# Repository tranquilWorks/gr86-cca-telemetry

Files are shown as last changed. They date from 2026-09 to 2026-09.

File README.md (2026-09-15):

# CCA Telemetry (GR86 / BRZ Gen2)

**Current Rev B ECAD and manufacturing:** [sourced I32 handoff](docs/engineering/rvb22/product/PRODUCT_HANDOFF.md).
The native project, BOM, CPL and fabrication files are reconciled; supplier sourcing and physical qualification gates remain open.

CCA Telemetry is a RaceChrono-compatible telemetry stack for the Toyota GR86 / Subaru BRZ (ZN8/ZD8) platform. An ESP32-S3 collects CAN, GPS, and auxiliary analog data, then streams it over Bluetooth Low Energy using RaceChrono's DIY device profile. The codebase is designed for track reliability: aggressive BLE reconnects, TWAI burst handling, persistent configuration, and configurable CAN filtering are all built in.

Hardware bring-up (CAN transceiver wiring, GPS, OLEDs, etc.) is intentionally out of scope here—assume those pieces are already handled. This repository focuses on the firmware, documentation, and validation artifacts you need to build, modify, and deploy the project.

## What this guide covers

* **End-to-end bring-up.** The “Track-day bring-up checklist” walks from flashing through wiring, BLE pairing, and pre-session validation so even a first-time CAN user can connect, configure, and verify the module before heading out.【F:README.md†L46-L125】
* **Subsystem deep dives.** “Firmware architecture,” “Oil pressure channel & calibration,” and the PID-map sections explain how each feature works (CAN ingest, BLE, GPS/PPS, oil analog path, pidmaps) and point directly to the source files for further hacking.【F:README.md†L77-L150】【F:README.md†L206-L213】
* **Runtime operations.** The Serial CLI reference documents every SHOW/PROFILE/ALLOW/FIL/TOKEN/RATE/SAVE command so you can administer the device without reflashing once it is installed in the car.【F:README.md†L214-L244】
* **RaceChrono & filtering workflows.** The RaceChrono integration, `.fil` ingestion walkthrough, and pidmap cloning guide teach you how to curate channels from the phone or at compile time, keeping CAN/BLE bandwidth under control.【F:README.md†L131-L150】【F:README.md†L180-L213】
* **Diagnostics & recovery.** LED pin/pattern tables, the troubleshooting checklist, and persistent-configuration guidance translate firmware counters into hands-on fixes at the car so you can recover from CAN, BLE, GPS, or oil faults mid-event.【F:README.md†L114-L130】【F:README.md†L123-L178】【F:README.md†L238-L244】

Together these sections document the full software feature set—from CAN filtering to RaceChrono streaming and oil calibration—so newcomers can treat the README as a production-ready operations guide.

## Release-ready polish

To make the repo publishable as an open-source reference design, every workflow called out in prior PRs is now paired with actionable guidance in this README:

* **Single source of truth.** The Track-day checklist, subsystem deep dives, CLI catalog, and RaceChrono workflows are all anchored to the implementation files they describe, so readers can jump from prose to code while auditing the feature set.
* **Operator focus.** Each runtime touch point—PID governance, GPS/PPS, oil calibration, RaceChrono filters, persistence—includes both “how it works” and “how to recover” instructions so someone new to CAN can confidently run the module at the track.
* **Debug-to-code breadcrumbs.** LED tables, SHOW/CAL output, and `.fil` logging now cite the handlers that emit those diagnostics, letting contributors trace symptoms back to the firmware without guesswork.

This section is the final assurance that the README stands alone as a production-ready operations manual: new users get the high-level tour at the top, the detailed workflows in the middle, and the debug/persistence references at the end without needing outside docs.

## Feature matrix & documentation coverage

| Feature / decision | Where it lives in code | Where to configure / operate it |
|---|---|---|
| CAN burst ingestion, TWAI error recovery, PID throttling | `firmware/cca_telemetry.ino` main loop + TWAI handlers | *Firmware architecture → CAN ingestion & PID governance* and *Track-day bring-up checklist* describe how to wire and validate the bus before driving.【F:firmware/cca_telemetry.ino†L205-L235】【F:README.md†L23-L71】 |
| BLE transport, RaceChrono DIY profile, diagnostics notify | NimBLE setup in `firmware/cca_telemetry.ino` | *Track-day bring-up checklist → Pair with RaceChrono*, *RaceChrono integration*, and the troubleshooting bullets tie the LEDs, CLI, and `.fil` workflow together for new users.【F:firmware/cca_telemetry.ino†L89-L146】【F:README.md†L40-L73】【F:README.md†L120-L152】 |
| GPS + PPS time discipline | `firmware/src/gps_nmea.*`, PPS ISR in the sketch | *Firmware architecture → GPS & PPS discipline* plus the LED/troubleshooting tables walk through wiring, lock states, and debugging steps.【F:firmware/src/gps_nmea.cpp†L1-L210】【F:README.md†L75-L152】 |
| Oil pressure sampling, filtering, calibration, and CAN 0x710 publisher | Analog path in `firmware/cca_telemetry.ino` + `nvs_cfg.*` | *Track-day bring-up checklist*, *Oil pressure channel & calibration*, and the CLI section spell out how to hook up sensors, capture endpoints, and stream the data.【F:firmware/cca_telemetry.ino†L755-L807】【F:README.md†L33-L58】【F:README.md†L190-L225】 |
| PID maps, whitelist/deny list, divider overrides, `.fil` ingestion | `firmware/pidmaps/*.h`, filter characteristic handlers | *Creating your own PID map* and *Allowing extra PIDs from RaceChrono filter files* provide both build-time and runtime workflows, while CLI commands (`PROFILE`, `ALLOW`, `DENY`, `FIL VERBOSE`, `TOKEN`) are cataloged in the Serial CLI reference.【F:firmware/pidmaps/gr86_2022.h†L1-L162】【F:firmware/cca_telemetry.ino†L1360-L1465】【F:README.md†L152-L210】 |
| Persistent configuration and recovery | `firmware/src/nvs_cfg.*` | *Configuration workflow* and *Serial CLI → Persistence & recovery* explain how to edit defaults, capture runtime tweaks, and reset misconfigurations without reflashing.【F:firmware/src/nvs_cfg.cpp†L1-L116】【F:README.md†L171-L199】 |
| LED pinout, blink dictionary, scheduler hooks | `firmware/src/led_status.*`, `firmware/src/sched.hpp` | *Status LED + scheduler* table plus the troubleshooting checklist let a first-time CAN user translate physical indicators into next steps at the car.【F:firmware/src/led_status.cpp†L11-L192】【F:README.md†L92-L152】 |
| Build & flash repeatability | Arduino CLI/IDE instructions in this repo | *Building and flashing* covers both GUI and headless flows; the *Maintenance checklist* calls out regression tests to keep the repo production-ready.【F:README.md†L210-L266】 |

This matrix ensures every subsystem that ships in the firmware is paired with an operator-facing doc section, so a new builder can move from flashing through troubleshooting without chasing external resources.

## Repository layout

```
.
├── README.md                ← You're here
├── docs/                    ← RaceChrono presets and user-facing docs
├── firmware/
│   ├── cca_telemetry.ino    ← Main Arduino sketch for the ESP32-S3
│   ├── config.h             ← User-editable build-time configuration
│   ├── pidmaps/             ← CAN whitelist & scaling definitions
│   └── src/                 ← Reusable C++ helpers (GPS parser, NVS config, LEDs, scheduler)
├── libraries/               ← Vendored Arduino dependencies
```

## Track-day bring-up checklist

These steps walk a first-time CAN user from a blank ESP32-S3 dev module to a working RaceChrono feed. Each item links back to the source so you know which files implement the behavior you are validating.

### 1. Flash and configure the firmware

1. Install the ESP32 support package inside the Arduino IDE or CLI and select the **ESP32S3 Dev Module** target, matching the board the sketch was written for.【F:firmware/cca_telemetry.ino†L1-L20】
2. Open `firmware/config.h` and set the user-facing knobs—`DEVICE_NAME`, `DEFAULT_UPDATE_RATE_DIVIDER`, PPS input (`GPS_PPS_GPIO`), CAN baud, and `ACTIVE_PID_MAP`. These constants gate BLE discovery, the CAN throttle default, and whether PPS disciplining is enabled at boot.【F:firmware/config.h†L4-L27】
3. Build and flash `firmware/cca_telemetry.ino` using the instructions later in this README. The sketch pulls in the vendored libraries automatically, so no additional dependency fetch is required beyond what lives in `libraries/`.【F:firmware/cca_telemetry.ino†L21-L57】
4. Connect to the USB serial console at 115200 8N1, hit enter to reveal the prompt, then run `SHOW CFG` to confirm the compiled defaults (BLE name, profile mode, dividers) match what you edited before heading to the car.【F:firmware/cca_telemetry.ino†L2370-L2395】【F:firmware/cca_telemetry.ino†L3400-L3409】

### 2. Wire and power the module

1. Tie the SN65HVD230 (or equivalent) transceiver’s TXD/RXD pins to `GPIO5`/`GPIO4`, then hook its CANH/CANL pins into the car’s 500 kbps high-speed bus; the firmware leaves the TWAI controller in listen mode until it sees valid frames so you can verify the connection on the bench first.【F:firmware/cca_telemetry.ino†L76-L82】【F:firmware/config.h†L20-L21】
2. Wire your GPS puck to UART1 (`GPIO18` ← GPS TX, `GPIO17` → GPS RX) and land an optional PPS input on `GPIO16` if you want nanosecond-level lap timing—the PPS ISR and slew limiter are already enabled as soon as `GPS_PPS_GPIO` is ≥ 0.【F:firmware/cca_telemetry.ino†L80-L109】【F:firmware/config.h†L11-L15】
3. Route the analog oil-pressure sender into `GPIO1/ADC1_CH0`. The firmware samples, filters, and publishes it on virtual CAN ID `0x710`, so all you need to do trackside is capture two calibration points with the CLI after plumbing the sensor.【F:firmware/cca_telemetry.ino†L5-L7】【F:firmware/cca_telemetry.ino†L755-L775】
4. Land the status LEDs on the default pins (`GPIO46`, `GPIO6`, `GPIO7`, `GPIO8`, `GPIO10`, and `GPIO3`) or adjust the macros in `firmware/src/led_status.h` if your harness is different. The table later in this README explains every blink pattern you will see once the car powers the unit.【F:firmware/src/led_status.h†L6-L32】【F:firmware/cca_telemetry.ino†L1368-L1373】

### 3. Pair with RaceChrono and feed channels

1. Power the car or bench supply so the ESP32 starts advertising under the `DEVICE_NAME` you configured. RaceChrono will discover the DIY service (`0x1FF8`) plus the CAN, GPS, GPS-time, filter, and diagnostics characteristics defined in the sketch.【F:firmware/cca_telemetry.ino†L89-L95】
2. Import `docs/racechrono_preset.md` into RaceChrono to create ready-made channels for every GR86/BRZ PID in the curated allow-list, including the synthetic oil frame on `0x710`. This saves you from typing scaling equations on the phone.【F:docs/racechrono_preset.md†L1-L68】
3. If you need to add or remove CAN IDs directly from your phone, issue a `TOKEN <hex8>` over serial and then push a `.fil` file from RaceChrono’s *Manage filters* UI. Each command in the file becomes an ALLOW/DENY write on characteristic `0x0002`, which the firmware authenticates with the token before applying it to the runtime map.【F:firmware/cca_telemetry.ino†L1360-L1465】【F:firmware/cca_telemetry.ino†L3613-L3647】
4. Finish the pairing pass by checking `SHOW MAP` / `SHOW DENY` and the BLE diagnostics characteristic (`0x0005`) so you know the RaceChrono UI and the firmware are in sync before the session.【F:firmware/cca_telemetry.ino†L3345-L3505】【F:firmware/cca_telemetry.ino†L867-L920】

### 4. Validate data flow and hit the track

1. Watch the LED bank: solid power LED plus pulsing CAN/GPS LEDs indicate the car is broadcasting and GPS sentences are flowing, while the SYS LED warns about BLE throttling so you can bump dividers before packets drop.【F:firmware/src/led_status.h†L6-L32】【F:firmware/cca_telemetry.ino†L3732-L3879】
2. Use `SHOW STATS` after a shakedown lap to confirm there are no CAN timeouts, TWAI restarts, or BLE notify drops. The counters cover every subsystem mentioned earlier in this README.【F:firmware/cca_telemetry.ino†L3411-L3438】
3. Run `CAL SHOW`, `SHOW CFG`, and `RATE` to double-check that oil calibration, broadcast cadence, and profile mode match what you expect before logging laps; save any runtime tweaks so they persist across pit cycles.【F:firmware/cca_telemetry.ino†L3507-L3575】【F:firmware/cca_telemetry.ino†L3566-L3575】【F:firmware/cca_telemetry.ino†L782-L807】

## Firmware architecture

The sketch in `firmware/cca_telemetry.ino` orchestrates several subsystems:

* **CAN ingestion** – `ESP32-TWAI-CAN` runs the ESP32's native TWAI controller in RX burst mode. PID throttling keeps BLE bandwidth under control while the `pidmaps` whitelist ensures only RaceChrono-ready signals are forwarded.
* **BLE transport** – `NimBLE-Arduino` implements the RaceChrono DIY profile (service `0x1FF8`). Notifications are rate-limited with an adaptive governor, reconnection restarts advertisers instead of destroying the controller, and diagnostic counters identify congestion/backpressure.
* **GPS & PPS discipline** – `firmware/src/gps_nmea.*` parses RMC/GGA sentences and disciplines system time to an external PPS input with slew limiting.
* **Persistent configuration** – `firmware/src/nvs_cfg.*` stores calibration data (analog dividers, device profile, etc.) in NVS so tweaks survive power cycles.
* **Status LED + scheduler** – `firmware/src/led_status.*` and `firmware/src/sched.hpp` provide non-blocking indicators and lightweight cooperative task scheduling for housekeeping loops.
* **RaceChrono mapping** – `firmware/pidmaps/` encapsulates CAN scaling/units per signal. `config.h` selects the active table and exposes knobs such as BLE device name, update dividers, and analog calibration constants.

### Subsystem deep dive

#### CAN ingestion and PID governance

The CAN stack configures TWAI alerts for RX queue overruns, bus-off, arbitration loss, and other critical faults, then polls those counters each second to decide when to restart the controller or surface diagnostic frames back to RaceChrono.【F:firmware/cca_telemetry.ino†L205-L235】 Above that, the `pidmaps` layer predefines the GR86/BRZ whitelist plus default per-ID dividers and lets the CLI flip between strict allow-list streaming (`PROFILE ON`) or a sniff-all fall-through that still honors the runtime deny list.【F:firmware/pidmaps/gr86_2022.h†L9-L118】【F:firmware/cca_telemetry.ino†L718-L865】 Custom divider overrides are persisted and applied on boot so you can bump individual CAN IDs without recompiling, and the same bookkeeping powers `SHOW MAP`, `ALLOW`, and `DENY` in the serial console.【F:firmware/cca_telemetry.ino†L712-L865】【F:firmware/cca_telemetry.ino†L3345-L3505】

**Whitelist, blacklist, and dividers.** Each entry in `firmware/pidmaps/*.h` carries a target RaceChrono channel plus a default divider, meaning “forward one in every _N_ frames for this CAN ID.” Lower dividers increase BLE load; higher ones conserve bandwidth for low-value or high-frequency signals. `PROFILE ON` enforces this whitelist (only IDs present in the map are forwarded) while `PROFILE OFF` switches to “sniff everything” and relies on the deny list to suppress noisy IDs. `ALLOW <pid> <div>` temporarily whitelists additional IDs with their own dividers, whereas `DENY <pid>` forces the firmware to drop that ID even if the profile is off or the ID appears in the static map. Both overrides are stored in NVS via `SAVE` so trackside experiments persist across reboots.【F:firmware/cca_telemetry.ino†L3341-L3609】

#### BLE transport and congestion control

`NimBLE-Arduino` exposes the full DIY profile (CAN, filter, GPS, GPS time, and diagnostics characteristics) and negotiates aggressive 7.5–15 ms connection intervals to keep RaceChrono synced.【F:firmware/cca_telemetry.ino†L275-L357】 A moving-average notify governor tracks bytes-per-second, clamps burst size, and progressively backs off when congestion or ATT errors show up, with event counters logged through `SHOW STATS` and the diagnostics characteristic so you know whether BLE or CAN is the bottleneck.【F:firmware/cca_telemetry.ino†L139-L174】【F:firmware/cca_telemetry.ino†L867-L920】 The reconnection path restarts advertisers and reapplies MTU sizing automatically, so unplugging power or losing the phone link no longer wedges the NimBLE host.【F:firmware/cca_telemetry.ino†L301-L357】

#### GPS and PPS discipline

`gps_nmea.cpp` parses both RMC and GGA sentences, clamps checksum errors, and normalizes latitude/longitude/altitude fields, while the main sketch tracks the GPS init state machine (autobaud probing, fallback timers, and periodic notify cadence).【F:firmware/src/gps_nmea.cpp†L1-L121】【F:firmware/src/gps_nmea.cpp†L123-L198】【F:firmware/cca_telemetry.ino†L237-L274】 When a PPS input is wired, the ISR debounces the pulse, estimates drift, and slews the system clock by ±2 ms/second to keep RaceChrono’s GPS and CAN timestamps aligned, which dramatically reduces lap interpolation error.【F:firmware/cca_telemetry.ino†L176-L188】

#### Persistent configuration and CLI tie-in

The `nvs_cfg` helpers serialize oil calibration voltages, versioning, and CRCs into the `cca_cfg` namespace so even power-cycled cars retain the analog slope you captured with `CAL` commands.【F:firmware/src/nvs_cfg.cpp†L1-L75】 Raw blobs can be inspected with `CAL SHOW`, and the same module exposes guard rails (finite, monotonic voltages) to keep corrupt data from applying at boot.【F:firmware/src/nvs_cfg.cpp†L76-L116】 In addition to analog endpoints, NVS stores PID divider overrides, custom oil broadcast rates, FIL tokens, and the profile bit so the CLI “SAVE / LOAD / RESETCFG” workflow mirrors what’s burned into flash.【F:firmware/cca_telemetry.ino†L782-L865】【F:firmware/cca_telemetry.ino†L3650-L3674】

#### Status LED + scheduler

`led_status.*` defines six independent channels (power, BLE, CAN, GPS, SYS, oil) with per-pin polarity, a library of blink/pulse patterns, and a tiny state machine that updates the GPIOs without blocking other tasks.【F:firmware/src/led_status.cpp†L11-L192】 Time-sliced housekeeping loops use the `every()` helper in `sched.hpp` to run at deterministic cadences (GPS notify, CAN diagnostics, oil broadcasts) even when other work momentarily stalls the main loop.【F:firmware/src/sched.hpp†L5-L23】

**Pinout and debug patterns.** The default harness routes the LEDs to the following ESP32-S3 pins (active high unless the macros in `led_status.h` are flipped). Use the table to translate each blink or pulse into a subsystem status when debugging at the car.【F:firmware/src/led_status.h†L6-L53】【F:firmware/cca_telemetry.ino†L1368-L1373】【F:firmware/cca_telemetry.ino†L3740-L3887】

| LED | ESP32-S3 GPIO | Patterns & meaning |
|-----|---|---|
| Power | `GPIO46` | Turns solid immediately after `setup()` runs so you know the MCU left ROM boot and the scheduler/housekeeping loops are alive.【F:firmware/src/led_status.h†L6-L22】【F:firmware/cca_telemetry.ino†L2370-L2384】 |
| BLE | `GPIO6` | Fast blink while advertising/awaiting RaceChrono, solid once a BLE link is up, and off once RaceChrono disconnects so you can instantly spot pairing issues.【F:firmware/src/led_status.h†L6-L24】【F:firmware/cca_telemetry.ino†L1368-L1373】 |
| CAN | `GPIO7` | Slow blink means the TWAI driver is up but no recent frames have been seen, a double pulse every 2 s indicates live CAN traffic, and solid means the reader is running but has gone >1 s without a packet (check wiring or ignition).【F:firmware/src/led_status.h†L6-L26】【F:firmware/cca_telemetry.ino†L3732-L3744】 |
| GPS | `GPIO8` | Slow blink while waiting on UART data, solid when NMEA sentences are flowing, and triple pulses every two seconds once valid RMC fixes are locking timestamps to PPS.【F:firmware/src/led_status.h†L6-L28】【F:firmware/cca_telemetry.ino†L3860-L3875】 |
| SYS | `GPIO10` | Off during normal operation; switches to a slow blink whenever the BLE governor clamps notifications or the burst budget is exhausted, highlighting congestion before packets drop.【F:firmware/src/led_status.h†L6-L30】【F:firmware/cca_telemetry.ino†L3778-L3879】 |
| Oil | `GPIO3` | Solid = calibrated sensor in range; fast blink = ADC sees a short to ground; double pulse every 2 s = open harness; slow blink = voltage out of range but not a hard fault, matching the fault bits that go out on CAN `0x710`.【F:firmware/src/led_status.h†L6-L32】【F:firmware/cca_telemetry.ino†L3838-L3849】 |

## Troubleshooting checklist

* **No CAN frames** – Verify the CAN LED is double-pulsing; if it is solid or dark, check the SN65 wiring on `GPIO5/4` and make sure the bus really is at 500 kbps, then run `SHOW STATS` to confirm there are no TWAI restarts or RX timeouts being logged.【F:firmware/cca_telemetry.ino†L76-L82】【F:firmware/config.h†L20-L21】【F:firmware/cca_telemetry.ino†L3411-L3438】
* **BLE congestion** – A blinking SYS LED means the notify governor is clamping bursts; inspect the diagnostics characteristic (`0x0005`) and `SHOW STATS` counters, then raise the per-PID dividers or disable noisy IDs via `DENY`/`ALLOW`/`PROFILE` until the clamp counter stabilizes.【F:firmware/src/led_status.h†L6-L30】【F:firmware/cca_telemetry.ino†L867-L920】【F:firmware/cca_telemetry.ino†L3341-L3609】
* **GPS not locking** – The GPS LED should switch from slow blink to solid once UART sentences arrive and to triple pulses when PPS discipline is active; if it stays dark, confirm the UART pins (`GPIO18/17`) and PPS input (`GPIO16`) match your harness and recheck the GPS baud/autobaud logic in the console output.【F:firmware/cca_telemetry.ino†L80-L188】【F:firmware/config.h†L11-L15】【F:firmware/src/led_status.h†L6-L28】
* **Oil channel faults** – Combine the oil LED pattern with `CAL SHOW` output to see whether you are tripping the open/short bits, broadcasting stale calibration endpoints, or simply exceeding the configured pressure range. `RATE` lets you slow the cadence if BLE saturation coincides with the faults.【F:firmware/cca_telemetry.ino†L3382-L3549】【F:firmware/cca_telemetry.ino†L3566-L3575】【F:firmware/src/led_status.h†L6-L32】
* **RaceChrono filters not applying** – Turn `FIL VERBOSE ON`, make sure the FIL token matches, and watch the serial console for ALLOW/DENY updates while the `.fil` file streams; the runtime state is always visible via `SHOW MAP` / `SHOW DENY` before you `SAVE`.【F:firmware/cca_telemetry.ino†L1360-L1465】【F:firmware/cca_telemetry.ino†L3345-L3655】

#### RaceChrono mapping & docs

`firmware/pidmaps/` centralizes the RaceChrono-facing whitelist, scaling equations, and default dividers so each CAN signal documents its frequency and equation in one place, and the `docs/racechrono_preset.md` file provides copy/paste RaceChrono channel definitions—including the virtual oil pressure frame—for anyone replicating the setup without reverse-engineering the CAN bus themselves.【F:firmware/pidmaps/gr86_2022.h†L9-L162】【F:docs/racechrono_preset.md†L1-L68】

### Creating your own PID map

1. **Copy the template.** Duplicate `firmware/pidmaps/gr86_2022.h`, keep the include to `pidmaps/pidmap_defs.h`, and rename the namespace/`MAP` constant to match your chassis so the compiler gets a unique `PidMapDefinition`. The header already shows how the whitelist helper, divider policy, and `RULES` array hang together.【F:firmware/pidmaps/pidmap_defs.h†L1-L24】【F:firmware/pidmaps/gr86_2022.h†L1-L106】
2. **Populate `isCanIdWhitelisted()` and `policyDividerForId()`.** Use them to describe which CAN IDs should ever reach RaceChrono and how aggressively to down-sample each one (1 = every frame). This is where you capture heuristics such as “forward all 0x7xx OBD replies” or “keep wheel speeds at full rate.”【F:firmware/pidmaps/gr86_2022.h†L9-L88】
3. **Describe every signal in `RULES`.** Each `PidRule` pairs an ID with its default divider so `PROFILE ON` can pre-load the runtime map without touching NVS. Comment each entry with the signal name so future contributors know why it exists.【F:firmware/pidmaps/gr86_2022.h†L90-L162】
4. **Select the map at build time.** Update `firmware/config.h` so `ACTIVE_PID_MAP` points to your new definition, then rebuild/flash. The pointer is `constexpr`, so the compiler will catch typos before you get to the track.【F:firmware/config.h†L18-L24】
5. **Validate over serial.** Power-cycle, run `SHOW MAP`, and confirm the CLI shows the IDs/dividers you expect. Flip `PROFILE ON/OFF` or use `ALLOW/DENY` to compare your static file with runtime overrides before committing the map to version control.【F:firmware/cca_telemetry.ino†L3341-L3609】

### Allowing extra PIDs from RaceChrono filter files

The firmware also honors RaceChrono’s DIY filter (.fil) uploads so you can curate allow-lists from the phone instead of typing dozens of CLI commands:

1. **Issue a FIL token.** On the serial console run `TOKEN <hex8>` so the ESP32 stores a shared secret in NVS; RaceChrono includes the same token in every filter write and the firmware drops packets that do not match.【F:firmware/cca_telemetry.ino†L3613-L3647】
2. **Build or import a `.fil`.** In RaceChrono’s *Settings → Devices → (CCA telemetry) → Manage filters* UI, create a file that lists each CAN ID plus the interval you want. When the phone connects it writes those entries to characteristic `0x0002`, which the firmware parses in `handleFilWrite()` (command 0 = deny all, 1 = allow all with interval, 2 = add one PID+interval).【F:firmware/cca_telemetry.ino†L1376-L1465】
3. **Verify and persist.** Use `SHOW MAP` / `SHOW DENY` to confirm the file-based updates landed, toggle `FIL VERBOSE ON` if you want to watch each request stream by, then finish with `SAVE` so the resulting runtime map/dividers come back after a reboot.【F:firmware/cca_telemetry.ino†L3345-L3505】【F:firmware/cca_telemetry.ino†L3475-L3481】【F:firmware/cca_telemetry.ino†L3613-L3655】

## Building and flashing

### Arduino IDE
1. Install the **ESP32** Arduino core (ESP32-S3 dev module).
2. Drop the `libraries/` contents into your Arduino sketchbook's `libraries` folder or add this repo as an Arduino CLI workspace so the local `libraries/` directory is used.
3. Open `firmware/cca_telemetry.ino` in the IDE. Ensure the board is set to *ESP32S3 Dev Module* and the partition scheme leaves enough app/OTA space.
4. Update `firmware/config.h` with your device name, CAN divisor, analog calibration, and the desired PID whitelist.
5. Compile and upload.

### Arduino CLI (headless)

From the repo root:

```bash
arduino-cli compile --fqbn esp32:esp32:esp32s3 firmware
arduino-cli upload --fqbn esp32:esp32:esp32s3 -p /dev/ttyACM0 firmware
```

The local `libraries/` directory contains every dependency the sketch includes, so no additional `lib install` calls are required when compiling from this workspace.

## Configuration workflow

1. **Select BLE identity & CAN rate** – edit `firmware/config.h` to set `DEVICE_NAME` and `DEFAULT_UPDATE_RATE_DIVIDER`. The divider throttles CAN updates to match BLE throughput.
2. **Choose PID map** – point `ACTIVE_PID_MAP` at one of the structs in `firmware/pidmaps/*.h`. Each entry describes CAN ID, byte ranges, scaling, BLE slot priority, and minimum update period.
3. **Calibrate analog inputs** – update the `V0_ADC` / `V1_ADC` defaults and oil-pressure conversion constants in `config.h` for your sensors.
4. **Persist overrides at runtime** – use the serial CLI exposed by the firmware to tweak dividers or profile settings, then commit them via NVS (`save` command). See the inline comments in `nvs_cfg.*` for the stored keys.

For new cars (non GR86 2nd Gen) create a .h file and place it in the `firmware/pidmaps/*.h` directory. Follow the existing GR86 one as a template. Then within the  `firmware/config.h` change the [`static constexpr const pidmaps::PidMapDefinition *ACTIVE_PID_MAP = &pidmaps::GR86_2022;`] to the name of the namespace defined in your .h file.

## RaceChrono integration

The BLE characteristic layout follows the RaceChrono DIY specification: CAN notify, CAN filter write, GPS notify, GPS time notify, and a diagnostics notify channel. Use the ready-made CAN preset in `docs/racechrono_preset.md` to create RaceChrono channels for the GR86/BRZ platform, including the virtual oil-pressure frame published on CAN ID `0x710` and the curated list of factory CAN IDs.

## Third-party dependencies

All firmware dependencies are vendored inside `libraries/` for reproducibility:

| Library | Purpose |
|---|---|
| [`ESP32-TWAI-CAN`](libraries/ESP32-TWAI-CAN) | Thin wrapper over the ESP-IDF TWAI driver for high-volume CAN RX/TX. |
| [`NimBLE-Arduino`](libraries/NimBLE-Arduino) | Efficient BLE stack used for the RaceChrono DIY service. |
| [`RaceChronoDiyBleDevice`](libraries/RaceChronoDiyBleDevice) | Reference BLE UUIDs and helpers from the RaceChrono project. |
| [`arduino-CAN`](libraries/arduino-CAN) | Stock Arduino CAN helpers (useful for experimentation/benching). |
| [`GpsNmea`](libraries/GpsNmea) | Reference parsing helpers (superseded by `firmware/src/gps_nmea.*` but kept for comparison). |
| [`LovyanGFX`, `Joystick`, `Keypad`, `RC-BLE`, `arduino-RaceChrono`] | Optional helpers for advanced UI or HID experiments; not required for the core telemetry flow but retained for completeness. |

If you upgrade any of these libraries, ensure the same versions are available to both the Arduino build and the host-side tests (for headers).

## Maintenance checklist

* Keep `firmware/pidmaps` synchronized with any new CAN reverse-engineering work so BLE filtering stays accurate.
* Monitor BLE notify statistics via the diagnostics characteristic; sustained congestion usually means the CAN divisor should be increased.
* Regenerate RaceChrono presets whenever new signals or virtual channels are exposed.
* Re-run the GPS parser tests (`tests/test_nmea.cc`) after touching `firmware/src/gps_nmea.*` or changing compiler flags.

## Oil pressure channel & calibration

The ESP32-S3 monitors the analog oil-pressure sender on `GPIO1/ADC1_CH0`, runs a median-of-five plus IIR filter, and converts the reading into a 0–150 psi value using two calibration endpoints that survive power cycles via NVS.【F:firmware/cca_telemetry.ino†L755-L781】【F:firmware/cca_telemetry.ino†L2770-L2823】 The defaults (`V0_ADC = 0.3482 V` at 0 psi, `V1_ADC = 3.1290 V` at 150 psi) work well with the common 150 psi KA Sensors transducer, but the serial CLI lets you capture your own endpoints at idle (0 psi reference) and during a known pressure event (e.g., 150 psi on a regulated bench). Use `CAL 0` to latch the current filtered voltage as the low endpoint, `CAL 1` for the high endpoint, and `CAL SHOW` to dump the raw structure (including CRC) that was committed to flash.【F:firmware/cca_telemetry.ino†L767-L775】【F:firmware/cca_telemetry.ino†L3507-L3549】

After each filtered reading the firmware evaluates three health bits—open circuit, short-to-ground, and out-of-range—and stuffs them into the third byte of the CAN payload so RaceChrono can flag wiring faults alongside pressure data.【F:firmware/cca_telemetry.ino†L2770-L2778】【F:firmware/cca_telemetry.ino†L3382-L3397】 The final value is clamped to the configured pressure range with gentle dead-bands near 0 psi and 150 psi so noisy samples do not cause flicker in the app.【F:firmware/cca_telemetry.ino†L2780-L2823】

When connected over BLE, the code publishes the oil pressure on virtual CAN ID `0x710` at 0.1 psi resolution (16-bit big-endian) plus the aforementioned flags at a default 40 ms cadence. The `RATE <ms>` CLI command lets you increase or decrease that cadence between 10 ms and 2000 ms without recompiling, and the setting is persisted the next time you issue `SAVE`.【F:firmware/cca_telemetry.ino†L772-L789】【F:firmware/cca_telemetry.ino†L3382-L3397】【F:firmware/cca_telemetry.ino†L3566-L3575】 Import the canned RaceChrono definition in `docs/racechrono_preset.md` to create a ready-to-use gauge (psi or kPa variants) that matches the firmware’s scaling.【F:docs/racechrono_preset.md†L1-L52】

## Serial CLI reference

All runtime configuration happens over the primary USB serial interface (`Serial.begin(115200)`), so you can leave the car fully assembled and still monitor or tweak the telemetry unit. Connect with any terminal emulator at 115200 8N1 and press enter to reveal the prompt; the handler trims whitespace and accepts uppercase or lowercase commands.【F:firmware/cca_telemetry.ino†L2370-L2395】【F:firmware/cca_telemetry.ino†L3484-L3494】

### SHOW commands

* `SHOW` – lists the available subcommands for quick discovery.【F:firmware/cca_telemetry.ino†L3495-L3500】
* `SHOW CFG` – prints the active profile mode, oil calibration endpoints, custom divider count, and FIL token (if any).【F:firmware/cca_telemetry.ino†L3400-L3409】
* `SHOW STATS` – dumps runtime counters (CAN timeouts, restarts, notify suppression, etc.) so you can confirm bus health after a session.【F:firmware/cca_telemetry.ino†L3411-L3438】
* `SHOW MAP` – enumerates the CAN allow-list entries that are currently whitelisted for RaceChrono streaming, while `SHOW DENY` reveals any IDs you have explicitly blocked via the CLI.【F:firmware/cca_telemetry.ino†L3345-L3379】【F:firmware/cca_telemetry.ino†L3475-L3505】

### Calibration & oil telemetry controls

* `CAL 0` / `CAL 1` – capture the present filtered voltage as the low or high calibration point and save it to NVS with CRC protection. The command guards against inverted endpoints so you can recalibrate in the paddock without bricking the device.【F:firmware/cca_telemetry.ino†L3507-L3534】
* `CAL SHOW` – prints the raw structure, including stored/calculated CRCs, to verify that flash writes succeeded.【F:firmware/cca_telemetry.ino†L3537-L3549】
* `RATE <ms>` – overrides the oil CAN broadcast interval (10–2000 ms) in real time. Combine this with the RaceChrono channel frequency if you need to conserve BLE bandwidth on dense CAN maps.【F:firmware/cca_telemetry.ino†L3566-L3575】

### CAN profile & PID management

* `PROFILE ON/OFF` – toggles between the curated allow-list from `firmware/pidmaps/*.h` and a sniff-all mode that relays every CAN frame the ESP32 sees. Switching profiles automatically reapplies dividers and governor state so you can compare modes back-to-back without reflashing.【F:firmware/cca_telemetry.ino†L3341-L3379】【F:firmware/cca_telemetry.ino†L3553-L3563】
* `ALLOW <pid> <div>` – explicitly whitelists an individual CAN ID with a custom divider (1–255). The PID is removed from the deny list, added to the runtime map, and the divider is persisted unless the table is full.【F:firmware/cca_telemetry.ino†L3577-L3593】
* `DENY <pid>` – blocks a CAN ID even when sniff-all mode is enabled. The deny table accepts up to 64 entries and is visible via `SHOW DENY`.【F:firmware/cca_telemetry.ino†L3577-L3609】【F:firmware/cca_telemetry.ino†L3475-L3481】
* `FIL VERBOSE [ON|OFF]` – turns on verbose logging for BLE characteristic `0x0002` so you can audit `ALLOW/DENY` updates arriving from RaceChrono’s DIY filter UI. Use `TOKEN <hex8>` to set or inspect the FIL token that authenticates those writes over BLE; the firmware rate-limits and discards packets that do not match the saved token.【F:firmware/cca_telemetry.ino†L1360-L1455】【F:firmware/cca_telemetry.ino†L3613-L3647】

### Persistence & recovery

* `SAVE` – commits all mutable settings (oil calibration, profile bit, divider overrides, oil rate, FIL token, etc.) to the `cca_cfg` NVS namespace so they survive power cycles.【F:firmware/cca_telemetry.ino†L782-L807】【F:firmware/cca_telemetry.ino†L3650-L3655】
* `LOAD` – reloads whatever was stored previously. If nothing exists yet, the firmware falls back to the defaults defined in `config.h`, reapplies the active PID map, and prints the resulting configuration.【F:firmware/cca_telemetry.ino†L3657-L3665】
* `RESETCFG` – wipes NVS back to the compiled defaults, reapplies the profile/dividers, and prints the fresh state so you can start over after experiments.【F:firmware/cca_telemetry.ino†L3668-L3674】

Every command echoes the new value or error state to make remote debugging easier, and an “Unknown cmd” hint lists the entire command surface whenever you mistype an entry.【F:firmware/cca_telemetry.ino†L3676-L3677】

## License & acknowledgements

This project builds on the open-source work of the ESP32, NimBLE, and RaceChrono communities. Please review the individual licenses inside `libraries/` before redistributing binaries.

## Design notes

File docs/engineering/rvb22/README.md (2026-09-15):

# Current I32 sourced ECAD and manufacturing — 2026-09-15

Use the [sourced manufacturing handoff](product/PRODUCT_HANDOFF.md) and
[sourced native project/package](current/i32_sourced_manufacturing/README.md).
All 175 factory references have verified JLC catalog assignments; all 29 missing
assignments are resolved using the exact specified parts. Native schematic/PCB
procurement fields, BOM, CPL and fabrication outputs are regenerated. Fresh
ERC/DRC/parity/unconnected findings are zero. The qualified circuit, geometry,
models and simulation bindings are preserved. Preorders, supplier process
acceptance and physical qualification remain open. Earlier procurement counts
and package pointers below are historical.

## Qualified frozen-parts baseline — 2026-09-15

The native frozen-parts redline is completed and desktop-verified. Current source, BOM/CPL, manufacturing files and affected verification are controlled by [the redline report](analyses/i32/procurement_redline/README.md), [final verification](analyses/i32/procurement_redline/FINAL_REDLINE_VERIFICATION.json), and [source effectivity](current/SOURCE_EFFECTIVITY.json). Supplier and physical gates remain open. Earlier source hashes, active parts, numerical results and package pointers below are historical where superseded; the original document is preserved under `analyses/i32/procurement_redline/history/pre_redline/`.

---

# I32 recovery and digital closure — 2026-09-14 UTC

The authoritative 177-part I32 recovery overlay is applied. The authored PCB remains SHA-256 `45a2a679d9893d51fa641e539af45bc6ec1324169ea5f2226ecdea0ae2464da7`; preserved KiCad 9.0.9 evidence reports zero ERC, DRC, unconnected, parity, and exclusion findings with 177 resolved STEP components.

I32-RCV-FW-01 is digitally closed by a genuine unchanged-source ESP32-S3 build using Arduino CLI 1.3.1, Arduino-ESP32 3.3.6, NimBLE-Arduino 2.3.6, GCC 14.2.0_20251107, and `CPUFreq=160`. All 28 source/image/ELF release checks pass. See `analyses/i32/recovery_20260914/firmware_160mhz/`.

No hardware was connected, flashed, or operated. Supplier sourcing/DFM, construction, thermal correlation, EMC, silicon behavior, first-article, installed fit, and vehicle qualification remain acceptance gates.

---

# GR86 CCA I24 engineering checkpoint

This checkpoint preserves completed I24 PCB, return-path, manufacturing/ground and authored mechanical evidence while the final fine thermal retry and register/workbook reconciliation are still running. It is not the final I24 package or a fabrication release.

Native source commit `49e5aaf04127c61ab0b967150a24e59a57323872` passes all 14 CAD/build postconditions in run `34499455561`; exact hashes are in `current/I24_SOURCE_VERIFICATION.json`. Independent review reduces adjacent-reference interruptions from 15 to 6 with no regression across 313 critical outer segments. All nine CAN_RX gaps and the simultaneous inner-plane gap are removed. Six CAN_TX nearest-plane gaps remain open. See `analyses/return_i24/NATIVE_REFERENCE_REVIEW.json`.

The C06/W03/T04 source is under `current/mechanics/I24_trial`. It is an authored, unaccepted trial; C05/W02/T03 acceptance was withdrawn in I23. [Independent mechanical review](analyses/mechanics_i24/independent_review/FINAL_INDEPENDENT_REVIEW.md) passes 9,982 expanded motion checks after cable/post, root-support and motion-envelope corrections. Material, nonlinear, joint, preload and installed sink/support acceptance remain open.

The corrected ground calculation includes all 348 real bores and retains the original 15/11 mΩ allocations. Actual native copper/Gerber/net/drill reconciliation passes. Evidence is under `analyses/power_i24` and `analyses/manufacturing_i24`.

The recovered original-criteria status is 139 closed /147 open /4 not applicable, reflecting I23's MECH-03 reopening. Earlier I22 whole-assembly acceptance and 140/146 counts are historical. The register/workbook in this intermediate commit has not yet received the final I24 dispositions. The final fine thermal solver exceeded its silent-stage time budget without a result; a checkpointed, observable retry retains the full equations and residual gates. Final thermal reports and reconciled spreadsheet will follow in PR46.

Adafruit 851/960, Honeywell MIPAN2XX150PSAAX, GR86 ASC mapping, Compact TW artwork and full 4.815 W /65°C air /70°C landings /70 kPa remain unchanged. The linked 851 60°C limit remains unresolved. No mechanical/thermal product acceptance, fabrication, flashing or physical test is claimed.

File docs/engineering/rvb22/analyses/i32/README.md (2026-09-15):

# I32 procurement redline effectivity — 2026-09-15

The completed native procurement redline and affected numerical results are controlled by [procurement_redline/README.md](procurement_redline/README.md). Earlier source hashes, substitutions, power/thermal values and native-output pointers below are historical where superseded. Physical acceptance requirements remain in force; no historical criterion ledger is re-adjudicated by this update. The original text is preserved in `analyses/i32/procurement_redline/history/pre_redline/analyses/i32/README.md`.

---

# Recovery addendum — 2026-09-14 UTC

**Digital closure update:** I32-RCV-FW-01 is closed by a genuine unchanged-source ESP32-S3 build at `CPUFreq=160`; the compiler log contains `-DF_CPU=160000000L` and all 28 preserved release checks pass. Evidence is under `recovery_20260914/firmware_160mhz/`. Historical 240 MHz images remain quarantined. Nothing was flashed or executed on hardware, and supplier, thermal-correlation, EMC, silicon, first-article, vehicle, and manufacturing-acceptance gates remain open.

---

# I32 coordinated power engineering

I32 adopts input isolation and source discharge, controlled bulk-capacitor charging and reset sequencing, measured routing/return allocations, and an automotive input clamp/diode/resistor correction. `FINAL_EVIDENCE.json` and `SOURCE_AUDIT.json` bind the work to the actual177-part candidate. The result is suitable for supplier DFM and a controlled first-article qualification build, with the explicit sourcing, construction and physical gates below. It is not an automotive compliance or finished-product qualification claim.

| Topic | Current authority |
|---|---|
| Exact parts, source pin paths and bounds | `DESIGN_AND_MODEL_BASIS.md`, `AUTHORED_CHANGES.json`, `SOURCE_AUDIT.json` |
| Startup, load release, shutdown and recovery | `POWER_RESULTS.json`, selected case files and `evidence/runs/` |
| Automotive envelope, SOA and component energy | `INPUT_PROTECTION.md`, `INPUT_RESULTS.json` |
| Actual coordinates, paths, returns and annotated views | `LAYOUT_ASSESSMENT.md`, `evidence/layout/`, `evidence/filled_returns/`, `evidence/ground/` |
| Native ERC/DRC/parity,177-part STEP, BOM and manufacturing outputs | `evidence/native/` |
| Populated/mated/probe and thermal checks | `evidence/mechanics/`, `evidence/thermal/`, `THERMAL_RESULTS.json` |
| Dispositions and physical gates | `FINDINGS_REGISTER.json`, `QUALIFICATION_AND_SERVICE.md` |
| Full and rejected experiment records | `FULL_RECORD_ARCHIVES.json`, `evidence/EXPERIMENT_INDEX.json`, `evidence/rejected/` |

The fitted U121 divider sets 4.908 V nominal; the final suite covers the retained 4.75–5.25 V interface envelope. Cold 750 mA startup at the low endpoint exposed excessive reservoir charging demand. C166 is now 68 nF C0G, with exact capacitor/IC timing bounds; the rejected longer PG delay and extra input capacitance trials remain recorded. The main final power suite has31 completed cases; two PG-tolerance cases and one discharge-copper case supplement it. Seventeen input-stress cases completed; one initially incomplete unloaded-start record is retained separately from its successful repeat. The final modeled normal main range is3.13255965–3.57139192 V. The lower supervisor margin is16.50965 mV; upper3.6 V margin28.60808 mV. The worst modeled reverse differential is about−0.067006 V against−0.3 V. All normal cases release READY once and have no SNS retries; supply-fault resets are classified separately. Results use full finite records; decimated traces are for plotting only.

The final native KiCad9.0.9 run has zero ERC, DRC, unconnected and schematic-parity findings, zero exclusions,13 successful output postconditions, and177 resolved fitted STEP components. The actual source has25 new references (24 fitted parts and TP154),41 added ordinary vias and four removed obsolete vias. Source audits preserve the49 special via identities, four-layer stackup/rules, CAN/GPIO/RF/GPS/oil contracts,32 unchanged firmware files and adopted mechanics. Mechanical review covers1308 populated plus529 mated checks and38 probes with no interferences; minimum allocated clearance0.120 mm includes the full1.71 mm stack.

The historical112.88298 C board-region correlation trigger is retained. The revised same-budget one-step board screen is113.220731 C; that difference requires physical model correlation, not a relaxed threshold. Worst leakage with both converters at exactly80% also exceeds the fixed heat budget; the measured-loss requirement is explicit. Immediate U201 air≤85 C, bulk cabin65 C, Adafruit851 local≤60 C and the sustained I25 workload remain mandatory.

## Replay

Use a checkout containing this I32 source. Python3 with NumPy/SciPy/Shapely/networkx/Matplotlib/pyamg and native KiCad9.0.9/pcbnew is required; mechanical replay also uses the repository's declared geometry dependencies. Run `--help` for individual paths. Do not save this board with an unreviewed newer KiCad serializer.

```sh
python docs/engineering/rvb22/candidate/run_native_candidate.py --cad-dir docs/engineering/rvb22/candidate/cad --output /path/to/native_i32 --kicad-cli /path/to/kicad-cli --pcbnew-python /path/to/python-with-pcbnew --component-step
python docs/engineering/rvb22/analyses/i32/source_audit.py --native-dir /path/to/native_i32 --out /path/to/source_audit
python docs/engineering/rvb22/analyses/i32/power_chain.py --cases docs/engineering/rvb22/analyses/i32/SELECTED_POWER_CASES.json --output /path/to/power --jobs 2
python docs/engineering/rvb22/analyses/i32/input_stress.py --cases docs/engineering/rvb22/analyses/i32/FINAL_INPUT_CASES.json --output /path/to/input --jobs 2
python docs/engineering/rvb22/analyses/i32/layout_audit.py --pcb docs/engineering/rvb22/candidate/cad/GR86_CCA_RevB.kicad_pcb --output /path/to/layout
```

Replay the PG and discharge supplementary case files similarly. `FINAL_INPUT_CASES.json` includes the originally incomplete unloaded case; replay is a new execution, not retroactive completion of that record. The current 34 cases are selected by exact parameters and `record_directory` in `POWER_RESULTS.json`; 15 use the first final execution and 19 use complete repeats after record-write interruption. Older groups, including previous narrow-voltage passes, are historical even if their directory names or old archive metadata say selected. Full native input/output inventories, exact decks, controller libraries, command logs and raw hashes remain the execution authority. `evidence/REPLAY_COMMANDS.json` records the geometry/ground/thermal commands and retained baseline dependencies. Vendor trial summaries have their own explicit abort/end-time status.

`author_candidate.py`, `controlled_reservoir.py`, `refine_candidate.py`, `refine_bulk_charge.py`, old route tasks and `history/` preserve intermediate design work. They are **not an idempotent way to reconstruct the final board** and must not be run on the delivered candidate. Reproduce the selected source by checkout and verify it with the native runner/source audit. `ADOPTED_ROUTE_INVENTORY.json` records surviving task UUIDs; rejected or partially replaced routes are not silently counted as complete.

The recovered I31 ZIP with61 cases and SHA256`92788424fa8389690963c58553d177a2e55a9ba1fec3674175d1477569b8f1ca` remains distinct from the newer132-case repository summary whose full ZIP is missing. I32 does not add those counts or invent the missing logs. The unmodified U121 vendor baseline completed; the historical170-part closed attempts on ngspice42/47 aborted near21.3 ms. They do not validate the final177-part design. Manufacturer-controller correlation, hot soak, pulse survival, installed fit and supplier process acceptance remain genuine physical gates.

The record index contains 664 experiment directories, 622 positive-size retained waveform payloads and one explicitly invalid zero-byte historical artifact in 19 original ZIP containers. These counts are preservation inventory, not passing case counts. `RAW_ARCHIVE_DISTRIBUTION.json` maps the original containers to exact byte parts where needed. Restore with `record_archive_parts.py restore --manifest RAW_ARCHIVE_DISTRIBUTION.json --parts-dir /path/to/downloaded --output-dir /path/to/restored`; each part and restored ZIP is checked. Failed or superseded executions stay separate from the accepted 34 power and 17 input cases.

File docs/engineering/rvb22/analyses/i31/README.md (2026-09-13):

# I31 — tentative normal-power sign-off, with residual risks

## Disposition

**Tentative normal-power / first-article sign-off only.** The complete derivative power-chain model predicts that 12 V can start the protected input, 5 V stage, main 3.3 V stage and delayed ESP32 EN under the adopted release profile. A limited first-article build for controlled bench qualification is reasonable. This is **not** an all-corner electrical pass, automotive-survival certification or unrestricted vehicle/product release.

Two substantive residual risks remain: uncertain-controller startup overshoot and reverse discharge through U151 on power removal. They are not waived by this tentative disposition. The original 290-row register has not been rewritten to conceal them. No production PCB/BOM/firmware changes, physical tests, supplier approvals, orders, flashing or merges occurred in I31. No CI polling was used as a substitute for engineering.

Reviewed head: `2a60b17e086ba2ddf0fc663f1889748d02ded7f7`; PCB SHA-256 `a04f42b358fa65a332128115a7b648e1a2297531ecb47466ac24697de536a936`. The I29-to-I30 comparison contains only six analysis additions, no CAD/firmware changes. Native XML SHA-256 `3cc5122bbbc2653570be75a87885d7bc0189e3a511f1c3c515fcf69feddeeedf` came from the source-matched I28 archive. Twelve explicit part/configuration checks passed; this is inspection of existing native output, not a new KiCad run.

## Executed work

**132 transient computations completed**, including calibration, sensitivity and deliberately wrong-feedback experiments. This is not a claim of 132 product passes. Five failed setup/export/timeout attempts are preserved separately. Eleven integrity/replay regression tests passed. Standalone replay reproduced the nominal full waveform SHA and correctly retained the wrong-feedback overvoltage result.

- 16 upstream calibration runs and two corrected holdout fixtures.
- 18 full input/buck/buck/reset cascade runs.
- 64 U151 passive/reference/timing combinations with the central assumed controller.
- 18 experiments across nine uncertain controller coefficient sets.
- One completed hybrid with **TI's unchanged LM5164-Q1 switching model driving the U151 derivative**.
- Four extra risk probes and nine unadopted assembly sensitivities.

`lm63615_derivative.lib` is an original current-mode architecture approximation, not decrypted TI content. It includes finite current response, uncertain Type-II control, soft-start, delayed FPWM negative-current availability, current-command saturation, external RLC dynamics and signed input-power coupling. There is no ideal regulated 3.3 V source or artificial 3.6 V output clamp. L151 uses the published 77.1 milliohm maximum DCR at25C, plus a hot-copper sensitivity. Fitted C206470uF/R15882milliohm and R15310milliohm remain in the model.

The longer-interval U121 approximation is an empirical averaged surrogate fitted to the previous completed vendor-model load-step trace. Its effective reference `5/4.09` is a calibration parameter, **not** the manufacturer's actual1.2V reference. Calibration error is about14.4mV RMS; independent startup holdouts disagree by about52–56mV RMS, and the low-input settled surrogate overpredicts by36.8mV. It is not a high-accuracy COT replacement. U151's actual internal compensation remains unknown.

## Main results

| Experiment | Computed result | Scope |
|---|---|---|
| Full derivative cascade,12V raw,450mA released load | Main settles3.3602V; startup peak3.4990V;5V peak5.0759V | Nominal predicted functional pass |
| Sequencing | Main95% near41.38ms; EN release near61.33ms | Includes modeled32ms input reconnect and20ms supervisor delay |
| 9/14.4/18V raw | Central-model startup/regulation complete | Not all-temperature line regulation |
| Settled main load20→450→750→20→450mA | Main3.3101–3.4495V after63ms | Brief750mA stress, not sustained thermal release |
| 450mA throughout startup | Starts; peak3.4605V | Does not depend exclusively on20mA pre-reset load |
|6V crank, reverse-input recovery,24V OV/recovery | Disconnect/reset/restart computations complete | Not automotive pulse/SOA qualification |
|2us→1us maximum timestep | Nominal main peak changes about1.4uV | Numerical agreement, not physical accuracy |

The real-U121 hybrid completed5.8ms and2,489,236 samples without abort. Main peak3.4990V;5V peak5.0599V; final0.5ms5V average4.9774V. U121 switching-current peak1.2254A; U151's1.4491A is an **averaged**, not switching, current. Main is still relaxing at the endpoint (final0.5ms average3.4726V). The20ms reset delay cannot complete within5.8ms: **hybrid evidence corroborates early startup only**, while later settling/EN/workload use the longer derivative. TI library SHA `e11ddf6995163f98eda6205de6a7cb74c8a3982b7328467de8d806286e894b5d`; it is not redistributed.

## Findings retained, not passed

**I31-PWR-01 — unknown-control startup margin.** A slow assumed controller reaches3.7353V (about3.50ms above3.6V). A low-ESR/high-reference case reaches3.6069V (about81us above3.6V). These are not proven silicon failures, but they are not passes. The64 central-controller corners peak at3.5945V; the remaining5.5mV before ripple/model/measurement allowances is insufficient for a robust all-corner claim. A separate DC source ceiling calculation is3.4183V including reference/divider and FB-leakage allowances, not a transient bound. Reducing C206 improved some startup cases while worsening load-release excursions; no unvalidated value change was adopted merely to improve a plot.

**I31-PWR-02 — reverse discharge.** The power-off model allows U151 VIN to fall0.584V below output. Generic body-diode current peaks31.1mA, with0.599mC charge and0.335mJ energy over the recorded interval. Small modeled energy does not waive TI's recommendation to prevent VIN falling more than0.3V below output. An unadopted output-to-input bypass (anode3V3 source,cathodeU151VIN) with assumed0.25V drop plus0.2ohm reduces the differential to0.2574V; a0.35V version does not meet the screen. A real diode's part/temperature/leakage/routing qualification is still required. No diode was added to production CAD.

**I31-PWR-03 — startup loading scope.** A constant750mA from power-on cycles and never releases EN in the approximate cascade.450mA startup and brief750mA steps after regulation succeed centrally. The450mA release allocation must not be reinterpreted as750mA guaranteed startup or hot continuous capacity.

## Gates before unrestricted use

Apply the retained input/harness contract and I26 qualification plan. Capture rails/current/EN during startup, allowed load transitions, crank and power removal. Main must never exceed3.6V including measurement uncertainty; a3.55V engineering headroom target is desirable. Retain3.443V steady-profile bound, active minimum3.0V and5V range4.75–5.25V. Require correct reset hold/release and no unintended resets. Resolve the reverse-discharge recommendation with verified behavior or an approved external bypass before unrestricted release. Same-footprint passive tuning or a diode assembly addition may suffice if needed; absence of a future PCB respin is not guaranteed.

Preserve160MHz,BLE+3dBm,noWiFi,<=120notifications/s,<=0.45A sustained,>=80% efficiency or established loss alternatives. I25/I26 thermal correlation remains mandatory:65C bulk air,U201 immediate air<=85C,stability<0.1C/min for30minutes,zero unintended resets.851 accessory local environment<=60C. This SPICE work does not explain or exclude RevA's five-minute failure.

Unmodeled or approximate: exact proprietary compensation, bootstrap/VCC dynamics, switching-edge parasitics, semiconductor thermal behavior, actual fault/hiccup states, saturation curves, MOSFET/TVS pulse SOA, quiescent current and exact discharge state machine. Capacitor retention, DCR/ESR, reference/timing and controller-family sweeps are explicit selections, not an exhaustive statistical manufacturer-corner campaign. The auxiliary44.1uF aggregate includes a reflected GPS-LDO approximation, not44.1uF literally connected to5V. Efficiency is an assumption, not an achieved result.

## Reproduction and full evidence

The two checked-in source files provide the exact nominal full derivative replay:

```sh
ngspice -b nominal_cascade.cir
```

Run from this directory. The recorded engine is ngspice39/Debian39.3+ds-1. Confirm the final saved time is0.12s, all values finite and no abort diagnostics; exit status alone is insufficient. Nominal deck SHA `21b780b0de48c5f5179759924514af041bea33b979d77cfed38fbc895828ff29`; model SHA `4f6a4e03df1ed2ffde2e171591b34728107e5ac444baba3c9c5afe4732a6ef90`; replay waveform SHA `4869168e6d7bf9f719eda9a3237988e096002080e98735ccaf75fcd7a7d9e8ad`.

The accompanying conversation artifact **GR86_RevB_I31_Tentative_Power_Signoff.zip** contains the complete report,132 case decks/results, failed attempts, source audit, waveform hashes, compact plots/traces, generic generators, validated replay/integrity scripts and871-member integrity manifest. Archive SHA-256 `740fe6b6ba41065643569e2d20c0a6af0fe544fb3a8e421d8490c89d245df21e`. Full-resolution traces are regenerated by replay; extrema came from the original full traces, not the compact plots. Neither vendor libraries nor engine binaries are redistributed. This repository entry is the compact core, not a claim that every archived log is committed here.

Primary sources:
- https://www.ti.com/lit/ds/symlink/lm63615-q1.pdf
- https://www.ti.com/product/TPS3808-Q1/part-details/TPS3808G33QDBVRQ1
- https://www.coilcraft.com/en-us/products/power/high-voltage-inductors/xgl/xgl5030/xgl5030-153/
- https://www.espressif.com/sites/default/files/documentation/esp32-s3-wroom-1_wroom-1u_datasheet_en.pdf
- https://www.ti.com/lit/zip/snvmbp2

Online TI parsed text identifiedRevJ while page screenshots identifiedRevI; the cited control/startup and reverse-discharge recommendations were consistent. No unobserved proprietary behavior is asserted.

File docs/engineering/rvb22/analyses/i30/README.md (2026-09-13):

# I30 — executed derivative SPICE, U121 scope

## Outcome

**A derivative SPICE route is working. Thirteen independently derived U121 switching-model experiments completed locally. Whole-board power startup and automotive survival are NOT signed off by this work.** There were no production ECAD changes, physical tests, fabrication orders or merges. No CI completion was required for this publication.

The reviewed source is `ccbf75e8da97895afa900d5a4ae53cc0641fc97c`, PR #46, branch `codex/rvb24-coordinated-closure`. Authored PCB SHA-256 is `a04f42b358fa65a332128115a7b648e1a2297531ecb47466ac24697de536a936`. `SOURCE_COMPONENTS.json` freezes the U121 external network extracted from the matched native schematic netlist, including exact MPNs and pins. It does not automatically validate a later CAD change.

## What was simulated

Engine: ngspice 39 / Debian 39.3+ds-1, with the matching XSPICE analog code-model library loaded. `cot_derived.lib` is independently derived from the published constant-on-time architecture; it is neither a TI-validated macromodel nor a decrypted library. Inductor/capacitor dynamics, switched power delivery, finite switch resistance, feedback/ripple injection, external EN divider, soft-start ramp and simplified peak/valley limits are simulated. There is no ideal regulated 5 V output source.

The fitted network includes L121 47 uH, R121 31.6 kohm timing parameter, R122/R123 309/100 kohm, R124/C125/C126 43.2 kohm/3.3 nF/100 pF ripple injection, C127/C128 22 uF each, input capacitors, and the 100/26.1 kohm EN divider. The bootstrap, internal bias and PGOOD circuits are outside this model.

## Actual results — derivative-model predictions

Thirteen completed runs comprise twelve source-configuration/sensitivity cases (including an expected EN-off case) and one wrong-feedback negative control. Each reached its requested end time with finite waveforms. `RESULTS_SUMMARY.json` records the numbers and explicit nonclaims.

| Experiment | Result |
|---|---|
| Nominal release-equivalent resistive load | 4.99742 V settled; 0.599 A startup peak inductor current |
| First crossing of 4.75 V during nominal startup | 2.904 ms from simulation start |
| 8 / 13 / 17 V converter-input fixtures | 4.96764 / 5.01314 / 5.03028 V settled |
| 0.10 to approximately 0.75 A load transition, 10 us rise, on the 5 V output | 4.85633–5.01754 V after the step; 0.964 A peak inductor current |
| Selected 50% large-capacitance, 80% inductance, 150% resistance sensitivity | 4.99475 V settled |
| -2% / +2% reference sensitivity | 4.90099 / 5.09384 V settled |
| Maximum timestep 20 ns to 10 ns | Mean output changed by approximately 9.50 uV |
| 7 V converter input | Off, consistent with the external EN-divider model |
| Deliberately wrong R122 618 kohm, simulation only | 8.65357 V: overvoltage detected, not accepted as the product configuration |

The default 10.6877 V fixture is at the CONVERTER INPUT, representing the earlier conservative operating-point calculation for a 12 V battery input. This is not a new completed end-to-end automotive input simulation. The nominal resistive load is approximately 0.467 A at 5 V. The load step is on the 5 V stage, not the downstream 3.3 V rail.

The scoped voltage screen is 4.75–5.25 V after regulation, with peak inductor current below the selected 1.25 A peak-limit reference. Timestep agreement supports numerical consistency, NOT physical accuracy. The nominal modeled output ripple is about 0.96 mV peak-to-peak, excluding real switching-edge ringing and layout parasitics. Do not replace the established 80% thermal-design efficiency assumption with the apparent efficiency of this simplified loss model.

## Limits and uncompleted attempts

The model uses nominal typical 0.725/0.34 ohm switch resistances, 0.134 ohm nominal-reference-temperature inductor DCR, assumed capacitor ESR, 100 pF switch-node capacitance, and smoothed comparator/one-shot transitions. Detailed bootstrap starvation, gate charge/deadtime, inductor saturation, capacitor DC-bias/temperature guarantees, exact foldback/sleep behavior, operating quiescent current, thermal shutdown, semiconductor safe operating area and extracted PCB parasitics are not represented. Selected sensitivity cases are not an exhaustive tolerance or Monte Carlo campaign. The simplified valley-limit gating is exposed rather than claimed to be the exact internal device state machine.

The larger hybrid model (protector, switching U121, averaged U151 and reset supervisor) aborted numerically before its requested endpoint. Later functional protection models also failed to complete undervoltage, overvoltage, reverse-input and illustrative surge sequences. These are unaccepted simulation attempts, not observed hardware failures and not passes. Their logs/decks and rejected early prototypes are retained in the accompanying I30 evidence archive.

Therefore the complete **12 V -> 5 V -> 3.3 V -> ESP32 EN sequence remains unverified by SPICE**. U151's internal compensation remains uncorrelated and its acquired vendor library encrypted. Automotive surge survival and the historical five-minute Rev A failure are not ruled out by these millisecond U121 experiments. This work does not grant fabrication clearance or change physical qualification requirements.

The I29 finding also remains: loading the correct XSPICE libraries allowed the unmodified LM5164-Q1 vendor model to load, but those vendor-model experiments were numerically unusable/incomplete. An original model-loading error was not evidence that all SPICE approaches were impossible.

## Replay without CI

Install Python 3.10+, NumPy 2.x and ngspice with matching XSPICE libraries. From this directory:

```sh
python -m pip install 'numpy>=2,<3'
python replay_converter.py --ngspice /path/to/ngspice --output /new/output/directory
```

Add `--code-model-dir /directory/containing/analog.cm` for a relocated ngspice installation without its default code-model paths. The code-model path must contain no spaces for this ngspice command. `--case cot_nominal_v2` selects one case. Existing output directories are rejected. Aborted/partial waveforms are never accepted just because ngspice emitted measurements or returned normally. Wrong-feedback and EN-off cases have explicit expected behavior rather than being counted as nominal 5 V passes.

The standalone portable entry point was rerun for the nominal case: 8 ms completed, 1,249,195 samples, 4.997420669412825 V mean output. The accompanying `GR86_RevB_I30_SPICE.zip` contains the detailed report, engine logs, input decks, full result JSON, decimated representative waveforms, plot, replay verification and rejected attempts. Full-resolution waveforms are regenerated by the replay; the archive does not pretend decimated data are full resolution.

## Primary model references

- TI LM5164-Q1 datasheet: https://www.ti.com/lit/ds/symlink/lm5164-q1.pdf
- TI LM63615-Q1 model/product page: https://www.ti.com/product/LM63615-Q1
- ngspice behavioral/XSPICE support: https://ngspice.sourceforge.io/xspice.html
- ngspice compatibility and encrypted-model limitations: https://ngspice.sourceforge.io/modelparams.html
- Coilcraft MSS1246T series: https://www.coilcraft.com/en-us/products/power/shielded-inductors/molded-inductor/mss/mss1246t/

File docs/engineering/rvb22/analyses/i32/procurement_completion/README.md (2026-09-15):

# I32 sourced ECAD and manufacturing package

**All 175 factory references have verified JLC catalog assignments.** All 29
previously missing assignments are resolved with the exact specified MPNs. Both
native schematics and PCB carry the assignments, source URLs and supplier MPNs.
KiCad 9.0.9 regenerates the BOM, CPL, schematic PDF/XML, Gerbers and drills.
Supplier acceptance and physical qualification remain open; no order is placed.

## Files to use

- `editable_source/cad/GR86_CCA_RevB.kicad_pro`: current sourced native project.
- `assembly/COMPLETE_FITTED_BOM.csv`: all 177 fitted references exported from the schematic.
- `assembly/PROCUREMENT_BOM.csv`: all 177 references with source and acceptance status.
- `assembly/PROCUREMENT_REDLINE.csv`: every new assignment and documented identity alias.
- `assembly/JLCPCB_BOM.csv` and `assembly/JLCPCB_CPL.csv`: the same 175 factory references, with no blank JLC codes.
- `assembly/PREORDER_REQUIREMENTS.csv`: factory parts with zero stock in the captured JLC snapshot.
- `assembly/LOCAL_ASSEMBLY_BOM.csv`: F101 and U401 only.
- `assembly/DO_NOT_POPULATE.json`: C203, R301 and R306 remain DNP.
- `fabrication/JLCPCB_GERBERS.zip`: regenerated fabrication outputs.
- `COHERENCE.json` and `SOURCE_MANIFEST.json`: scope and hashes for every package member.

In the repository these files live in `docs/engineering/rvb22/current/i32_sourced_manufacturing/`.
The archive is `docs/engineering/rvb22/product/GR86_I32_SOURCED_MANUFACTURING.zip`.

## Exact parts and documented aliases

Every factory part has a JLC catalog purchase/preorder path at the retained
snapshot. No factory part uses Global Sourcing or consignment. The public catalog
search, rather than general web-search coverage, resolved the final exact MPNs.
The generated redline lists all 29 new assignments. No component value, MPN,
footprint, package model, placement or route was substituted in this continuation.

Five part-specific spelling mappings cover twelve references: three TDK catalog
numbers versus packaging-label item descriptions, F1's leading zero and R104's
separator. `SupplierMPN` records the catalog spelling while `MPN` retains the
qualified design identity. The JLC import uses the verified supplier spelling.
`IDENTITY_ALIASES.md` records the evidence; arbitrary suffix/punctuation stripping
is rejected. All 13 frozen substitution references retain their exact MPN/C-number
bindings.

## Engineering binding

The maintained inputs are the qualified `candidate/cad/` circuit/geometry and
`analyses/i32/procurement_completion/SOURCES.json` procurement decisions.
`build.py prepare` generates the sourced native project. Edit those maintained
inputs and regenerate; do not hand-edit generated copies.

Only `LCSC`, `ProcurementRoute`, `ProcurementURL` and `SupplierMPN` may differ.
Complete parsed-tree comparisons protect all values, MPNs, connections, pad and
route geometry, models, stackup, rules and the 49 special vias. Fresh native ERC,
DRC, unconnected and schematic/PCB parity checks are zero. The filled PCB is
identical after removing procurement fields and regenerated property IDs. All
14 fabrication files match the qualified outputs apart from generation headers;
the complete native placement table and schematic nets also match.

The existing populated STEP, 32/32 electrical cases, 17/17 normal sequences,
thermal results and 160 MHz firmware build are carried forward through this
exact physics comparison. **No new SPICE, thermal solver, component STEP export
or firmware build is claimed.** Historical executed evidence remains in
`analyses/i32/procurement_redline/` with its original source binding.

## Reproduction in the repository

```sh
python docs/engineering/rvb22/analyses/i32/procurement_completion/build.py prepare
# Use KiCad 9.0.9 and its matching Python pcbnew bindings; choose a new output directory.
python docs/engineering/rvb22/candidate/run_native_candidate.py \
  --cad-dir docs/engineering/rvb22/current/i32_sourced_manufacturing/editable_source/cad \
  --output /tmp/gr86-sourced-native --pcbnew-python /usr/bin/python3
python docs/engineering/rvb22/analyses/i32/procurement_completion/build.py package \
  --native-dir /tmp/gr86-sourced-native
python docs/engineering/rvb22/analyses/i32/procurement_completion/build.py verify \
  --native-dir /tmp/gr86-sourced-native
```

The committed native run is in `analyses/i32/procurement_completion/native/`.
Omit `--native-dir` to verify it. Package ZIPs use deterministic member timestamps.
JLC responses and extracts are retained in `catalog/` beside the script and in
`sourcing_evidence/catalog/` inside the package. Verification makes no network
calls. The pinned Docker image and native execution scope are in
`NATIVE_TOOLCHAIN.json`; CI repeats the sourced native run.

## Remaining ordering gates

Catalog assignment is complete. Purchase the required preorders and obtain
supplier confirmation of build quantities/attrition, inventory allocation,
handling, orientation, stackup, via fill/cap/planarization, minimum plating and
stencil before ordering assembly. Stock snapshots do not reserve inventory.
See `ASSEMBLY_AND_ACCEPTANCE.md` for the retained construction requirements.
F101 and U401 remain local installs; exact PA1616D supply/receiving acceptance is
still required. Physical fit, thermal/loss correlation, bench electrical/EMC and
vehicle testing remain open. Nothing has been purchased, submitted to a supplier
or merged.

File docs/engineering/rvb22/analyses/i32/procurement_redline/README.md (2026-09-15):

# I32 procurement redline — completed desktop verification

The frozen procurement set is applied to the actual native candidate, with regenerated assembly/fabrication outputs. All 14 requested desktop gate categories pass within the declared model and supplier-catalogue scope. This is not an order authorization, supplier acceptance, hardware validation or full-product qualification.

The starting remote revision was `1c934f9ddd7a1b823e5136484f525485472528f6` on `codex/rvb24-coordinated-closure`, PR #46. The immutable pre-redline CAD commit is `e5ef8425dbe59c99e99eabb75c04342a47b27561`. Its four subsequent evidence/handoff commits remain ancestors. The final publication commit is the commit containing this report; the PR publication record identifies the remote SHA without a self-referential file hash.

Current authority is [FINAL_REDLINE_VERIFICATION.json](FINAL_REDLINE_VERIFICATION.json), [SOURCE_BINDING.json](SOURCE_BINDING.json), and [the manufacturing manifest](../../../current/i32_manufacturing/SOURCE_MANIFEST.json). [CHANGED_PATHS.md](CHANGED_PATHS.md) enumerates every changed CAD, model, manufacturing and evidence path. Original current records are preserved under `history/pre_redline/`; existing experiment history and the controlling readiness/handoff documents remain intact.

| Native artifact | SHA256 |
|---|---|
| Authored PCB | `52ca35cf8cb4e2b4a27d053686ee3a85564f1e94dfdb7dcb4bca4083dd527312` |
| KiCad filled PCB | `896ca56bf4ad836d63b84537cfd20bfcbf1783c60ac5d92ab7c7783d54f57e92` |
| Native schematic XML | `3a3ac0ad2e7acc75bd5690a128a7d47e28859e017c66fe01276025dfa7dda93d` |

## Exact substitutions

| References | Frozen MPN | JLC/LCSC | Package |
|---|---|---|---|
| C152,C154,C165 | CGA3E3X7R1H224KT0Y0N | C342967 | 0603 |
| L121 | BPCI00121280470M00 | C6471075 | 12 × 12 mm SMD |
| R155 | PTFR0603B11K8N9 | C19679768 | 0603 |
| R156 | PLT1206Z5051LBTS | C4074185 | **1206** |
| R160 | RT0805BRB076K34L | C864499 | **0805** |
| R161,R163,R170 | PTFR0603Q1K00N9 | C23067434 | 0603 |
| R162 | PTFR0603Q4K70N9 | C23067437 | 0603 |
| R169 | PTFR0603B3K01N9 | C2692830 | 0603 |
| U101 | LTC4367HMS8#PBF | C688370 | MSOP-8 |

U101 remains the H-grade electrical device. The owner accepts losing the **#W controlled-manufacturing ordering pedigree**. The #PBF pedigree is not equivalent. This acceptance is recorded in the native schematic and PCB properties. F101 and U401 remain unchanged local/manual installations. No unrelated MPN was substituted. R151's previously missing PCB LCSC field was reconciled to the already-existing schematic/BOM value C190124; all its electrical and physical properties are unchanged.

## Physical and model changes

All 13 frozen references use checked `RevB:I32_PROCUREMENT_<ref>` footprints. Manufacturer documents, exact file hashes, pad/net checks, body dimensions, mask/paste membership and model distinctions are in [PACKAGE_QUALIFICATION.json](PACKAGE_QUALIFICATION.json). Nine new STEP files are dimensionally correct generic maximum-body envelopes, explicitly not vendor CAD. Existing capacitor and MSOP generic models remain, with maximum body/tolerance covered in the mechanical check. All 177 fitted models resolve in the populated STEP export.

| Ref | Native placement (mm, degrees) | Physical change |
|---|---|---|
| R156 | B.Cu, (41.25, 10.101), −90° | 0603 → 1206. Vishay 60119 lands: 0.9144 × 1.7018 mm at ±1.524 mm. Maximum body 3.4032 × 1.7272 × 0.8382 mm; courtyard 4.5 × 2.25 mm. Ground-pad centre retained at (41.25, 11.625). Added 0.25 mm feedback copper to the moved pad. |
| R160 | F.Cu, (27.0, −7.5), 0° | 0603 → 0805. Lands 1.0 × 1.45 mm at ±1.025 mm; maximum body 2.1 × 1.35 × 0.6 mm. Courtyard 3.55 × 1.95 mm. Centre/orientation unchanged. |
| L121 | F.Cu, (59.8, 29.05), 90° | Replaced Coilcraft-specific pattern with the BPCI manufacturer pattern: 5.4 × 2.8 mm pads, 7 mm inner gap, 9.8 mm centre spacing, 12.6 mm outer span. Maximum body 12.5 × 12.5 × 8 mm; 13.1 mm courtyard. Moved −0.2/+0.05 mm to preserve nearby protected clearances. |
| R155 | B.Cu, (44.0, 10.8), 90° | Qualified PTFR lands; shifted −0.55 mm in X for package spacing. |
| R169 | B.Cu, (79.8, 1.7), 0° | Qualified PTFR lands; shifted −0.2/−0.3 mm. |
| R170 | B.Cu, (83.2, 1.7), 0° | Qualified PTFR lands; shifted −0.1/−0.3 mm. |

R161/R162/R163 also receive the actual PTFR pattern: 0.9 × 1.2 mm pads at ±0.95 mm, within the manufacturer's dimensional land-pattern range. The same-package capacitor and U101 substitutions preserve pad sizes and pin/net identity. Pads, paste, mask, courtyards, copper/via clearances and native orientation are checked for all changed references.

Routing moves the 3V3_ENABLE left leg to X25.1 and crossbar to Y−8.6; the 3V3_VIN sense crossbar to Y−5.0; and the 5V_RIPPLE leg to X53.1375. The LED_OIL ordinary 0.6/0.3 mm via moves from (41.1, 8.3) to (38.3, 8.9), with its B.Cu and In2.Cu connections rerouted. These changes clear enlarged pads while preserving all pad nets. The source audit records one added segment, 18 modified copper objects, no removed copper objects and no added or removed vias. All 49 special vias, stackup, custom clearances and rules remain unchanged. The complete UUID-level delta is in [SOURCE_AUDIT.json](SOURCE_AUDIT.json); annotated route views are in `layout/`.

## Verification and manufacturing

| Gate | Result and retained evidence |
|---|---|
| Native KiCad 9.0.9 | ERC 0, DRC 0, unconnected 0, schematic/PCB parity 0, exclusions 0; 13/13 output postconditions. `native_final/` |
| Exact source | 157 CAD files bound; 32 firmware files unchanged. Original GPIO, receive-only CAN, RF, GPS and oil signal contracts retained. `SOURCE_AUDIT.json` |
| Independent copper/export reconstruction | PASS across 145 nets and 571 net-bearing pads, with no disconnected pad nets or pad/net mismatches; Gerber flashes/traces/fills and drill exports matched. `manufacturing_audit_final/` |
| Explicit source copper | Zero new/worsened foreign-net gaps below 0.15 mm, zero prior pad-connectivity regressions and no unsupported primitives. `EXPLICIT_COPPER_FINAL.json` plus exact metadata rebind |
| Power returns | 23/23 actual-filled ground pairs connected. Source return 11.282 mΩ against 15 mΩ; C206 allocation 10.919 mΩ against 11 mΩ. `filled_returns_final/`, `ground_final/` |
| Packages/models | 13/13 exact identities, pad nets, lands, models and mask/paste memberships checked. `PACKAGE_QUALIFICATION.json` |
| BOM/CPL | 177 fitted; 175 factory CPL rows; F101/U401 local; C203/R301/R306 DNP. Every frozen ref has its exact MPN/C-number; zero old frozen MPNs in active BOM. `MANUFACTURING_RECONCILIATION.json` |
| Manufacturing | 11 Gerber layers, 2 drill files, 1 job file; IPC-D-356, schematic PDF/XML, populated STEP, 49-via list and editable CAD copy regenerated. `current/i32_manufacturing/` |
| Mechanical | 1,308 populated checks, 529 mated checks, 38 probe approaches; no modeled interference. Full 1.71 mm height stack; minimum allocated clearance 0.120 mm. `mechanics_final/` |
| Analysis binding | 16 existing native-binding unit tests passed. Full filled-tree comparison preserves every physical/model token and native filled polygon across the final descriptive cleanup. `NATIVE_BINDING_TESTS.log`, `METADATA_ONLY_REBIND.json` |

Native CPL coordinates use the retained auxiliary origin (0, 41.288863) mm. R156: Bottom, X41.25/Y31.187863, −90°; R160: Top, X27/Y48.788863, 0°; L121: Top, X59.8/Y12.238863, 90°. All 175 rows reconcile against native reference, side, X/Y and rotation. Supplier feeder/pin-one and bottom-side interpretation remain assembly setup acceptance items.

The factory list contains **29 unchanged references without assigned LCSC codes**, enumerated in `assembly/SOURCING_REQUIRED.csv`. This redline resolves the frozen set; it does not authorize opportunistic substitutions or claim that the entire BOM is turnkey-order-ready.

## Fresh electrical replay

The recovered final-procurement ngspice 42/KLU runner completed 32/32 swap/stress cases and 6/6 controls; all 17 normal cases sequenced correctly. All 38 full waveform records are retained losslessly as gzip, with compressed and decompressed hashes in `spice/RAW_RECORD_MANIFEST.json`. 38 large gzip files are stored as exact byte parts of at most 8 MiB; `python restore_waveforms.py --restore` reconstructs them after checking each part, the complete compressed stream and the decompressed waveform hashes. No waveform samples or precision are discarded. Executed scripts, decks, solver logs and results are retained; the prior hosted qualification run remains 34899316734. No acceptance threshold was relaxed.

| Metric | Final result |
|---|---|
| Worst normal 3.3 V minimum | 3.12786634 V |
| Reset limit / margin | 3.116050 V / **+11.81634 mV** |
| Maximum rail / margin below 3.600 V | 3.57660977 V / **+23.39023 mV** |
| 1 µs-resolution high-side confirmation | 3.5766084 V |
| Worst reverse allocation | −0.06700731 V against −0.3 V |
| L121 peak / conservative saturation allocation | 0.942206123 A / 2.5 A |
| 30.08 µH superstress | PASS |

This uses the recovered transparent current-mode derivative model, not a final vendor-macromodel or hardware-validation claim. U101's electrical model is unchanged; unchanged input protection and signal-domain results remain applicable through the audited source contracts. The −55/155 °C inductor DCR corners are deliberate superstress, not an extension of its −40…125 °C operating rating.

SPICE and thermal runs bind to authored PCB `177454910e8699749c42599a13c613f3155a52760af65763f2c7982ffec90e66`, after the physical redline. Subsequent changes only corrected footprint descriptions/tags, R151's existing catalogue code and a README rail label. The full native tree, including every filled polygon and model, is identical after excluding precisely those fields and native-generated property UUIDs. Their original hashes/results are preserved; `METADATA_ONLY_REBIND.json` explicitly binds them to the final descriptive source. Native CAD, mechanical, ground and manufacturing checks ran again on the final source.

## Thermal and physical boundaries

The 0.5/0.25 mm actual-copper runs use the adopted C05/W02/T03 cooling and unchanged 2.940859375 W release budget. Fine result plus one positive coarse-to-fine difference gives 113.271698 °C for the same-budget allocation and 113.763359 °C for the stacked 80%-efficiency sensitivity. This is a mesh allowance, not demonstrated convergence. The historical **112.8829809018675 °C correlation trigger is unchanged**; exceeding it requires physical correlation. At U151 exactly 80%, the worst leakage allocation requires U121 efficiency at least 83.4631% or an approved measured-loss alternative within the same budget. No losses were silently scaled away.

Conditional U152/U153 junction screens are 105.7765/105.6562 °C against 130 °C using the retained 51 K/W allocation and fresh peak dissipation. The R156/R169 global board screen is 11.2366 °C below 125 °C. L121's conservative peak-as-RMS screen, using the manufacturer's typical rated-current temperature-rise definition and copper temperature feedback, is 121.6020 °C, 3.3980 °C below its 125 °C limit including self-rise. These conditional allocations require measured package-temperature and loss correlation. They are not guaranteed vendor thermal models, package measurements or evidence of immediate-air temperature.

Remaining physical gates include first-article assembly and populated/mated fit, C166 edge tolerance, probe access, material/contact/retention/fatigue acceptance, package and cooling-temperature correlation, bench electrical/transient/EMC tests, installed vehicle validation and unit acceptance. Retain the I25 workload, 65 °C cabin, U201 immediate air ≤85 °C and Adafruit 851 local environment ≤60 °C. No board was ordered, flashed, assembled or tested during this redline.

## Live frozen-source snapshot

The public exact JLC catalogue records were retrieved on 2026-09-14 at approximately 23:01–23:04 UTC and are retained in [LIVE_JLC_SOURCEABILITY.json](LIVE_JLC_SOURCEABILITY.json). All nine exact MPN/C-number pairs expose stock purchase or preorder paths. No stock or assembly capacity is reserved.

| C-number | Stock snapshot | Preorder minimum | Catalogue process |
|---|---:|---:|---|
| C342967 | 3,670 | 390 | SMT |
| C6471075 | 0 | 35 | Manual/wave |
| C19679768 | 3,984 | 85 | SMT |
| C4074185 | 0 | 2 | SMT |
| C864499 | 0 | 72 | SMT |
| C23067434 | 12,948 | 19 | SMT |
| C23067437 | 6,817 | 20 | SMT |
| C2692830 | 317 | 66 | SMT |
| C688370 | 2 | 2 | SMT |

[JLC's L121 listing](https://jlcpcb.com/partdetail/C6471075) identifies manual/wave handling. L121 remains factory-supplied in the 175-row CPL; this is not proof that all 175 rows are machine SMT placements, nor a third local-install exception. Supplier process/orientation approval, the 29 unchanged sourcing assignments, exact stackup/plating/special-via/stencil DFM and physical qualification remain before ordering.

## Reproduction

Use native KiCad 9.0.9 and the dependencies pinned in `requirements.txt`. The native workflow binds the current authored source explicitly and retains its existing CAD and 160 MHz firmware gates. Run `candidate/run_native_candidate.py` against `candidate/cad` with `--component-step`; the native runner refuses incomplete outputs. Run `analyses/i32/source_audit.py --help` and use `--procurement-redline` with the explicit source and filled hashes. Run the existing native export, layout, filled-ground, ground-return, mechanical and thermal checkers against those same native outputs. The authored candidate is authoritative; one-shot historical authoring recipes must not be reapplied over it.

`final_procurement_spice_qual.py` reruns the frozen suite into a new `I32_PROCUREMENT_SPICE_OUT` directory; it refuses an existing output directory. `spice/replay_source/` preserves the scripts actually executed for this result. The common runner's later default-bound cleanup matches the already-executed final wrapper and does not change those executed decks. `finalize_redline.py` validates evidence and the exact metadata rebind before writing the aggregate. `generate_manufacturing.py` regenerates the package from the verified `native_final/` source/export inventory.

Historical failed intermediate native checks are retained in `history/` and are not accepted results. The current native, manufacturing and source records are named `native_final/`, `manufacturing_audit_final/`, `SOURCE_AUDIT.json` and `FINAL_REDLINE_VERIFICATION.json`.

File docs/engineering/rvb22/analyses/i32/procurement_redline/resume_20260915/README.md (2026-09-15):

# I32 redline resumption verification — 2026-09-15

The frozen procurement redline was already complete and published when this session began. Its actual source, preserved execution evidence and release package have now been reverified. The exact nine-part JLC catalogue check was refreshed. This follow-up adds verification records only; the CAD, models, BOM/CPL and manufacturing outputs are unchanged.

- Repository / branch: `tranquilWorks/gr86-cca-telemetry` / `codex/rvb24-coordinated-closure`; PR #46 remains open and unmerged.
- Starting remote revision for this resumption: `0b4e3f8ef5d1535733990305315445d19c4ac5c2`.
- Original redline starting remote: `1c934f9ddd7a1b823e5136484f525485472528f6`.
- Engineering publication: `1ce3f9f9b8bdb68dc275334d22b63dd21d40e058`.
- Immutable CAD baseline: `e5ef8425dbe59c99e99eabb75c04342a47b27561`; it and all four handoff commits are preserved.
- Final publication revision: the commit containing this record, reported after remote readback.

## What was verified in this resumption

`ci_verify.py` passed with 2,006 indexed paths, 157 CAD inputs, 32 unchanged firmware files, 38 preserved waveform records, all 14 aggregate desktop gate categories and byte-identical aggregate reproduction. The release ZIP contains 188 verified members; its SHA256 remains `9a8fc224474f7744d2c8c46fdd7c82f6f1d414a18e7612d65a40dc281d79f0c5`.

`source_audit.py --procurement-redline` passed. SOURCE_AUDIT.json and SOURCE_BINDING.json reproduce byte-for-byte. The checkout remained clean after both checks. All eight hosted workflows passed on the exact starting revision; the two native workflows and evidence/package workflow job steps were checked, and native/source and package log identities were read back. See [verification record](VERIFICATION.json), [local reproduction](LOCAL_EVIDENCE_REPRODUCTION.json) and [hosted results](HOSTED_WORKFLOW_READBACK.json).

Native KiCad and ngspice were not rerun in this resumption. The existing post-redline executions remain applicable because no active circuit, model or physical source changed. The local recheck verifies that binding and retained results; it does not relabel an earlier execution as a new test.

## Final substitutions and refreshed JLC snapshot

All nine exact MPN/C-number records expose public purchase or preorder paths. The snapshot is dated by each response in [LIVE_JLC_SOURCEABILITY.json](LIVE_JLC_SOURCEABILITY.json). Six have stock; L121, R156 and R160 require preorder. Quantities are per-part catalogue snapshots.

| References | Exact MPN | JLC/LCSC | Package | Stock | Preorder minimum |
|---|---|---|---|---:|---:|
| C152,C154,C165 | `CGA3E3X7R1H224KT0Y0N` | [C342967](https://jlcpcb.com/partdetail/C342967) | 0603 | 3670 | 390 |
| L121 | `BPCI00121280470M00` | [C6471075](https://jlcpcb.com/partdetail/C6471075) | SMD,12x12mm | 0 | 35 |
| R155 | `PTFR0603B11K8N9` | [C19679768](https://jlcpcb.com/partdetail/C19679768) | 0603 | 3964 | 85 |
| R156 | `PLT1206Z5051LBTS` | [C4074185](https://jlcpcb.com/partdetail/C4074185) | 1206 | 0 | 2 |
| R160 | `RT0805BRB076K34L` | [C864499](https://jlcpcb.com/partdetail/C864499) | 0805 | 0 | 72 |
| R161,R163,R170 | `PTFR0603Q1K00N9` | [C23067434](https://jlcpcb.com/partdetail/C23067434) | 0603 | 12905 | 19 |
| R162 | `PTFR0603Q4K70N9` | [C23067437](https://jlcpcb.com/partdetail/C23067437) | 0603 | 6642 | 20 |
| R169 | `PTFR0603B3K01N9` | [C2692830](https://jlcpcb.com/partdetail/C2692830) | 0603 | 317 | 66 |
| U101 | `LTC4367HMS8#PBF` | [C688370](https://jlcpcb.com/partdetail/C688370) | MSOP-8 | 2 | 2 |

JLC labels L121 as manual/wave handling. It remains a factory-supplied CPL placement, subject to supplier process and orientation acceptance; it is not a third local-install exception. The CPL count is 175 factory placements, not a claim of 175 automatic SMT placements. F101 and U401 remain the two local installations. U101 retains the owner-accepted loss of #W controlled-manufacturing pedigree; pedigree equivalence is not claimed.

The first parser pass encountered four missing optional `noBuyReason` fields. Those failures are preserved in [LIVE_JLC_FIRST_ATTEMPT.json](LIVE_JLC_FIRST_ATTEMPT.json). The corrected extraction uses explicit purchase/preorder flags and separately records whether the optional field exists. All four retries passed exact-identity and availability checks. No component was changed.

## Physical redline and output reconciliation

- R156 uses the qualified 1206 footprint on B.Cu at (41.25, 10.101) mm, -90 degrees; its ground-pad centre is retained and feedback copper reaches the relocated pad.
- R160 uses the qualified 0805 footprint on F.Cu at (27, -7.5) mm, 0 degrees.
- L121 uses the manufacturer BPCI lands (5.4 x 2.8 mm pads, 7 mm inner gap) on F.Cu at (59.8, 29.05) mm, 90 degrees, with the 12.5 x 12.5 x 8 mm maximum body envelope.
- R155, R169 and R170 were shifted for clearance. The other PTFR lands, 13 changed reference identities and nine new generic STEP envelopes are qualified in the existing package record.
- One copper segment was added and 18 copper objects modified; no copper objects were removed. One ordinary LED_OIL via was moved with its connections. The 49 special vias, stackup and native rules remain unchanged.
- ERC 0; DRC 0; unconnected 0; schematic/PCB parity mismatches 0; exclusions 0. Independent export reconstruction covers 145 nets and 571 net-bearing pads.
- 177 fitted placements; 175 factory BOM/CPL rows; 2 local installations; C203/R301/R306 remain DNP. All 13 changed references bind to the frozen MPN/C-number; no old frozen MPN remains in the active BOM.
- CPL side, X/Y and rotation reconcile against native source. R156: Bottom, 41.25/31.187863 mm, -90 degrees. R160: Top, 27/48.788863 mm, 0 degrees. L121: Top, 59.8/12.238863 mm, 90 degrees.

## Retained post-redline electrical and thermal results

32/32 swap/stress cases and 6/6 controls completed under ngspice 42/KLU; all 17 normal cases sequenced correctly. Minimum 3.3 V: 3.12786634 V against a 3.116050 V reset limit, giving +11.81634 mV. Maximum: 3.57660977 V, giving +23.39023 mV below 3.600 V. The 1 us high-side confirmation is 3.5766084 V. Worst reverse allocation: -0.06700731 V. L121 peak: 0.942206123 A against 2.5 A; 30.08 uH superstress passes. These are model results, not hardware measurements.

The fixed release heat budget remains 2.940859375 W. The stacked board screening result is 113.763359283458 C; the historical 112.8829809018675 C physical-correlation trigger is unchanged. L121 conditional winding screening is 121.60197565712534 C against 125 C, a 3.3980243428746633 C margin. Physical temperature and loss correlation remain required; mesh convergence and measured junction/immediate-air temperatures are not claimed.

## Changed CAD/model/manufacturing paths

The complete original engineering/evidence inventory is [CHANGED_PATHS.md](../CHANGED_PATHS.md), with hashes and sizes in [CHANGED_PATHS.json](../CHANGED_PATHS.json). This includes every regenerated manufacturing, model, BOM/CPL and analysis path. The 29 native CAD/model paths changed by the redline are:

- `docs/engineering/rvb22/candidate/cad/CANDIDATE_README.md`
- `docs/engineering/rvb22/candidate/cad/GR86_CCA_RevB.kicad_pcb`
- `docs/engineering/rvb22/candidate/cad/Input_Protection.kicad_sch`
- `docs/engineering/rvb22/candidate/cad/Power_3V3.kicad_sch`
- `docs/engineering/rvb22/candidate/cad/Power_5V.kicad_sch`
- `docs/engineering/rvb22/candidate/cad/libraries/RevB.kicad_sym`
- `docs/engineering/rvb22/candidate/cad/libraries/RevB.pretty/I32_FINISHED_R151.kicad_mod`
- `docs/engineering/rvb22/candidate/cad/libraries/RevB.pretty/I32_PROCUREMENT_C152.kicad_mod`
- `docs/engineering/rvb22/candidate/cad/libraries/RevB.pretty/I32_PROCUREMENT_C154.kicad_mod`
- `docs/engineering/rvb22/candidate/cad/libraries/RevB.pretty/I32_PROCUREMENT_C165.kicad_mod`
- `docs/engineering/rvb22/candidate/cad/libraries/RevB.pretty/I32_PROCUREMENT_L121.kicad_mod`
- `docs/engineering/rvb22/candidate/cad/libraries/RevB.pretty/I32_PROCUREMENT_R155.kicad_mod`
- `docs/engineering/rvb22/candidate/cad/libraries/RevB.pretty/I32_PROCUREMENT_R156.kicad_mod`
- `docs/engineering/rvb22/candidate/cad/libraries/RevB.pretty/I32_PROCUREMENT_R160.kicad_mod`
- `docs/engineering/rvb22/candidate/cad/libraries/RevB.pretty/I32_PROCUREMENT_R161.kicad_mod`
- `docs/engineering/rvb22/candidate/cad/libraries/RevB.pretty/I32_PROCUREMENT_R162.kicad_mod`
- `docs/engineering/rvb22/candidate/cad/libraries/RevB.pretty/I32_PROCUREMENT_R163.kicad_mod`
- `docs/engineering/rvb22/candidate/cad/libraries/RevB.pretty/I32_PROCUREMENT_R169.kicad_mod`
- `docs/engineering/rvb22/candidate/cad/libraries/RevB.pretty/I32_PROCUREMENT_R170.kicad_mod`
- `docs/engineering/rvb22/candidate/cad/libraries/RevB.pretty/I32_PROCUREMENT_U101.kicad_mod`
- `docs/engineering/rvb22/candidate/cad/models/ENVELOPE_I32_PROCUREMENT_L121.step`
- `docs/engineering/rvb22/candidate/cad/models/ENVELOPE_I32_PROCUREMENT_R155.step`
- `docs/engineering/rvb22/candidate/cad/models/ENVELOPE_I32_PROCUREMENT_R156.step`
- `docs/engineering/rvb22/candidate/cad/models/ENVELOPE_I32_PROCUREMENT_R160.step`
- `docs/engineering/rvb22/candidate/cad/models/ENVELOPE_I32_PROCUREMENT_R161.step`
- `docs/engineering/rvb22/candidate/cad/models/ENVELOPE_I32_PROCUREMENT_R162.step`
- `docs/engineering/rvb22/candidate/cad/models/ENVELOPE_I32_PROCUREMENT_R163.step`
- `docs/engineering/rvb22/candidate/cad/models/ENVELOPE_I32_PROCUREMENT_R169.step`
- `docs/engineering/rvb22/candidate/cad/models/ENVELOPE_I32_PROCUREMENT_R170.step`

The [manufacturing source manifest](../../../../current/i32_manufacturing/SOURCE_MANIFEST.json) binds the generated outputs. The [release ZIP](../../../../product/GR86_I32_PROCUREMENT_REDLINE.zip) is unchanged and verified. This resumption adds only the files in its own directory.

## Remaining supplier and physical gates

29 unchanged factory references still lack LCSC assignments in the release BOM and remain listed in SOURCING_REQUIRED.csv. The frozen substitutions are resolved; the whole board is not turnkey-order-ready. JLC must accept L121 handling/orientation and the specified stackup, finished plating, filled/capped/planarized vias and stencil/assembly process.

First-article fit and assembly, C166 edge tolerance, probe access, cooling materials/contacts, converter losses and thermal correlation remain open. Retain the I25 workload, 65 C cabin, U201 immediate air <=85 C and Adafruit 851 local environment <=60 C limits. Bench startup/brownout/reset/reverse-protection and EMC/transient tests, vehicle validation and unit acceptance remain physical gates. No order, hardware flash, physical measurement or PR merge occurred.

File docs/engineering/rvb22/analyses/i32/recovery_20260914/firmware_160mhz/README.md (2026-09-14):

# I32 160 MHz firmware closure evidence

This directory preserves a genuine ESP32-S3 target compilation of the unchanged adopted firmware at `CPUFreq=160`. `RESULT.json`, the source/tool inventories, verbose compiler log, split images, 8 MiB merged image, ELF/map, and preserved 28-check release result define the evidence.

The shell allowlist blocked Arduino's package indexes, so the same official Arduino CLI 1.3.1, Arduino-ESP32 3.3.6, ESP32-S3 libraries, GCC 14.2.0_20251107, esptool 5.1.0 and NimBLE-Arduino 2.3.6 were installed directly from their official GitHub release archives and verified by published SHA-256. Arduino's small `ctags` helper was built from the exact `arduino/ctags` 5.8-arduino11 tag with a macro-name compatibility edit for current glibc; this affects prototype discovery only and is disclosed in `TOOLCHAIN_INVENTORY.json`.

The ELF and linker map are stored losslessly as gzip files because the authenticated publication connector limits request bodies to 16 MiB; `IMAGE_MANIFEST.json` records both compressed containers and the original artifact identities, and `run_release_check.py` expands the ELF only in a temporary directory. The build was not flashed or executed on target hardware. It does not close supplier, assembly, vehicle, EMC, thermal-correlation, or first-article gates.

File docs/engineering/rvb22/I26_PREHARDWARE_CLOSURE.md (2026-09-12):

# I27 pre-hardware engineering closure — fabrication request clear

As of 2026-09-12, the controlled 290-row register contains **0 actionable pre-hardware engineering items**. Literal original criteria that require fabricated, supplier, installation, vehicle, environmental or visibility evidence remain open as qualification gates; no such physical evidence is claimed.

Aggregate pre-hardware classification: **141 desktop/source/documentary, 31 bounded-model/inference, 114 hardware/supplier/installation qualification-only, 4 N/A, 0 desktop work remaining**. GND-02 is closed for desktop design by `analyses/i26/GND02_DESKTOP_CLOSURE.json`; no PCB/BOM/firmware change was required.

This is authorization to proceed to fabrication/supplier review, not a claim that the finished assembly has passed qualification.

---

# I26 pre-hardware closure contract

Date: 2026-09-11

## Objective

Drive Rev B to zero unresolved **pre-hardware actionable engineering work** without converting supplier, as-built, installed-vehicle or environmental observations into fictional desktop evidence. A physical-only acceptance criterion may remain formally unverified, but it is not an open design task once (1) its design antecedents are complete, (2) a quantitative predicted outcome exists where modeling is meaningful, (3) a numerical acceptance/reopen threshold is fixed, and (4) no source change is recommended absent a failed physical gate.

This milestone supersedes the stale I22 thermal/mechanical execution ordering. I25 is the controlling thermal design disposition.

## Disposition classes

- **DESKTOP_CLOSED** — source, CAD, firmware, analytic/simulation or document evidence is sufficient for the design requirement. No further pre-fabrication work is required unless an invalidator changes.
- **BOUNDED_INFERENCE_CLOSED** — inaccessible internal or installed behavior is conservatively bounded well enough that no design change is justified. Hardware correlation remains mandatory but is verification, not engineering debt.
- **QUALIFICATION_ONLY** — the criterion fundamentally concerns a fabricated unit, supplier lot, installed harness/vehicle, phone/OS, RF chamber or environmental observation. Desktop work is exhausted. A predicted outcome and explicit reopen trigger are recorded where useful.
- **CONTINGENCY_ONLY** — analysis belongs to a configuration that is not adopted. It cannot block the release design.

## Current design closure

### CAD and firmware — DESKTOP_CLOSED

The exact candidate has already passed the pinned KiCad 9.0.9 native refill/ERC/DRC/export flow with zero findings and the target Arduino/core/NimBLE build. Any source mutation invalidates this closure and requires the affected native gates again. No additional pre-hardware CAD or firmware correction is indicated by the current evidence.

### Thermal — DESKTOP_CLOSED by I25

The release thermal source is the coupled 2.940859375 W profile, not the historical residual-filled ~4.8 W stress vector. The selected existing-cooling model gives 101.6503 C at 0.50 mm and 107.2667 C at 0.25 mm. Mesh convergence is not claimed; the I25 screening bound is 112.8830 C after carrying the observed 5.6163 C refinement increase once.

Release invariants: ESP32-S3 160 MHz, BLE <=+3 dBm, no Wi-Fi, <=120 notifications/s, sustained main-profile current <=0.45 A, conversion efficiency >=80% or measured losses no worse than the release model, intended bulk dashboard air <=65 C, and immediate air outside U201 <=85 C. Violation of any invariant reopens thermal.

C02 contact/leaf/bridge cooling is **not adopted**. All C110 leaf yield, joint moment, preload and bridge mechanics specific to that cooler are therefore CONTINGENCY_ONLY and are not release blockers. C02 is retained only as a fallback if I25 physical qualification fails.

### Mechanical/package geometry — DESKTOP_CLOSED for the adopted release configuration

The current release design does not include the C02 cooler. Existing declared package/cable geometry has already passed 1,154 populated stack checks, 776 revised Adafruit-851 mated checks and 37 probe approaches. The retained minimum modeled R408/T03 clearance is 0.120 mm. These establish nominal/tolerance-envelope design fit, not as-built workmanship.

Physical checks remain for actual component/cable dimensional conformance, enclosure fit, connector retention and strain relief. A mismatch is a supplier/as-built/install failure unless it exceeds the controlled receiving envelope, in which case mechanical design reopens.

### Adafruit 851/960 accessory path — BOUNDED_INFERENCE_CLOSED electrically; QUALIFICATION_ONLY thermally/mechanically

Exact products are bound: Adafruit 851 U.FL-to-SMA adapter and Adafruit 960 GPS antenna. The routed/mated geometry passes all 776 checks and keeps RF cable/plug metal at least 16.421 mm from the ESP32 antenna region under the model. At the 3.0 V GPS supply boundary, the 2.3 V antenna minimum leaves 0.7 V for the complete internal bias/cable/contact path; at 25 mA this is a 28 ohm total series-resistance acceptance budget.

The 851 published +60 C limit conflicts with the board-level <=65 C bulk design envelope. This cannot be solved by PCB analysis. The installation contract therefore places the 851 cable/adapter in a **<=60 C local harness zone**. If measured local adapter environment exceeds 60 C, relocate/protect the harness or qualify a different accessory; do not respin the PCB unless the replacement changes the board interface.

Receiving/bring-up checks: verify standard-SMA center contact before mating because the linked drawing carries contradictory RP-SMA labeling; verify supplied miniature plug envelope/retention; verify GPS bias remains >=2.3 V at the antenna under representative load and <=28 mA at 3.3 V module limit.

### CAN receive branch — BOUNDED_INFERENCE_CLOSED; vehicle correlation QUALIFICATION_ONLY

The complete branch model executes 14,400 finite cases with separate ASC free exit, twisted AVSS pair, Molex relaxed exit, PCB line, protection load and TCAN receiver. Every case settles to within 1% of the ideal final level by 137.600 ns versus the representative 1.600 us sample; minimum receiver voltage at that sample is 1.495510 V for a 1.5 V source and the worst DC ratio is 0.997006499.

There are 196 repeated 0.9 V crossings, all in the deliberately harsh 2 ns source-edge cases. Their lowest post-crossing valley is 0.736652 V and time below 0.9 V is <=5.2625 ns. There are zero repeated 0.5 V crossings. These are not modeled RXD errors because the receiver nonlinear threshold/hysteresis/propagation path is not represented. The result does not justify a PCB change before hardware evidence.

Predicted physical outcome: no receive errors attributable to this stub under the controlled <=0.30 m harness allocation and normal 500 kbit/s operation. Reopen CAN design only if an actual installation produces repeatable error-count/frame corruption correlated with this branch, violates the controlled exit/length geometry, or a future release enables transmission. R301 remains DNP and firmware transmit-disabled for the present release.

### Power/reset/analog models — BOUNDED_INFERENCE_CLOSED pending correlation

Finite regulator, rail, startup, transient and oil-signal models remain source-bound engineering estimates. Unpublished regulator internals, exact installed source impedance/reference behavior and private die protection are not inferable exactly. Desktop closure therefore rests on retaining conservative modeled envelopes rather than asserting those internals.

Hardware correlation shall measure input/current/rails during startup and representative worst workload, verify no reset or rail collapse outside the accepted crank-gap behavior, and compare oil transfer endpoints against the known 0.5-4.5 V/5 V ratiometric sensor model. A measured result outside the existing model envelope reopens only the affected power/analog design lane.

### RF/EMC/ESD — BOUNDED_INFERENCE_CLOSED for geometry; chamber/install QUALIFICATION_ONLY

Current antenna/launch/return/keepout geometry and bounded coupling analyses are sufficient for pre-hardware release. They do not establish radiated performance, nonlinear ESD clamp behavior or installed coexistence. Predicted outcome is functional GPS/BLE with no material ADC/CAN interference when the controlled cable routes and antenna clearances are honored.

Reopen RF design for repeatable installed C/N0 loss, BLE link failure, ADC/CAN coupling, or ESD upset that exceeds the controlled acceptance plan. Do not create a PCB rework solely because chamber evidence does not yet exist.

### Supplier fabrication/process — QUALIFICATION_ONLY

The controlled JLC construction, filled/capped via set, stackup and local F101 process are source-defined. Supplier acceptance of the exact lot/process cannot be simulated into existence. The fabrication package must preserve the current manufacturing notes and receive supplier confirmation; any proposed fab deviation that changes copper, dielectric, via fill/cap, mask or assembly process reopens the affected native/thermal/SI evidence before approval.

### As-built and installed integration — QUALIFICATION_ONLY

Continuity/isolation, population identity, solder/crimp/contact quality, enclosure fit, actual ASC switched power/return topology, actual vehicle traffic, GPS sky performance, phone/OS behavior, sustained operation and environmental exposure are physical observations. Desktop evidence predicts behavior but cannot replace them.

These checks are acceptance gates, not unresolved product design tasks. A failed gate reopens the narrow affected lane; a pass completes the corresponding original criterion without a respin.

## Pre-hardware stop condition

The board is pre-hardware-closed when all remaining register rows map to one of the four classes above and **no row contains a recommended source/CAD/firmware/mechanical change before fabrication**. The formal 290-row review register may still show OPEN for rows whose wording explicitly requires supplier, as-built, installed, chamber, vehicle or environmental evidence; those must be labeled QUALIFICATION_ONLY rather than misreported as desktop-closed.

The next register reconciliation shall therefore report two counts independently:

1. original criterion status (Closed / Open / N/A), preserving the wording of the original acceptance criterion; and
2. pre-hardware engineering status (Actionable / Qualification-only / Closed / Contingency-only).

The engineering target is **0 actionable pre-hardware rows**, not a dishonest 290/290 desktop pass.

## Global invalidators

Any CAD/firmware/BOM change, release power-profile violation, fabrication stack/process deviation, CAN transmit enablement, different pressure sensor, different GPS board interface/accessory family, enclosure/airflow change, installation ambient beyond controlled bounds, or failed physical gate requires impact review and reopens only the affected evidence lanes.

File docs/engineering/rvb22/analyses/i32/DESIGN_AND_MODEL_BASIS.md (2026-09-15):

# I32 procurement redline effectivity — 2026-09-15

The completed native procurement redline and affected numerical results are controlled by [procurement_redline/README.md](procurement_redline/README.md). Earlier source hashes, substitutions, power/thermal values and native-output pointers below are historical where superseded. Physical acceptance requirements remain in force; no historical criterion ledger is re-adjudicated by this update. The original text is preserved in `analyses/i32/procurement_redline/history/pre_redline/analyses/i32/DESIGN_AND_MODEL_BASIS.md`.

---

# I32 design decisions and evidence limits

This supplement controls the I32 power changes. Current numerical results and source identity are in `FINAL_EVIDENCE.json`; a historical run is not promoted to the selected source by sharing a filename. The complete older I31 archive has SHA256 `92788424fa8389690963c58553d177a2e55a9ba1fec3674175d1477569b8f1ca` and 61 cases. The newer repository core reports 132 cases, but its named full archive (`740fe6b6ba41065643569e2d20c0a6af0fe544fb3a8e421d8490c89d245df21e`) remains unavailable. These are separate datasets.

## Adopted circuit

U152, **TPS22953QDQCRQ1**, isolates U151's input reservoir. It has reverse blocking when disabled, including loss of bias power, and **no quick output discharge**. One C162, **T598X477M010ATE025**, supplies 470 uF nominal at the isolated input. C159, **CGA4J1C0G2A333J125AE**, is a 33 nF, 100 V, 5% C0G timing capacitor. R160/R161 are 6.34 kohm/1 kohm and sense **3V3_VIN, the isolated U151 input**; R162/R163 are 4.7 kohm/1 kohm and sense the upstream 5 V rail for U152 enable. These four resistors use TNPU0603 0.02%, 2 ppm/K parts.

U152 PG, R159 47 kohm and C165 220 nF control the existing enable sequence and Q153. R166/R167, each 330 kohm, divide that PG signal for the actual U151 EN pin. The PG signal and U151 EN are distinct nets. Q153 pulls Q152's gate low while powered. When it releases, R164 pulls Q152's gate toward the isolated input; Q152 discharges the U151 **source node**, through R165, before the input can fall far below it. Q152/Q153 are **DMG2302UKQ-7**. R165 is specifically **CRCW25124R70FKEGHP**, 4.7 ohm/1.5 W, not the standard 1 W resistor. R154's 1 kohm bleed remains. An ordinary output-to-input Schottky was rejected because a typical forward drop does not bound the cold/high-current drop below 0.3 V.

U153, another **TPS22953QDQCRQ1**, charges only the C206 reservoir. The main 3.3 V rail remains directly supplied through R153. C206 is **T598X687M006ATE025**, 680 uF/6.3 V, with **WSL2512R3000FEA**, 0.30 ohm, R158 in its branch. C166 is **CGA5L1C0G2A683J160AE**,68 nF/100 V/5% C0G with soft termination. Its slower charge rate resolves the4.75 V/cold750 mA upstream current-limit collapse found in final source review. C167, **GCM188R71C105KA64D**, provides 1 uF/16 V input decoupling. R169/R170, **TNPU06033K01HWEA00 / TNPU06031K00HWEA00**, enable U153 only after its input/bias is valid. SNS senses its undivided input; PG is explicitly unconnected. R168, 1 kohm, drains the isolated reservoir after shutdown. Enabled switches conduct in both directions; the model does not turn them into ideal diodes.

U202 remains **TPS3808G33QDBVRQ1**. New R204, **CRCW0603100KFKEA**, ties CT to VDD through 100 kohm, within TI's 40-200 kohm requirement. The published 180-420 ms reset delay prevents boot from starting while C206 is still charging. C203 remains DNP. U151 feedback becomes **TNPU060311K8HWEA00 / TNPU06035K05HWEA00**, 11.8 kohm/5.05 kohm: nominal source target 3.336633663 V. Feedback remains at the regulator source node, before R153; no remote-sense claim is made. The 400 kHz FPWM selection and derivative controller coefficients are unchanged.

Input protection changes are coordinated: D101 is **S5JHE3_A/H**, 600 V; R101 is **CRCW251212K1FKEG**, 12.1 kohm/1 W; D105 is **SMCJ110AHE3_A/H**, directly across REV_BLOCKED_12V and GND. Q101 STD25NF20 and the existing controller/gate/clamp/filter topology remain. The raw clamp arrests the harness-inductance excursion before it reaches Q101's 200 V limit. The 110 V standoff keeps the defined 100 V load-dump fixture below its cold breakdown envelope.

## Requirements and component bounds

| Item | Bound used and its evidence class |
|---|---|
| Main rail | 3.0-3.6 V device operating range; no normal load-event crossing of U202 maximum falling threshold 3.116050 V. Source and main are separate nodes. |
| Supervisor | Full-temperature falling threshold 3.023950-3.116050 V; maximum hysteresis conservatively 2.5% of the maximum threshold, giving 3.19395125 V release threshold. CT-to-VDD delay 180/300/420 ms is published. |
| Pre-reset | 20 mA aggregate load allocation, **in addition to explicitly modeled reservoir leakage, bleeds and sequencing loads**. TCAN3403 recessive VCC current is 8.2 mA maximum, VIO 48 uA maximum. ESP32 EN-low current is a typical value, not a guaranteed hot maximum. |
| Boot/run | 0.45 A main allocation; actual firmware remains 160 MHz, BLE +3 dBm, Wi-Fi off, at most 120 notifications/s. Published ESP32 25 C typical radio/CPU figures motivate this allowance but do not certify it at temperature. |
| Electrical capacity | 0.75 A cold-start stress is retained from power-on, independently of reset; 0.45-to-0.75 A applications and releases are tested. It is brief capacity, not the sustained heat profile. ESP32's published supply design minimum is 500 mA capacity, not typical consumption. |
| T598 capacitance | Minimum 0.448 times nominal = 0.8 initial tolerance x 0.8 negative qualification envelope x 0.7 temperature. Maximum 2.106 = 1.2 initial x 1.35 humidity envelope x 1.3 temperature. Separate qualification drifts are treated as an envelope, not all multiplied together. C206 spans 304.64-1432.08 uF. |
| T598 ESR/leakage | 1 milliohm minimum sensitivity, 100 milliohm maximum guard (25 milliohm x2 life x2 temperature allowance). C162 leakage 9.4 mA; C206 leakage 8.568 mA, from 0.01CV x10 hot x2 life. T598 125 C steady recommendation is 60% rated voltage: 6.0 V input, 3.78 V output. |
| MLCC | 0.5 minimum effective capacitance allocation; maximum 1.265 = 1.1 tolerance x1.15 temperature. These are declared guards, not a retrieved bias curve for every part. |
| Precision resistors | +/-0.14% each: 0.02% initial +0.02% for 100 K at 2 ppm/K +0.1% 8000 h endurance envelope. This is not an unlimited-life guarantee. All selected TNPU0603 2 ppm values are within the published 500 ohm-20 kohm range. The earlier 30.1 kohm/10 kohm hypothesis was replaced with 3.01 kohm/1 kohm. |
| Ordinary resistors | Relevant 1% dividers/discharge/damping use +/-6% combined sensitivities. Exact published pulse curves are applied separately. |
| Load-switch timing | C15933 nF gives0.00876628–0.01461858 s/V; C16668 nF gives0.01804688–0.03009768 s/V. Both include0.947–1.053 capacitance factors (5% initial plus0.3% temperature) and +/-20% IC timing allocation. TI's approximate formula is extended beyond its tabulated 10 nF example; this is **not a guaranteed silicon min/max**. 250 us input-fault response allowance is conservative relative to the published typical blanking/deglitch/off times and remains a physical correlation gate. |
| Inductors | L151 XGL5030-153MEC: 15 uH +/-20%, 77.1 milliohm maximum DCR. L121 MSS1246T-473MLC: 47 uH +/-20%, 134 milliohm published maximum DCR; model retains the more conservative 187 milliohm baseline. DCR x1.49125 for 150 C copper. Additional L=0.64 nominal sensitivity includes a further 20% saturation guard. |
| Current limiting | U151 lower average-limit sensitivity 1.5 A; upper 2.4 A, bounding 2.12 A published low-side limit plus half-ripple. At 5.118 V, 9.6 uH and 360 kHz, the maximum half-ripple is below 0.186 A. U121 loaded-start minimum uses its 0.95 A valley minimum as an intentionally conservative **average** limit. Upper switching current/rating checks retain the separate 1.75 A high-side maximum. |
| Parasitics | Main loop 0.075 ohm/300 nH; isolated-input reservoir feed 0.06 ohm/300 nH; final C206 branch 0.11 ohm/200 nH excluding R158 and switch Ron; actual EN node 20 pF. Measured path construction and margins are recorded in `LAYOUT_ASSESSMENT.md`. No 3-D field extraction is claimed. |

Coilcraft's 25 C XGL5030-153 data give 10/20/30% inductance-drop currents 1.7/2.7/3.6 A and 3.4/4.5 A for 20/40 C rise. MSS1246T-473 gives 2.70/3.08/3.34 A and 1.50/2.10 A. These are characterization points, not guaranteed hot saturation or board-specific temperature rise. Actual observed startup currents and the 0.64-L sensitivity are retained with the winding temperature/inductance correlation gate.

## Alternatives and model provenance

The original 470 uF/82 milliohm network's flags motivated this work. A 330 uF/0.47 ohm intermediate improved startup but still produced an extra reset at a combined low-reference/aged-cap/slow-loop load corner. CFF 470 pF/1 nF/1.5 nF and extra main ceramics were tested; they did not supply adequate reset margin. Higher damping alone worsened the dip. A six-input-cap, 680 uF output alternative passed central cases but failed the complete positive storage stack. It is rejected, not fitted. Controlled C206 charging separates upstream startup energy from load-release storage. The 180-420 ms reset delay removes the observed boot-before-reservoir-charge mechanism. Failed runs remain in the rejected evidence index.

The downstream model is the disclosed I31 current-mode derivative (KP14.4, FZ1000 Hz, FP80000 Hz, TI3 us); the slow sensitivity halves gains/frequencies and doubles current-response time. No gains were tuned to obtain passes, no 3.6 V artificial clamp was added, and all extrema use full finite records. READY-masked minima are **not** sufficient: unmasked post-READY and explicitly timed load-window minima are retained. Intentional source-off/UV/OV resets are distinguished from normal load resets.

The unmodified TI LM5164-Q1 library SHA256 is `e11ddf6995163f98eda6205de6a7cb74c8a3982b7328467de8d806286e894b5d`. The isolated 5.5 ms baseline completed. The historical 170-part closed cascade aborted on ngspice42 at 21.3077395343 ms (14,521,189 finite samples) and ngspice47 at 21.2545563362 ms (14,463,289 finite samples), before the requested 24 ms. Alternative solver conditioning failed earlier. The records, exact decks and logs are retained; neither is a selected177-part vendor startup pass. The LM63615 encrypted model was not decoded. Agreement between timesteps only checks numerical resolution of the derivative, not its unknown controller equations.

## Manufacturer sources

- [TI LM63615-Q1](https://www.ti.com/lit/ds/symlink/lm63615-q1.pdf), electrical characteristics, sections7.3/8.2/10: reference/current limits, 400 kHz selection, soft-start, feedback and layout/reverse-discharge guidance.
- [TI LM5164-Q1](https://www.ti.com/lit/ds/symlink/lm5164-q1.pdf), electrical characteristics and applications: independent peak/valley limits and reference layout.
- [TI TPS22953-Q1](https://www.ti.com/lit/ds/symlink/tps22953-q1.pdf), SLVSGK4A, June2022, sections7.3-7.10/9.3: bias, timing, reverse blocking including power loss, temperature and package metrics. The PDF text extraction mislabels reverse-leakage units; consult the rendered table.
- [TI TPS3808-Q1](https://www.ti.com/lit/ds/symlink/tps3808-q1.pdf), RevJ, June2017: threshold/hysteresis and CT-to-VDD timing.
- [TDK CGA4J1C0G2A333J125AE](https://product.tdk.com/en/search/capacitor/ceramic/mlcc/info?part_no=CGA4J1C0G2A333J125AE): AEC-Q200 soft termination, maximum2.45 x1.50 x1.50 mm and recommended reflow pads. Custom land uses PA1.10, PB0.90, PC1.20 mm.
- [Vishay TNPU](https://www.vishay.com/docs/28779/tnpu-e3.pdf), March4,2025: range/order codes, temperature and 8000 h drift.
- [KEMET T598](https://content.kemet.com/datasheets/KEM_T2073_T59X.pdf): rated-temperature voltage, capacitance, leakage, ESR and qualification envelopes.
- [Coilcraft XGL5030](https://www.coilcraft.com/getmedia/e64ac115-95f2-45c7-b798-1b3769b91583/xgl5030.pdf), February19,2026, pp1-2; [MSS1246T](https://www.coilcraft.com/getmedia/dec41de3-f4b7-4c07-b144-cc21921ccfd5/mss1246t.pdf), January28,2022, p2.
- [Espressif ESP32-S3-WROOM-1/1U](https://www.espressif.com/sites/default/files/documentation/esp32-s3-wroom-1_wroom-1u_datasheet_en.pdf), v1.8: N8R2 immediate-ambient limit85 C, supply design and typical consumption.
- [TI TCAN3403-Q1](https://www.ti.com/lit/gpn/TCAN3403-Q1), SLLSFQ6A, June2024, pp5-6: recessive supply currents. Receive-only source configuration is independently preserved.

## Final upstream-voltage correction and energy balance

U121's fitted R122309 kohm/R123100 kohm and nominal1.2 V reference give **4.908 V**. The LM5164-Q1 reference is1.181–1.218 V; the fitted0.1%/25ppm divider and ripple also contribute. Retain the existing **4.75–5.25 V interface envelope**. Earlier model5.0 V nominal/4.91–5.09 V corners were insufficient and are superseded. Neither the0.45 A sustained profile nor the0.75 A electrical/startup stress is reduced.

At4.75 V, the old C16633 nF minimum timing corner charged maximum1.43208 mF C206 at about163.36 mA before leakage/bleed. With750 mA main load, the5 V converter stayed in current limit and its rail fell; isolated VIN crossed the worst SNS falling threshold around3.675 V. Increasing input precharge delay alone merely moved the same failure later. Two input capacitors plus doubled input CT did not remove the sustained charge demand. Their failed and retrying records are retained.

The selected68 nF fastest allocated ramp limits the capacitive term to **79.35 mA**. Add8.568 mA maximum polymer leakage and about3.7 mA bleed; the extra branch demand is about91.6 mA. Using roughly0.845 A total U151 output current,3.395 V source,0.115 ohm hot winding resistance,80% conversion efficiency,4.707 V isolated input and0.396 W other5 V demand gives approximately0.88 A upstream including isolated-capacitor leakage and small control allocations. The old faster case gives roughly0.96 A by the same screen. Compare these with the declared0.95 A upstream average-current guard; the full derivative includes its finite response and actual passive network. These calculations explain the mitigation, without replacing the transient result.

Maximum C206 stores about8.25 mJ at3.395 V. The minimum210.56 uF input capacitor releases only about0.91 mJ between4.707 V and3.675 V, so extra storage alone cannot sustain the old charging-current deficit. Slower charging preserves bulk energy and spreads its demand over approximately61–104 ms. The180 ms minimum reset delay permits charging before normal boot; the slowest-charge/earliest-boot case checks the full sequence.

C166's selected body maximum is3.60 x1.90 x1.90 mm; its custom native footprint uses manufacturer-recommended reflow dimensions PA2.20/PB1.10/PC1.50 mm and a matching maximum-envelope STEP. Its final back-side center is85.85,-3.00 mm at90 degrees. Native copper-to-edge clearance is0.30 mm. The maximum body reaches0.10 mm from the nominal flange edge; supplier placement/board-edge tolerances and first-article fit must be checked together. The inherited mechanical envelope includes0.30 mm XY placement allowance and the complete1.71 mm vertical stack. [TDK exact selected part](https://product.tdk.com/en/search/capacitor/ceramic/mlcc/info?part_no=CGA5L1C0G2A683J160AE).

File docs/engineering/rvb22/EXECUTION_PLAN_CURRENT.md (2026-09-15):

# Current I32 procurement redline — 2026-09-15

The native frozen-parts redline is completed and desktop-verified. Current source, BOM/CPL, manufacturing files and affected verification are controlled by [the redline report](analyses/i32/procurement_redline/README.md), [final verification](analyses/i32/procurement_redline/FINAL_REDLINE_VERIFICATION.json), and [source effectivity](current/SOURCE_EFFECTIVITY.json). Supplier and physical gates remain open. Earlier source hashes, active parts, numerical results and package pointers below are historical where superseded; the original document is preserved under `analyses/i32/procurement_redline/history/pre_redline/`.

---

# I26 current execution plan — pre-hardware closure

Date: 2026-09-11

This plan supersedes the stale I22 current plan. The controlling objective is **zero unresolved actionable engineering work before real hardware/supplier/installed validation**, while retaining explicit physical-only acceptance gates instead of fabricating evidence.

## Controlling state

- Branch: `codex/rvb24-coordinated-closure`.
- I25 thermal milestone is controlling for release thermal design.
- I26 closure contract: `I26_PREHARDWARE_CLOSURE.md` and `.json`.
- Exact native CAD/firmware evidence remains source-bound; any source mutation reruns affected gates.
- C02 cooling hardware is not adopted. C02-specific leaf/joint/preload engineering is contingency-only and cannot block release.

## Closure order

1. **Reconcile the 290 original rows into a parallel pre-hardware status.** Preserve original Closed/Open/N/A semantics. Add/derive `Closed`, `Bounded inference`, `Qualification-only`, `Contingency-only`, or `Actionable` for engineering disposition. Target: `Actionable = 0`.
2. **Return path / SI.** Use existing native copper plus the completed CAN branch family and alternate-reference evidence. Do not reroute solely to remove abstract flags when both ground planes provide continuous reference and the release TX stub is isolated by R301 DNP. A real source change is justified only by a demonstrated unresolved fitted-path violation.
3. **Release mechanics.** Evaluate only adopted hardware. Retire C02 cooler structural questions to contingency status. Preserve enclosure, connector, cable, probe and receiving envelopes as qualification gates.
4. **Accessory path.** Exact Adafruit 851/960 identity is bound. Keep the electrical/RF route desktop-closed. Treat the 851 +60 C rating as a local harness-zone acceptance requirement (`<=60 C`); it does not justify a PCB respin.
5. **Power/reset/analog.** Exhaust source-bound interval/ODE/MNA evidence. Where private regulator/die or vehicle-reference behavior is unknowable, freeze a conservative model envelope and a measured reopen threshold rather than leaving an unbounded TODO.
6. **RF/EMC/ESD.** Close geometry/coupling/keepout work on desktop. Chamber, radiated, nonlinear clamp and installed coexistence become qualification-only with explicit failure/reopen criteria.
7. **Supplier/as-built/integration.** Supplier process confirmation, physical continuity/population/crimp, installed ASC topology/traffic, GPS sky performance, phone/OS behavior and environment are qualification-only. No desktop simulation is represented as physical evidence.
8. **Final artifact reconciliation.** Ensure register, gate summary, PR text, CAD, firmware, manufacturing package and acceptance plan all refer to the same release configuration and invalidate together on source changes.

## Current bounded predictions

### Thermal
Selected existing-cooling release profile: 2.940859375 W. Board-region maximum is 101.6503 C at 0.50 mm and 107.2667 C at 0.25 mm; I25 screening bound 112.8830 C. Release invariants are 160 MHz, BLE <=+3 dBm, no Wi-Fi, <=120 notifications/s, sustained main-profile <=0.45 A, converter efficiency >=80%, bulk dashboard air <=65 C and immediate U201 air <=85 C.

### CAN receive branch
14,400 cases. All reach within 1% by 137.600 ns versus representative 1.600 us sampling. Minimum receiver voltage at that sample is 1.495510 V for a 1.5 V source; DC ratio >=0.997006499. The 196 0.9 V recrossings all occur in 2 ns edge cases, with <=5.2625 ns below 0.9 V; zero repeated 0.5 V crossings. Predicted release outcome is no branch-attributable receive error under controlled harness geometry. Vehicle correlation remains mandatory.

### GPS accessory path
Adafruit 851/960 pairing and route are controlled. Mated route passes 776 modeled checks and retains >=16.421 mm metal-to-ESP32 antenna-region spacing. GPS bias has a 28 ohm complete-path series-resistance budget at 25 mA from the 3.0 V / 2.3 V endpoints. The 851 local environment must remain <=60 C.

## Stop condition

Stop pre-hardware engineering only when every original criterion maps to a non-actionable I26 class and **no remaining row recommends a CAD, schematic, PCB, firmware, mechanical or release-profile change before fabrication**. Physical/supplier/installed rows may remain formally Open if their wording requires observation, but they must have a fixed acceptance test, predicted outcome where meaningful, and a narrow reopen rule.

A future hardware failure reopens the affected lane; it does not retroactively turn every qualification-only row into unfinished design work.

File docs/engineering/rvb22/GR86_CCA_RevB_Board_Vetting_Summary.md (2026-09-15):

# Current I32 procurement redline — 2026-09-15

The native frozen-parts redline is completed and desktop-verified. Current source, BOM/CPL, manufacturing files and affected verification are controlled by [the redline report](analyses/i32/procurement_redline/README.md), [final verification](analyses/i32/procurement_redline/FINAL_REDLINE_VERIFICATION.json), and [source effectivity](current/SOURCE_EFFECTIVITY.json). Supplier and physical gates remain open. Earlier source hashes, active parts, numerical results and package pointers below are historical where superseded; the original document is preserved under `analyses/i32/procurement_redline/history/pre_redline/`.

---

# Current checkpoint: convergence 01

See `analyses/convergence_01/README.md` relative to the rvb22 root and `current/CONVERGENCE_01_EFFECTIVITY.json`. The former 6.5/7 mm exposed-shoe whole-path selection is withdrawn. New native-copper trial refinement gives 111.533 C board maximum at 0.25 mm; no thermal/mechanical acceptance or new PCB fabrication release is claimed. Earlier numerical statements below retain their historical configuration and scope.

## Historical review

# I22 engineering review

Open original criteria decrease from **152 to 146**. The register now has **140 closed / 146 open / 4 not applicable**, preserving all 290 original questions, required-evidence cells and user inputs. The original user baseline remains 73/213/4. All 351 prior redlines plus six I22 findings are retained.

| Criterion closed | Evidence completing its original scope |
|---|---|
| LIB-02 | Exact manufacturer drawing-to-footprint overlays for all 12 IC/module references, independently transformed from native placement. All 151 signal lands and 12 negative controls pass. |
| LIB-08 | Exact exposed-pad net, copper, thermal-return and mask/paste review for U121/U151/U201/U301/U501, including the isolated TPS2660 RTN connection. |
| VIA-06 | Fabrication-tolerance via-current budget covers all 322 vias: 2 A per individual via, 15 µm minimum wall, 1.76 mm thickness and −0.08 mm finished-hole allowance; maximum 5.103 K self-rise against 10 K. |
| SI-12 | The original criterion permits justified analysis-only acceptance. Native RF ground-reference continuity and the retained 3,981,312-case board network support that limited disposition; external-system and supplier conditions remain separate. |
| GPS-01 | PA1616D top-view numbering, all 20 pad functions/nets and manual placement/pin-1 coordinates independently reconciled. |
| MECH-03 | Complete declared height/XY/fastener/foil tolerance stack: 1,154 populated and 776 mated checks, no intersections, 0.120 mm minimum modeled clearance. |

The exact Adafruit 851 adapter and 960 puck are now controlled inputs. The mated model no longer names the unadopted Amphenol candidate. Cable length is 150 ±3 mm to the SMA shoulder; maximum allocated OD is 2.0 mm, with separate 0.5 mm route uncertainty. The cable and plug metal remain 16.421 mm from the ESP32 antenna region. The height model now includes the previously omitted 0.51 mm capture freedom, bringing the added height stack to 1.71 mm. These are model and assembly-instruction corrections; no CAD or firmware revision is claimed.

The I20 CAD/target source remains exact: zero ERC, DRC, warnings, unconnected or parity findings in native run 34420381540; 153 fitted models; 151 automatic placements and F101/U401 manual exceptions. The 8 mm Compact TW logo from the supplied brand pack remains on F.SilkS. Existing power and RF finite bounds remain applicable. I21's 1,042 digest checks and full independent copper/export reconstruction are retained, with fresh I22 source/evidence identity checks recorded separately.

Remaining engineering work is material. The 0.125 mm thermal estimate is still 143.800°C maximum board region, with an 8.376 K last-refinement change. Adafruit 851's published 60°C ceiling does not cover the declared 65°C air case; passive cooling cannot remove that boundary conflict. Its J401 board region is estimated at 92.438–94.443°C, without asserting cable/connector temperature. All 54 digital adjacent-plane gaps remain explicit under GND-02. DFM-02 still requires exact hole/pin/hardware fit and drawing/DFM agreement; GPS-09/14 retain bias, plug and retention conditions; WCA-07 retains guaranteed optical performance; DRW-03 retains independent human review. Supplier and actual-unit/installation qualification are not replaced by calculation.

Primary package PDFs, source hashes, all twelve SVG/PNG overlays, revised mated STEP/route output, calculations, failure history and the current register are included in the recovery archive. The mated STEP contains connector/service envelope solids; the complete coax path and its tolerance envelope are documented in the route PNG/JSON. The plan and selected evidence are forwarded through PR #45. This remains a draft engineering candidate with thermal work and qualification open.

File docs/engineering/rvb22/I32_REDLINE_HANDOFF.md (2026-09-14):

# GR86 / BRZ Telemetry CCA Rev B — I32 Procurement Redline Execution Handoff

## Mission

Resume `tranquilWorks/gr86-cca-telemetry` on existing PR **#46**, branch:

`codex/rvb24-coordinated-closure`

Apply the **already frozen and electrically qualified procurement substitutions** to the real I32 schematic/PCB source, component metadata/models, footprints, placement/routing as required, BOM, PnP/CPL and manufacturing outputs. Then rerun the complete applicable native/source/manufacturing/electrical verification stack.

Do **not** restart component selection. Do **not** reopen the already-qualified substitutions unless an exact frozen MPN becomes genuinely unavailable or a physical CAD/package conflict proves it unusable.

Do not stop at a plan. Carry the redline through source update, regenerated outputs and verification.

## Mandatory start procedure

1. Fetch the **latest remote tip** of `codex/rvb24-coordinated-closure` and inspect current status before editing.
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

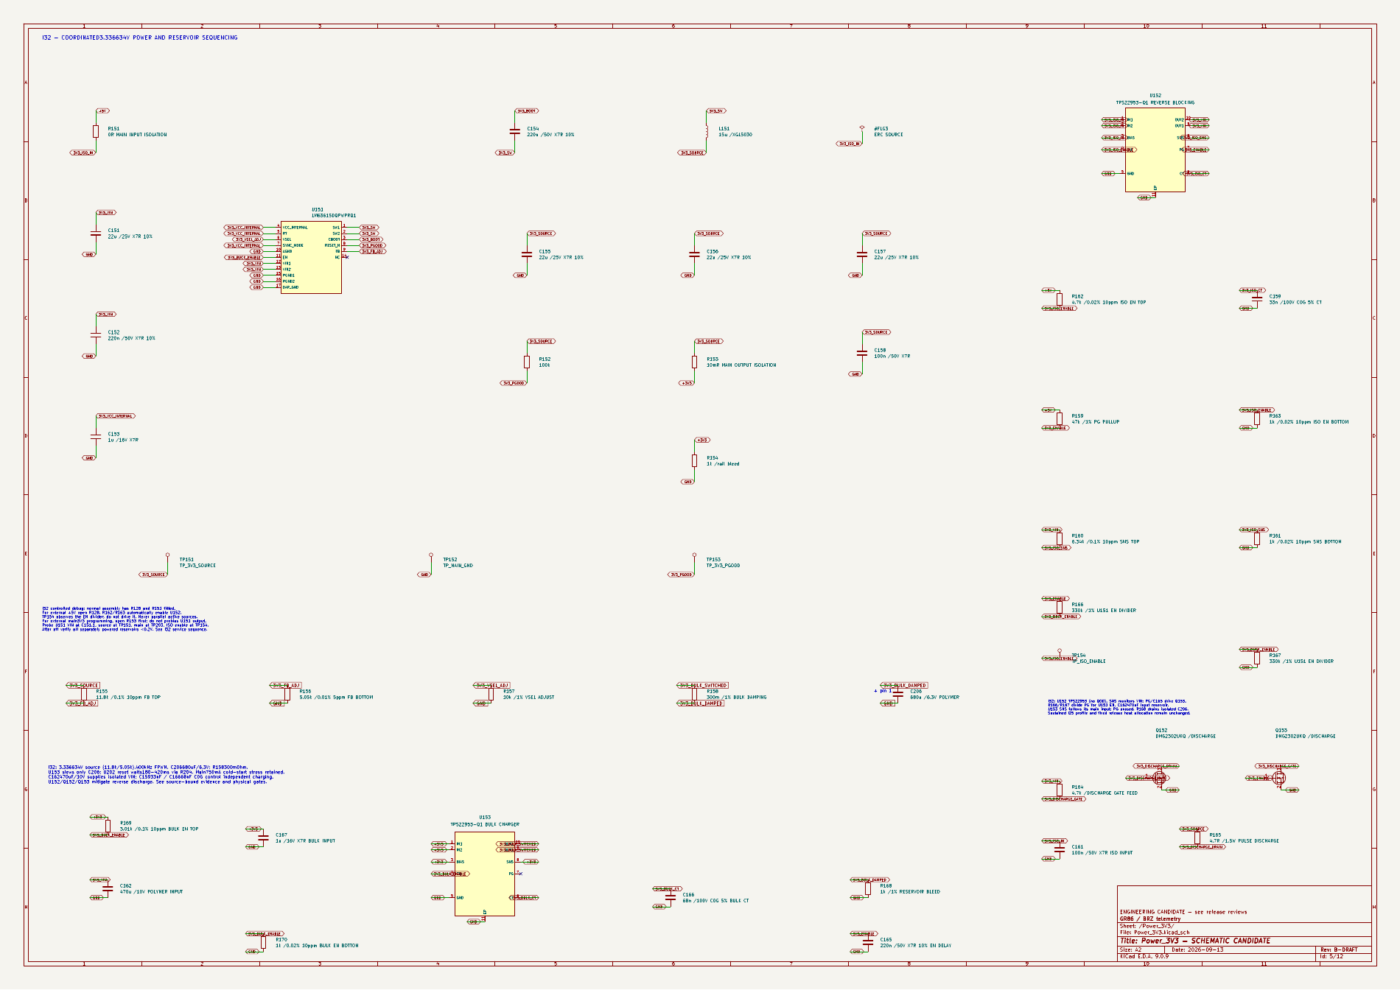
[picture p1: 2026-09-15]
docs/engineering/rvb22/analyses/i32/procurement_redline/review_register/Power_3V3_native.png

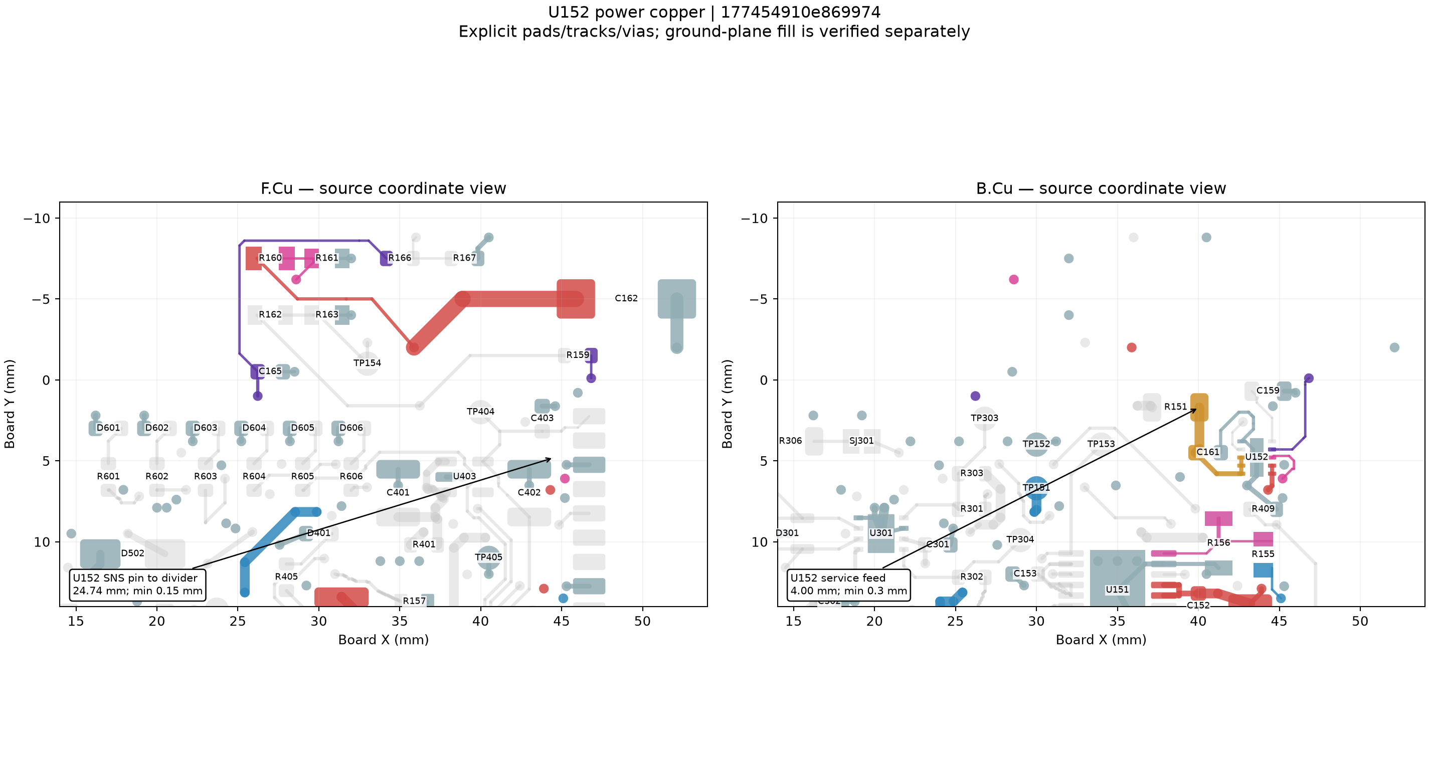
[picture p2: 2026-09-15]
docs/engineering/rvb22/analyses/i32/procurement_redline/layout/U152_power_routes.png

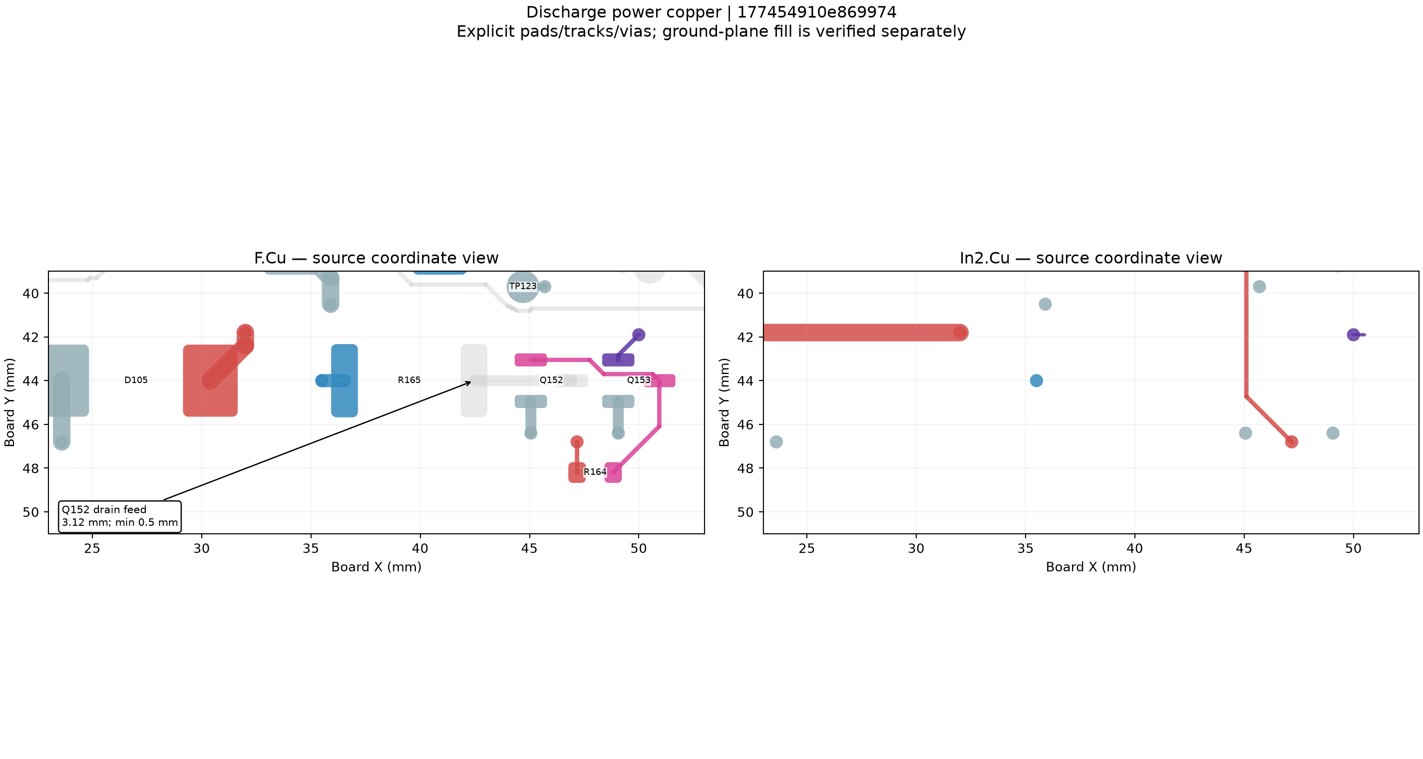
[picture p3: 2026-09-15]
docs/engineering/rvb22/analyses/i32/procurement_redline/layout/Discharge_power_routes.png

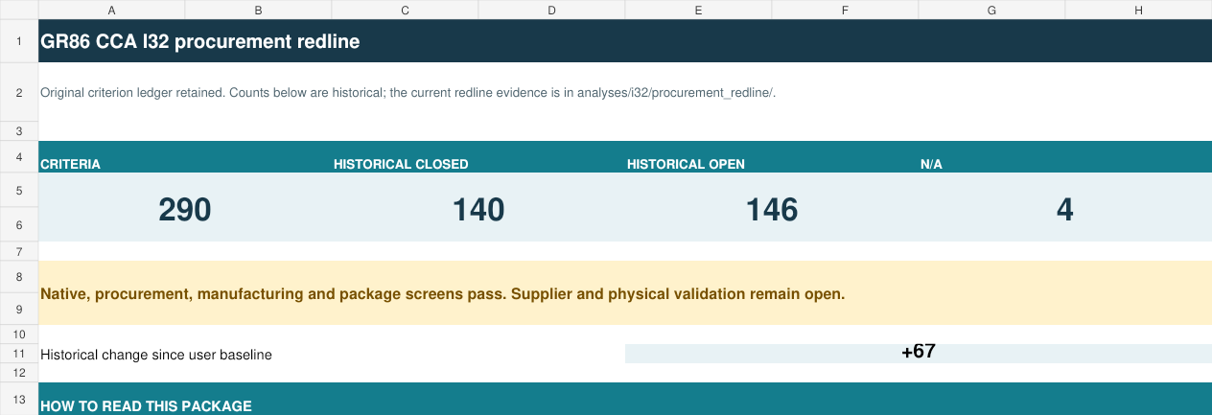
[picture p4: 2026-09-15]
docs/engineering/rvb22/analyses/i32/procurement_redline/review_register/after.png

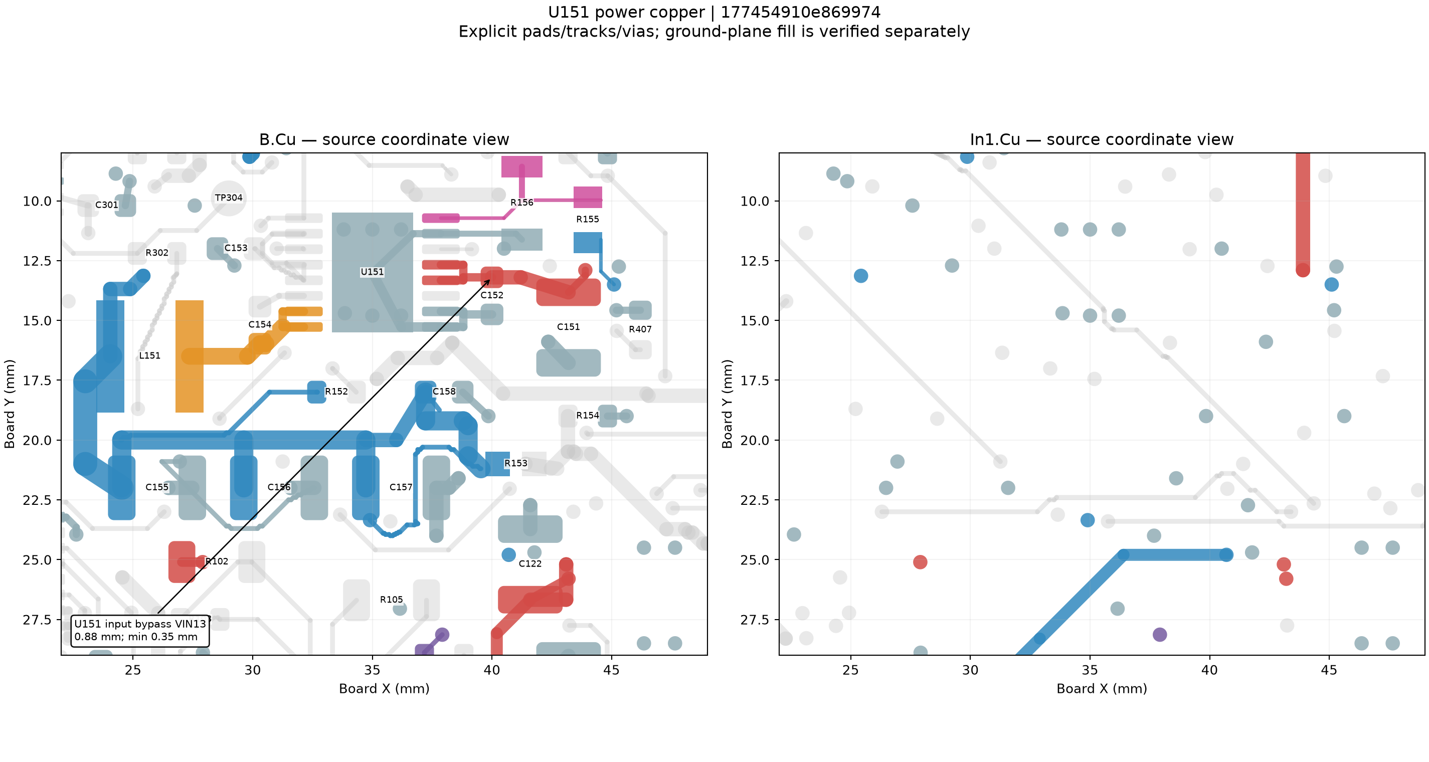
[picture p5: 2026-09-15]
docs/engineering/rvb22/analyses/i32/procurement_redline/layout/U151_power_routes.png

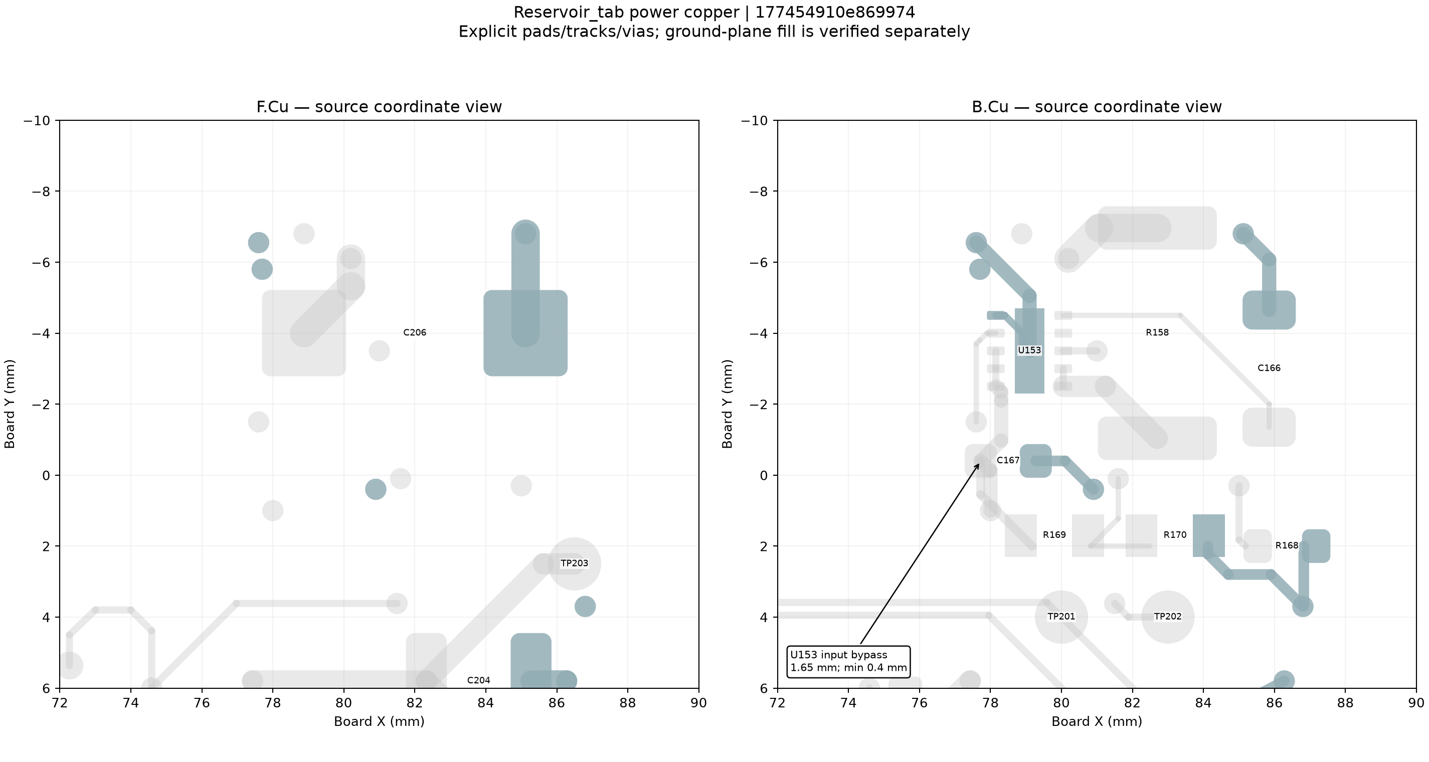
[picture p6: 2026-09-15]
docs/engineering/rvb22/analyses/i32/procurement_redline/layout/Reservoir_tab_power_routes.png

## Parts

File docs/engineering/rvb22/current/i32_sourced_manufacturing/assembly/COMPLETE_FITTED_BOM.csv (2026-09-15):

Reference | Value | Footprint | Manufacturer | MPN | LCSC | Quantity
C101 | 100n /100V X7R | RevB:C_0805_2012Metric | TDK | CGA4J2X7R2A104K125AA | C342919 | 1
C102 | 10n /100V X7R | RevB:C_0603_1608Metric | TDK | CGA3E2X7R2A103K080AE | C3858696 | 1
C103 | 2.2u /100V X7R | RevB:C_1210_3225Metric | TDK | CGA6N3X7R2A225K230AB | C342652 | 1
C121 | 2.2u /100V X7R | RevB:C_1210_3225Metric | TDK | CGA6N3X7R2A225K230AB | C342652 | 1
C122 | 2.2u /100V X7R | RevB:C_1210_3225Metric | TDK | CGA6N3X7R2A225K230AB | C342652 | 1
C123 | 100n /100V X7R | RevB:C_0805_2012Metric | TDK | CGA4J2X7R2A104K125AA | C342919 | 1
C124 | 2.2n /50V C0G 5% | RevB:C_0603_1608Metric | TDK | CGA3E2C0G1H222J080AA | C2169200 | 1
C125 | 3.3n /100V C0G 5% | RevB:C_0603_1608Metric | TDK | CGA3E2C0G2A332J080AA | C2171993 | 1
C126 | 100p /50V C0G | RevB:C_0603_1608Metric | TDK | CGA3E2C0G1H101J080AA | C76709 | 1
C127 | 22u /25V X7R 10% | RevB:C_1210_3225Metric | Taiyo Yuden | MCAST32MSB7226KPNA01 | C5372271 | 1
C128 | 22u /25V X7R 10% | RevB:C_1210_3225Metric | Taiyo Yuden | MCAST32MSB7226KPNA01 | C5372271 | 1
C129 | 2.2u /100V X7R | RevB:C_1210_3225Metric | TDK | CGA6N3X7R2A225K230AB | C342652 | 1
C151 | 22u /25V X7R 10% | RevB:C_1210_3225Metric | Taiyo Yuden | MCAST32MSB7226KPNA01 | C5372271 | 1
C152 | 220n /50V X7R 10% | RevB:I32_PROCUREMENT_C152 | TDK | CGA3E3X7R1H224KT0Y0N | C342967 | 1
C153 | 1u /16V X7R | RevB:C_0603_1608Metric | Murata | GCM188R71C105KA64D | C161212 | 1
C154 | 220n /50V X7R 10% | RevB:I32_PROCUREMENT_C154 | TDK | CGA3E3X7R1H224KT0Y0N | C342967 | 1
C155 | 22u /25V X7R 10% | RevB:C_1210_3225Metric | Taiyo Yuden | MCAST32MSB7226KPNA01 | C5372271 | 1
C156 | 22u /25V X7R 10% | RevB:C_1210_3225Metric | Taiyo Yuden | MCAST32MSB7226KPNA01 | C5372271 | 1
C157 | 22u /25V X7R 10% | RevB:C_1210_3225Metric | Taiyo Yuden | MCAST32MSB7226KPNA01 | C5372271 | 1
C158 | 100n /50V X7R | RevB:C_0603_1608Metric | Murata | GCM188R71H104KA57D | C85864 | 1
C159 | 33n /100V C0G 5% CT | RevB:I32_FINISHED_C159 | TDK | CGA4J1C0G2A333J125AE | C2181132 | 1
C161 | 100n /50V X7R ISO INPUT | RevB:I32_FINISHED_C161 | Murata | GCM188R71H104KA57D | C85864 | 1
C162 | 470u /10V POLYMER INPUT | RevB:I32_FINISHED_C162 | KEMET | T598X477M010ATE025 | C19941093 | 1
C165 | 220n /50V X7R 10% EN DELAY | RevB:I32_PROCUREMENT_C165 | TDK | CGA3E3X7R1H224KT0Y0N | C342967 | 1
C166 | 68n /100V C0G 5% BULK CT | RevB:I32_FINISHED_C166 | TDK | CGA5L1C0G2A683J160AE | C3869625 | 1
C167 | 1u /16V X7R BULK INPUT | RevB:I32_FINISHED_C167 | Murata | GCM188R71C105KA64D | C161212 | 1
C201 | 22u /25V X7R 10% | RevB:C_1210_3225Metric | Taiyo Yuden | MCAST32MSB7226KPNA01 | C5372271 | 1
C202 | 100n /50V X7R | RevB:C_0603_1608Metric | Murata | GCM188R71H104KA57D | C85864 | 1
C204 | 22u /25V X7R 10% | RevB:C_1210_3225Metric | Taiyo Yuden | MCAST32MSB7226KPNA01 | C5372271 | 1
C205 | 100n /50V X7R | RevB:C_0603_1608Metric_RVB22_C205 | Murata | GCM188R71H104KA57D | C85864 | 1
C206 | 680u /6.3V POLYMER | RevB:KEMET_T598_X_7343_Median_RVB22_C206 | KEMET | T598X687M006ATE025 | C4951511 | 1
C301 | 100n /50V X7R | RevB:C_0603_1608Metric | Murata | GCM188R71H104KA57D | C85864 | 1
C302 | 1u /16V X7R | RevB:C_0603_1608Metric | Murata | GCM188R71C105KA64D | C161212 | 1
C401 | 22u /25V X7R 10% | RevB:C_1210_3225Metric | Taiyo Yuden | MCAST32MSB7226KPNA01 | C5372271 | 1
C402 | 22u /25V X7R 10% | RevB:C_1210_3225Metric | Taiyo Yuden | MCAST32MSB7226KPNA01 | C5372271 | 1
C403 | 100n /50V X7R | RevB:C_0603_1608Metric | Murata | GCM188R71H104KA57D | C85864 | 1
C404 | 100n /50V X7R | RevB:C_0603_1608Metric | Murata | GCM188R71H104KA57D | C85864 | 1
C405 | 100n /50V X7R | RevB:C_0603_1608Metric | Murata | GCM188R71H104KA57D | C85864 | 1
C501 | 22n /50V X7R | RevB:C_0603_1608Metric | TDK | CGA3E2X7R1H223K080AE | C2176922 | 1
C502 | 100n /50V X7R | RevB:C_0603_1608Metric | Murata | GCM188R71H104KA57D | C85864 | 1
C503 | 100n /100V X7R | RevB:C_0805_2012Metric | TDK | CGA4J2X7R2A104K125AA | C342919 | 1
C504 | 10u /50V X7R | RevB:KEMET_C1210_10u50V | KEMET | C1210C106K5RACTU | C2167688 | 1
C505 | 10u /50V X7R | RevB:KEMET_C1210_10u50V | KEMET | C1210C106K5RACTU | C2167688 | 1
C506 | 10u /50V X7R | RevB:KEMET_C1210_10u50V | KEMET | C1210C106K5RACTU | C2167688 | 1
C511 | 1u /16V X7R | RevB:C_0603_1608Metric | Murata | GCM188R71C105KA64D | C161212 | 1
C512 | 1u /16V X7R | RevB:C_0603_1608Metric | Murata | GCM188R71C105KA64D | C161212 | 1
C513 | 22n /50V X7R | RevB:C_0603_1608Metric | TDK | CGA3E2X7R1H223K080AE | C2176922 | 1
C514 | 100p /50V C0G5% | RevB:C_0603_1608Metric | TDK | CGA3E2C0G1H101J080AA | C76709 | 1
C521 | 1u /16V X7R | RevB:C_0603_1608Metric | Murata | GCM188R71C105KA64D | C161212 | 1
C522 | 1u /16V X7R | RevB:C_0603_1608Metric | Murata | GCM188R71C105KA64D | C161212 | 1
C523 | 22n /50V X7R | RevB:C_0603_1608Metric | TDK | CGA3E2X7R1H223K080AE | C2176922 | 1
C524 | 100p /50V C0G5% | RevB:C_0603_1608Metric | TDK | CGA3E2C0G1H101J080AA | C76709 | 1
C531 | 100n /50V X7R | RevB:C_0603_1608Metric | Murata | GCM188R71H104KA57D | C85864 | 1
C532 | 10n /50V C0G 5% OUT HF | RevB:C_0603_1608Metric | Murata | GRM1885C1H103JA01D | C85973 | 1
D101 | S5J /600V REVERSE BLOCK | RevB:D_SMC | Vishay | S5JHE3_A/H | C511410 | 1
D102 | SMAJ30A /TVS | RevB:D_SMA | Vishay | SMAJ30AHE3_A/H | C1978408 | 1
D103 | SMCJ24A /TVS | RevB:D_SMC_RVB22_D103 | Vishay | SMCJ24AHE3_A/H | C1981952 | 1
D104 | 15V GATE CLAMP | RevB:D_SOD-123F | Nexperia | BZT52H-B15-QX | C7507926 | 1
D105 | SMCJ110A /RAW OV CLAMP | RevB:D_SMC | Vishay | SMCJ110AHE3_A/H | C1982070 | 1
D301 | ESD2CAN24DBZRQ1 | RevB:SOT-23 | Texas Instruments | ESD2CAN24DBZRQ1 | C5736151 | 1
D401 | SEARCH (blink / no fix) | RevB:LED_0603_1608Metric | Kingbright | APT1608SGC | C5875754 | 1
D402 | TPD1E05U06DPYR | RevB:TI_DPY0002A_TPD1E05U06_SMDMask | Texas Instruments | TPD1E05U06DPYR | C436349 | 1
D501 | ESD2CAN24DBZRQ1 | RevB:SOT-23 | Texas Instruments | ESD2CAN24DBZRQ1 | C5736151 | 1
D502 | SS16 /60V Schottky | RevB:D_SMA | Vishay | SS16HE3_B/H | C266798 | 1
D511 | PMEG2010BEA,115 | RevB:Nexperia_SOD323_PMEG2010BEA | Nexperia | PMEG2010BEA,115 | C455041 | 1
D512 | PMEG2010BEA,115 | RevB:Nexperia_SOD323_PMEG2010BEA | Nexperia | PMEG2010BEA,115 | C455041 | 1
D521 | PMEG2010BEA,115 | RevB:Nexperia_SOD323_PMEG2010BEA | Nexperia | PMEG2010BEA,115 | C455041 | 1
D522 | PMEG2010BEA,115 | RevB:Nexperia_SOD323_PMEG2010BEA | Nexperia | PMEG2010BEA,115 | C455041 | 1
D601 | PWR | RevB:LED_0603_1608Metric | Kingbright | APT1608SGC | C5875754 | 1
D602 | BLE | RevB:LED_0603_1608Metric | Kingbright | APT1608SGC | C5875754 | 1
D603 | CAN | RevB:LED_0603_1608Metric | Kingbright | APT1608SGC | C5875754 | 1
D604 | GPS | RevB:LED_0603_1608Metric | Kingbright | APT1608SGC | C5875754 | 1
D605 | SYS | RevB:LED_0603_1608Metric | Kingbright | APT1608SGC | C5875754 | 1
D606 | OIL | RevB:LED_0603_1608Metric | Kingbright | APT1608SGC | C5875754 | 1
F1 | 0430451200 / TIN NEW HARNESS | RevB:Molex_Micro-Fit_3.0_43045-1200_2x06_P3.00mm_Horizontal_RVB22_F1 | Molex | 0430451200 | C277636 | 1
F101 | 1A /500VDC | RevB:Fuse_Littelfuse-NANO2-885 | Littelfuse | 0885001.DR | C2879865 | 1
J202 | RESET — short to reset | RevB:Wurth_61300211121_1x02 | Wurth Elektronik | 61300211121 | C2915055 | 1
J203 | BOOT — hold low on reset | RevB:Wurth_61300211121_1x02 | Wurth Elektronik | 61300211121 | C2915055 | 1
J401 | U.FL-R-SMT-1(80) | RevB:Hirose_UFL_R_SMT_1_80_RevB | Hirose | U.FL-R-SMT-1(80) | C88374 | 1
L121 | 47u /100mOhm 2.5A BPCI | RevB:I32_PROCUREMENT_L121 | Chilisin / Pulse | BPCI00121280470M00 | C6471075 | 1
L151 | 15u /XGL5030 | RevB:L_Coilcraft_XAL5030-XXX | Coilcraft | XGL5030-153MEC | C3911485 | 1
L406 | 1.6nH 5% RF MATCH | RevB:Murata_LQW18AS_1608 | Murata | LQW18AS1N6J0ZD | C7295894 | 1
Q101 | STD25NF20 /200V | RevB:TO-252-2 | STMicroelectronics | STD25NF20 | C388326 | 1
Q152 | DMG2302UKQ /DISCHARGE | RevB:I32_FINISHED_Q152 | Diodes Incorporated | DMG2302UKQ-7 | C5224573 | 1
Q153 | DMG2302UKQ /DISCHARGE | RevB:I32_FINISHED_Q153 | Diodes Incorporated | DMG2302UKQ-7 | C5224573 | 1
R101 | 12.1k /1W CTRL SURGE FEED | RevB:R_2512_6332Metric | Vishay | CRCW251212K1FKEG | C4263918 | 1
R102 | 549k /0.1% OV COORD | RevB:R_1206_3216Metric | Vishay | TNPW1206549KBEEA | C4328168 | 1
R103 | 24.3k /0.1% UV OV COORD | RevB:R_0603_1608Metric | Vishay | TNPW060324K3BEEA | C4269123 | 1
R104 | 14.7k /0.1% | RevB:R_0603_1608Metric | Panasonic | ERA3AEB1472V | C2074591 | 1
R105 | 510k | RevB:R_1206_3216Metric | Vishay | CRCW1206510KFKEA | C843859 | 1
R106 | 10R /gate | RevB:R_0603_1608Metric | Vishay | CRCW060310R0FKEA | C844919 | 1
R107 | 5.1k /slew branch | RevB:R_0603_1608Metric | Vishay | CRCW06035K10FKEA | C844933 | 1
R108 | 100k | RevB:R_0603_1608Metric | Vishay | CRCW0603100KFKEA | C844916 | 1
R109 | 0R INPUT ISOLATION | RevB:R_1206_3216Metric | Vishay | CRCW12060000Z0EA | C190124 | 1
R110 | 0.47R /0.815W filter | RevB:R_2512_6332Metric | Vishay | WSL2512R4700FEA | C4273015 | 1
R111 | 100k /bleed | RevB:R_1206_3216Metric | Vishay | CRCW1206100KFKEA | C844863 | 1
R121 | 31.6k /RON | RevB:R_0603_1608Metric | Vishay | TNPW060331K6BEEA | C843870 | 1
R122 | 309k /0.1% | RevB:R_0805_2012Metric | Vishay | TNPW0805309KBEEA | C1710754 | 1
R123 | 100k /0.1% | RevB:R_0603_1608Metric | Vishay | TNPW0603100KBEEA | C844888 | 1
R124 | 43.2k /RA | RevB:R_0603_1608Metric | Vishay | TNPW060343K2BEEA | C2089718 | 1
R125 | 100k | RevB:R_1206_3216Metric | Vishay | CRCW1206100KFKEA | C844863 | 1
R126 | 26.1k | RevB:R_0603_1608Metric | Panasonic | ERA3AEB2612V | C491123 | 1
R127 | 100k | RevB:R_0603_1608Metric | Vishay | CRCW0603100KFKEA | C844916 | 1
R128 | 0R 5V ISOLATION | RevB:R_1206_3216Metric | Vishay | CRCW12060000Z0EA | C190124 | 1
R151 | 0R MAIN INPUT ISOLATION | RevB:I32_FINISHED_R151 | Vishay | CRCW12060000Z0EA | C190124 | 1
R152 | 100k | RevB:R_0603_1608Metric | Vishay | CRCW0603100KFKEA | C844916 | 1
R153 | 10mR MAIN OUTPUT ISOLATION | RevB:WSLP0603_MANUFACTURER_R153 | Vishay | WSLP0603R0100FEA | C5334451 | 1
R154 | 1k /rail bleed | RevB:R_0603_1608Metric | Vishay | CRCW06031K00FKEA | C844920 | 1
R155 | 11.8k /0.1% 10ppm FB TOP | RevB:I32_PROCUREMENT_R155 | Resistor.Today | PTFR0603B11K8N9 | C19679768 | 1
R156 | 5.05k /0.01% 5ppm FB BOTTOM | RevB:I32_PROCUREMENT_R156 | Vishay | PLT1206Z5051LBTS | C4074185 | 1
R157 | 10k /1% VSEL ADJUST | RevB:R_0603_1608Metric_RVB22_R157 | Vishay | CRCW060310K0FKEA | C844918 | 1
R158 | 300m /1% BULK DAMPING | RevB:I32_FINISHED_R158 | Vishay | WSL2512R3000FEA | C2076134 | 1
R159 | 47k /1% PG PULLUP | RevB:I32_FINISHED_R159 | Vishay | CRCW060347K0FKEA | C844929 | 1
R160 | 6.34k /0.1% 10ppm SNS TOP | RevB:I32_PROCUREMENT_R160 | YAGEO | RT0805BRB076K34L | C864499 | 1
R161 | 1k /0.02% 10ppm SNS BOTTOM | RevB:I32_PROCUREMENT_R161 | Resistor.Today | PTFR0603Q1K00N9 | C23067434 | 1
R162 | 4.7k /0.02% 10ppm ISO EN TOP | RevB:I32_PROCUREMENT_R162 | Resistor.Today | PTFR0603Q4K70N9 | C23067437 | 1
R163 | 1k /0.02% 10ppm ISO EN BOTTOM | RevB:I32_PROCUREMENT_R163 | Resistor.Today | PTFR0603Q1K00N9 | C23067434 | 1
R164 | 4.7k /DISCHARGE GATE FEED | RevB:I32_FINISHED_R164 | Vishay | CRCW06034K70FKEA | C844931 | 1
R165 | 4.7R /1.5W PULSE DISCHARGE | RevB:I32_FINISHED_R165 | Vishay | CRCW25124R70FKEGHP | C2075852 | 1
R166 | 330k /1% U151 EN DIVIDER | RevB:I32_FINISHED_R166 | Vishay | CRCW0603330KFKEA | C844776 | 1
R167 | 330k /1% U151 EN DIVIDER | RevB:I32_FINISHED_R167 | Vishay | CRCW0603330KFKEA | C844776 | 1
R168 | 1k /1% RESERVOIR BLEED | RevB:I32_FINISHED_R168 | Vishay | CRCW06031K00FKEA | C844920 | 1
R169 | 3.01k /0.1% 10ppm BULK EN TOP | RevB:I32_PROCUREMENT_R169 | Resistor.Today | PTFR0603B3K01N9 | C2692830 | 1
R170 | 1k /0.02% 10ppm BULK EN BOTTOM | RevB:I32_PROCUREMENT_R170 | Resistor.Today | PTFR0603Q1K00N9 | C23067434 | 1
R201 | 10k 1% | RevB:R_0603_1608Metric | Vishay | CRCW060310K0FKEA | C844918 | 1
R202 | 10k 1% | RevB:R_0603_1608Metric | Vishay | CRCW060310K0FKEA | C844918 | 1
R203 | 1k 1% RESET LIMIT | RevB:R_0603_1608Metric_RVB22_R203 | Vishay | CRCW06031K00FKEA | C844920 | 1
R204 | 100k /1% RESET DELAY | RevB:I32_FINISHED_R204 | Vishay | CRCW0603100KFKEA | C844916 | 1
R302 | 1k | RevB:R_0603_1608Metric | Vishay | CRCW06031K00FKEA | C844920 | 1
R303 | 10k 1% | RevB:R_0603_1608Metric | Vishay | CRCW060310K0FKEA | C844918 | 1
R401 | 0R GPS ISOLATION | RevB:R_0603_1608Metric | Vishay | CRCW06030000Z0EA | C844915 | 1
R402 | 220R | RevB:R_0603_1608Metric | Yageo | AA0603FR-07220RL | C2100485 | 1
R403 | 220R | RevB:R_0603_1608Metric | Yageo | AA0603FR-07220RL | C2100485 | 1
R404 | 220R | RevB:R_0603_1608Metric | Yageo | AA0603FR-07220RL | C2100485 | 1
R405 | 1k | RevB:R_0603_1608Metric | Vishay | CRCW06031K00FKEA | C844920 | 1
R407 | 100k | RevB:R_0603_1608Metric | Vishay | CRCW0603100KFKEA | C844916 | 1
R408 | 100k | RevB:R_0603_1608Metric | Vishay | CRCW0603100KFKEA | C844916 | 1
R409 | 100k | RevB:R_0603_1608Metric | Vishay | CRCW0603100KFKEA | C844916 | 1
R410 | 10k /UART idle | RevB:R_0603_1608Metric | Vishay | CRCW060310K0FKEA | C844918 | 1
R411 | 100k /off-state | RevB:R_0603_1608Metric | Vishay | CRCW0603100KFKEA | C844916 | 1
R501 | 27.4k /0.1% | RevB:R_0603_1608Metric | Vishay | TNPW060327K4BEEA | C2079063 | 1
R502 | 10k /0.1% | RevB:R_0603_1608Metric | Vishay | TNPW060310K0BEEA | C844890 | 1
R503 | 36.5k /0.1% | RevB:R_0603_1608Metric | Vishay | TNPW060336K5BEEA | C2089518 | 1
R504 | 10k /0.1% | RevB:R_0603_1608Metric | Vishay | TNPW060310K0BEEA | C844890 | 1
R505 | 118k /0.1% | RevB:R_0805_2012Metric | Vishay | TNPW0805118KBEEA | C1709453 | 1
R506 | 100k | RevB:R_0603_1608Metric | Vishay | CRCW0603100KFKEA | C844916 | 1
R507 | 4.7R /1% pulse HP | RevB:R_2512_6332Metric | Vishay | CRCW25124R70FKEGHP | C2075852 | 1
R511 | 1M /0.1% | RevB:R_0805_2012Metric | Vishay | TNPW08051M00BEEA | C844679 | 1
R512 | 4.02k /0.1% | RevB:R_0603_1608Metric | Vishay | TNPW06034K02BEEA | C844459 | 1
R513 | 124k /0.1% | RevB:R_0805_2012Metric | Vishay | TNPW0805124KBEEA | C1709494 | 1
R514 | 1k /0.1% | RevB:R_0603_1608Metric | Vishay | TNPW06031K00BEEA | C844891 | 1
R515 | 220R /1%150ppm | RevB:R_0603_1608Metric | Yageo | AA0603FR-07220RL | C2100485 | 1
R521 | 1M /0.1% | RevB:R_0805_2012Metric | Vishay | TNPW08051M00BEEA | C844679 | 1
R522 | 4.02k /0.1% | RevB:R_0603_1608Metric | Vishay | TNPW06034K02BEEA | C844459 | 1
R523 | 124k /0.1% | RevB:R_0805_2012Metric | Vishay | TNPW0805124KBEEA | C1709494 | 1
R524 | 1k /0.1% | RevB:R_0603_1608Metric | Vishay | TNPW06031K00BEEA | C844891 | 1
R525 | 220R /1%150ppm | RevB:R_0603_1608Metric | Yageo | AA0603FR-07220RL | C2100485 | 1
R601 | 1k / GPIO15 | RevB:R_0603_1608Metric | Vishay | CRCW06031K00FKEA | C844920 | 1
R602 | 1k / GPIO6 | RevB:R_0603_1608Metric | Vishay | CRCW06031K00FKEA | C844920 | 1
R603 | 1k / GPIO7 | RevB:R_0603_1608Metric | Vishay | CRCW06031K00FKEA | C844920 | 1
R604 | 1k / GPIO8 | RevB:R_0603_1608Metric | Vishay | CRCW06031K00FKEA | C844920 | 1
R605 | 1k / GPIO10 | RevB:R_0603_1608Metric | Vishay | CRCW06031K00FKEA | C844920 | 1
R606 | 1k / GPIO9 | RevB:R_0603_1608Metric | Vishay | CRCW06031K00FKEA | C844920 | 1
U101 | LTC4367HMS8#PBF | RevB:I32_PROCUREMENT_U101 | Analog Devices | LTC4367HMS8#PBF | C688370 | 1
U121 | LM5164QDDARQ1 | RevB:TI_DDA0008B_4214849B | Texas Instruments | LM5164QDDARQ1 | C2072225 | 1
U151 | LM63615DQPWPRQ1 | RevB:HTSSOP-16-1EP_4.4x5mm_P0.65mm_EP3.4x5mm_Mask2.46x2.31mm_RVB22_U151 | Texas Instruments | LM63615DQPWPRQ1 | C2867799 | 1
U152 | TPS22953-Q1 REVERSE BLOCKING | RevB:I32_FINISHED_U152 | Texas Instruments | TPS22953QDQCRQ1 | C5219894 | 1
U153 | TPS22953-Q1 BULK CHARGER | RevB:I32_FINISHED_U153 | Texas Instruments | TPS22953QDQCRQ1 | C5219894 | 1
U201 | ESP32-S3-WROOM-1-N8R2 | RevB:ESP32-S3-WROOM-1_RVB22_U201_TH48 | Espressif | ESP32-S3-WROOM-1-N8R2 | C2913204 | 1
U202 | TPS3808G33-Q1 3.07V RESET | RevB:TPS3808_DBV0006A | Texas Instruments | TPS3808G33QDBVRQ1 | C414616 | 1
U301 | TCAN3403DRBRQ1 | RevB:TI_DRB0008J_TCAN3403 | Texas Instruments | TCAN3403DRBRQ1 | C32921356 | 1
U401 | PA1616D | RevB:CDTop_PA1616D_20Pad_v06 | CDTop Technology | PA1616D |  | 1
U402 | SN74LVC2G125DCUR | RevB:VSSOP-8_2.3x2mm_P0.5mm | Texas Instruments | SN74LVC2G125DCUR | C21404 | 1
U403 | MIC5504-3.3YM5-TR | RevB:SOT-23-5 | Microchip | MIC5504-3.3YM5-TR | C88419 | 1
U404 | SN74LVC2G125DCUR | RevB:VSSOP-8_2.3x2mm_P0.5mm | Texas Instruments | SN74LVC2G125DCUR | C21404 | 1
U501 | TPS26600PWPR | RevB:TI_PWP0016A_TPS2660 | Texas Instruments | TPS26600PWPR | C544399 | 1
U502 | OPA2333AIDR | RevB:SOIC-8_3.9x4.9mm_P1.27mm | Texas Instruments | OPA2333AIDR | C38732 | 1

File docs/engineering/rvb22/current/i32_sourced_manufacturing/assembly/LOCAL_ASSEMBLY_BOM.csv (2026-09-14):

Reference | Value | Footprint | Manufacturer | MPN | LCSC | Quantity
F101 | 1A /500VDC | RevB:Fuse_Littelfuse-NANO2-885 | Littelfuse | 0885001.DR | C2879865 | 1
U401 | PA1616D | RevB:CDTop_PA1616D_20Pad_v06 | CDTop Technology | PA1616D |  | 1

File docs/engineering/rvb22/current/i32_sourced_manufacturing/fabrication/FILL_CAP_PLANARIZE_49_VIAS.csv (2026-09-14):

Reference | UUID | PCB X mm | PCB Y mm | Drill mm | Land mm
U201.41 | bfd86e59-5ad7-5341-82c0-a7a9fda47620 | 77.469766 | 20.375 | 0.2 | 0.6
U201.41 | eb93c0d7-3450-5704-8eca-1f9154b4f56c | 77.919766 | 20.375 | 0.2 | 0.6
U201.41 | d72b7fda-9a42-544b-8389-2a21a70fede0 | 78.369766 | 20.375 | 0.2 | 0.6
U201.41 | a27c8483-d7d2-5af4-840b-783456b2104a | 78.819766 | 20.375 | 0.2 | 0.6
U201.41 | 7ee3916a-276a-58b0-8ffa-547df9d26231 | 79.269766 | 20.375 | 0.2 | 0.6
U201.41 | 99d78d50-eb70-5980-8bc6-96748fa20b85 | 79.719766 | 20.375 | 0.2 | 0.6
U201.41 | ef24142a-c94a-59f2-8a5c-205671624e14 | 80.169766 | 20.375 | 0.2 | 0.6
U201.41 | 84fbb7f2-7bee-5553-89b1-b75e49bdef76 | 77.469766 | 20.825 | 0.2 | 0.6
U201.41 | 4c45f2fc-05e3-5793-8ebe-25ed8a659ba7 | 77.919766 | 20.825 | 0.2 | 0.6
U201.41 | f589eeeb-e381-5f48-8d3a-0c21b3919866 | 78.369766 | 20.825 | 0.2 | 0.6
U201.41 | 347575c4-650f-5f7a-8a86-4845297e1b3a | 78.819766 | 20.825 | 0.2 | 0.6
U201.41 | b1d5274d-96c5-57c6-867f-1221c18c24d2 | 79.269766 | 20.825 | 0.2 | 0.6
U201.41 | bfeaef42-e32e-5acf-8fc0-f329b55f8391 | 79.719766 | 20.825 | 0.2 | 0.6
U201.41 | bb615e3c-0a78-551e-8654-915b467d0378 | 80.169766 | 20.825 | 0.2 | 0.6
U201.41 | ef78647c-eca7-5292-83f4-b25b6f8270ce | 77.469766 | 21.275 | 0.2 | 0.6
U201.41 | 18e08ea4-2dad-56f0-8f50-bf1f335ed795 | 77.919766 | 21.275 | 0.2 | 0.6
U201.41 | 6c5a68b8-1b52-5e12-8412-10d2cd189d1d | 78.369766 | 21.275 | 0.2 | 0.6
U201.41 | 7cc6e6ef-a4b6-5ff2-87b2-4824f184d87d | 78.819766 | 21.275 | 0.2 | 0.6
U201.41 | 6b996bb8-9e90-52bc-8c18-5c8cbd8765cd | 79.269766 | 21.275 | 0.2 | 0.6
U201.41 | 14164b14-4235-54f1-8db8-d45c2850566b | 79.719766 | 21.275 | 0.2 | 0.6
U201.41 | fe750b02-70d0-5481-88cb-1fa418ceab42 | 80.169766 | 21.275 | 0.2 | 0.6
U201.41 | 9c434a9b-dd07-54f3-8786-f42c34b7c0b4 | 77.469766 | 21.725 | 0.2 | 0.6
U201.41 | 8cb29710-771b-5273-89a4-5dbcb9a6258f | 77.919766 | 21.725 | 0.2 | 0.6
U201.41 | b443c3fa-8779-599f-8a9f-f1285307357d | 78.369766 | 21.725 | 0.2 | 0.6
U201.41 | 2144b62f-fe15-5ce5-888c-b7cf6de5cd34 | 78.819766 | 21.725 | 0.2 | 0.6
U201.41 | bda0c4bc-81b2-52be-83e1-883a89cc7b84 | 79.269766 | 21.725 | 0.2 | 0.6
U201.41 | 4924afd5-07da-54da-878a-4d6d352f60dd | 79.719766 | 21.725 | 0.2 | 0.6
U201.41 | 22883634-ebbd-5b92-8bdf-2711079423b1 | 80.169766 | 21.725 | 0.2 | 0.6
U201.41 | 9840c434-1445-5f6d-824a-61dd19494463 | 77.469766 | 22.175 | 0.2 | 0.6
U201.41 | b752b41e-fafa-5a1b-842f-89f1ac40ef28 | 77.919766 | 22.175 | 0.2 | 0.6
U201.41 | b73b45d0-ebee-5829-8bb2-a065bb10d88e | 78.369766 | 22.175 | 0.2 | 0.6
U201.41 | 59ac719f-ece3-574f-8dce-92e5152a7857 | 78.819766 | 22.175 | 0.2 | 0.6
U201.41 | 7fe1fc58-4404-5dc0-8a32-d32b13a215f6 | 79.269766 | 22.175 | 0.2 | 0.6
U201.41 | ba8f99d2-fe4a-5bc0-8a6e-60cb433d11b7 | 79.719766 | 22.175 | 0.2 | 0.6
U201.41 | eaabd8e5-f6cf-5d66-8e42-697f5a4de0cf | 80.169766 | 22.175 | 0.2 | 0.6
U201.41 | a2b09f65-d9de-563e-8383-6cc0a2f082cc | 77.469766 | 22.625 | 0.2 | 0.6
U201.41 | c47721ea-32dd-56ce-8f35-3787d41f6334 | 77.919766 | 22.625 | 0.2 | 0.6
U201.41 | a39abf8d-62e7-5dd5-8ee4-303136cf05ed | 78.369766 | 22.625 | 0.2 | 0.6
U201.41 | ba67ae4e-5efd-57f4-8b90-1048aad54d22 | 78.819766 | 22.625 | 0.2 | 0.6
U201.41 | 3ef280a0-7d97-5854-8778-15e311975df9 | 79.269766 | 22.625 | 0.2 | 0.6
U201.41 | a09e8c2b-e543-5524-86a2-5e9ef15d68c1 | 79.719766 | 22.625 | 0.2 | 0.6
U201.41 | 84007739-5138-50e7-875f-6861225ff66c | 80.169766 | 22.625 | 0.2 | 0.6
U201.41 | 51941c55-fcd9-56e9-8a85-28371980e442 | 77.469766 | 23.075 | 0.2 | 0.6
U201.41 | cbc101e4-3c1e-59f4-874d-8a0386458c2c | 77.919766 | 23.075 | 0.2 | 0.6
U201.41 | 589eab7f-dfc5-5ccb-8970-bbbcf94be2c0 | 78.369766 | 23.075 | 0.2 | 0.6
U201.41 | 1fe4e66b-a2c7-583f-8229-3123e94a1ca1 | 78.819766 | 23.075 | 0.2 | 0.6
U201.41 | dbed8ccc-fd30-5858-89e6-91ed111f8886 | 79.269766 | 23.075 | 0.2 | 0.6
U201.41 | bb0630d0-93c1-5889-8e34-4a5bd5182b44 | 79.719766 | 23.075 | 0.2 | 0.6
R153.2 | 744040f0-f2a8-5899-a69c-202637932746 | 41.4 | 21 | 0.3 | 0.6

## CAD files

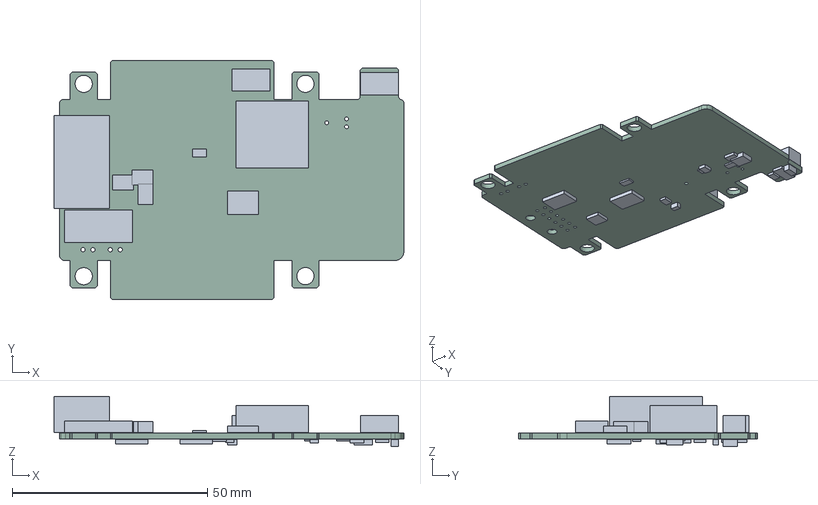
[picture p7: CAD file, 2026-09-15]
docs/engineering/rvb22/analyses/i32/procurement_redline/history/native_03/REVIEW_COMPONENTS.step
89.7 x 61.3 x 12.9 mm
ENVELOPE_I32_PROCUREMENT_R162
ENVELOPE_KEMET_C1210_10u50V x 3
ENVELOPE_I32_PROCUREMENT_R163
ENVELOPE_Fuse_Littelfuse-NANO2-885
ENVELOPE_KEMET_T598_X_7343_Median_RVB22_C206 x 2
ENVELOPE_I32_PROCUREMENT_R160
ENVELOPE_TI_DDA0008B_4214849B
ENVELOPE_CDTop_PA1616D_20Pad_v06
ENVELOPE_I32_PROCUREMENT_L121
ENVELOPE_R_0603_1608Metric_RVB22_R157
ENVELOPE_Molex_Micro-Fit_3.0_43045-1200_2x06_P3.00mm_Horizontal_RVB22_ F1
ENVELOPE_I32_PROCUREMENT_R161
ENVELOPE_TDK_CGA4J1_33N_I32
ENVELOPE_I32_PROCUREMENT_R169
ENVELOPE_TI_DPY0002A_TPD1E05U06_SMDMask
ENVELOPE_WSL2512_I32_R158
ENVELOPE_WSLP0603_MANUFACTURER_R153
ENVELOPE_I32_PROCUREMENT_R155
ENVELOPE_TDK_CGA5L1_68N_I32
ENVELOPE_I32_PROCUREMENT_R156
ENVELOPE_I32_PROCUREMENT_R170
ENVELOPE_TI_DRB0008J_TCAN3403
ENVELOPE_C_0603_1608Metric_RVB22_C205
ENVELOPE_Murata_LQW18AS_1608
ENVELOPE_TI_PWP0016A_TPS2660
ENVELOPE_TPS3808_DBV0006A
ENVELOPE_TI_DQC0010A_I32 x 2
ENVELOPE_R_0603_1608Metric_RVB22_R203
ENVELOPE_HTSSOP-16-1EP_4.4x5mm_P0.65mm_EP3.4x5mm_Mask2.46x2.31mm_RVB22_ U151
GR86_CCA_RevB_PCB

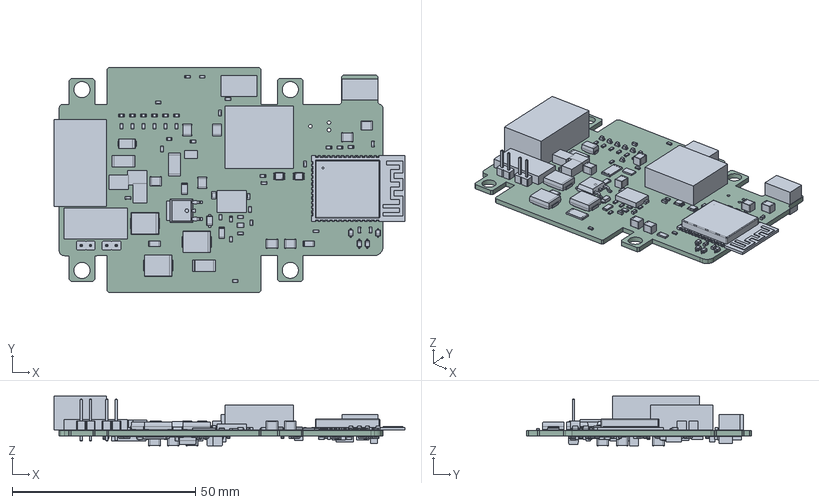
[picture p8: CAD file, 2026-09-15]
docs/engineering/rvb22/analyses/i32/procurement_redline/history/native_05/REVIEW_COMPONENTS.step
95.7 x 61.3 x 13.5 mm
ENVELOPE_I32_PROCUREMENT_R162
R_0603_1608Metric x 49
C_1210_3225Metric x 14
LED_0603_1608Metric x 7
R_2512_6332Metric x 4
C_0603_1608Metric x 29
D_SOD-323 x 4
ESP32-S3-WROOM-1
ENVELOPE_KEMET_C1210_10u50V x 3
R_1206_3216Metric x 7
D_SMA x 2
D_SOD-123F
ENVELOPE_I32_PROCUREMENT_R163
PinHeader_1x02_P2.54mm_Vertical x 2
ENVELOPE_Fuse_Littelfuse-NANO2-885
ENVELOPE_KEMET_T598_X_7343_Median_RVB22_C206 x 2
VSSOP-8_2.3x2mm_P0.5mm x 2
D_SMC x 3
ENVELOPE_I32_PROCUREMENT_R160
C_0805_2012Metric x 3
ENVELOPE_TI_DDA0008B_4214849B
ENVELOPE_CDTop_PA1616D_20Pad_v06
ENVELOPE_I32_PROCUREMENT_L121
ENVELOPE_R_0603_1608Metric_RVB22_R157
REVIEW_COMPONENTS 1.80.1
R_0805_2012Metric x 6
ENVELOPE_Molex_Micro-Fit_3.0_43045-1200_2x06_P3.00mm_Horizontal_RVB22_ F1
ENVELOPE_I32_PROCUREMENT_R161
ENVELOPE_TDK_CGA4J1_33N_I32
ENVELOPE_I32_PROCUREMENT_R169
ENVELOPE_TI_DPY0002A_TPD1E05U06_SMDMask
ENVELOPE_WSL2512_I32_R158
ENVELOPE_WSLP0603_MANUFACTURER_R153
ENVELOPE_I32_PROCUREMENT_R155
ENVELOPE_TDK_CGA5L1_68N_I32
ENVELOPE_I32_PROCUREMENT_R156
ENVELOPE_I32_PROCUREMENT_R170
ENVELOPE_TI_DRB0008J_TCAN3403
ENVELOPE_C_0603_1608Metric_RVB22_C205
ENVELOPE_Murata_LQW18AS_1608
ENVELOPE_TI_PWP0016A_TPS2660
ENVELOPE_TPS3808_DBV0006A
ENVELOPE_TI_DQC0010A_I32 x 2
ENVELOPE_R_0603_1608Metric_RVB22_R203
ENVELOPE_HTSSOP-16-1EP_4.4x5mm_P0.65mm_EP3.4x5mm_Mask2.46x2.31mm_RVB22_ U151
GR86_CCA_RevB_PCB

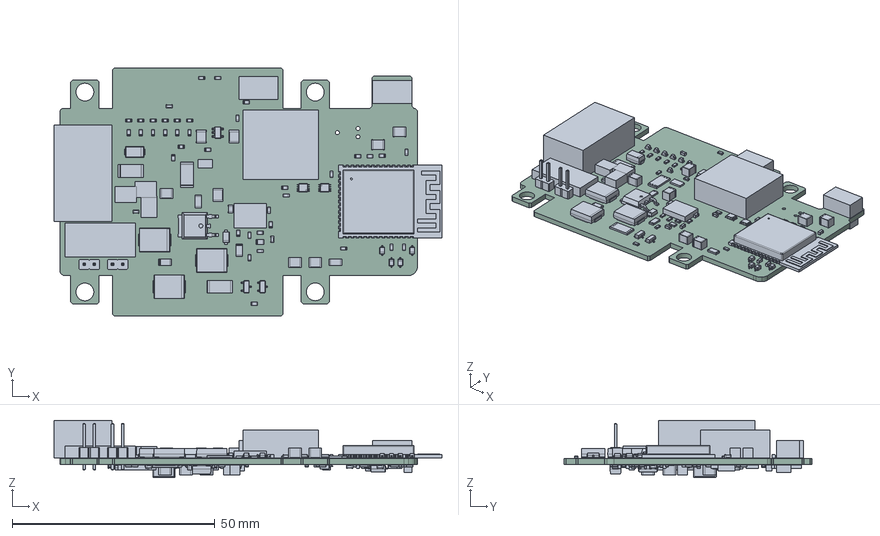
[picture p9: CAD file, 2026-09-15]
docs/engineering/rvb22/analyses/i32/procurement_redline/native/REVIEW_COMPONENTS.step
95.7 x 61.3 x 14.1 mm
ENVELOPE_I32_PROCUREMENT_R162
R_0603_1608Metric x 49
C_1210_3225Metric x 14
LED_0603_1608Metric x 7
R_2512_6332Metric x 4
C_0603_1608Metric x 29
D_SOD-323 x 4
ESP32-S3-WROOM-1
ENVELOPE_KEMET_C1210_10u50V x 3
R_1206_3216Metric x 7
D_SMA x 2
SOT-23-5
D_SOD-123F
ENVELOPE_I32_PROCUREMENT_R163
PinHeader_1x02_P2.54mm_Vertical x 2
SOT-23 x 4
ENVELOPE_Fuse_Littelfuse-NANO2-885
ENVELOPE_KEMET_T598_X_7343_Median_RVB22_C206 x 2
VSSOP-8_2.3x2mm_P0.5mm x 2
D_SMC x 3
ENVELOPE_I32_PROCUREMENT_R160
C_0805_2012Metric x 3
ENVELOPE_TI_DDA0008B_4214849B
ENVELOPE_CDTop_PA1616D_20Pad_v06
ENVELOPE_I32_PROCUREMENT_L121
ENVELOPE_R_0603_1608Metric_RVB22_R157
REVIEW_COMPONENTS 1.82.1
R_0805_2012Metric x 6
ENVELOPE_Molex_Micro-Fit_3.0_43045-1200_2x06_P3.00mm_Horizontal_RVB22_ F1
ENVELOPE_I32_PROCUREMENT_R161
L_Coilcraft_XAL5030-XXX
ENVELOPE_TDK_CGA4J1_33N_I32
ENVELOPE_I32_PROCUREMENT_R169
ENVELOPE_TI_DPY0002A_TPD1E05U06_SMDMask
ENVELOPE_WSL2512_I32_R158
ENVELOPE_WSLP0603_MANUFACTURER_R153
ENVELOPE_I32_PROCUREMENT_R155
ENVELOPE_TDK_CGA5L1_68N_I32
ENVELOPE_I32_PROCUREMENT_R156
ENVELOPE_I32_PROCUREMENT_R170
ENVELOPE_TI_DRB0008J_TCAN3403
ENVELOPE_C_0603_1608Metric_RVB22_C205
ENVELOPE_Murata_LQW18AS_1608
SOIC-8_3.9x4.9mm_P1.27mm
ENVELOPE_TI_PWP0016A_TPS2660
ENVELOPE_TPS3808_DBV0006A
ENVELOPE_TI_DQC0010A_I32 x 2
U.FL_Hirose_U.FL-R-SMT-1_Vertical
ENVELOPE_R_0603_1608Metric_RVB22_R203
MSOP-8_3x3mm_P0.65mm
ENVELOPE_HTSSOP-16-1EP_4.4x5mm_P0.65mm_EP3.4x5mm_Mask2.46x2.31mm_RVB22_ U151
GR86_CCA_RevB_PCB

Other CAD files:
docs/engineering/rvb22/analyses/i32/procurement_completion/native/candidate_kicad/models/ENVELOPE_I32_PROCUREMENT_R163.step
docs/engineering/rvb22/analyses/i32/procurement_redline/history/native_04/REVIEW_COMPONENTS.step
docs/engineering/rvb22/current/i32_sourced_manufacturing/documentation/POPULATED_COMPONENTS.step
docs/engineering/rvb22/current/i32_sourced_manufacturing/editable_source/cad/models/ENVELOPE_I32_PROCUREMENT_R160.step
docs/engineering/rvb22/analyses/i32/procurement_completion/native/candidate_kicad/models/ENVELOPE_I32_PROCUREMENT_R169.step
docs/engineering/rvb22/current/i32_sourced_manufacturing/editable_source/cad/models/ENVELOPE_I32_PROCUREMENT_R155.step
docs/engineering/rvb22/analyses/i32/procurement_completion/native/candidate_kicad/models/ENVELOPE_I32_PROCUREMENT_R161.step
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

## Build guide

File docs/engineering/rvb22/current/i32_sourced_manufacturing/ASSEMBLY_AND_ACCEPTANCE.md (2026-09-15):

# Sourced I32 assembly and acceptance

Use this package's native project, BOM, CPL, Gerbers and manifest together.
The assembly population is 177 fitted / 175 factory / 2 local (F101, U401).
C203, R301 and R306 are DNP. Every factory reference stays in the full CPL even
when its sourcing or handling requires supplier review.

## Supplier sourcing review

`assembly/PROCUREMENT_BOM.csv` lists exact MPNs, documented supplier spellings,
catalog handling, stock snapshots and preorder minima. All 175 factory references
have JLC catalog assignments; Global Sourcing and consignment are not permitted
factory sourcing routes for this package. No substitutions are authorized by a
blank field or by a supplier's similar-part recommendation.

The purchasing quantity must cover the build quantity and the supplier's assembly
attrition allowance. Complete the parts listed in `PREORDER_REQUIREMENTS.csv`
and confirm receipt into the parts library before scheduling assembly. Snapshot
stock and a public preorder button do not reserve inventory or guarantee lead time.

JLC marks several entries `manualWeld` (wave/manual handling), including L121,
C162, F1, D104, J202 and J203 as identified by the generated procurement BOM. Confirm
each actual part's process, orientation and fixture requirements with the
manufacturer; catalog handling is not a board-level solder-process approval.
In particular, C162's catalog package description is inconsistent with its
manufacturer dimensions. The supplied KEMET maximum-body footprint and model
remain controlling. No footprint is resized to match that catalog label.

## Placement and fabrication

CPL coordinates retain KiCad's auxiliary origin (0, 41.288863) mm:
X = board X, Y = 41.288863 − board Y. Layer and angles are the native exports;
obtain the supplier's feeder/bottom-side orientation acceptance. Do not add
blanket 90°/180° corrections. F101 and U401 are excluded from factory CPL.

R156 remains 1206, R160 remains 0805 and L121 keeps its qualified BPCI land
pattern. All 13 frozen MPN/C-number bindings are unchanged. Preserve C166's
edge/placement allocation and maximum-body model. U101 retains the accepted
LTC4367HMS8#PBF ordering pedigree; #W equivalence is not claimed.

Retain four layers, 70/30/30/70 µm copper, 203/1030/203 µm dielectric, ENIG,
1.44–1.76 mm accepted finished thickness and at least 15 µm minimum finished
hole-wall plating. Exactly 49 enumerated vias require fill, cap and planarize:
48 at U201 and one at R153. Use the supplied process JSON and location CSV.
Preserve all exposed-pad net isolation and stencil windows, including U501's
separate OIL_EFUSE_RTN. Ordinary tented vias are not an approved replacement.

F101 requires its qualified local solder process after global reflow. U401
PA1616D remains local installation at PCB (54.5, 9.0) mm, F.Cu, 0°; pin 1 is
(46.7, 2.25) mm in top view. Exact module supply and receiving inspection remain
required. Preserve all antenna and connector keepouts.

## Retained qualification

The controlling C05/W02/T03 mechanics, harness and receiving/installation
requirements remain those in `documentation/QUALIFIED_ASSEMBLY_REQUIREMENTS.md`;
its earlier procurement counts are superseded by this package. Retain all
material, fit, clamping, thermal-contact and cable-restraint acceptance gates.

The I25 release profile and 2.940859375 W heat budget remain fixed. Retain the
112.8829809018675 °C board-region correlation trigger and U201 immediate-air
limit of 85 °C. At U151 efficiency of 80%, the retained loss allocation requires
U121 efficiency about 83.4631% or an accepted measured-loss alternative within
the same budget. Neither board temperature nor simulated power proves physical
junction temperature or efficiency. Adafruit 851's retained local 60 °C limit
also remains a qualification condition.

Use only the source-bound 160 MHz firmware identified in FIRMWARE_EFFECTIVITY.json.
Fit/assembly, thermal and electrical correlation, transient/reset/EMC tests,
vehicle validation and unit acceptance remain open. This package records no
supplier acceptance, manufacturing order, flashing or physical test.

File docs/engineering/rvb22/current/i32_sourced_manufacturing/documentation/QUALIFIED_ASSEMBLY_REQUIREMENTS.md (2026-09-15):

> Retained physical/process requirements. This package's README and procurement BOM supersede the sourcing counts and source paths in this baseline document.

# Current I32 procurement-redline manufacturing and assembly effectivity

The controlling source is the 177-part I32 candidate, authored PCB SHA256 `52ca35cf8cb4e2b4a27d053686ee3a85564f1e94dfdb7dcb4bca4083dd527312`, native filled PCB SHA256 `896ca56bf4ad836d63b84537cfd20bfcbf1783c60ac5d92ab7c7783d54f57e92`. `SOURCE_EFFECTIVITY.json` and `../product/PRODUCT_HANDOFF.md` identify the current exports and acceptance. Earlier I20/I22/I29 source counts, hashes and electrical values are superseded; their records remain in history.

| Item | Current instruction |
|---|---|
| Assembly | 177 fitted references, 175 factory-supplied CPL rows; L121 needs supplier-approved manual/wave handling. F101 and U401 remain local/manual exceptions. Use the generated complete BOM and CPL; confirm supplier bottom-side rotation conventions. |
| Sourcing | 29 unchanged factory references have no assigned LCSC code. Confirm exact MPNs; a blank code is not approval for substitution. C203, R301 and R306 remain DNP. |
| Switches and capacitors | U152/U153 TPS22953QDQCRQ1, without QOD. C159 33 nF CGA4J1C0G2A333J125AE; C166 68 nF CGA5L1C0G2A683J160AE. C162 T598X477M010ATE025 470 uF/10 V; C206 T598X687M006ATE025 680 uF/6.3 V. Use the supplied maximum-body footprints/models. |
| C166 tab fit | B.Cu (85.85, −3.0) mm, 90°; maximum body 3.60 ×1.90 ×1.90 mm. Copper-edge clearance 0.30 mm; nominal maximum-body-to-tab-edge clearance 0.10 mm. Confirm edge/placement tolerance, solder fillets and installed fit with the supplier and first article. |
| Feedback and damping | R155 PTFR0603B11K8N9/C19679768, 11.8 k, 0.1%, 10 ppm/K; R156 PLT1206Z5051LBTS/C4074185, 5.05 k, 0.01%, 5 ppm/K, **1206**. R160 RT0805BRB076K34L/C864499 is **0805**. L121 BPCI00121280470M00/C6471075 uses the BPCI land pattern and 8 mm maximum height. R158 WSL2512R3000FEA 0.30 ohm. R165 **CRCW25124R70FKEGHP**, 4.7 ohm HP 1.5 W; the standard 1 W variant is not equivalent. R204 100 k selects the reset delay. |
| Input protection | D101 S5J 600 V; R101 CRCW251212K1FKEG 12.1 k/1 W; D105 SMCJ110A. Preserve clamp polarity and source-bound routes. |
| Layers and finish | Four layers, 70/30/30/70 um copper, 203/1030/203 um dielectric and ENIG. Retain all authored clearances and rules. Board nominal 1.6 mm, accepted thickness interval 1.44–1.76 mm. |
| Filled/capped vias | Exactly 49 enumerated locations: 48 at U201 exposed pad 41 and one at R153. Fill, cap and planarize for soldering. Ordinary tented vias do not substitute for these locations. |
| Plating and drill | At least 15 um **minimum finished wall**, not merely an average specification. New ordinary vias are at least 0.6 mm land/0.3 mm drill. Supplier drill/preplate process and connector/hardware fit require exact DFM acceptance. |
| Fuse process | F101 Littelfuse 0885001.DR is excluded from global paste/PnP. Its recommended 255–260 C process conflicts with the ESP32 module's 235–250 C range; use a qualified local solder process after global reflow. |
| Manual GPS | U401 PA1616D, PCB centre (54.5, 9.0) mm, F.Cu, 0°. Pin 1 is at PCB (46.7, 2.25) mm in top view. Preserve the verified land numbering and antenna keepout. |
| Probe access | 38 approaches checked with a 0.30 mm needle, 0.10 mm position allowance and at least 5 mm slender exposed shaft. Remove carrier for bottom access; retain latch and programming volumes. Use short-return or differential probing for fast signals. R153 remote test points share power copper; they are not four-terminal Kelvin sensing. |

The controlling mechanics remain C05/W02/T03 in `mechanics/`. Each flex member uses 200 annealed, unbonded C110 laminae, 0.010–0.011 mm each, with bonded terminals only, total 2.0–2.2 mm. Preserve cold-terminal support, material/hot-strength/contact requirements and maximum 220 g carrier mass. C05 support relief and cable restraint remain mandatory. Material, friction, clamp retention, creep/fatigue and installed construction remain acceptance gates.

The populated clearance model adds the full 1.71 mm: 0.25 mm solder, 0.51 mm capture freedom, 0.75 mm warp and 0.20 mm deflection. Component XY adds 0.30 mm; flex geometry includes the full 2.2 mm packet, 0.50 mm bow and 0.30 mm position allocation; carrier/support XY adds 0.15 mm. Current evidence covers 1,308 populated and 529 mated checks plus 38 probes, with no interference. Minimum allocated separation is 0.120 mm at R408/T03 and 0.200 mm at C159/W02. This does not establish installed fit.

Retain Adafruit 851 with Adafruit 960, 150 ±3 mm to the SMA shoulder, nominal cable OD 1.8 mm, receiving maximum OD 2.0 mm, 0.5 mm lateral uncertainty and 15 mm bend radius. The miniature mated-plug allocation is 3.4 ×5.3 ×3.25 mm. Preserve the negative-Y exit and independent carrier restraint. **851 local environment must remain at or below 60 C**, including during the 65 C cabin test; relocation or an approved rated alternative is required if exceeded.

Keep source-defined exposed-pad nets and stencil windows: U121/U151/U201/U301 ground topology, U201's nine 0.9 mm mask/paste windows and 48 filled/capped pad vias, and U501's separate OIL_EFUSE_RTN. Do not short the oil eFuse return to ground. Current native Gerbers and the authored PCB govern exact geometry; earlier package overlays and thermal/via screens apply only to unchanged geometry and retain their original scope. Independent stencil/reflow and human assembly review remain open.

Harness effectivity is the GR86 ASC mapping in the retained interface contract, with the single full-current F1.1 return and F1.2 unpopulated. Use switched fused accessory power, controlled terminations and strain relief. Preserve receive-only CAN, TCAN3403DRBRQ1, the GPIO contract, PA1616D 115200/10 Hz/PPS and the Honeywell MIP 150 psi 5 V ratiometric sensor.

The I25 profile and fixed 2.940859375 W heat budget remain. Both converters at exactly 80% with worst modeled leakage exceed it; at U151 80%, U121 requires about 83.4631% or an approved measured-loss alternative within the same budget. Retain the 112.8829809018675 C board-region correlation trigger, U201 immediate air at most 85 C and all I32/retained I26 qualification gates. No supplier approval, order or physical qualification is implied.

For historical detail, see `../analyses/i32/history/I22_MANUFACTURING_AND_ASSEMBLY.md`. Its old electrical values, source effectivity and numerical counts are not current instructions. Any part, geometry, material, process or firmware change requires impact review and regeneration of affected evidence.

All 13 frozen references have exact MPN/C-number and native package bindings in `../analyses/i32/procurement_redline/FINAL_REDLINE_VERIFICATION.json`. U101 is LTC4367HMS8#PBF/C688370: the owner accepts losing the #W controlled-manufacturing pedigree; functional equivalence does not mean pedigree equivalence. See the exact live-source snapshot and supplier conditions in that report. Use `i32_manufacturing/SOURCE_MANIFEST.json` and `../product/GR86_I32_PROCUREMENT_REDLINE.zip`; earlier product ZIPs are historical.

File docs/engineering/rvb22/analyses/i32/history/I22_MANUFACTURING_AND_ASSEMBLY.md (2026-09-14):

# I22 manufacturing and assembly effectivity

The controlling electrical source is I20, PCB SHA256 `b6c704c0c97685a68ba708d320347148e5136c182c221d86627ff5b319954b3c`. The filled PCB is `62c08e7050fe95df0a576ece85a051b4049e9684bf8ea5f73e8949657363276b`. The current source is in `iterations/I20_controlled_handoff/candidate_kicad`; matching native exports are in `runtime/hosted/run22/extracted/native_I06_hosted`. The legacy folder name in the native artifact does not change its I20 hash identity.

Native run 34420381540 has zero ERC, DRC, warning, unconnected or parity findings. I21 verified all 774 archived outputs and all 101 CAD/32 firmware inputs. I22 separately verifies unchanged source identities and its new engineering evidence; it does not claim a new native build. Independent copper reconstruction agrees with all four copper Gerbers, 338 plated and ten NPTH drills, and the expanded schematic netlist. This is a review candidate. Thermal engineering and supplier/first-article acceptance remain open.

| Item | Current instruction |
|---|---|
| Assembly | 153 fitted references. The 151 automated placement rows match the native board; F101 and U401 are manual exceptions. Keep both in the fitted BOM. |
| Placement datum | X equals PCB X. Placement Y equals 41.288863 mm minus PCB Y. Side and rotation are checked explicitly. |
| Filled/capped vias | 49 total: 48 at U201 exposed pad 41, plus one at R153. Use the I20 source coordinates and the current via-in-pad list. Do not use the historical 13-via list. Fill, cap and planarize for soldering. |
| Plated wall | 15 µm minimum finished wall is a model/construction requirement. An average plating specification does not establish the minimum. No resin conductivity credit is used. |
| PCB outline | 88.254766 × 61.275846 mm overall board bounds, including the C206 tab. ESP32 module overhang and mated harness/service envelopes are additional. |
| C206 | T598X477M006ATE025, F.Cu at (82, −4) mm on the grounded FR4 tab. Preserve clearance, polarity and the new long branch. The tab's 30 g static case passes its declared hot-FR4 bound; this is not a fatigue result. |
| Precision feedback | R155 TNPU060311K8HWEA00, 11.8 kΩ; R156 TNPU06034K99HWEA00, 4.99 kΩ. The current analysis includes 0.02% tolerance, 2 ppm/K and independent 0.1% drift. |
| Bulk damping | R158 WSLP0603R0820FEA, 82 mΩ. Historical 47 mΩ instructions are superseded. |
| F101 process | Littelfuse 0885001.DR. Exclude from the global paste/PnP process. Its recommended 255–260°C process conflicts with the ESP32 module's 235–250°C range; use a qualified local solder process after global reflow. |
| Models | Every fitted reference has a resolved model. Many are conservative manufacturer-height/allocated-XY envelopes; they are not asserted to be detailed supplier solids. |
| Branding | Approved Compact TW artwork, one-color F.SilkS, 8 mm. Current native polygon comparison agrees with the original SVG within the recorded geometric tolerance. |

The controlling carrier is C05 with W02 wing flexures and T03 central flexure, in `iterations/I15_service_mechanics/candidate_mechanics`. Each flex member uses 200 annealed, unbonded C110 laminae, 0.010–0.011 mm each, with bonded terminals only. Total thickness is 2.0–2.2 mm. Do not substitute a solid bonded stack or the older 40-foil construction: their reaction forces differ. Support the cold terminals as specified. Material conductivity, hot strength, friction, retained clamp tension, creep/fatigue and the maximum 220 g carrier mass remain explicit construction conditions.

The C05 support relief and 150 mm coax S-route are required. The selected assembly is now explicitly Adafruit 851 with the Adafruit 960 puck. Use 150 ±3 mm to the SMA shoulder, nominal cable OD 1.8 mm, receiving-envelope maximum OD 2.0 mm, 0.5 mm lateral route uncertainty and 15 mm bend radius. The miniature mated plug allocation is 3.4 ×5.3 ×3.25 mm. Preserve its negative-Y exit and independent carrier restraint. The supplied plug dimensions and retention remain acceptance conditions. The published 851 operating ceiling is 60°C, below the 65°C modeled air case; see `ACCESSORY_REVIEW.md`.

The populated clearance model adds the complete 1.71 mm stack to each maximum component height: 0.25 mm solder, 0.51 mm capture freedom, 0.75 mm warp and 0.20 mm local deflection. This corrects the previous 1.20 mm code allowance. Component XY envelopes include 0.30 mm; flexure geometry includes the full 2.2 mm packet, 0.50 mm lateral bow and 0.30 mm position allowance. Carrier base/support XY adds 0.15 mm. Fastener/landing boxes are included. All 1,154 populated-board and 776 mated checks pass; the smallest modeled separation is 0.120 mm from R408 to the T03 flexure, followed by 0.230 mm at L406. These bounds are construction requirements. Exceeding any of them requires a new clearance check before assembly.

All 12 IC/module top/bottom orientations and 151 numbered signal lands now have independently transcribed manufacturer drawing overlays against native placement output. U401 is a manual placement: PCB centre (54.5, 9.0) mm, F.Cu, rotation 0°; its corresponding placement Y is 32.288863 mm. Pin 1 is at PCB (46.7, 2.25) mm in the top view. The legacy PA1616D footprint suffix `v06` does not identify the revision of the current Adafruit-linked V.05 PDF; I22 verifies geometry and pin numbering directly. Do not infer a manufacturer revision from that library filename.

| Exposed pad | Required net | Current mask/paste interpretation |
|---|---|---|
| U121 pad 9 | GND | Manufacturer mask window; paste is 58.85% of exposed mask area. Four nearby pad vias lie outside the paste apertures. |
| U151 pad 17 | GND | Manufacturer mask window; paste is 63.17% of exposed mask area. Six pad vias lie outside the paste apertures. |
| U201 pad 41 | GND | Nine 0.9 mm mask/paste windows within 3.9 mm buried copper. The 48 affected vias require fill, cap and planarization. |
| U301 pad 9 | GND | Multiple same-net returns, including two vias 0.4 mm outside the pad edge. The drawing does not mandate via-in-pad. |
| U501 pad 17 | OIL_EFUSE_RTN | Preserve the TPS2660 RTN topology. Paste is 61.54% of exposed mask area; it is not an instruction to short RTN to system ground. |

The package audit records compatible alternative lead-land dimensions where KiCad IPC lands differ from the manufacturer's example. These orientation and copper/mask checks do not substitute for stencil/reflow or independent human assembly review. Keep DRW-03 and the process gates open.

The current drill reconciliation contains 338 plated holes and ten NPTH holes: 63 ×0.2 mm and 259 ×0.3 mm vias, 12 ×1.02 mm connector holes, and four ×1.1 mm header holes. Nominal via annular ring is at least 0.15 mm. The 1.6 mm board acceptance interval is 1.44–1.76 mm. JLCPCB's published through-hole tolerance is +0.13/−0.08 mm; a public capability is not acceptance of this exact order, and no unsupported NPTH tolerance is assigned. The maximum nominal finished-hole aspect ratio is 8.8; allowing the full negative diameter tolerance raises that geometric ratio to 14.67. Supplier drill-tool/preplate construction and exact connector/hardware fit remain DFM-02 work. The published average wall does not satisfy a 15 µm minimum-wall requirement.

All 322 vias pass the declared normal-load self-heating screen at 2 A in each individual via, with no sharing credit, 1.76 mm board thickness, 15 µm minimum wall and −0.08 mm finished-hole allowance. Maximum calculated via self-rise is 5.103 K against a 10 K budget. Absolute board/package temperature, fault survival and supplier plating acceptance remain separate requirements.

All 776 declared mated-body checks and 37 probe approaches pass. The probe contract is a 0.30 mm needle, 0.10 mm position allowance and at least 5 mm slender exposed shaft. Remove the carrier for bottom access. The listed nearest ground contacts are suitable for DC access; use differential or short-return probes for fast signals. Keep the connector's latch and programming-tool service volumes clear.

Harness effectivity remains the GR86 ASC mapping per Timurrr and the single full-current F1.1 return. Leave F1.2 unpopulated in the harness. Use switched, fused accessory power and retain the relaxed free exit, strain relief and controlled termination/profile conditions. The named Honeywell sensor is a 150 psi sealed-gauge, 5 V ratiometric device.

Historical fabrication, mechanical and assembly records remain evidence of earlier iterations. This document and the exact I20 manifests govern the current candidate. Any geometry, material, stackup, part, cable, solder process or firmware change requires impact review and regenerated affected evidence.

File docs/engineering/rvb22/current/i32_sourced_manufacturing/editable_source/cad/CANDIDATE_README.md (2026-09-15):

# GR86 CCA Rev B — I32 procurement redline

This is the native design for the frozen I32 procurement substitution set. The controlling handoff and pre-redline source remain preserved in git. Current verification, sourcing, package evidence and release bindings are under `../../analyses/i32/procurement_redline/`.

The source contains 177 fitted placements: 175 factory placements plus F101 and U401 local/manual installation. C203, R301 and R306 remain DNP. The 3.3 V feedback divider is 11.8 kΩ / 5.05 kΩ (PTFR0603B11K8N9 / PLT1206Z5051LBTS). R156 uses 1206 lands, R160 uses 0805 lands, and L121 uses the BPCI00121280 manufacturer land pattern.

U101 is LTC4367HMS8#PBF. The owner accepts removal of the #W controlled-manufacturing ordering option; electrical equivalence does not confer equivalent pedigree.

Project-specific footprints are in `libraries/RevB.pretty`. New STEP bodies prefixed `ENVELOPE_I32_PROCUREMENT_` are dimensionally bounded generic maximum-body envelopes, not manufacturer CAD. Standard KiCad models require KICAD6/7/9_3DMODEL_DIR to point to an installed KiCad 3D library. No physical assembly, thermal, vehicle or hardware validation is claimed by these files.

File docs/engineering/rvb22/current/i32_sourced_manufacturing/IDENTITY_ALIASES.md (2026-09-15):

# Explicit procurement identity mappings

The qualified design MPN remains unchanged. `SupplierMPN` and the JLC import use
the catalog spelling. These are five individually evidenced identity mappings,
not a general rule permitting similar part numbers or interchangeable suffixes.

| Design MPN | Supplier/catalog spelling | References | Evidence |
|---|---|---|---|
| CGA4J2X7R2A104K125AA | CGA4J2X7R2A104KT0Y0U | C101, C123, C503 | [Newark exact part and “Also Known As” field](https://www.newark.com/tdk/cga4j2x7r2a104k125aa/cap-0-1uf-100v-mlcc-0805/dp/40Y2282) |
| CGA6N3X7R2A225K230AB | CGA6N3X7R2A225KT0Y0U | C103, C121, C122, C129 | [DigiKey exact part and alias field](https://www.digikey.com/en/products/detail/tdk-corporation/CGA6N3X7R2A225K230AB/2443344) |
| CGA3E2C0G1H101J080AA | CGA3E2C0G1H101JT0Y0N | C126, C514, C524 | [DigiKey exact part and alias field](https://www.digikey.com/en/products/detail/tdk/CGA3E2C0G1H101J080AA/2443118) |
| 0430451200 | 430451200 | F1 | [Molex product 43045-1200, including leading-zero keyword](https://www.molex.com/en-us/products/part-detail/43045-1200) |
| ERA3AEB1472V | ERA-3AEB1472V | R104 | [Panasonic manufacturer identity and specifications](https://industrial.panasonic.com/ww/products/pt/high-precision-chip-resistors/models/ERA3AEB1472V), paired with captured JLC C2074591 |

TDK's [manufacturer naming notification](https://www.farnell.com/datasheets/1683658.pdf)
explains why a catalog number's suffix differs from the item description printed
on its packaging. The three exact pairings above are separately listed by the
suppliers; the naming notification alone is not used to infer any other pairing.
Sources were checked on September 15, 2026. Supplier labels and received lots
still require normal receiving inspection.

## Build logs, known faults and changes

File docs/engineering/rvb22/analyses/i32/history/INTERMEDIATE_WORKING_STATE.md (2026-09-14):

# I32 execution checkpoint — C166 repair adopted

Current HEAD4c3e54395e84483298e453468a65ff2646e9de4e, existingPR46 branchcodex/rvb24-coordinated-closure. No newcommit/push. Authorizationfinish scopedengineering+nonforcepush; no merge/order/hardware. Noagents.

U121source/modelmismatch repaired inmodel: fitted4.908V nominal,retained4.75..5.25.33n bulkCT failed750mAstartup at4.75(min/maxU151limitaborts,allstorageSNS2). C1651u delayalone and2inputcaps+doubleinputCT rejected; noCADadoption. Waveformproved prolongedU121currentlimiting frombulkcharge under.75A.

ADOPTED C16668n C0G100V5%softTDK CGA5L1C0G2A683J160AE,1206max3.6x1.9x1.9mm. ReflowPA2.2/PB1.1/PC1.5 pads±1.65. Back85.85,-3,90deg. Originalattempt86.05failededge.1mm;recenter gives.30mmcopperedge. Updatedschematic,nativeI32_FINISHED_C166foot/model,CTtail/GNDlead. Noother177partchange. C15933nC162470uC206680uR158.3 retained. All7targeted68nratiooptionspassed,normalSNS0READY1;19remainingexactformula casesnowrunning. ExactCTs/V min.01804688/nom.02382/max.03009768. SourcePCB45a2a679d9893d51fa641e539af45bc6ec1324169ea5f2226ecdea0ae2464da7;filled249d7b584af71605ee160c1ff425fda16a11b3ba93458bb243a722214c66ab30.

FINALnative_c166_68n_release:0ERC/DRC/unconnected/parity/exclusions,177STEP,135CADinputs,13postconditions. Restoredoriginal.pro/.prl afterproclassorder-only serialization verifiedsemanticallyidentical;thislastnativeiscomplete. SOURCE_AUDIT/PARTchangesregeneratedPASS135/32firmware/49VIP/unchangedCANetc. mechanical_c166_68n_finalPASS177,full1.71,1837checks38probes0hits;layout_c166_68n_final80paths7views;filled_c166_68n_finalrunning/completecheck. thermal_c166_68n_final_.5/.25running/completecheck;ground_c166_68n_finalrunning/completecheck. Groundbaseline engineering_runs/TERMINAL_BASELINE.kicad_pcb371518b5... extractedfromevidencegzip.

POWER: power_final_c166_68n15completedgood;resource exhaustion damagedremainingattempts.16rawarchivepreservesallattempts. Exact19remainingcasesrun power_final_c166_68n_recovery session91599,jobs1. power_chain.run nowusesunsynchronized /tmp staging, publishesonlyverifiedgzip+smallfiles afterfullcompletion; samedecks/models, preventsrawsyncduplication. Mergepercase in SOURCE_BOUND_POWER_CASES order into engineering_runs/POWER_C166_68N_COMPLETED.json withrecord_directory andassertsameparams. finalize_evidence.py updatedallfinalgeometrydirectorynames and135CADcount,expectsmergedpowerfile. Itmustnotacceptfailedcases.

Heavyfiles:16FullRecordsZIPsdeliverables~10.4GB,storedindexFULL_RECORD_ARCHIVESbothplaces. Noongoingarchiver. Archive04(17.8MB)successfullysavedLibrary libfile_de532715cfe88191b0118524df1f136e (file_00000000eba0822f922fd6b6da72376e).15batch/01alone(830MB)preparefailed LibraryDependencyError;small04passed,suggestsfilesizelimit. Mustsplitthelargerarchives into<=450MB byteparts,verifyconcatenatedSHA,saveorderedhelperbatchesandreassemblyindex;originalcanonlyberemovedafterverifiedreplacement. NootherfileLibrarysaveyet. FinalmanufacturingZIPnotbuilt.

FSsync repeatedlyrestoresdeletedraws/partialfilescausing32GBdiskfull. preserve_runs.remove_verified_duplicate nowtruncatesemptythenunlinks ONLYaftermatchingverifiedgz/archive;skipzero-sizewaveforms. Neverdeleteasolerecord. Currentpowerstaged/tmpavoidsproblem. 16archivesverifiedexactCRC/hash. Partial/diskresourcefailuresremainclearlyfailed. CurrentLibrarysmallworks;needfinishlargefilesdelivery.

TODO: finish19powerreplays andaffectedgeometrythermalground; exactsourceinputR122309kR123100k ref1.181..1.218→4.908 nominal;explicitenergybudgetwith68n. RegenerateFINAL_EVIDENCE;fixallpremature/narrowrangeREADME,DESIGN,QUALIFICATION,registers,effectivity,MANUFACTURING,PRODUCT_HANDOFFstillI29,REPLAY_COMMANDSmissing. Keep112.8829809Cphysicaltrigger/fixed2.940859375W/I25/65Cabin85U201air60accessory. Completebuilderguards135/currenthash alreadychanged;runbuildandvalidate/sourcevisualfinalPDF. Fullrecordarchives+newoutputs saveLibrary inpartsifnecessary,indexallidentities; finalartifactsize~50MBlikelysaveworks. RecheckremoteHEAD;commitreviewedscopedchanges+evidence andnonforcepushPR46. DoNOTstopatcheckpoint.

Earlierexecutiondetailsbelow(usecurrentstatesabove):

# I32 current execution state — 2026-09-14

Authorized: finish targeted I32 product engineering and nonforce push existing PR46 branch; no merge/order/hardware/deployment/credentials. HEAD4c3e54395e84483298e453468a65ff2646e9de4e, branch codex/rvb24-coordinated-closure. No commit/push yet.

CRITICAL OPEN: U121 fitted309k/100k divider and1.2V reference gives4.908V nominal, not old model5.0. Corrected retained4.75..5.25V interface exposes real cold750mA startup SNS cycling. Native177 CAD remains56aa12528c6ee873235d2a1cabd6f6c738800f3424a57ef5b87702b930f36ab7, fill eba2d2ca0c585c4de1cd06638ccf0247740c3a43fcc8c4fe94ae2e1cb6d4e641. native_i32_final zero ERC/DRC/unconnected/parity,177STEP/134inputs; all31+2+1 older narrow-voltage power results are superseded for acceptance. New power_voltage_bound_final34completed attempts: cold750min/max abort, allstorage has2SNS retries; rest complete. Ngspice47 same2aborts, not numerical-validation closure. Longer C1651u PG delay alone also fails same cold cases;2inputcaps+doubleCT alone fails. No proposed repair adopted to CAD yet. Findings registers reopened; README/final evidence/effectivity/handoff drafts still need correction after repair.

Current selected177 design: U152TPS22953 isolated input,1xC162470u10V,C15933nC0G; SNS6.34k/1k,EN4.7k/1k; C165220n,47kPGpullup,330k/330kactualU151EN divider. Q152/Q153/R1654.7ohmHP1.5W active source discharge; R1644.7k. U153TPS22953 switches C206680u6.3V viaR158.30ohm;C16633n,C1671u,bulkEN3.01k/1k,R1681k. U151FB11.8k/5.05k precision. R204100kCT-toVDD gives180..420ms reset. InputR10112.1k1W,D101S5J600V,D105SMCJ110A. All exactparts/CAD inSOURCE_AUDIT andsource. R168finalB86.35,2.

Completed geometry same177 PCB: layout_i32 80paths7views,filled_i3223groundconnections; ground_i32 main11.2818mohm<15,bulk10.9190mohm<11 (tight.081mohm); mechanical_controlled_final3PASS1308populated+529mated/38probes/full1.71mm/nearestR408.120mm. Latestnative schematic note moved awayfromQ152; noPCBchange. Thermal new5.25 inputheat thermal_voltage_bound_final_0.5/.25 complete, mustinspectaggregate. Retain fixed2.940859375W and physical112.8829809C correlationtrigger even ifnewmodelhigher.65Cbulk/85CU201air/60C851restriction unchanged.49VIP/70-30umstackup/.6-.3ordinaryviasunchanged.

Input stress17complete+1incomplete valid:input_selected_final11+input_controlled_final5+input_unloaded_repeat1. Q101VDS130.493V,SOAutility.52235;D101277.609V,10.353A vs600V/100A8.3ms. 0.75A in last6 isatU121INPUTVIN5, not5Vout. Definedharness pulsesnoOEM/ISOclaim. Ratings andlayoutdocs exist.

13Full_Records ZIPs deliverables~8.8GB,530rawrecords572experimentdirs; verifiedgzip/archives before rawdeletion. Newvoltage/alternativesNOTarchivedyet. preserve_runs.py --move-raw-after-verify AFTERallrunscomplete; preserveaborts/rejectedvariants. Libraryhelperbatch NOT RUN,manufacturingZIP NOTBUILT. build_i32_package.py strictguards177/134sourceand34+17 cases needupdateifrepair changesCAD. PRODUCT_HANDOFFstillI29 needsfinalI32. FINAL_EVIDENCE/POWER_RESULTS/THERMAL_RESULTS latestsuccessful versionsoldvoltage; history/PRE_U121_VOLTAGE_BOUND_*preserved.

Next: analyze firstSNSfall/currentenergy, choose causal boundedrepair, simulate affectedcold/off/load cases, adopt exactCAD/BOM/route ifjustified, regenerate native/affectedlayoutgroundthermalmechanicshashes andfullfinalpower. Correct allprematurepassdocs/registers,build/verifyhand-off,archiveallraw,saveartifacts,checkremote,pushnonforcebranch. Mustcontinue to noactionabledigitalwork.

Runtime: KiCad9.0.9 from /workspace/scratch/a2f5ff859ded/kicad9-runtime (PYTHONPATH usr/lib/python3/dist-packages, LD_LIBRARY_PATH usr/lib/x86_64-linux-gnu);never system10. Thermal PYTHONPATH thermal_runtime+OPENBLAS_NUM_THREADS1. Mechanicalengineering_runtime. PYTHONDONTWRITEBYTECODE1 forrepoimports. Freshwritefiles notcopy2 duefilesystemsync. Restoredduplicateraw/partialZIPs onlydeleteifverifiedagainstcompletearchive;disklimited. Noagentsauthorized.

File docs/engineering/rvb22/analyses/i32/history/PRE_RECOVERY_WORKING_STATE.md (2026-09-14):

# I32 delivery state

All four requested engineering areas have final source-bound digital dispositions. The 68 nF C166 repair resolves the real 4.75 V/cold 750 mA startup collapse under the declared bounded model, without changing controller gains, load limits or SNS thresholds. Final authored PCB45a2a679d9893d51fa641e539af45bc6ec1324169ea5f2226ecdea0ae2464da7; filled249d7b584af71605ee160c1ff425fda16a11b3ba93458bb243a722214c66ab30.

Completed: native KiCad9.0.9 zero ERC/DRC/unconnected/parity/exclusions,177STEP,135CADinputs,13postconditions; source audit preserves32firmwareinputs and49specialvias. Final34powercases and17inputcases are linked to exact full records in evidence/ACCEPTED_RECORDS.json. Power main3.13255965..3.57139192V; reverse−0.06700589V. Layout80paths/7views,23filled-groundpairs; ground11.28179/10.91904mohm within15/11mohm allocations. Mechanics1837checks/38probes,full1.71mm,nohits. Thermal finaltwo meshes/three vectors: same-budget board screen113.220731C; original112.8829809018675C physical trigger unchanged. Fixed2.940859375W; U12183.3396% required atU15180%/maxleakage. Physical/supplier gates are unperformed.

The 19 full-record ZIP containers retain622positive-size waveforms and one invalid zero-byte historical artifact from664experiment directories. All split parts and their original combined hashes were verified; the restore entry point reconstructed container16 and passed exact SHA/ZIP CRC. All42distribution files plus the distribution JSON have been saved. Exact compact records and source evidence are in Git. Older61-case I31 fullZIP and newer132-case summary-only remain distinct. Historical/narrow-voltage selected labels do not override current ACCEPTED_RECORDS.

Current product/manufacturing handoffs, findings, effectivity, replay commands and C166 bibliography are complete. The strict I32 package builder validates native_c166_68n_release and exact reuse of the prior firmware inputs/images. Its separate build report records the final package hash without self-reference. PR46 remains the existing draft branch; the Git commit containing this delivery and the final completion record identify the revision. No merge, order, hardware, firmware operation or messages are authorized. Intermediate execution details and rejected decisions are preserved in history/INTERMEDIATE_WORKING_STATE.md. Do not restart the completed analysis or promote historical selected labels to current evidence.

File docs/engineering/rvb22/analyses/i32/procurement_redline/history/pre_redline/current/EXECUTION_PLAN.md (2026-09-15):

# I22 closure plan and current source

This iteration starts at I21 commit `550d87fea69147e131fd71603d02204a44c903f1` on PR #45. The user confirmed Adafruit 851 and 960 and requested another iteration. The complete I21 redline/criterion state was frozen before the checks. I22 corrects the accessory model, adds the omitted mechanical height allowance, completes independent package overlays and bounded via/RF reviews, and reevaluates all 290 original criteria. It closes six: LIB-02, LIB-08, VIA-06, SI-12, GPS-01 and MECH-03. Counts become 140 closed, 146 open and four not applicable. All 357 recorded redline identities remain visible; that history count is not the count of open criteria.

Confirmed inputs are Honeywell MIPAN2XX150PSAAX, the GR86 ASC harness per Timurrr, Adafruit 851/960, JLCPCB fabrication and dashboard use. Equivalent numerical power/RF/thermal models and circuit, firmware, mechanical and assembly corrections are authorized. The unchanged design case is 4.815 W, 65°C bulk air, 70°C landings and 70 kPa. No engine-bay environment or reduced dashboard requirement is introduced.

| Workstream | I22 result | Next closure action |
|---|---|---|
| Native CAD and target build | Verified I20 source remains current, with zero native findings and 153 resolved models. I22 does not change CAD or firmware. | Rerun the pinned native workflow after any CAD/firmware change and bind the resulting exports. |
| Package orientation and exposed pads | 12 manufacturer top/bottom overlays, 151 signal lands, all 20 GPS pad functions and 12 wrong-orientation negative controls pass. Exact exposed-pad net/mask/thermal construction reviewed. | Retain alternative-land and stencil conditions; obtain the original independent human drawing review under DRW-03. |
| Mechanical model and assembly | Full 1.71 mm height stack replaces 1.20 mm; 1,154 populated and 776 mated checks pass. Smallest separation is 0.120 mm at R408/T03. Cable uses 150 ±3 mm and a 2.0 mm OD receiving envelope. | Verify exact supplied plug dimensions, carrier/foil materials, retention and installed construction. Recheck every cooling revision against these bounds. |
| Via current and drilling | All 322 vias pass the conditional 2 A self-heating screen, maximum 5.103 K against 10 K. Nominal drills agree with native exports. | Resolve exact finished-hole/pin/hardware fit, drawing/DFM agreement and supplier minimum wall/fill/cap conditions. |
| Board RF and digital returns | Analysis-only SI-12 scope is justified by the existing 3,981,312-case board network, minimum 10.219 dB return loss and maximum 0.867 dB insertion loss. All 12 RF segments retain adjacent ground. | Keep actual stack/device allocations, antenna/bias and installed GPS criteria separate. Bound or reroute the 54 digital adjacent-plane interruptions; alternate ground presence alone is insufficient. |
| Accessory interface | User-confirmed 851/960 pair; typical 3.3 V current is 9.8 mA. Exact module detection and current-limit applicability reviewed. | Verify delivered bias voltage, hot/cold current, faults, miniature-plug dimensions and standard-SMA center contacts. |
| Thermal | Fine model remains 143.800°C maximum board region and mesh-sensitive. A 60°C-rated 851 cannot meet 65°C passive boundaries. | Resolve package/local-air data, mesh/topology bounds and a realizable cooling path. Settle accessory rating or verified installation environment; passive contact improvements cannot close that 5 K rating conflict. |
| Remaining original review | All criteria retain their original questions and evidence requirements. WCA-07 still lacks a guaranteed hot/low-current optical bound. | Advance the remaining design calculations, then supplier, independent-review and physical acceptance items according to their actual scope. |

For every subsequent iteration, freeze all open criteria and every newly observed redline. Record a disposition for each finding, including the correction, evidence or exact unmet condition. Select one coordinated revision only after reviewing its power, RF, thermal, populated clearance, materials and service effects together. Regenerate all affected native/model outputs, compare every original criterion with the exact candidate, preserve failed trials and repeat. A combined finding remains open when one of its constituent requirements remains unresolved.

The next board-changing iteration should address thermal paths and digital returns together. Preserve full load/environment bounds until an enforceable alternative is designed and verified. Evaluate candidate heat paths against the ESP32 antenna region, J401 cable, C206 tab, insulation and full 1.71 mm height stack before promoting the geometry. Reconcile current package boundaries before presenting board-region temperatures as device margins.

Physical unit, supplier-process, installed harness/ground, phone/vehicle, material lifetime and environmental requirements remain explicit in the register. PR #45 is the authorized forwarding destination. Fabrication, merge, flashing and live vehicle actions are outside this iteration.

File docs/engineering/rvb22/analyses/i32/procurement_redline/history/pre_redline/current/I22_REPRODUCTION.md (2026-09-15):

# Reproduce the I22 review

Run model scripts from the complete recovery root. They use the archived native
I20 filled PCB, placement CSV, mechanical source and `runtime/local` /
`runtime/vendor` dependencies. The repository contains selected inputs/results;
it is not a substitute for the complete numerical recovery archive.

```sh
python3 analyses/review_i22/package_audit.py
python3 analyses/mated_i22/check_mated.py
python3 analyses/review_i22/mechanical_audit.py
python3 analyses/review_i22/electrical_audit.py
python3 control/build_i22_documents.py
python3 control/verify_i22_iteration.py . --repository /path/to/gr86-cca-telemetry/docs/engineering/rvb22
python3 control/build_i22_review.py .
```

The package audit compares independently transcribed manufacturer drawings with
native placement and actual pads. The mated check must run before the populated
mechanical audit, which uses its 153 height rows. The electrical audit reads the
retained finite RF and thermal outputs; it does not rerun those large sweeps or
claim a new thermal mesh solution. Keep all source PDF hashes and model
allocations with any rerun.

The workbook builder `control/build_i22_workbook.mjs` uses Artifact Tool. Set
`RVB22_RECOVERY`, `RVB22_WORKBOOK_INPUT` and `RVB22_OUTPUT_DIR` explicitly.
The input is the preserved I21 workbook version 6, not the earlier user baseline.
It updates the original register's G–J and N columns and the current RVB22 views,
preserving A–F and K–M. It recalculates counts, checks a temporary status change,
restores it, checks formula errors and exports the workbook. Run
`control/verify_i21_workbook.py` with the input workbook, exported workbook,
current JSON register and output audit path to compare the saved XLSX contents.

Regenerating a drawing can change SVG metadata. After any affected evidence is
regenerated, rerun source verification and register/workbook consolidation so
that their hashes describe the delivered bytes. The register builder hashes
dependent current gate/action files after writing them.

I22 leaves CAD, firmware, C05/W02/T03 solids and the TranquilWorks logo unchanged.
An actual CAD/firmware revision requires the pinned native workflow and new
source/output binding before its evidence supersedes I20. Current electrical
source has zero native findings; thermal, supplier, physical and independent
human acceptance remain as recorded in the register.

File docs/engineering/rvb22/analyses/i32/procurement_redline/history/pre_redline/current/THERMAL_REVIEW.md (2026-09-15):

# Current checkpoint: convergence 01

See `analyses/convergence_01/README.md` relative to the rvb22 root and `current/CONVERGENCE_01_EFFECTIVITY.json`. The former 6.5/7 mm exposed-shoe whole-path selection is withdrawn. New native-copper trial refinement gives 111.533 C board maximum at 0.25 mm; no thermal/mechanical acceptance or new PCB fabrication release is claimed. Earlier numerical statements below retain their historical configuration and scope.

## Historical review

# I22 thermal applicability and retained I21 refinement

The 0.125 mm four-layer finite-volume solve was completed in I21. I22 retains that result.  It uses actual I18 native copper, with geometric equivalence to I20 established in `SOURCE_EFFECTIVITY.json`. No power, environment, conductivity, contact area or plating assumption was relaxed. Total dissipated power is 4.815 W; bulk air is 65°C at 70 kPa; cold landings are 70°C; minimum plated wall is 15 µm. Copper conductivity is 300 W/m·K and FR4 is 0.25 W/m·K. The declared carrier shadow, contact and natural convection/radiation terms remain active.

| Mesh (mm) | Maximum board region (°C) | C206 region maximum (°C) | U201 source-region mean (°C) | U121 source-region mean (°C) |
|---:|---:|---:|---:|---:|
| 0.500 | 125.820 | 99.190 | 123.659 | 107.360 |
| 0.250 | 135.424 | 102.642 | 132.913 | 113.485 |
| 0.125 | 143.800 | 105.171 | 141.354 | 124.463 |

The last solve has 1,199,572 thermal nodes. It converged in four nonlinear iterations, with all linear solver status codes zero, maximum nodal residual 4.23×10⁻¹⁵ W and whole-board energy residual below 8.0×10⁻¹¹ W. Heat flows are 3.459691 W to the landings and 1.355309 W to air. The via-barrel area capture is 99.98995%. These checks establish numerical solution of the discrete network, not convergence to the physical continuum.

Mesh dependence remains material: refining from 0.25 to 0.125 mm raises the maximum by 8.376°C, U121 mean by 10.977°C and C206 maximum by 2.529°C. The previous C206 relocation improves its region temperature, but its remaining 19.829°C distance to 125°C is not a guaranteed package/self-heating margin. No Richardson extrapolation is credited because asymptotic order is not established and topology changes as narrow copper features resolve. The model still has 3,016 cells containing more than one copper polygon. A near-zero algebraic residual cannot erase that approximation.

The source allocations put all 2.58225 W of the MCU allowance into its board exposed-pad region and scale all heat terms from 4.79 to 4.815 W. This is not a validated internal ESP32 module network. Its board result cannot be called a die, shield or local-air temperature. The exact N8R2 module's 85°C ambient rating refers to air immediately outside the module, not a universal 85°C board or case limit. Conversely, setting bulk air to 65°C does not establish that local ambient stays below 85°C in the installed dashboard.

The [Espressif module datasheet](https://www.espressif.com/sites/default/files/documentation/esp32-s3-wroom-1_wroom-1u_datasheet_en.pdf) provides the operating ambient range but no application-specific module-to-shield/board network. Typical BLE current measured at 25°C cannot replace the full sustained heat allocation with a guaranteed hot-current bound. The [LM5164 datasheet](https://www.ti.com/lit/ds/symlink/lm5164.pdf) supplies package thermal metrics for the exact non-Q1 U121; those metrics require the appropriate package boundary and are not universal board-level thermal resistances. The original thermal criterion REG-02 remains open after its I21 reopening.

An additional optimistic boundary comparison is complete in `analyses/thermal_i21/EXISTING_CONTACT_FEASIBILITY.json`. It uses 0.01 K/W at each existing contact while preserving copper, load, air and landing temperature. On the same 0.25 mm mesh, maximum board temperature falls from 135.424°C to 118.656°C, a 16.768°C reduction. This shows that the interfaces matter, but there is still substantial temperature rise through the board even with nearly ideal contacts. The 0.01 K/W values are not an achievable material specification or a manufacturing change. This comparison has the same mesh/package limits as the main model and is not adopted as cooling credit.

Full thermal closure needs a reliable mesh/topology bound, exact package and local-air applicability, and a realizable cooling path whose material/contact/landing assumptions are met. The current candidate is not represented as thermally qualified or ready for unrestricted manufacture.

I22 confirms the selected adapter as Adafruit 851. Its linked specification limits operation to 60°C. For the declared passive steady-state system, all thermal boundaries are at least 65°C and heat generation is nonnegative. A global temperature below every boundary would require outward heat flow of the wrong sign. Therefore passive contact/spreader improvements alone cannot produce a ≤60°C adapter at this design case, even with zero board power. The minimum boundary conflict is 5 K. This does not establish actual installed air temperature and does not authorize reducing the environment requirement.

The exact J401 footprint region was sampled from the preserved 0.125 mm map: 92.438–94.443°C on the bottom board layer. Those values are not cable, plug or socket temperatures. `analyses/review_i22/THERMAL_ACCESSORY_BOUND.json` binds the extraction to the map hash and records its scope. A verified compatible accessory rating or installation temperature is needed in addition to board/package cooling work. No new thermal mesh or physical cooling revision is claimed in I22.

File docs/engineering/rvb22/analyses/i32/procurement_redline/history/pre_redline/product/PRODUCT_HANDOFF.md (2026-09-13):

# GR86 / BRZ telemetry Rev B — product handoff

## What this package is

A source-bound **PCBA quotation, assembly-planning and first-article package**, not an assertion that an installed product has been physically qualified. It collects the actual board, firmware, manufacturing outputs and construction conditions in one place. Waiting for another CI run is not a prerequisite for using this handoff.

The controlling product source is PR #46, branch `codex/rvb24-coordinated-closure`. The reviewed handoff parent is `296a86495ae665c8a377be777a413a2c1d4baa73`. Authored PCB SHA-256 is `a04f42b358fa65a332128115a7b648e1a2297531ecb47466ac24697de536a936`.

The matched native export was generated from commit `1aa1b2e880d94e36a8017087241ed954d2aa4f3f`. Its 101 CAD inputs and 32 firmware inputs match the current product files byte-for-byte. This is reuse of an already executed native build, not a claim that KiCad or the target compiler ran again during packaging. Every retained native output is checked against its archived byte count and SHA-256. The native result records zero ERC/DRC findings, 153 fitted component models, and actual target firmware images.

## Start with the right files

`fabrication/JLCPCB_GERBERS.zip` contains the copper, mask, paste, silkscreen, board outline and separate plated/nonplated drill files. `assembly/JLCPCB_BOM.csv` and `assembly/JLCPCB_CPL.csv` are the 151-part automatic-placement set; the CPL preserves native side, datum and rotation rather than applying guessed vendor rotation offsets.

`assembly/COMPLETE_FITTED_BOM.csv` is the full 153-part inventory. `assembly/LOCAL_ASSEMBLY_BOM.csv` explicitly retains F101 and U401; they are not DNP components. `assembly/DO_NOT_POPULATE.json` freezes C203, R301 and R306 as DNP. The native schematic, populated STEP, IPC-D-356 netlist, editable KiCad files and firmware source/images are included separately.

**This is not yet a one-click, fully sourced PCBA order.** Fourteen automatic-placement references have exact manufacturer part numbers but no assigned LCSC code in the controlled source. They are listed in `assembly/SOURCING_REQUIRED.csv`, not silently substituted or omitted. Arrange exact-part sourcing/consignment with the assembler before order approval. The separate manual GPS module also has no LCSC allocation. Existing LCSC codes are identifiers, not a claim of live stock or supplier acceptance.

## Product variant and operating intent

The board is the receive-only 500 kbit/s CAN variant, with R301 open, R303 fitted as the recessive TXD pull-up, no transmit API/queue, and R306 unpopulated on the vehicle bus. Do not convert it into an active CAN transmitter or add termination without a separate review.

The firmware selects the PA1616D GPS-only configuration, 115200 baud, 10 Hz, and the selected external GPS L1 antenna. Acknowledgment/readback and actual solution cadence are checked; a sent configuration command is not treated as proof of acceptance. The oil path supports the named Honeywell MIPAN2XX150PSAAX 150 psi sealed-gauge, 5 V ratiometric sensor. Calibration is against known pressure and measured excitation, not an assumed key-on zero. The source programming/calibration guide controls the procedure.

The adopted thermal operating profile remains 160 MHz, BLE +3 dBm, no Wi-Fi, at most 120 notifications/s, a 0.45 A sustained main-profile allocation and at least 80% converter efficiency or the recorded loss alternative. The adopted heat allocation is 2.940859375 W. Earlier approximately 4.8 W cases remain stress sensitivities, not the release steady-state source. The current main-rail parts are R155 11.8 kohm / R156 4.99 kohm TNPU, R153 10 milliohm, R158 82 milliohm and C206 T598X477M006ATE025. U121 is **LM5164QDDARQ1 / C2072225**, not LM5164DDAR.

Deep 6 V crank is intentionally an undervoltage shutdown/restart case, not guaranteed uninterrupted telemetry. The input protector and Q101 provide isolation; the downstream buck is not credited with absorbing unsuppressed load dump directly.

## Manufacturing and assembly conditions

Use the authored four-layer stackup in `fabrication/AUTHORED_STACKUP.json`: 70 micrometre outer copper, 30 micrometre inner copper, specified FR4 dielectric layers and ENIG. Have the supplier confirm the actual stackup rather than choosing an unreviewed standard substitution.

There are **49 required filled, capped and planarized via locations**: 48 under U201 pad 41 and one at R153 pad 2. Their current PCB coordinates, UUIDs, drill and land sizes are in `fabrication/FILL_CAP_PLANARIZE_49_VIAS.csv`. Tenting is not equivalent. The 15 micrometre minimum finished plated wall is a construction condition; an average-wall specification does not prove it.

F101 is the Littelfuse 0885001.DR fuse. It must receive the separately qualified **local, post-reflow solder process**, not global paste/PnP. U401 is the manual GPS assembly. Preserve the native pin-one and polarity orientation, local soldering access, exposed-pad stencil treatment and source-defined isolated returns. Use the supplier's final placement preview to reconcile its zero-degree conventions; do not rotate parts by guessing.

The current mechanical source is C05/W02/T03 in `mechanics/current_C05_W02_T03/`. C02 additional cooling and the I24 trial geometry are not adopted. The existing flexure construction is 200 unbonded C110 laminae per flex member, 0.010–0.011 mm each, bonded at terminals only. Do not replace this with a solid bonded packet. The historical I22 manufacturing document is provided for detailed retained construction instructions; its old PCB hashes, old source locations and superseded thermal-state paragraphs are not the current electrical or thermal authority. I25 governs the adopted thermal profile.

## What remains outside desktop completion

The 290-row I27 register distinguishes 141 source/documentary dispositions, 31 conditional-model dispositions, 114 hardware/supplier/installation acceptances and four not-applicable rows. Its zero actionable desktop count **does not mean 290 physically passed requirements**.

Before approving fabrication, resolve exact-part sourcing, the supplier's actual stackup/plating/via-fill process, and its final assembly preview. No order, supplier approval, programming, bench energization or vehicle test was performed by this handoff.

Before use, execute the retained input protection, rail transient/reset, current/efficiency, GPS/antenna, oil calibration/fault, BLE/RaceChrono, CAN non-interference and mechanical/thermal checks. I26 qualification gates provide numerical limits and uncertainty rules. The 112.883 C thermal screening value is a board-region model allowance, not semiconductor junction temperature; immediate air at U201 must remain within its 85 C limit.

**The Adafruit 851 adapter is rated for a 60 C local environment, below the 65 C bulk-air design case.** Its installed thermal environment must be kept within 60 C, or a correctly rated equivalent must be approved. A chamber measurement cannot waive the manufacturer's rating. Do not treat this as an unrestricted 65 C-rated finished assembly.

I28's power arithmetic and acquired TI model files are not full-board vendor-macromodel SPICE validation. The model execution findings in `SPICE_EXECUTION.md` state exactly what ran and what did not. The encrypted LM63615-Q1 model and full coupled-power transient/corner correlation remain unverified; no idealized substitute is silently promoted to a vendor-model pass.

## Reproduce this package

From the repository checkout matching the controlled source:

```sh
python docs/engineering/rvb22/product/build_package.py \
  --native-zip /path/to/native-sync-i28.zip \
  --output /path/to/GR86_RevB_I29_Quote_And_Build_Package.zip
```

The builder performs local integrity/population checks, rejects a mismatched native archive or changed source, and refuses to overwrite an existing output. It does not poll CI, push branches, place orders or operate hardware. `PACKAGE_VERIFICATION.json` records the actual result, and `SHA256SUMS.json` covers every other package member. The PR remains unmerged; this publication does not alter `main`.

Supplier file-format references: JLCPCB's official *Pick & Place File for PCB Assembly* and *How To Export BOM and Pick & Place Files From KiCad* articles, reviewed September 12, 2026. Model references: TI's LM5164-Q1 and LM63615-Q1 official product/model pages. Their URLs are retained in `SOURCES.json`.

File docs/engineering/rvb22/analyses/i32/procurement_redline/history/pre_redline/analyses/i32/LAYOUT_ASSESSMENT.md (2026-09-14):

# I32 power placement and copper assessment

The source PCB is `45a2a679d9893d51fa641e539af45bc6ec1324169ea5f2226ecdea0ae2464da7`; native filled PCB is `249d7b584af71605ee160c1ff425fda16a11b3ba93458bb243a722214c66ab30`. `evidence/layout/LAYOUT_MEASUREMENTS.json` records 80 pad pairs with actual coordinates, layer sets, track/via UUIDs, neck widths and routed distances. Seven annotated views accompany it. Twenty-three ground pairs are separately connected through actual native fill in `evidence/filled_returns/`. An explicit-route graph reporting “zone return required” is not an open circuit when that filled-ground check passes.

Distances below are centerline lengths **outside pad/via regions**, not center-to-center placement distances. Calculated resistance uses 150 C copper, 50 um outer /24 um inner thickness and 0.06 mm total width loss. Pad spreading and barrels are added separately where they affect the power model. These are engineering bounds and geometric measurements, not field extraction.

| Path | Routed length mm | Minimum width mm | Vias | Assessment |
|---|---:|---:|---:|---|
| U121 C123 to VIN | 0.051 | 0.40 | 1 land encountered; no layer transition | Retain local input bypass. Pad-edge gap0.650 mm. |
| U121 C123 to PGND / EP | 1.306 /1.756 | 0.60 | 0 | Direct front copper plus confirmed filled return. |
| U121 bootstrap BST /SW | 0.650 /0.655 | 0.30 /0.70 | 0 | Local loop retained. |
| U121 SW to L121 | 4.625 | 0.70 | 0 | Front only. |
| L121 to C127 | 13.875 | 1.20 | 0 | Wide output path; filled return confirmed. |
| U121 FB upper /lower | 3.058 /1.932 | 0.20 | 0 | Divider beside FB, away from inductor switching land. |
| U151 C152 to VIN13 /PGND15 | 0.876 /0.876 | 0.35 | 0 | Both pad-edge gaps0.875 mm; nearest adjacent power pins meet the published1 mm placement recommendation. |
| U151 C152 to VIN12 /PGND16 | 1.300 /1.300 | 0.35 | 0 | Additional package power pins share the adjacent local connection; no claim that all pad centers lie within1 mm. |
| U151 VCC /BOOT /SW bootstrap | 1.203 /0.627 /0.772 | 0.20 /0.25 /0.35 | 0 | Local back copper retained; VCC ground verified through fill. |
| U151 SW to L151 /L151 to C155 | 2.784 /3.741 | 0.35 /1.00 | 0 | Compact switching connection, wider output copper. |
| U151 FB upper /lower /quiet return | 4.695 /2.345 /2.125 | 0.15 /0.15 /0.25 | 0 | Lower divider returns to AGND; output sense remains before R153. |
| C157 to R155 source sense | 20.180 | 0.15 | 3 | High impedance source-sense route, not a remote main-rail sense. |
| R153 output to U201 | 58.949 | 0.60 | 3 | 41.537 milliohm track contribution; main-loop allocation75 milliohm includes return. |
| U201 to U153 input | 62.089 | 0.20 | 5 | 65.278 milliohm track contribution; final branch model includes this route. |
| U153 output to R158 /R158 to C206 | 2.140 /1.615 | 0.60 /0.80 | 0 /1 | 3.012 milliohm combined tracks; controlled bulk charging, not the converter's high-frequency input loop. |
| C162 to C151 | 27.193 | 0.30 | 3 | 34.114 milliohm tracks; local C151/C152 supply the switching loop. |
| U152 CT /U153 CT | 2.781 /6.686 | 0.15 | 0 | C0G capacitors on their controller side; actual ground fill verified. |
| U152 PG to R166 /R166 to actual EN | 50.418 /36.627 | 0.15 | 2 /2 | Slow, filtered signals; PG and actual EN are separate nets. |
| U152 PG to Q153 | 102.973 | 0.15 | 2 | 1.200 ohm track estimate versus47 kohm pull-up; length is explicitly modeled as a slow control connection. |
| U202 CT to R204 | 11.579 | 0.15 | 2 | 100 kohm timing selection; two ordinary0.6/0.3 mm vias. |
| C157 source to R165 | 35.203 | 0.20 | 3 | 117.514 milliohm tracks; supplementary shutdown case includes150 milliohm total lead/return allowance. |
| D101 to added D105 clamp | 25.756 | 0.60 | 2 | 36.494 milliohm tracks;60 milliohm lead allocation and30/100/300 nH sensitivities retained. |
| U101 gate output to R106 /R106 to Q101 | 3.030 /2.948 | 0.20 | 0 /1 | Gate stopper and source-referenced clamp retained. |
| D104 to Q101 gate /source | 1.532 /3.383 | 0.30 /0.80 | 0 | Gate/source clamp loop remains local. |

The U151 external bypass loop's four pad-center vertices are VIN13(37.8625,13.325), C152+(40,13.2), C152−(40,14.75), PGND15(37.8625,14.625) mm. Its projected quadrilateral is3.046 mm². U121's corresponding VIN(44.3,25.865), C123+(42.15,25.75), C123−(42.15,23.85), PGND(44.3,24.595) gives3.408 mm². These quantify the external geometry; neither includes the unknown die/bond-wire path or claims an inductance extraction.

U151 switch copper is9.836 mm² on B.Cu only; the nearest same-layer sensitive copper is its FB pin,5.511 mm away. U121 switch copper is28.784 mm² on F.Cu only; its nearest sensitive item is the package's FB pin,1.055 mm away. The practical larger U121 land accommodates the selected12 mm inductor and bootstrap. No SW copper is routed through the GPS keepout or inner layers. The quiet feedback networks are on the opposite side of their power packages from SW. Compare the supplied views with TI's **correct HTSSOP16 LM63615** and **DDA LM5164** examples; the different WSON pin layout is not substituted. These dimensions do not certify EMI or switch-node ringing.

The R153 source/main test-point routes share power copper and are31.670 /55.736 mm respectively. They are **not a four-terminal Kelvin measurement**. Measure across R153's actual pads for small-current inference and measure main voltage differentially at the load's own ground. Remote test-point differences include power-route voltage drop. The added ground via at(38.6,21.6), with1.091 mm of0.6 mm back copper from C157's return, improves the source ground connection while retaining the original via(37.675,24).

The restricted In1 ground calculation uses complete copper cells, all via/PTH/NPTH bores, two meshes0.100/0.075 mm,15 um minimum barrel plating,150 C resistivity and10% numerical/spreading inflation. It obtains11.282 milliohm source-to-load against15 milliohm allocated; C206-to-load is10.919 milliohm against11 milliohm allocated. The latter has only0.081 milliohm residual allocation margin; it already includes the stated inflation and is a conditional numerical screen, not an exact continuum bound. Other parallel ground layers receive no resistance credit.

The final bulk-branch110 milliohm allocation includes65.278 milliohm positive routing,3.012 milliohm local output tracks, six full-length0.3 mm barrels at15 um plating (about16.84 milliohm),11 milliohm ground spreading and3 milliohm pad spreading: about99.1 milliohm total. R158 and U153 on-resistance are additional model elements. The200 nH branch and300 nH main/input-feed inductances are explicit engineering allocations. The previously used65 milliohm/100 nH branch model is superseded. The final power suite uses110 milliohm/200 nH and20 pF on actual EN.

I32 adds41 ordinary vias and removes four obsolete vias; all new ordinary vias are at least0.6 mm land/0.3 mm drill. The49 required filled/capped/planarized via identities remain unchanged. Source rules and stackup are unchanged. Rule areas retain their layer/permission sets; native nanometre coordinate quantization and removal of redundant polygon vertices are measured in `SOURCE_AUDIT.json`. They are not treated as a new keepout shape. Fitted CAN/GPS/oil/RF signal copper and firmware contracts remain preserved.

Disposition: retain the U121/U151 high-frequency placements, local bootstrap/VCC and feedback topology; adopt the input isolation, discharge, reservoir and reset routes, the improved C157 ground access, and corrected silk/probe legends. Native ERC/DRC/parity/connectivity are all zero. CT/supervisor noise, switch-node overshoot and conducted/radiated behavior remain measured acceptance gates after these digital inspections.

Primary layout sources: [TI LM63615-Q1](https://www.ti.com/lit/ds/symlink/lm63615-q1.pdf), June2026, pin table and§8.5; [TI LM5164-Q1](https://www.ti.com/lit/ds/symlink/lm5164-q1.pdf), layout guidance and DDA example; [TI TPS22953-Q1](https://www.ti.com/lit/ds/symlink/tps22953-q1.pdf), DQC package/layout and CT guidance.

C166 is the final 68 nF TDK CGA5L1C0G2A683J160AE at B.Cu (85.85, −3.0) mm, 90°. The 3.60 ×1.90 ×1.90 mm maximum body, supplied land pattern and STEP replace the earlier 33 nF envelope. The CT tail reaches pad1 at (85.85, −1.35); the ground trace starts at pad2 (85.85, −4.65). Copper-to-edge clearance is 0.30 mm; maximum-body clearance to the nominal tab edge is 0.10 mm. Confirm placement/edge tolerance and installed fit with the supplier and first article. The initial (86.05, −3.0) trial failed native edge clearance and was corrected before the final run.

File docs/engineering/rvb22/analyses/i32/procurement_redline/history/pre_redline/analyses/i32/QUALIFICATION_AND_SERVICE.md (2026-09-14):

# I32 qualification and service conditions

No hardware, vehicle connection, programming, supplier approval or physical test was performed. These are deterministic first-article acceptance instructions. Retained I26 oil, GPS, RF, CAN, installation and mechanical criteria continue to apply. The uncertainty rule is unchanged: a measured value plus its relevant uncertainty must stay inside an upper limit; subtract uncertainty for a lower limit. Model assumptions are not measurement tolerances.

| Gate | Setup and acceptance |
|---|---|
| Cold start and boot | At the defined normal input corners, including the retained4.75–5.25 V upstream interface, and component/temperature samples, record upstream5 V, isolated VIN, source3.3 V, main3.3 V at U201 ground, U152 PG, actual U151 EN, U153 CT/output, reset and both converter currents. Test no load,20 mA pre-reset,0.45 A boot/run and0.75 A from power-on. Exactly one reset release; no SNS retry or missing boot during normal startup. Confirm the pre-reset allocation independently; typical ESP32 EN-low current is not a hot maximum. |
| Load steps and release | Exercise0.45↔0.75 A and representative MCU/BLE loads with fast edges. After READY, main including ripple/uncertainty must remain above3.116050 V and at or below3.6 V, without unintended resets. Also record the source node separately. The derivative's16.51 mV lower and28.61 mV upper margins do not absorb unknown silicon dynamics automatically. |
| U151 reverse discharge | Test normal unplug, upstream UV/OV disconnect,10/100 ms reapplication, unequal auxiliary loads, and no externally imposed off-load. While source>0.3 V, isolated VIN minus source must remain≥−0.3 V, including differential-probe error. Correlate enabled bidirectional switch behavior, disabled reverse blocking, hot leakage and discharge transistor transfer behavior. Reset during an imposed supply fault is intentional; successful single recovery after a stable return is required. |
| Timing and startup dissipation | Verify C15933 nF at0.00876628–0.01461858 s/V and C16668 nF at0.01804688–0.03009768 s/V, the250 us allocated worst fault response, actual EN sequencing and reset delay180–420 ms. CT values extend TI's approximate formula beyond the10 nF table example; they are not guaranteed model constants. Confirm no U152/U153 thermal shutdown during worst storage charging or repeated recovery. |
| Input transient survival | Apply the exact source waveforms/R/L/repetition in `INPUT_PROTECTION.md`, including hot/cold clamp envelopes, on an isolated current-limited fixture. Simultaneously measure Q101 VDS/VGS/ID, controller VIN/UV/OV/SHDN/gate, D101 voltage/current, D102/D103/D105 clamp trajectories and downstream VIN5. Require Q101≤200 V and±20 V gate, D101≤600 V reverse, U101 per-pin limits, and the temperature-adjusted SOA/pulse bounds. No avalanche, latch-up, unintended fuse opening or permanent parameter drift is accepted. Functional UV/OV shutdown is expected; output-only measurements cannot prove component stress acceptance. |
| Short/fuse coordination | The LTC4367 voltage disconnect is not a current limiter. Confirm source fuse/wire protection, prospective fault current, ground-loss handling and clearing under the retained harness contract. Fuse nominal0.80 A²s is not a guaranteed clearing or pulse-survival limit. F101 local ambient≤105 C; apply its current-temperature/continuous derating. |
| Sustained power | Preserve160 MHz, BLE+3 dBm, Wi-Fi off,≤120 notifications/s, and sliding1 s/60 s main current≤0.45 A. Each converter must meet the retained≥80% condition or an approved partitioned measured-loss alternative. Additionally, actual total heat must remain within2.940859375 W. The worst leakage stack at exactly80% for both gives3.062582 W and is **not an accepted release state**. At U151 exactly80%, the same-budget calculation requires U121≥83.3396%; other efficiencies may be accepted only by a complete power-flow/heat calculation. Use simultaneous instantaneous V×I and avoid double-counting magnetic loss. |
| Hot soak and Rev A correlation | Use adopted C05/W02/T03, final enclosure/harness/orientation at65 C bulk cabin air. Immediate U201 air≤85 C; monitor shield, board hot region, U121/U151/U152/U153, both polymer capacitors, fuse, LED and cooling landings. Stabilize every monitored temperature at<0.1 C/min for30 consecutive minutes with zero unexpected resets/latch-ups. Continue the representative run long enough to cover the historical five-minute failure and final stabilization. A millisecond startup simulation does not prove that failure mechanism eliminated. |
| Thermal model correlation | The new actual-loss vector gives107.36427 C on0.25 mm mesh plus5.85646 C one-step allowance =113.22073 C board-region screen. The retained I25 heat vector on new copper gives113.39905 C similarly. Neither is mesh convergence, junction or immediate-air temperature. **The older112.88298 C physical correlation trigger remains in force**: exceeding it reopens correlation; I32 does not raise that acceptance trigger merely to pass. Actual loss/contact/air data must resolve the difference. C02 is not adopted. |
| Local component temperatures | TPS22953 conditional package calculations use51 K/W junction-to-board allocation (twice the typical metric), not a guaranteed maximum; confirm it or measure an adequate case/junction correlation. Both switches must remain below the130 C minimum thermal-shutdown onset during startup with margin. D102's allocated60 K/W junction-to-lead condition must be confirmed for the long dump. Keep polymer voltage≤60% rating at125 C, winding/package limits, the retained LED≤85 C local air /110 C junction limits, and all other source ratings. |
| Accessory and mechanics | Adafruit851 local environment≤60 C even during the65 C cabin test; relocation or an approved rated alternative is required if exceeded. Retain851+960 and PA1616D115200/10 Hz/PPS. Confirm C05/W02/T03 installed clearances,49 filled/capped vias and1.71 mm complete height stack. Native envelope minimum0.120 mm is not an installed fit measurement. |

The selected derivative can reasonably screen energy, tolerance and sequencing while its LM63615 equations remain approximate. The unmodified LM5164 isolated model ran; the older170-part closed vendor attempts aborted on both ngspice42 and47 before the requested end. They are retained failures, not177-part validation. The final first article must correlate these equations with silicon. Reopen component/copper/control choices on a failed gate; neither simulator convergence nor nominal parts justify waiving it.

## Power domains and safe service configuration

Normal source flow is R128→+5V→R151→U152→isolated3V3_VIN/C162→U151→3V3_SOURCE→R153→main+3V3. U153 connects the main to R158/C206 only when enabled. Q152/R165 drain the source on disable; R168 drains the isolated bulk capacitor. Selected TPS22953 has no QOD, so these discharge paths are intentional source components.

GPS has its own5 V-fed MIC5504 regulator. U402 is powered from main3V3 and buffers GPS TX/PPS toward the MCU; U404 is powered from GPS3V3 and buffers MCU TX/FIX toward GPS. Their SN74LVC2G125 Ioff behavior protects the opposite unpowered domain;220 ohm series parts and100 kohm pulls remain. The oil/excitation dividers use1 Mohm/4.02 kohm ahead of the main-powered OPA2333: ordinary5 V becomes about20 mV at the unpowered input, with limited current. Do not generalize this to arbitrary externally driven programmer or sensor fault voltages. [TI buffer power-off behavior](https://www.ti.com/lit/ds/symlink/sn74lvc2g125.pdf) supports the buffer-domain argument.

| Service configuration | Required isolation and verification |
|---|---|
| Normal12 V input | R128, R151 and R153 in the controlled fitted state. External programming voltage reference is sense-only; no second supply. |
| External5 V | Disconnect12 V and open R128 before applying the service5 V to the load side. R151 remains fitted and U152 sequences U151. Do not backfeed U121. |
| External3.3 V | Disconnect12 V/5 V and open R153 before applying service3.3 V to the main side. Do not power the U151 source from a programmer. U153/C206 may charge from this service supply. |
| UART/debug | Preserve EN, GPIO0, UART0 and all probe/Tag-Connect access. Do not drive UART pins into an unpowered module. Use an isolated, voltage-compatible adapter and source-defined references. No chassis-bonded programmer during vehicle operation. |

Never change isolation links while energized. Remove all sources, wait at least10 s, and measure upstream5 V, isolated VIN, source3V3, main3V3 and bulk capacitor below0.2 V before touching links. The delay covers more than five time constants of the maximum1.43208 mF reservoir with a1.06 kohm bleed; measurement remains controlling for faults or backpower. Probe ground clips must not short isolated sensor returns. Bottom probe access requires carrier removal as listed in the mechanical record.

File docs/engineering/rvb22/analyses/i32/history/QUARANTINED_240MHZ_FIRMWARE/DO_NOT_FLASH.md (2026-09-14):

# Historical 240 MHz build — not a release image

These bytes are preserved only as prior evidence. The recorded compile used CPUFreq=240, but the I25 release thermal profile requires 160 MHz. Matching source hashes alone did not establish build-profile compatibility. Rebuild with the repaired runner/build.sh, keep the new compiler record, and pass target binary release checks. No flashing is authorized by this recovery.

The historical ELF is stored losslessly as `cca_telemetry.ino.elf.gz` to remain within the authenticated publication connector's 16 MiB request ceiling. This transport compression does not make the quarantined 240 MHz image releasable.

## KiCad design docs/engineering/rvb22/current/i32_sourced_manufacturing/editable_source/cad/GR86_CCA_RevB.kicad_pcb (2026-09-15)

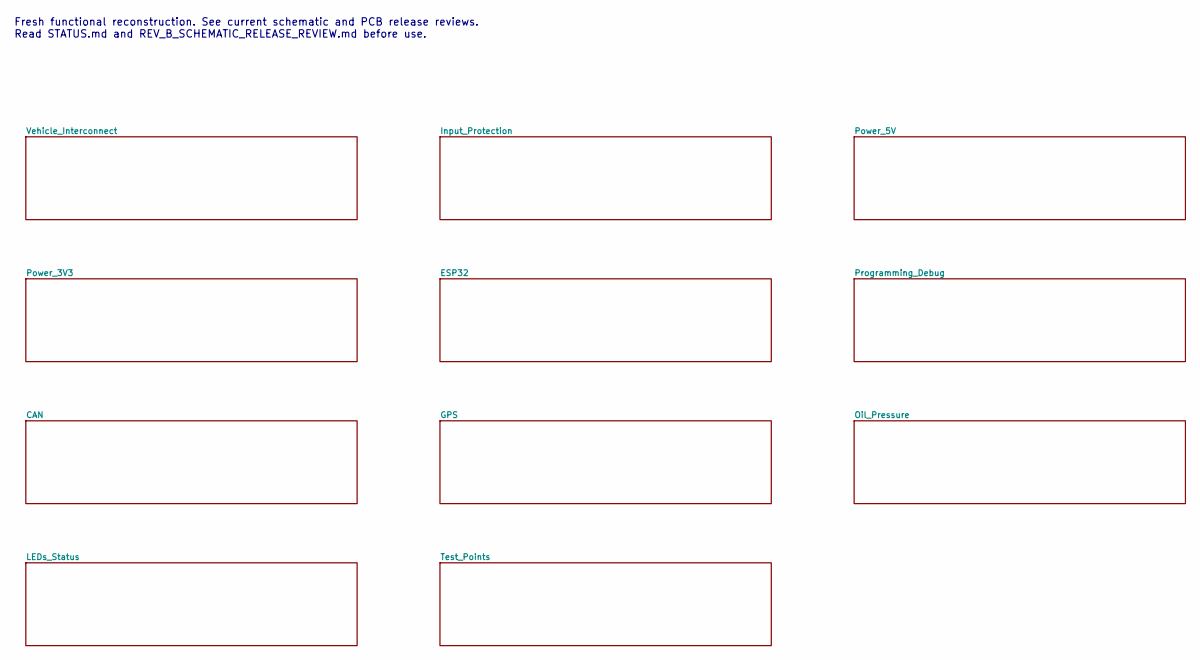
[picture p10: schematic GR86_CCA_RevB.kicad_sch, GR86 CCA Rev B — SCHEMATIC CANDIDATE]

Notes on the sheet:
Fresh functional reconstruction. See current schematic and PCB release reviews. Read STATUS.md and REV_B_SCHEMATIC_RELEASE_REVIEW.md before use.

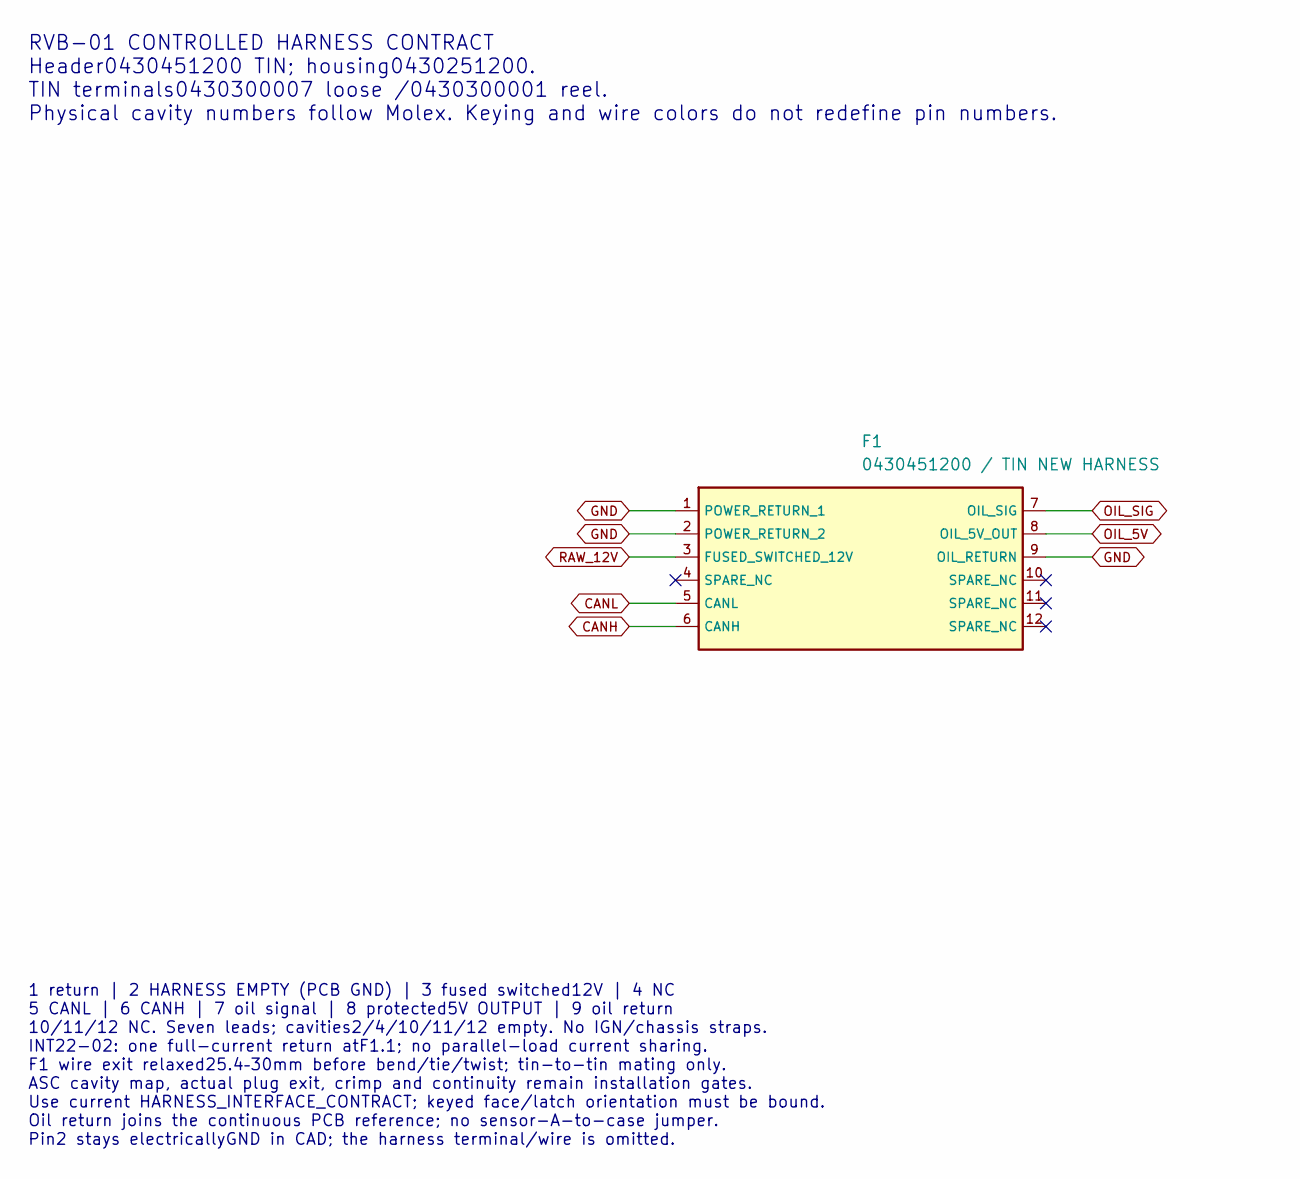
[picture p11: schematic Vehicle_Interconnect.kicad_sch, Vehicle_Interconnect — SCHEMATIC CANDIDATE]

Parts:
F1: 0430451200 / TIN NEW HARNESS; Molex_Micro-Fit_3.0_43045-1200_2x06_P3.00mm_Horizontal_RVB2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; MPN 0430451200; LCSC C277636

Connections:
CANH: F1.6 (CANH); also elsewhere on the board
CANL: F1.5 (CANL); also elsewhere on the board
GND: F1.1 (POWER_RETURN_1), F1.2 (POWER_RETURN_2), F1.9 (OIL_RETURN); also elsewhere on the board
OIL_5V: F1.8 (OIL_5V_OUT); also elsewhere on the board
OIL_SIG: F1.7 (OIL_SIG); also elsewhere on the board
RAW_12V: F1.3 (FUSED_SWITCHED_12V); also elsewhere on the board

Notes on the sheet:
RVB-01 CONTROLLED HARNESS CONTRACT Header0430451200 TIN; housing0430251200. TIN terminals0430300007 loose /0430300001 reel. Physical cavity numbers follow Molex. Keying and wire colors do not redefine pin numbers.
1 return | 2 HARNESS EMPTY (PCB GND) | 3 fused switched12V | 4 NC 5 CANL | 6 CANH | 7 oil signal | 8 protected5V OUTPUT | 9 oil return 10/11/12 NC. Seven leads; cavities2/4/10/11/12 empty. No IGN/chassis straps. INT22-02: one full-current return atF1.1; no parallel-load current sharing. F1 wire exi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

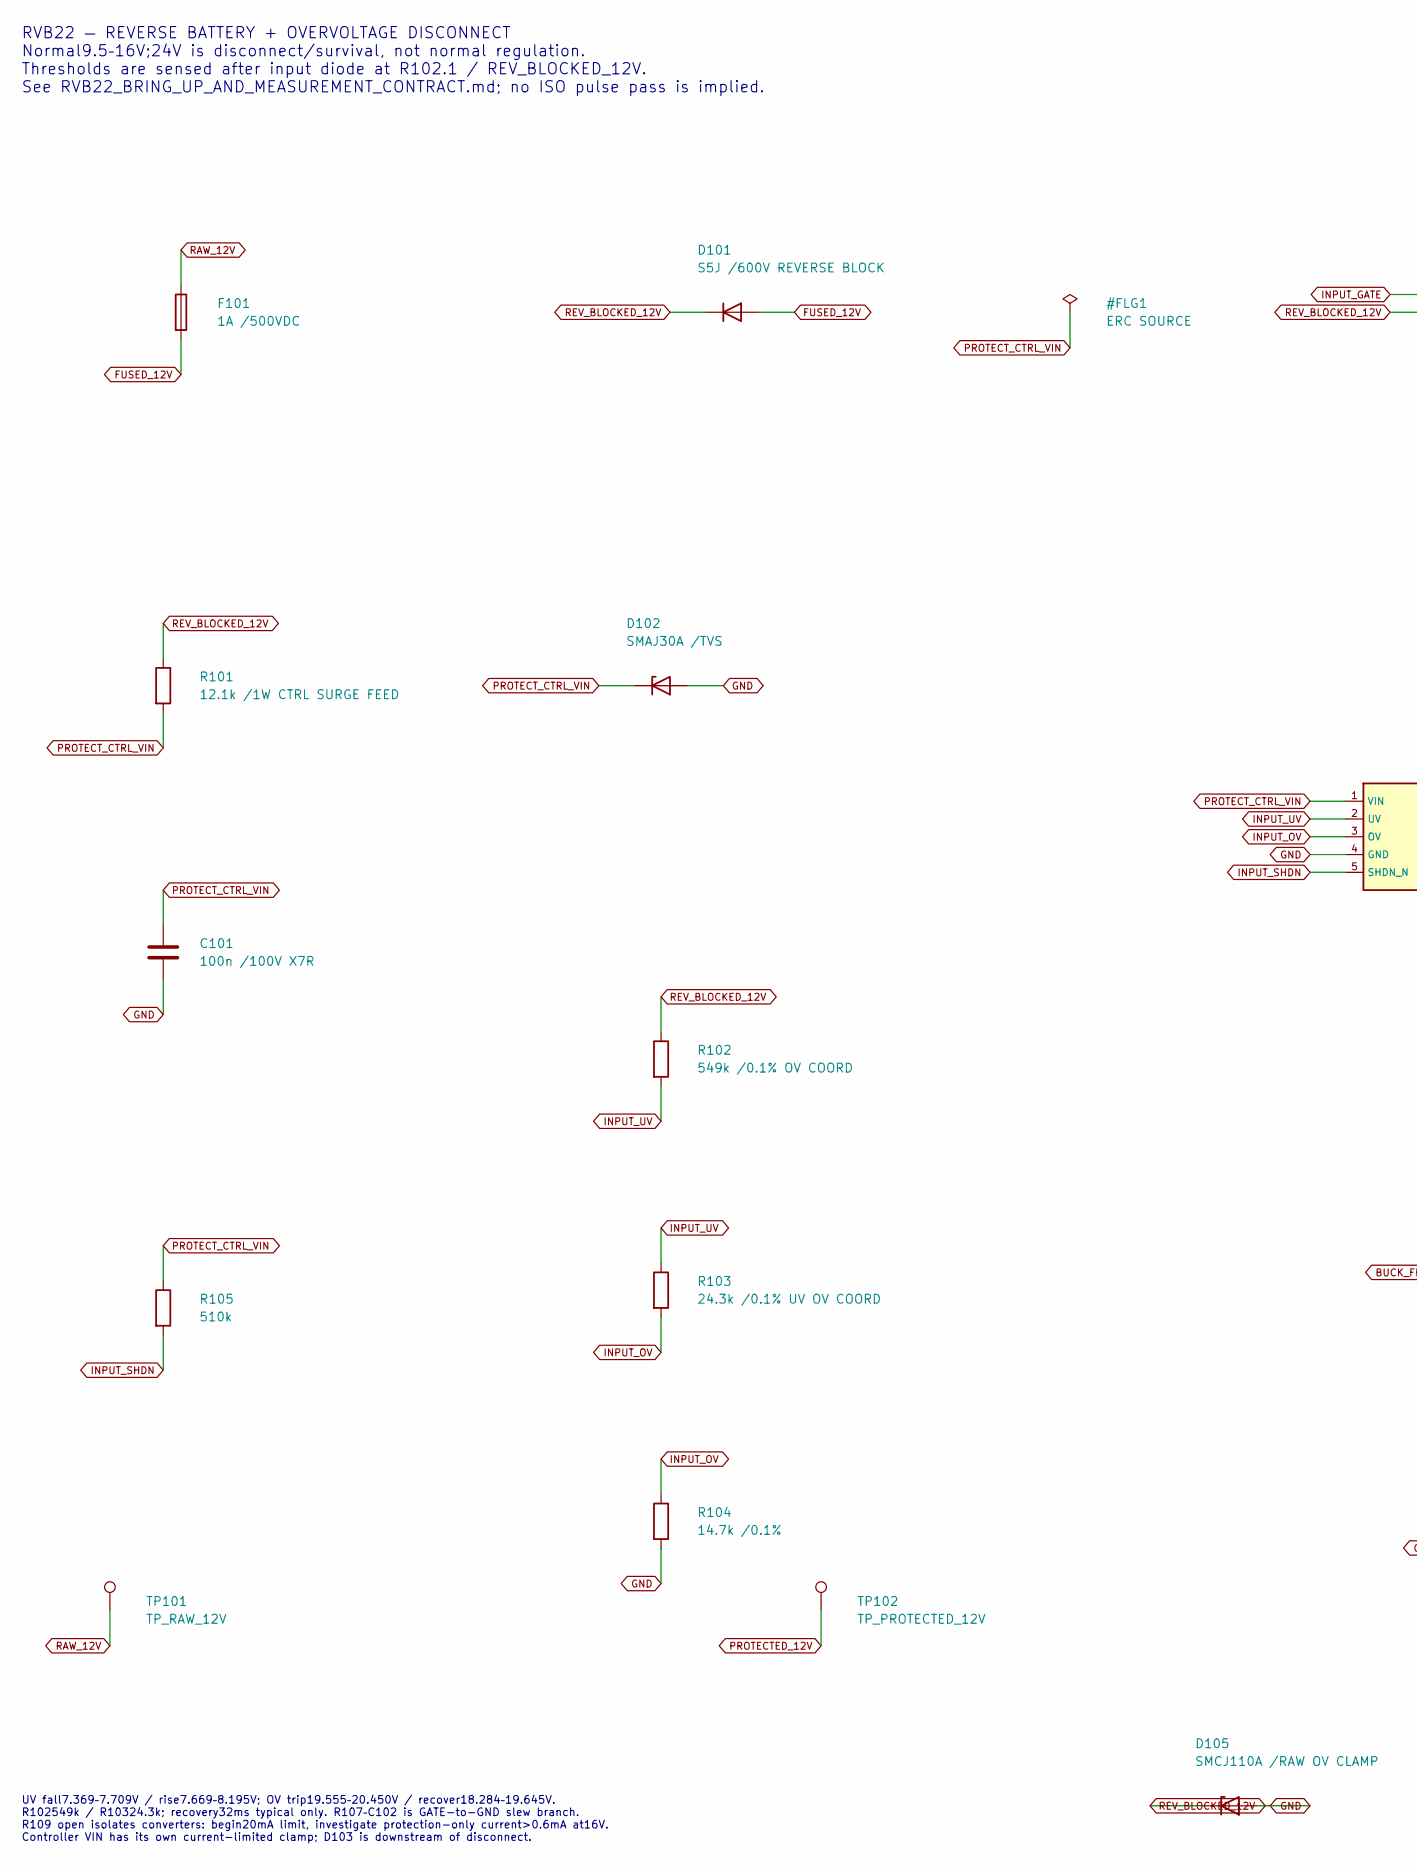
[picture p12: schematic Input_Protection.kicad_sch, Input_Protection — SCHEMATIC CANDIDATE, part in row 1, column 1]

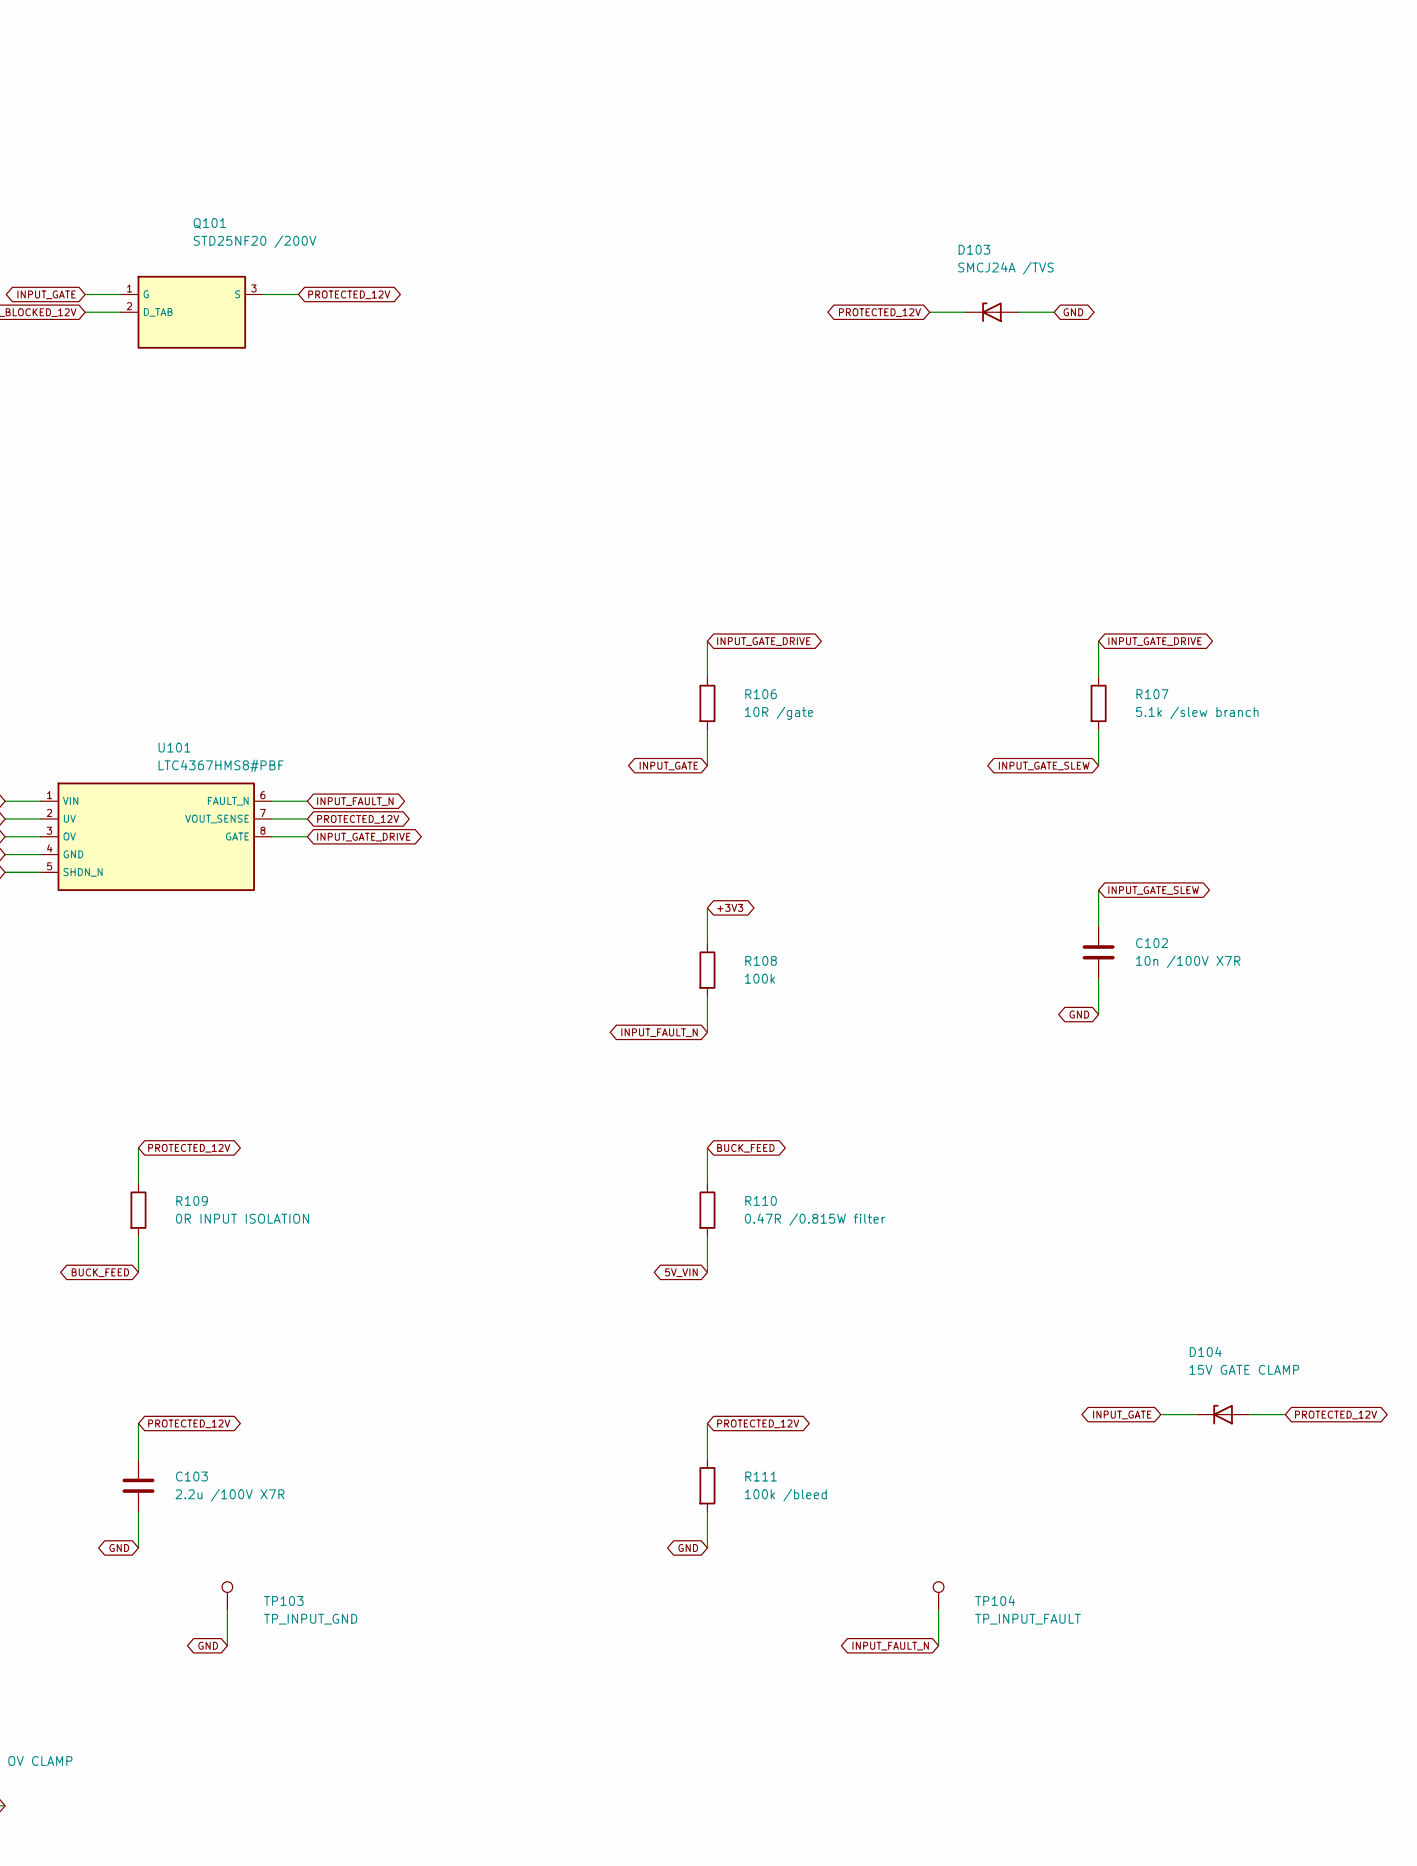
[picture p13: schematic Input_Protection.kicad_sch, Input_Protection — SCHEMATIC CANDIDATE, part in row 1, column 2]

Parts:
C101: 100n /100V X7R; C_0805_2012Metric; MPN CGA4J2X7R2A104K125AA; LCSC C342919
C102: 10n /100V X7R; C_0603_1608Metric; MPN CGA3E2X7R2A103K080AE; LCSC C3858696
C103: 2.2u /100V X7R; C_1210_3225Metric; MPN CGA6N3X7R2A225K230AB; LCSC C342652
D101: S5J /600V REVERSE BLOCK; D_SMC; MPN S5JHE3_A/H; LCSC C511410
D102: SMAJ30A /TVS; D_SMA; MPN SMAJ30AHE3_A/H; LCSC C1978408
D103: SMCJ24A /TVS; D_SMC_RVB22_D103; MPN SMCJ24AHE3_A/H; LCSC C1981952
D104: 15V GATE CLAMP; D_SOD-123F; MPN BZT52H-B15-QX; LCSC C7507926
D105: SMCJ110A /RAW OV CLAMP; D_SMC; MPN SMCJ110AHE3_A/H; LCSC C1982070
F101: 1A /500VDC; Fuse_Littelfuse-NANO2-885; MPN 0885001.DR; LCSC C2879865
Q101: STD25NF20 /200V; TO-252-2; MPN STD25NF20; LCSC C388326
R101: 12.1k /1W CTRL SURGE FEED; R_2512_6332Metric; MPN CRCW251212K1FKEG; LCSC C4263918
R102: 549k /0.1% OV COORD; R_1206_3216Metric; MPN TNPW1206549KBEEA; LCSC C4328168
R103: 24.3k /0.1% UV OV COORD; R_0603_1608Metric; MPN TNPW060324K3BEEA; LCSC C4269123
R104: 14.7k /0.1%; R_0603_1608Metric; MPN ERA3AEB1472V; LCSC C2074591
R105: 510k; R_1206_3216Metric; MPN CRCW1206510KFKEA; LCSC C843859
R106: 10R /gate; R_0603_1608Metric; MPN CRCW060310R0FKEA; LCSC C844919
R107: 5.1k /slew branch; R_0603_1608Metric; MPN CRCW06035K10FKEA; LCSC C844933
R108: 100k; R_0603_1608Metric; MPN CRCW0603100KFKEA; LCSC C844916
R109: 0R INPUT ISOLATION; R_1206_3216Metric; MPN CRCW12060000Z0EA; LCSC C190124
R110: 0.47R /0.815W filter; R_2512_6332Metric; MPN WSL2512R4700FEA; LCSC C4273015
R111: 100k /bleed; R_1206_3216Metric; MPN CRCW1206100KFKEA; LCSC C844863
TP101: TP_RAW_12V; TestPoint_Pad_D1.5mm; MPN BARE PCB PAD
TP102: TP_PROTECTED_12V; TestPoint_Pad_D1.5mm; MPN BARE PCB PAD
TP103: TP_INPUT_GND; TestPoint_Pad_D1.5mm; MPN BARE PCB PAD
TP104: TP_INPUT_FAULT; TestPoint_Pad_D1.5mm; MPN BARE PCB PAD
U101: LTC4367HMS8#PBF; I32_PROCUREMENT_U101; MPN LTC4367HMS8#PBF; LCSC C688370

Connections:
5V_VIN: R110.2; also elsewhere on the board
+3V3: R108.1; also elsewhere on the board
BUCK_FEED: R109.2, R110.1
FUSED_12V: D101.2 (A), F101.2
GND: C101.2, C102.2, C103.2, D102.2 (A), D103.2 (A), D105.2 (A), R104.2, R111.2, TP103.1, U101.4 (GND); also elsewhere on the board
INPUT_FAULT_N: R108.2, TP104.1, U101.6 (FAULT_N)
INPUT_GATE: D104.1 (K), Q101.1 (G), R106.2
INPUT_GATE_DRIVE: R106.1, R107.1, U101.8 (GATE)
INPUT_GATE_SLEW: C102.1, R107.2
INPUT_OV: R103.2, R104.1, U101.3 (OV)
INPUT_SHDN: R105.2, U101.5 (SHDN_N)
INPUT_UV: R102.2, R103.1, U101.2 (UV)
PROTECTED_12V: C103.1, D103.1 (K), D104.2 (A), Q101.3 (S), R109.1, R111.1, TP102.1, U101.7 (VOUT_SENSE)
PROTECT_CTRL_VIN: C101.1, D102.1 (K), R101.2, R105.1, U101.1 (VIN)
RAW_12V: F101.1, TP101.1; also elsewhere on the board
REV_BLOCKED_12V: D101.1 (K), D105.1 (K), Q101.2 (D_TAB), R101.1, R102.1

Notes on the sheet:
RVB22 — REVERSE BATTERY + OVERVOLTAGE DISCONNECT Normal9.5–16V;24V is disconnect/survival, not normal regulation. Thresholds are sensed after input diode at R102.1 / REV_BLOCKED_12V. See RVB22_BRING_UP_AND_MEASUREMENT_CONTRACT.md; no ISO pulse pass is implied.
UV fall7.369–7.709V / rise7.669–8.195V; OV trip19.555–20.450V / recover18.284–19.645V. R102549k / R10324.3k; recovery32ms typical only. R107–C102 is GATE-to-GND slew branch. R109 open isolates converters: begin20mA limit, investigate protection-only current>0.6mA at16V. Controller VIN has its own c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

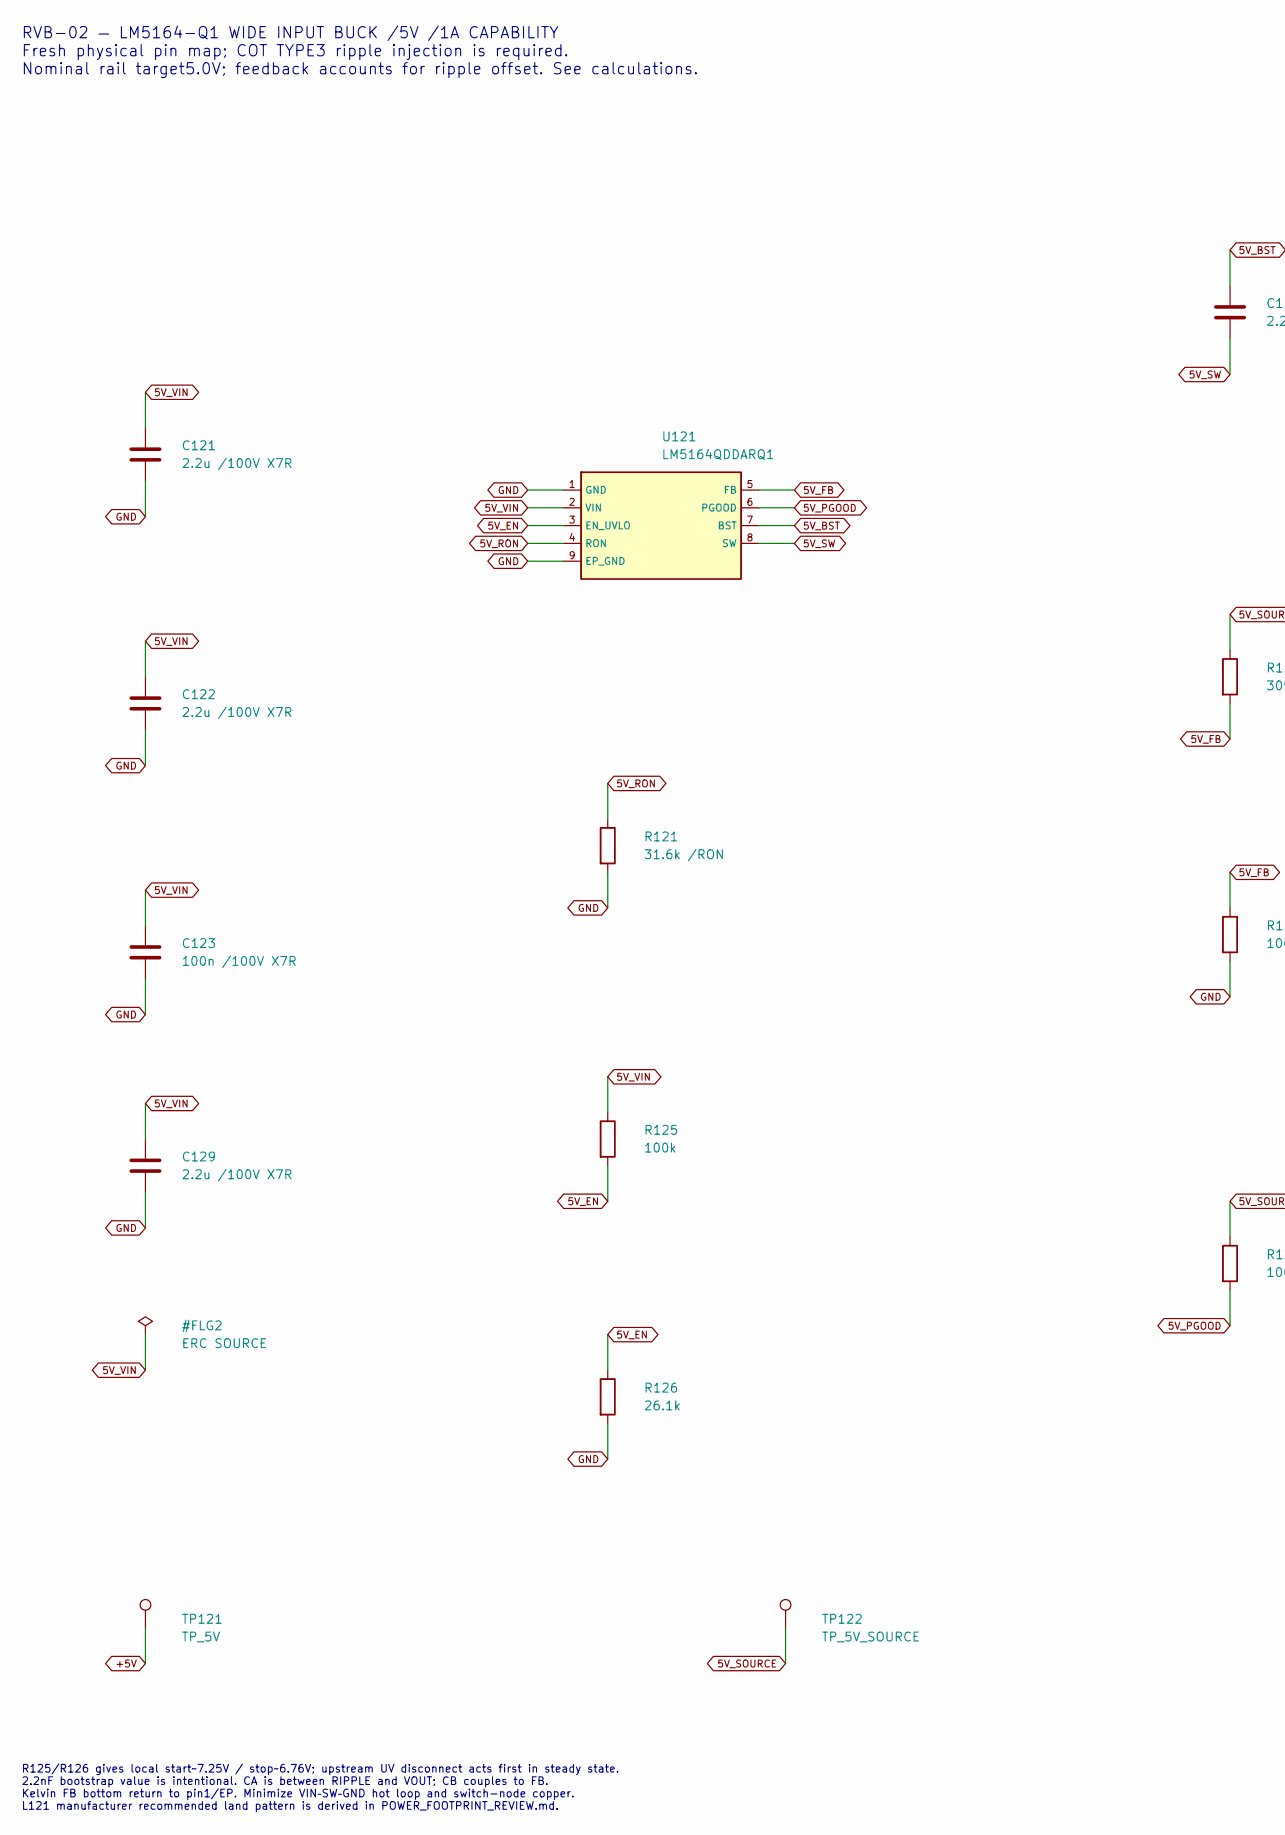
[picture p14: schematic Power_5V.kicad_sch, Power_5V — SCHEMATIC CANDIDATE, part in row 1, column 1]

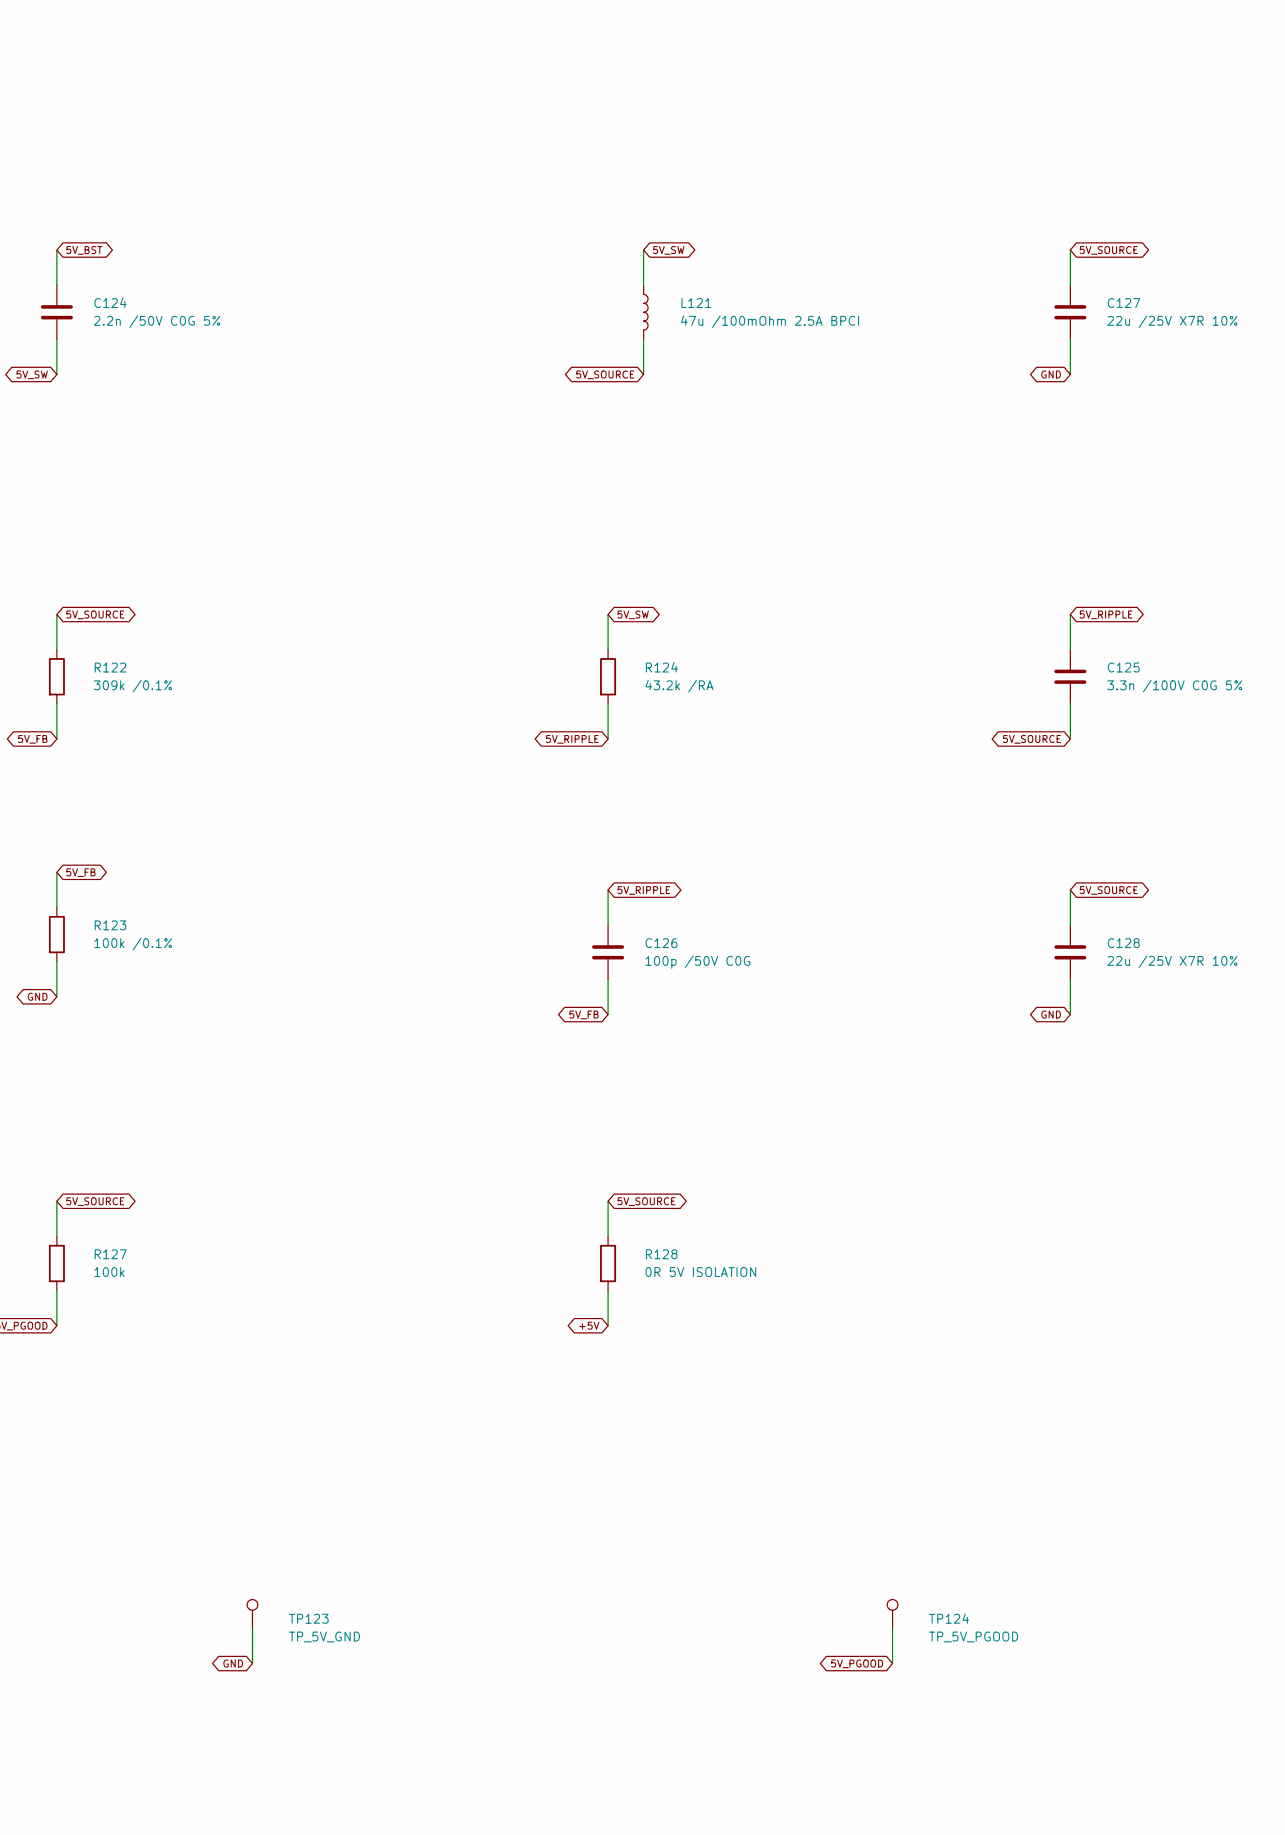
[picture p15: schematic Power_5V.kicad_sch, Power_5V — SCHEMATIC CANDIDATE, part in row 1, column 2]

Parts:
C121, C122, C129: 2.2u /100V X7R; C_1210_3225Metric; MPN CGA6N3X7R2A225K230AB; LCSC C342652
C123: 100n /100V X7R; C_0805_2012Metric; MPN CGA4J2X7R2A104K125AA; LCSC C342919
C124: 2.2n /50V C0G 5%; C_0603_1608Metric; MPN CGA3E2C0G1H222J080AA; LCSC C2169200
C125: 3.3n /100V C0G 5%; C_0603_1608Metric; MPN CGA3E2C0G2A332J080AA; LCSC C2171993
C126: 100p /50V C0G; C_0603_1608Metric; MPN CGA3E2C0G1H101J080AA; LCSC C76709
C127, C128: 22u /25V X7R 10%; C_1210_3225Metric; MPN MCAST32MSB7226KPNA01; LCSC C5372271
L121: 47u /100mOhm 2.5A BPCI; I32_PROCUREMENT_L121; MPN BPCI00121280470M00; LCSC C6471075
R121: 31.6k /RON; R_0603_1608Metric; MPN TNPW060331K6BEEA; LCSC C843870
R122: 309k /0.1%; R_0805_2012Metric; MPN TNPW0805309KBEEA; LCSC C1710754
R123: 100k /0.1%; R_0603_1608Metric; MPN TNPW0603100KBEEA; LCSC C844888
R124: 43.2k /RA; R_0603_1608Metric; MPN TNPW060343K2BEEA; LCSC C2089718
R125: 100k; R_1206_3216Metric; MPN CRCW1206100KFKEA; LCSC C844863
R126: 26.1k; R_0603_1608Metric; MPN ERA3AEB2612V; LCSC C491123
R127: 100k; R_0603_1608Metric; MPN CRCW0603100KFKEA; LCSC C844916
R128: 0R 5V ISOLATION; R_1206_3216Metric; MPN CRCW12060000Z0EA; LCSC C190124
TP121: TP_5V; TestPoint_Pad_D1.5mm; MPN BARE PCB PAD
TP122: TP_5V_SOURCE; TestPoint_Pad_D1.5mm; MPN BARE PCB PAD
TP123: TP_5V_GND; TestPoint_Pad_D1.5mm; MPN BARE PCB PAD
TP124: TP_5V_PGOOD; TestPoint_Pad_D1.5mm; MPN BARE PCB PAD
U121: LM5164QDDARQ1; TI_DDA0008B_4214849B; MPN LM5164QDDARQ1; LCSC C2072225

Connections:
5V_BST: C124.1, U121.7 (BST)
5V_EN: R125.2, R126.1, U121.3 (EN_UVLO)
5V_FB: C126.2, R122.2, R123.1, U121.5 (FB)
5V_PGOOD: R127.2, TP124.1, U121.6 (PGOOD)
5V_RIPPLE: C125.1, C126.1, R124.2
5V_RON: R121.1, U121.4 (RON)
5V_SOURCE: C125.2, C127.1, C128.1, L121.2, R122.1, R127.1, R128.1, TP122.1
5V_SW: C124.2, L121.1, R124.1, U121.8 (SW)
5V_VIN: C121.1, C122.1, C123.1, C129.1, R125.1, U121.2 (VIN); also elsewhere on the board
+5V: R128.2, TP121.1; also elsewhere on the board
GND: C121.2, C122.2, C123.2, C127.2, C128.2, C129.2, R121.2, R123.2, R126.2, TP123.1, U121.1 (GND), U121.9 (EP_GND); also elsewhere on the board

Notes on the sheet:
RVB-02 — LM5164-Q1 WIDE INPUT BUCK /5V /1A CAPABILITY Fresh physical pin map; COT TYPE3 ripple injection is required. Nominal rail target5.0V; feedback accounts for ripple offset. See calculations.
R125/R126 gives local start~7.25V / stop~6.76V; upstream UV disconnect acts first in steady state. 2.2nF bootstrap value is intentional. CA is between RIPPLE and VOUT; CB couples to FB. Kelvin FB bottom return to pin1/EP. Minimize VIN–SW–GND hot loop and switch-node copper. L121 manufacturer recomm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

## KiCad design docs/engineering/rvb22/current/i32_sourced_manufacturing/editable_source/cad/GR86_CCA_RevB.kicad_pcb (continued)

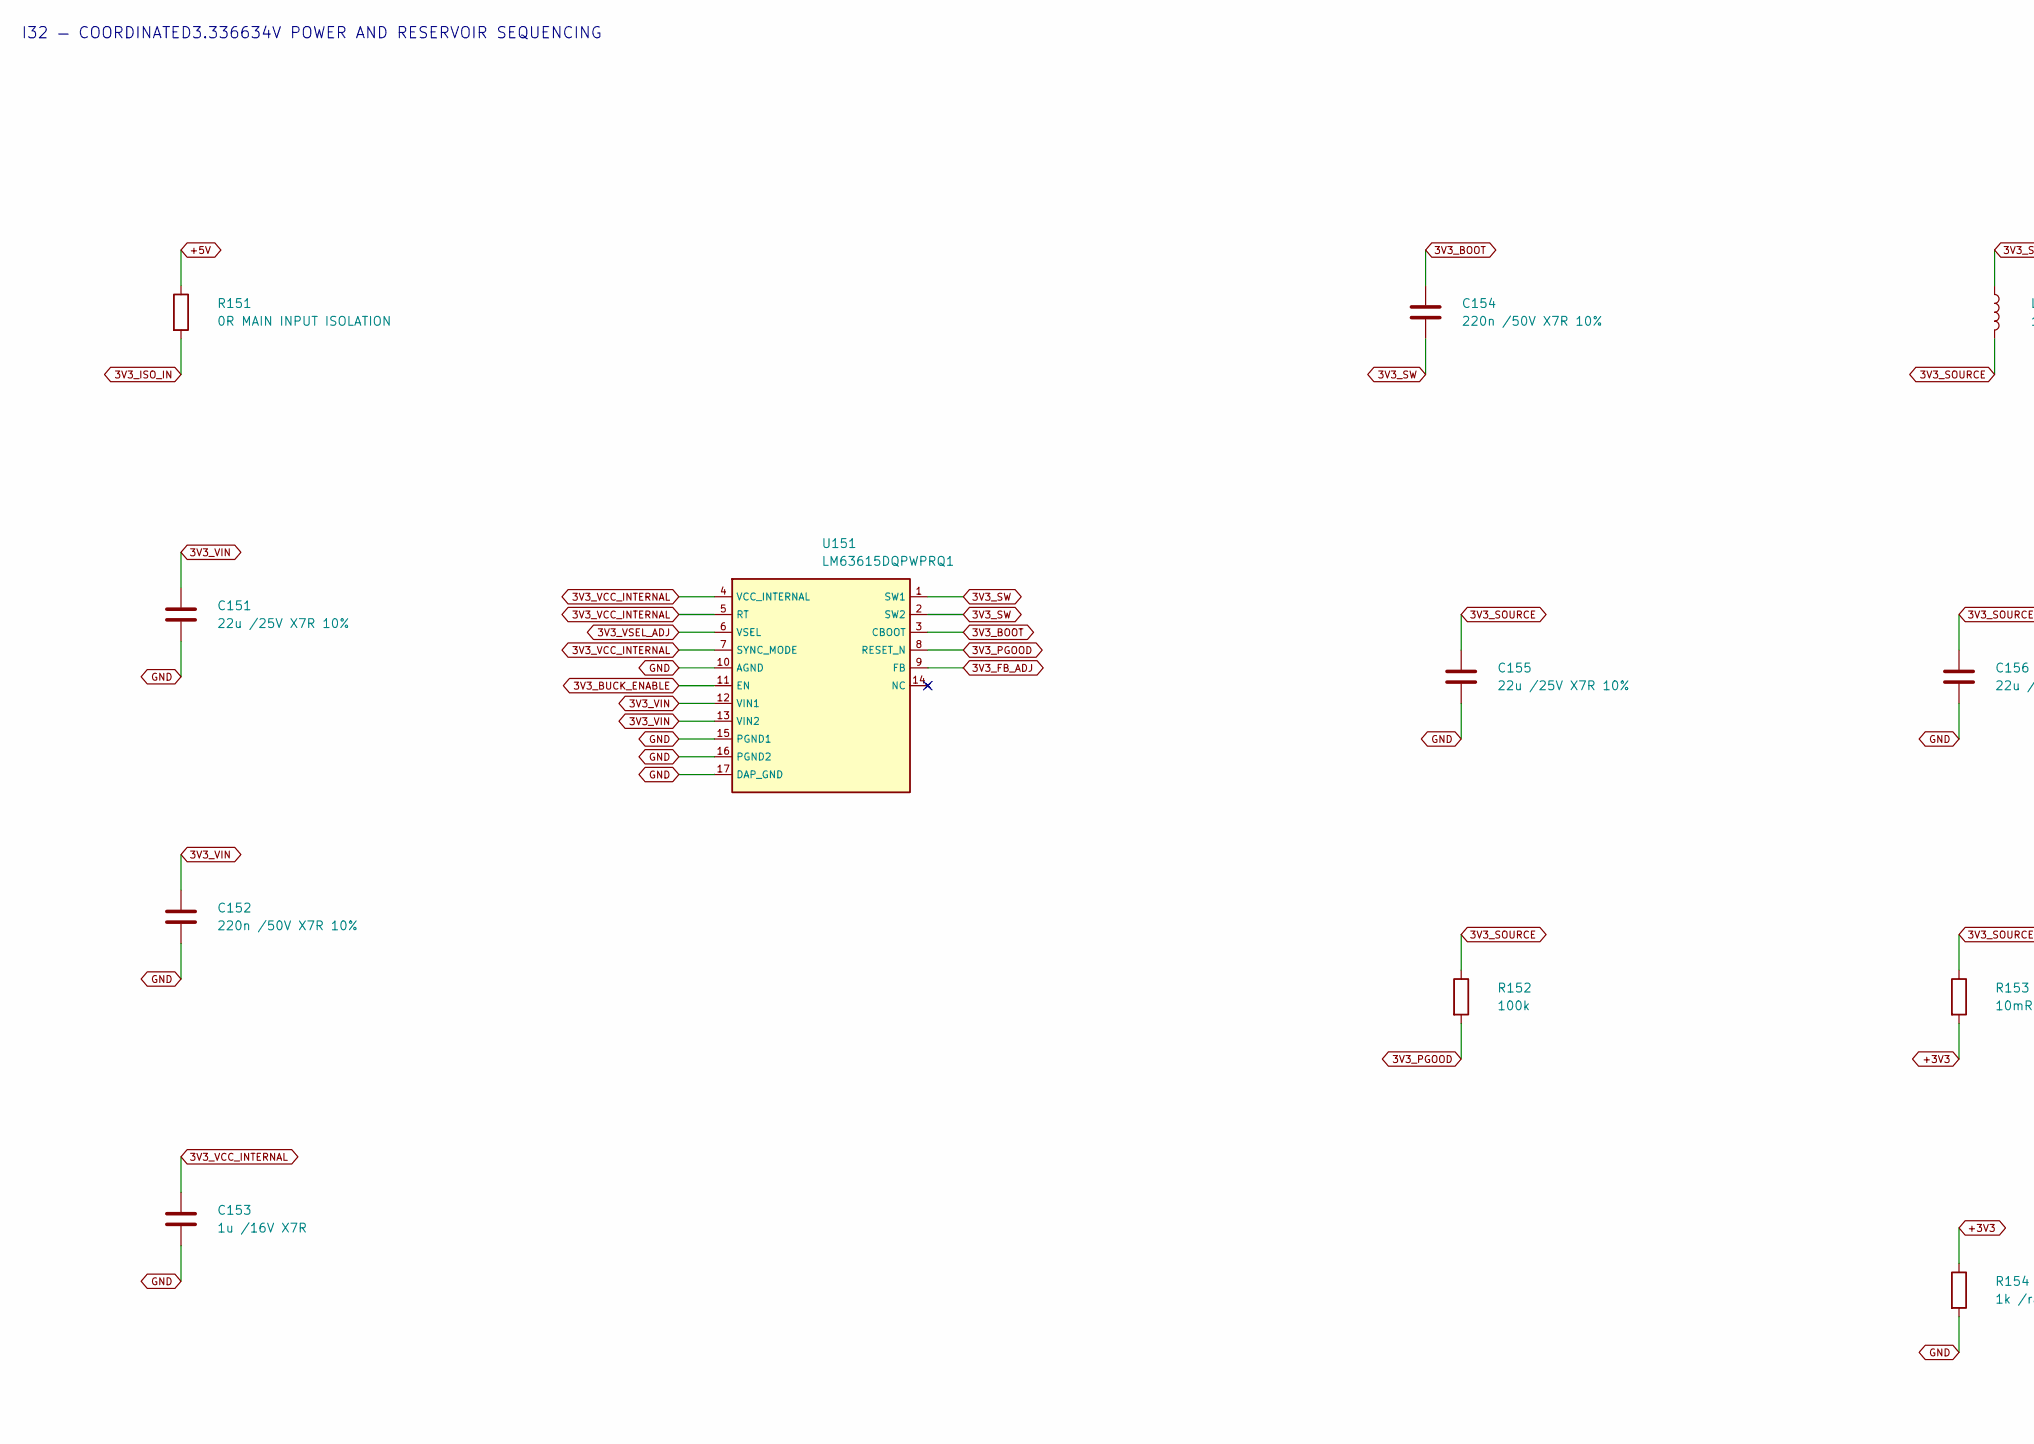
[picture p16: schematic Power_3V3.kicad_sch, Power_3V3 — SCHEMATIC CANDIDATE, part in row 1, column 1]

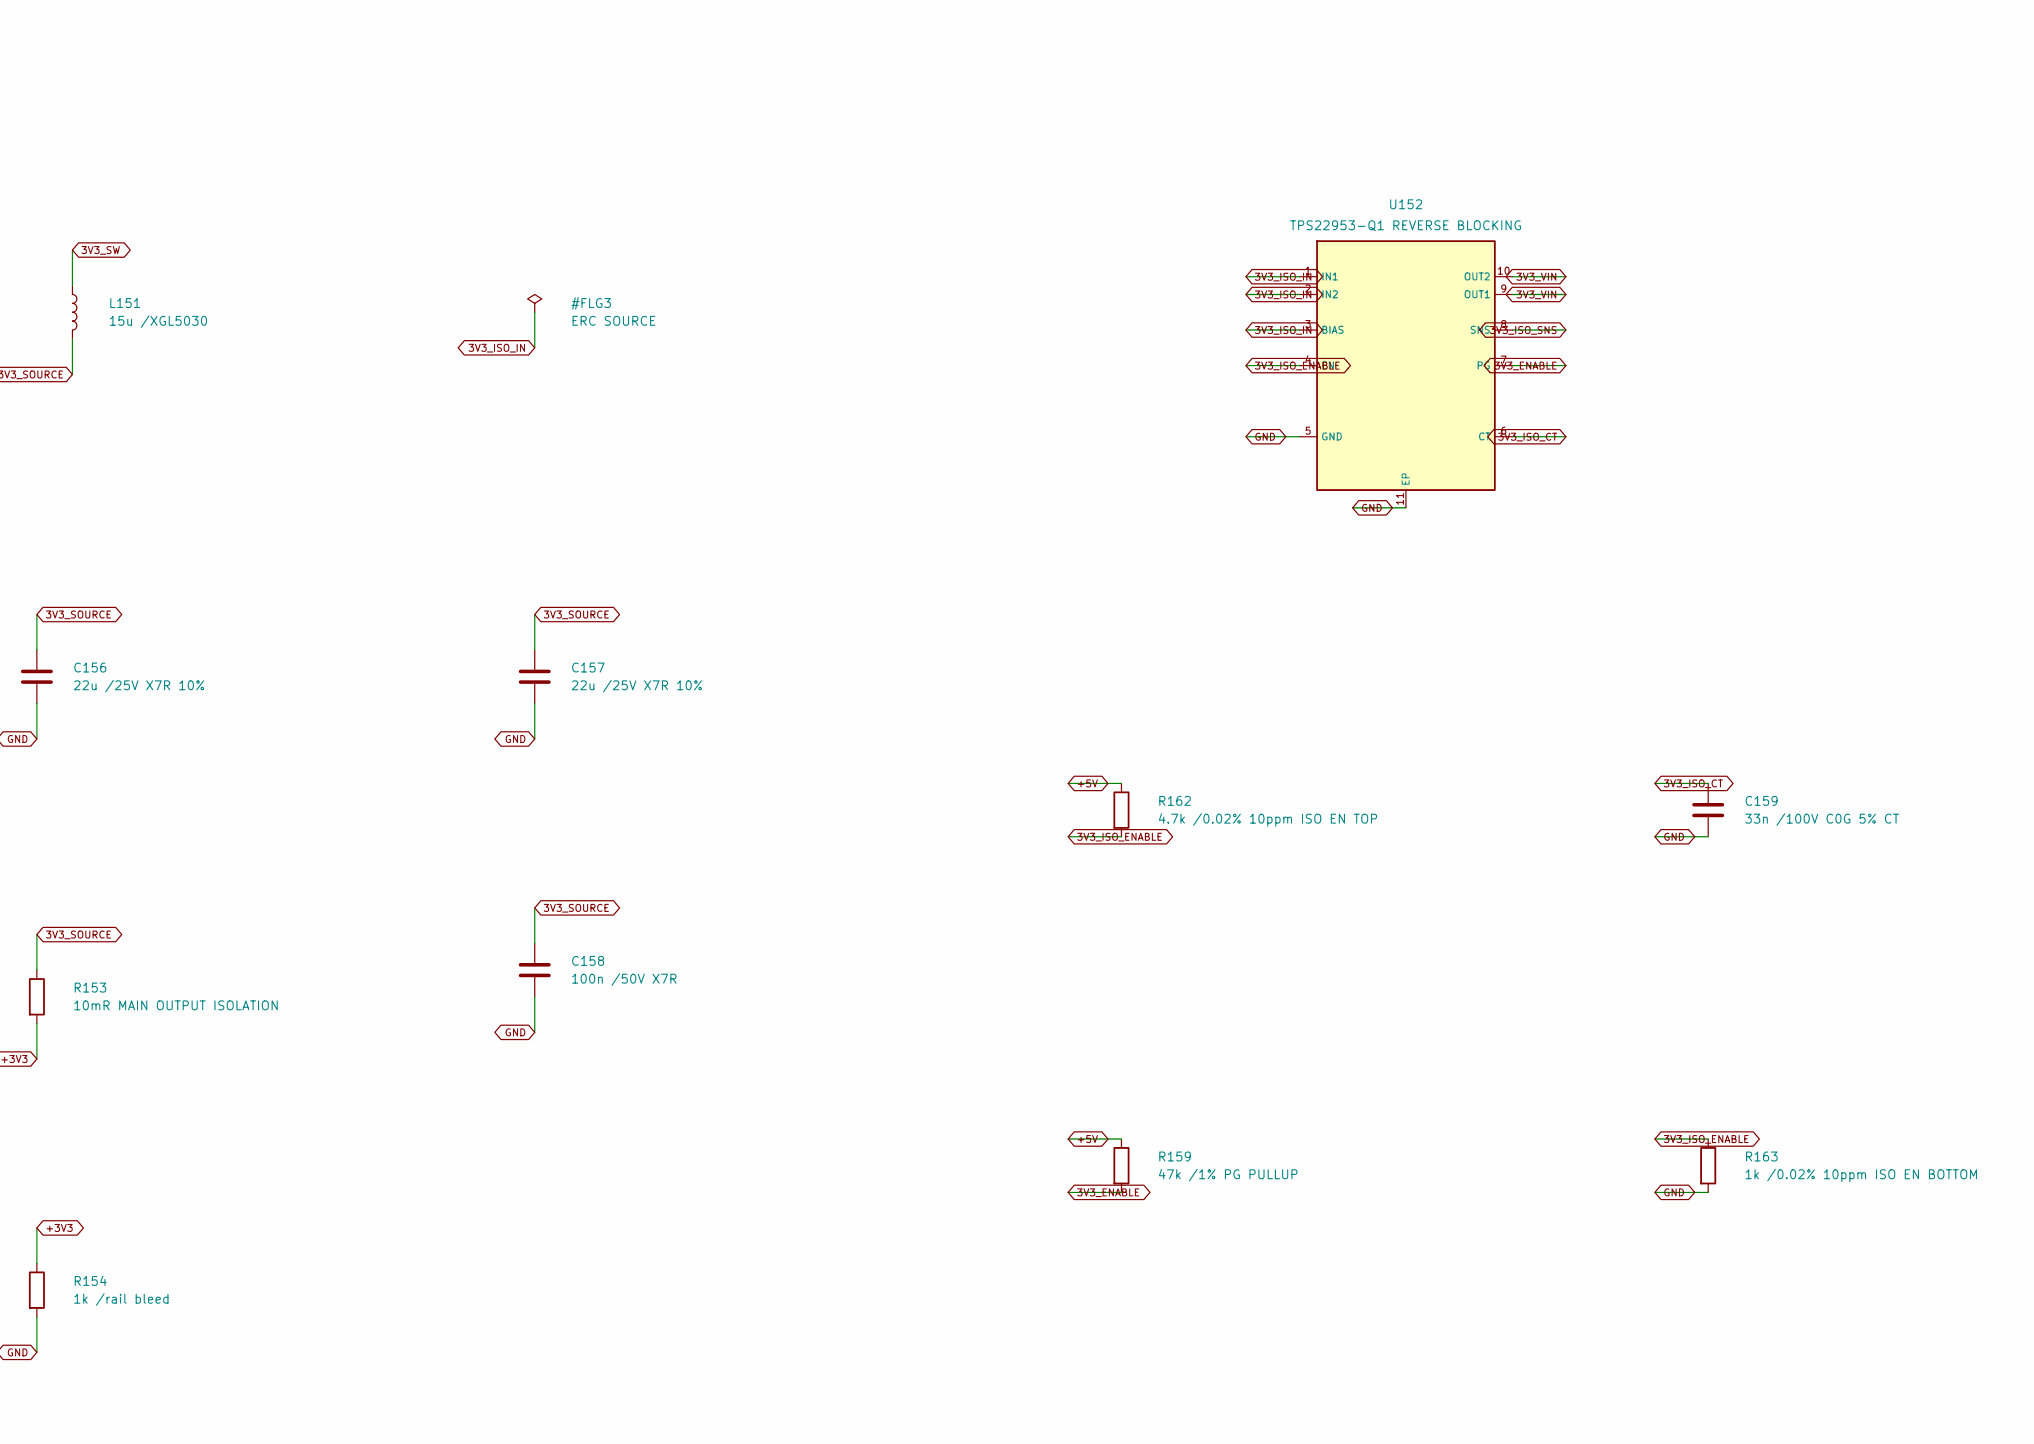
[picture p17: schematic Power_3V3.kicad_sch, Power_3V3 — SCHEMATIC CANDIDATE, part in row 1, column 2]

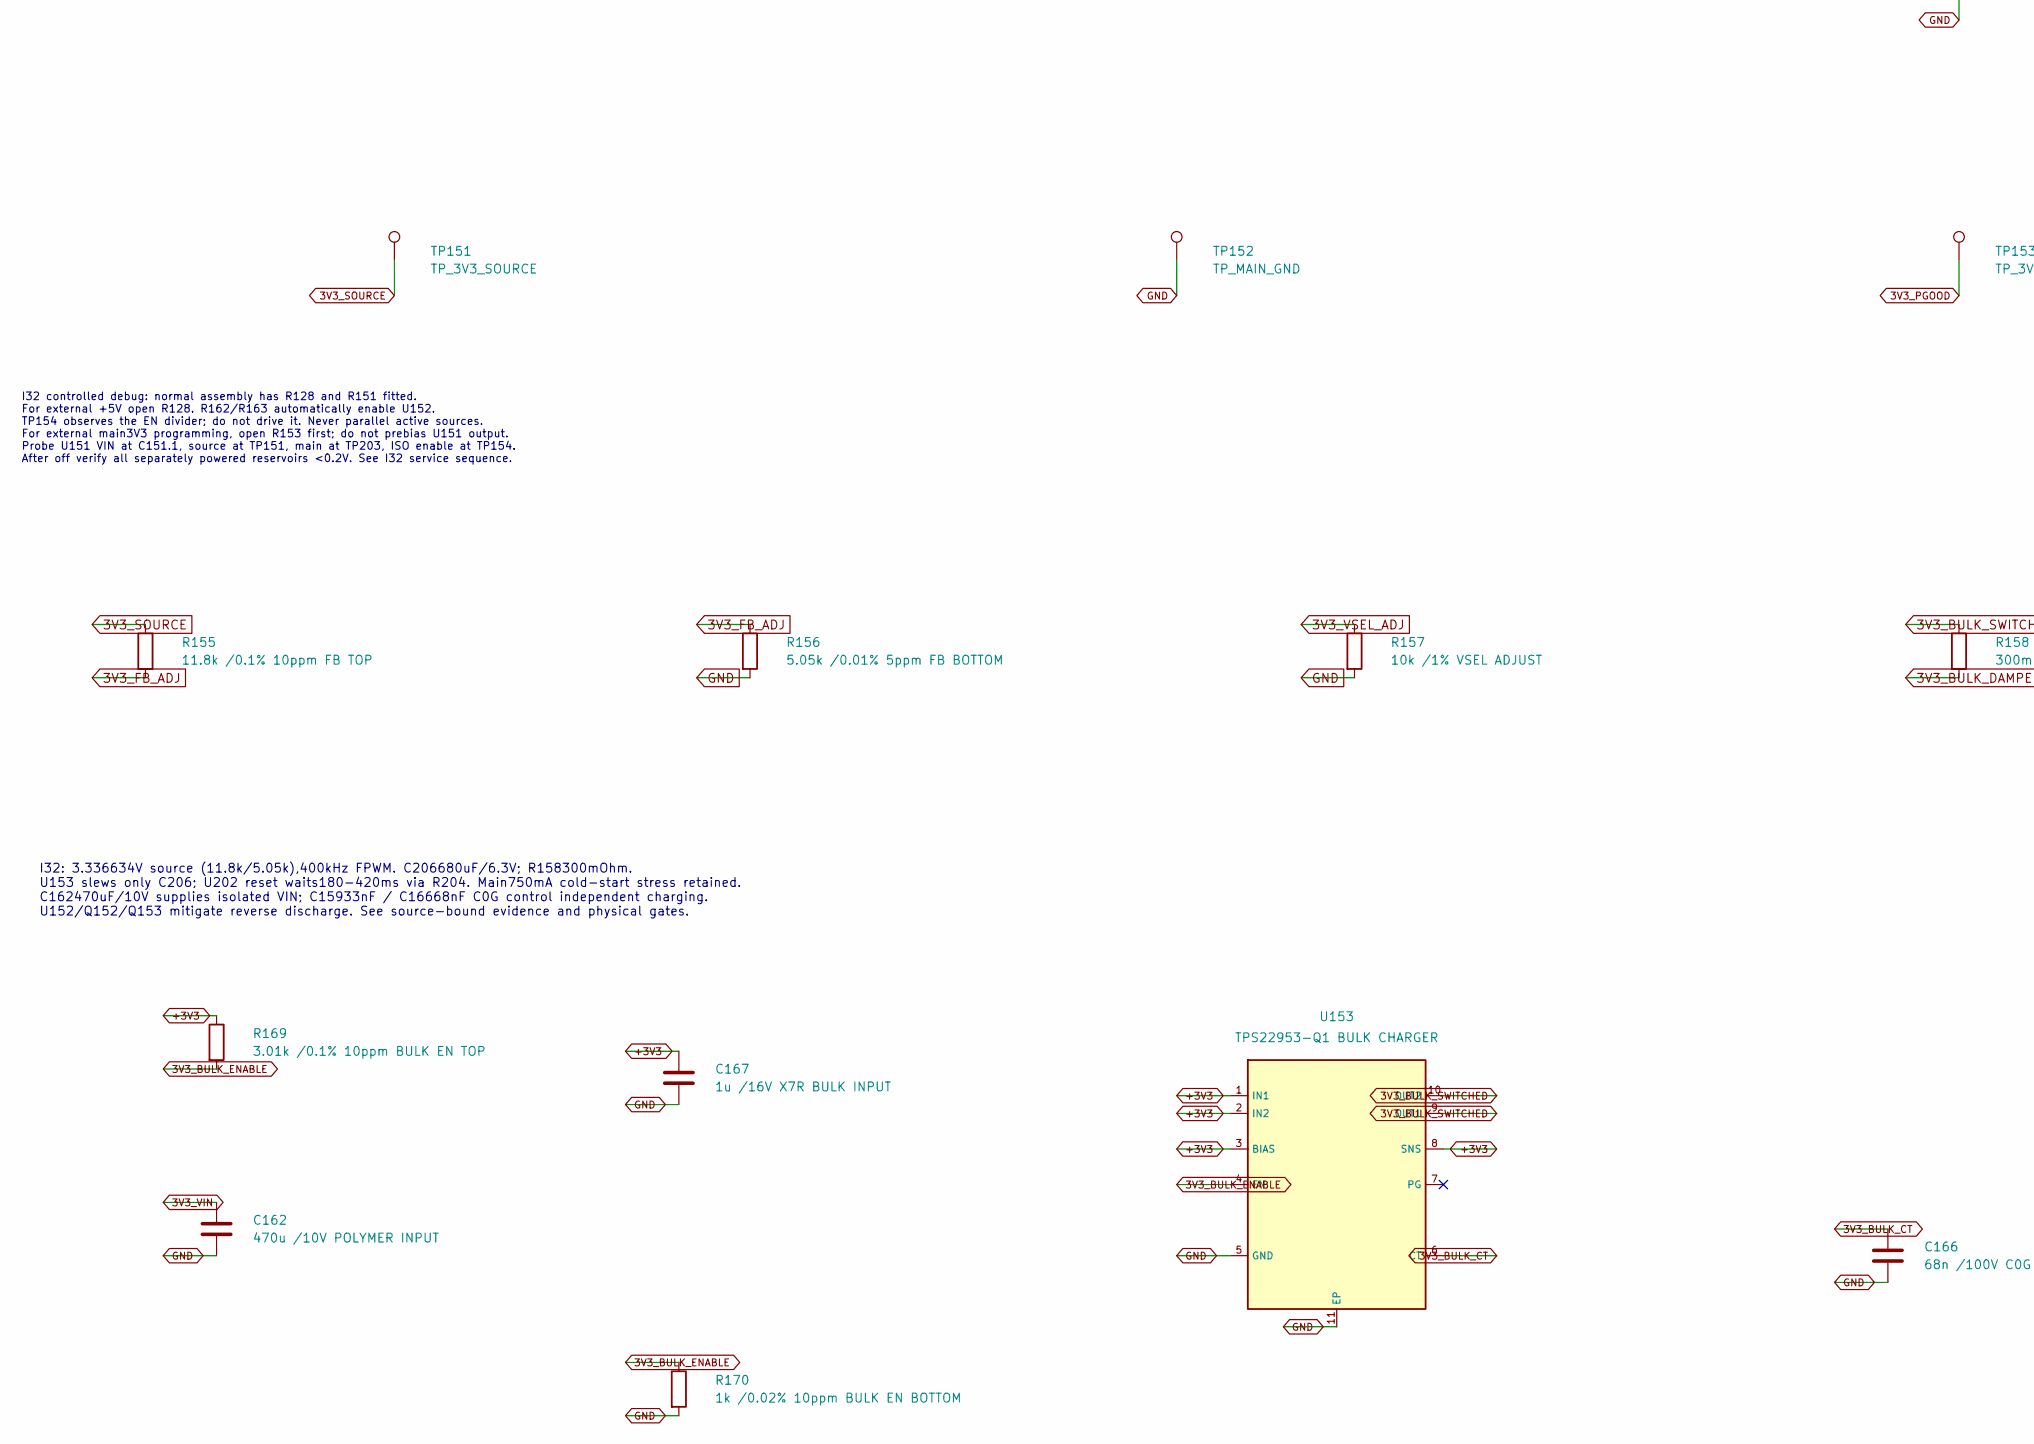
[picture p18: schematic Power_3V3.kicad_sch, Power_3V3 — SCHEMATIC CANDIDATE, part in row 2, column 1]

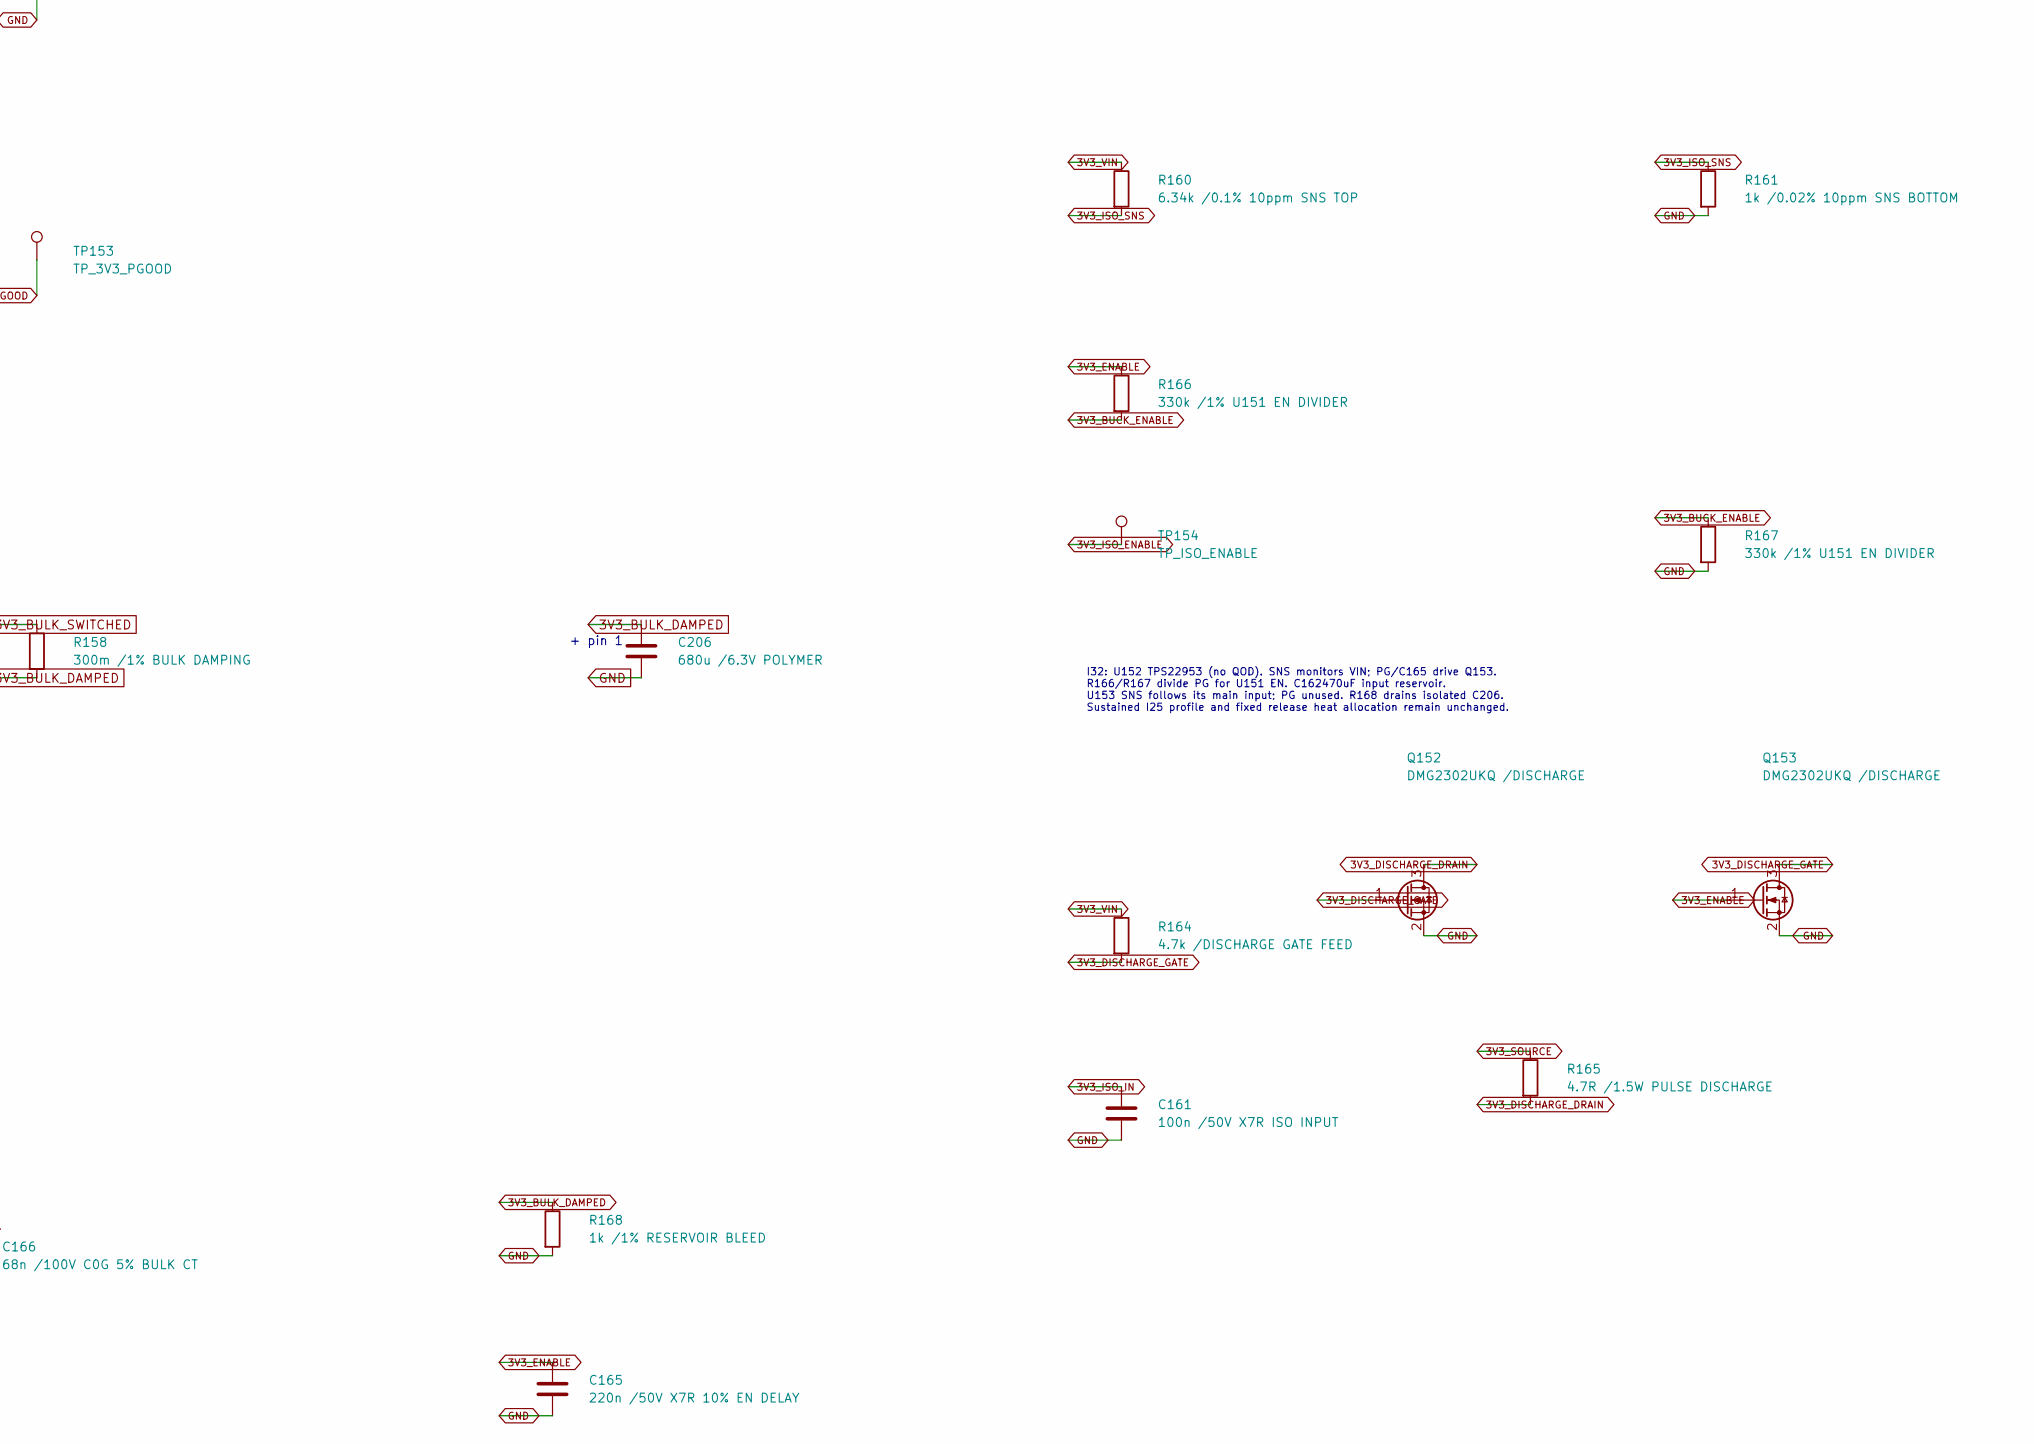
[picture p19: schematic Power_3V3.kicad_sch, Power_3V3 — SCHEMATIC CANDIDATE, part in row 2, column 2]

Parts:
C151, C155, C156, C157: 22u /25V X7R 10%; C_1210_3225Metric; MPN MCAST32MSB7226KPNA01; LCSC C5372271
C152: 220n /50V X7R 10%; I32_PROCUREMENT_C152; MPN CGA3E3X7R1H224KT0Y0N; LCSC C342967
C153: 1u /16V X7R; C_0603_1608Metric; MPN GCM188R71C105KA64D; LCSC C161212
C154: 220n /50V X7R 10%; I32_PROCUREMENT_C154; MPN CGA3E3X7R1H224KT0Y0N; LCSC C342967
C158: 100n /50V X7R; C_0603_1608Metric; MPN GCM188R71H104KA57D; LCSC C85864
C159: 33n /100V C0G 5% CT; I32_FINISHED_C159; MPN CGA4J1C0G2A333J125AE; LCSC C2181132
C161: 100n /50V X7R ISO INPUT; I32_FINISHED_C161; MPN GCM188R71H104KA57D; LCSC C85864
C162: 470u /10V POLYMER INPUT; I32_FINISHED_C162; MPN T598X477M010ATE025; LCSC C19941093
C165: 220n /50V X7R 10% EN DELAY; I32_PROCUREMENT_C165; MPN CGA3E3X7R1H224KT0Y0N; LCSC C342967
C166: 68n /100V C0G 5% BULK CT; I32_FINISHED_C166; MPN CGA5L1C0G2A683J160AE; LCSC C3869625
C167: 1u /16V X7R BULK INPUT; I32_FINISHED_C167; MPN GCM188R71C105KA64D; LCSC C161212
C206: 680u /6.3V POLYMER; KEMET_T598_X_7343_Median_RVB22_C206; MPN T598X687M006ATE025; LCSC C4951511
L151: 15u /XGL5030; L_Coilcraft_XAL5030-XXX; MPN XGL5030-153MEC; LCSC C3911485
Q152: DMG2302UKQ /DISCHARGE; I32_FINISHED_Q152; MPN DMG2302UKQ-7; LCSC C5224573
Q153: DMG2302UKQ /DISCHARGE; I32_FINISHED_Q153; MPN DMG2302UKQ-7; LCSC C5224573
R151: 0R MAIN INPUT ISOLATION; I32_FINISHED_R151; MPN CRCW12060000Z0EA; LCSC C190124
R152: 100k; R_0603_1608Metric; MPN CRCW0603100KFKEA; LCSC C844916
R153: 10mR MAIN OUTPUT ISOLATION; WSLP0603_MANUFACTURER_R153; MPN WSLP0603R0100FEA; LCSC C5334451
R154: 1k /rail bleed; R_0603_1608Metric; MPN CRCW06031K00FKEA; LCSC C844920
R155: 11.8k /0.1% 10ppm FB TOP; I32_PROCUREMENT_R155; MPN PTFR0603B11K8N9; LCSC C19679768
R156: 5.05k /0.01% 5ppm FB BOTTOM; I32_PROCUREMENT_R156; MPN PLT1206Z5051LBTS; LCSC C4074185
R157: 10k /1% VSEL ADJUST; R_0603_1608Metric_RVB22_R157; MPN CRCW060310K0FKEA; LCSC C844918
R158: 300m /1% BULK DAMPING; I32_FINISHED_R158; MPN WSL2512R3000FEA; LCSC C2076134
R159: 47k /1% PG PULLUP; I32_FINISHED_R159; MPN CRCW060347K0FKEA; LCSC C844929
R160: 6.34k /0.1% 10ppm SNS TOP; I32_PROCUREMENT_R160; MPN RT0805BRB076K34L; LCSC C864499
R161: 1k /0.02% 10ppm SNS BOTTOM; I32_PROCUREMENT_R161; MPN PTFR0603Q1K00N9; LCSC C23067434
R162: 4.7k /0.02% 10ppm ISO EN TOP; I32_PROCUREMENT_R162; MPN PTFR0603Q4K70N9; LCSC C23067437
R163: 1k /0.02% 10ppm ISO EN BOTTOM; I32_PROCUREMENT_R163; MPN PTFR0603Q1K00N9; LCSC C23067434
R164: 4.7k /DISCHARGE GATE FEED; I32_FINISHED_R164; MPN CRCW06034K70FKEA; LCSC C844931
R165: 4.7R /1.5W PULSE DISCHARGE; I32_FINISHED_R165; MPN CRCW25124R70FKEGHP; LCSC C2075852
R166: 330k /1% U151 EN DIVIDER; I32_FINISHED_R166; MPN CRCW0603330KFKEA; LCSC C844776
R167: 330k /1% U151 EN DIVIDER; I32_FINISHED_R167; MPN CRCW0603330KFKEA; LCSC C844776
R168: 1k /1% RESERVOIR BLEED; I32_FINISHED_R168; MPN CRCW06031K00FKEA; LCSC C844920
R169: 3.01k /0.1% 10ppm BULK EN TOP; I32_PROCUREMENT_R169; MPN PTFR0603B3K01N9; LCSC C2692830
R170: 1k /0.02% 10ppm BULK EN BOTTOM; I32_PROCUREMENT_R170; MPN PTFR0603Q1K00N9; LCSC C23067434
TP151: TP_3V3_SOURCE; TestPoint_Pad_D1.5mm; MPN BARE PCB PAD
TP152: TP_MAIN_GND; TestPoint_Pad_D1.5mm; MPN BARE PCB PAD
TP153: TP_3V3_PGOOD; TestPoint_Pad_D1.5mm; MPN BARE PCB PAD
TP154: TP_ISO_ENABLE; I32_FINISHED_TP154; MPN BARE PCB PAD
U151: LM63615DQPWPRQ1; HTSSOP-16-1EP_4.4x5mm_P0.65mm_EP3.4x5mm_Mask2.46x2.31mm_RVB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; MPN LM63615DQPWPRQ1; LCSC C2867799
U152: TPS22953-Q1 REVERSE BLOCKING; I32_FINISHED_U152; MPN TPS22953QDQCRQ1; LCSC C5219894
U153: TPS22953-Q1 BULK CHARGER; I32_FINISHED_U153; MPN TPS22953QDQCRQ1; LCSC C5219894

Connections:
3V3_BOOT: C154.1, U151.3 (CBOOT)
3V3_BUCK_ENABLE: R166.2, R167.1, U151.11 (EN)
3V3_BULK_CT: C166.1, U153.6 (CT)
3V3_BULK_DAMPED: C206.1, R158.2, R168.1
3V3_BULK_ENABLE: R169.2, R170.1, U153.4 (EN)
3V3_BULK_SWITCHED: R158.1, U153.9 (OUT1), U153.10 (OUT2)
3V3_DISCHARGE_DRAIN: Q152.3 (D), R165.2
3V3_DISCHARGE_GATE: Q152.1 (G), Q153.3 (D), R164.2
3V3_ENABLE: C165.1, Q153.1 (G), R159.2, R166.1, U152.7 (PG)
3V3_FB_ADJ: R155.2, R156.1, U151.9 (FB)
3V3_ISO_CT: C159.1, U152.6 (CT)
3V3_ISO_ENABLE: R162.2, R163.1, TP154.1, U152.4 (EN)
3V3_ISO_IN: C161.1, R151.2, U152.1 (IN1), U152.2 (IN2), U152.3 (BIAS)
3V3_ISO_SNS: R160.2, R161.1, U152.8 (SNS)
3V3_PGOOD: R152.2, TP153.1, U151.8 (RESET_N)
3V3_SOURCE: C155.1, C156.1, C157.1, C158.1, L151.2, R152.1, R153.1, R155.1, R165.1, TP151.1
3V3_SW: C154.2, L151.1, U151.1 (SW1), U151.2 (SW2)
3V3_VCC_INTERNAL: C153.1, U151.4 (VCC_INTERNAL), U151.5 (RT), U151.7 (SYNC_MODE)
3V3_VIN: C151.1, C152.1, C162.1, R160.1, R164.1, U151.12 (VIN1), U151.13 (VIN2), U152.9 (OUT1), U152.10 (OUT2)
3V3_VSEL_ADJ: R157.1, U151.6 (VSEL)
+3V3: C167.1, R153.2, R154.1, R169.1, U153.1 (IN1), U153.2 (IN2), U153.3 (BIAS), U153.8 (SNS); also elsewhere on the board
+5V: R151.1, R159.1, R162.1; also elsewhere on the board
GND: C151.2, C152.2, C153.2, C155.2, C156.2, C157.2, C158.2, C159.2, C161.2, C162.2, C165.2, C166.2, C167.2, C206.2, Q152.2 (S), Q153.2 (S), R154.2, R156.2, R157.2, R161.2, R163.2, R167.2, R168.2, R170.2, TP152.1, U151.10 (AGND), U151.15 (PGND1), U151.16 (PGND2), U151.17 (DAP_GND), U152.5 (GND), U152.11 (EP), U153.5 (GND), U153.11 (EP); also elsewhere on the board

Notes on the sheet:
I32 — COORDINATED3.336634V POWER AND RESERVOIR SEQUENCING
I32 controlled debug: normal assembly has R128 and R151 fitted. For external +5V open R128. R162/R163 automatically enable U152. TP154 observes the EN divider; do not drive it. Never parallel active sources. For external main3V3 programming, open R153 first; do not prebias U151 output. Probe U151 V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
+ pin 1
I32: 3.336634V source (11.8k/5.05k),400kHz FPWM. C206680uF/6.3V; R158300mOhm. U153 slews only C206; U202 reset waits180-420ms via R204. Main750mA cold-start stress retained. C162470uF/10V supplies isolated VIN; C15933nF / C16668nF C0G control independent charging. U152/Q152/Q153 mitigate reverse di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
I32: U152 TPS22953 (no QOD). SNS monitors VIN; PG/C165 drive Q153. R166/R167 divide PG for U151 EN. C162470uF input reservoir. U153 SNS follows its main input; PG unused. R168 drains isolated C206. Sustained I25 profile and fixed release heat allocation remain unchanged.

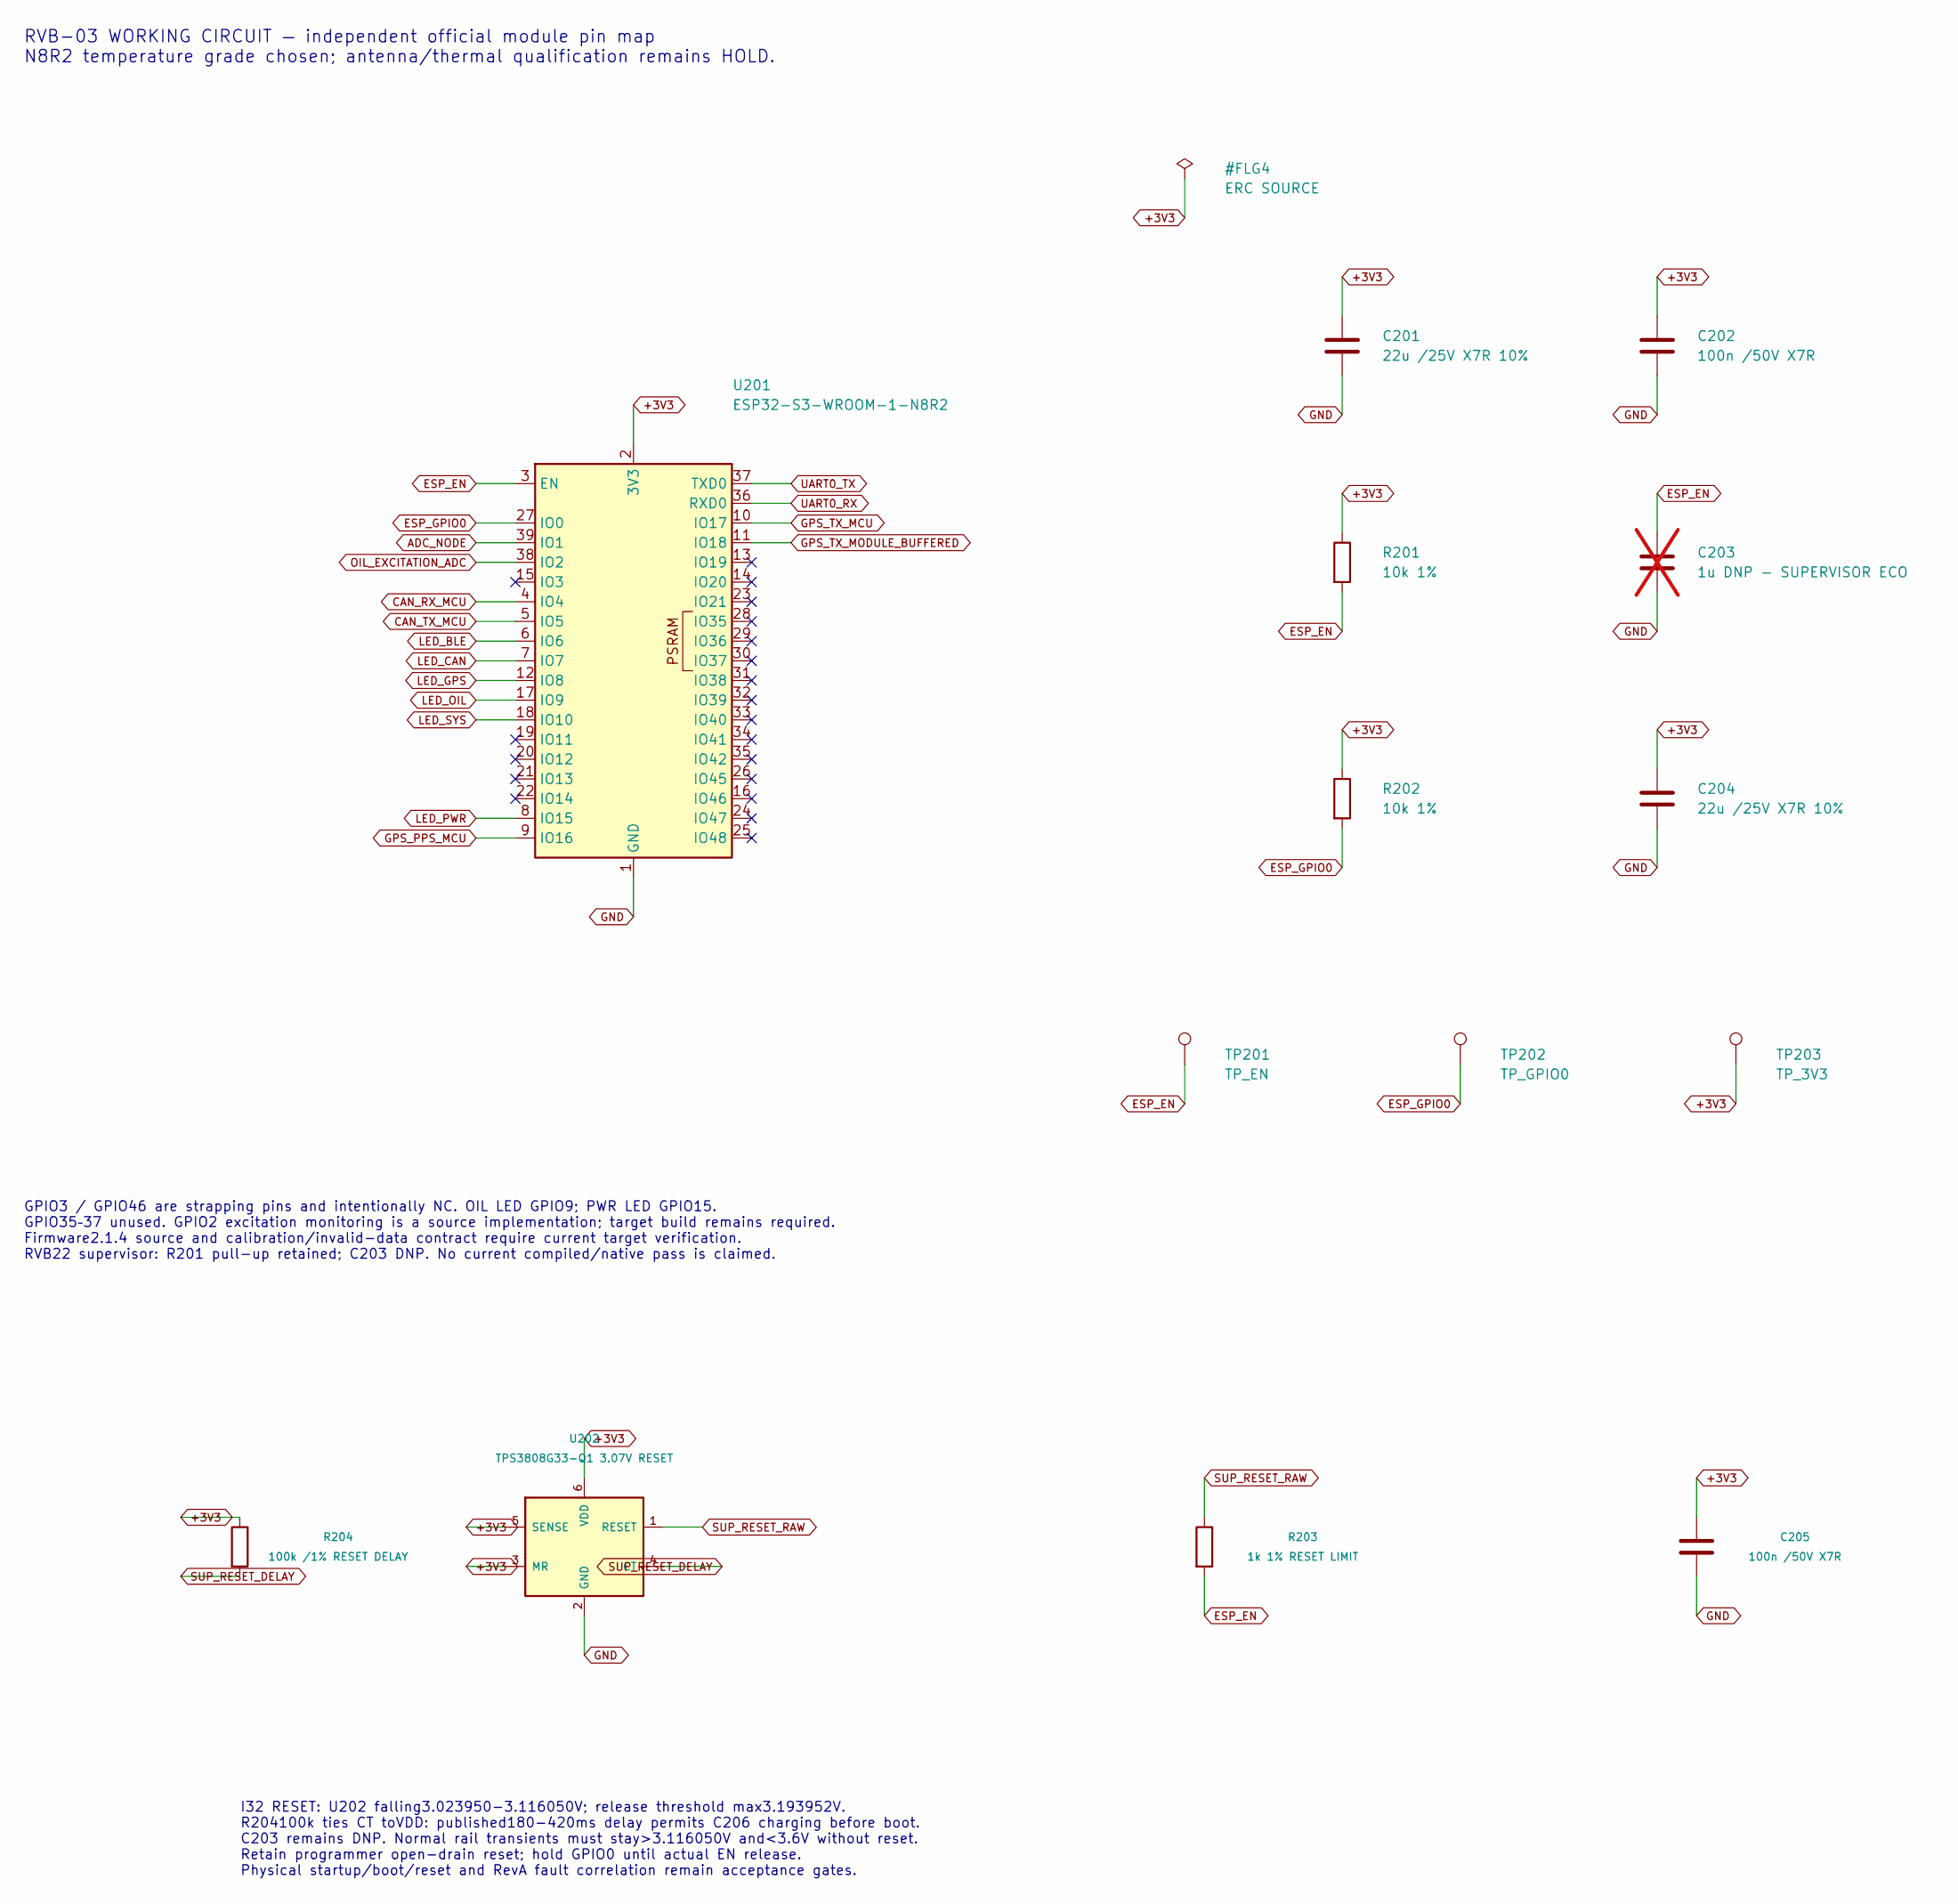
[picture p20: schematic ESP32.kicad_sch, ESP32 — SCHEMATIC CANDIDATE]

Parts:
C201, C204: 22u /25V X7R 10%; C_1210_3225Metric; MPN MCAST32MSB7226KPNA01; LCSC C5372271
C202: 100n /50V X7R; C_0603_1608Metric; MPN GCM188R71H104KA57D; LCSC C85864
C203: 1u DNP - SUPERVISOR ECO; C_0603_1608Metric; MPN GCM188R71C105KA64D; LCSC C161212; not fitted
C205: 100n /50V X7R; C_0603_1608Metric_RVB22_C205; MPN GCM188R71H104KA57D; LCSC C85864
R201, R202: 10k 1%; R_0603_1608Metric; MPN CRCW060310K0FKEA; LCSC C844918
R203: 1k 1% RESET LIMIT; R_0603_1608Metric_RVB22_R203; MPN CRCW06031K00FKEA; LCSC C844920
R204: 100k /1% RESET DELAY; I32_FINISHED_R204; MPN CRCW0603100KFKEA; LCSC C844916
TP201: TP_EN; TestPoint_Pad_D1.5mm; MPN BARE PCB PAD
TP202: TP_GPIO0; TestPoint_Pad_D1.5mm; MPN BARE PCB PAD
TP203: TP_3V3; TestPoint_Pad_D1.5mm; MPN BARE PCB PAD
U201: ESP32-S3-WROOM-1-N8R2; ESP32-S3-WROOM-1_RVB22_U201_TH48; MPN ESP32-S3-WROOM-1-N8R2; LCSC C2913204
U202: TPS3808G33-Q1 3.07V RESET; TPS3808_DBV0006A; MPN TPS3808G33QDBVRQ1; LCSC C414616

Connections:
+3V3: C201.1, C202.1, C204.1, C205.1, R201.1, R202.1, R204.1, TP203.1, U201.2 (3V3), U202.3 (MR), U202.5 (SENSE), U202.6 (VDD); also elsewhere on the board
ADC_NODE: U201.39 (IO1); also elsewhere on the board
CAN_RX_MCU: U201.4 (IO4); also elsewhere on the board
CAN_TX_MCU: U201.5 (IO5); also elsewhere on the board
ESP_EN: C203.1, R201.2, R203.2, TP201.1, U201.3 (EN); also elsewhere on the board
ESP_GPIO0: R202.2, TP202.1, U201.27 (IO0); also elsewhere on the board
GND: C201.2, C202.2, C203.2, C204.2, C205.2, U201.1 (GND), U201.40 (GND), U201.41 (GND), U202.2 (GND); also elsewhere on the board
GPS_PPS_MCU: U201.9 (IO16); also elsewhere on the board
GPS_TX_MCU: U201.10 (IO17); also elsewhere on the board
GPS_TX_MODULE_BUFFERED: U201.11 (IO18); also elsewhere on the board
LED_BLE: U201.6 (IO6); also elsewhere on the board
LED_CAN: U201.7 (IO7); also elsewhere on the board
LED_GPS: U201.12 (IO8); also elsewhere on the board
LED_OIL: U201.17 (IO9); also elsewhere on the board
LED_PWR: U201.8 (IO15); also elsewhere on the board
LED_SYS: U201.18 (IO10); also elsewhere on the board
OIL_EXCITATION_ADC: U201.38 (IO2); also elsewhere on the board
SUP_RESET_DELAY: R204.2, U202.4 (CT)
SUP_RESET_RAW: R203.1, U202.1 (RESET)
UART0_RX: U201.36 (RXD0); also elsewhere on the board
UART0_TX: U201.37 (TXD0); also elsewhere on the board

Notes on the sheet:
RVB-03 WORKING CIRCUIT — independent official module pin map N8R2 temperature grade chosen; antenna/thermal qualification remains HOLD.
GPIO3 / GPIO46 are strapping pins and intentionally NC. OIL LED GPIO9; PWR LED GPIO15. GPIO35–37 unused. GPIO2 excitation monitoring is a source implementation; target build remains required. Firmware2.1.4 source and calibration/invalid-data contract require current target verification. RVB22 super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
I32 RESET: U202 falling3.023950-3.116050V; release threshold max3.193952V. R204100k ties CT toVDD: published180-420ms delay permits C206 charging before boot. C203 remains DNP. Normal rail transients must stay>3.116050V and<3.6V without reset. Retain programmer open-drain reset; hold GPIO0 until ac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

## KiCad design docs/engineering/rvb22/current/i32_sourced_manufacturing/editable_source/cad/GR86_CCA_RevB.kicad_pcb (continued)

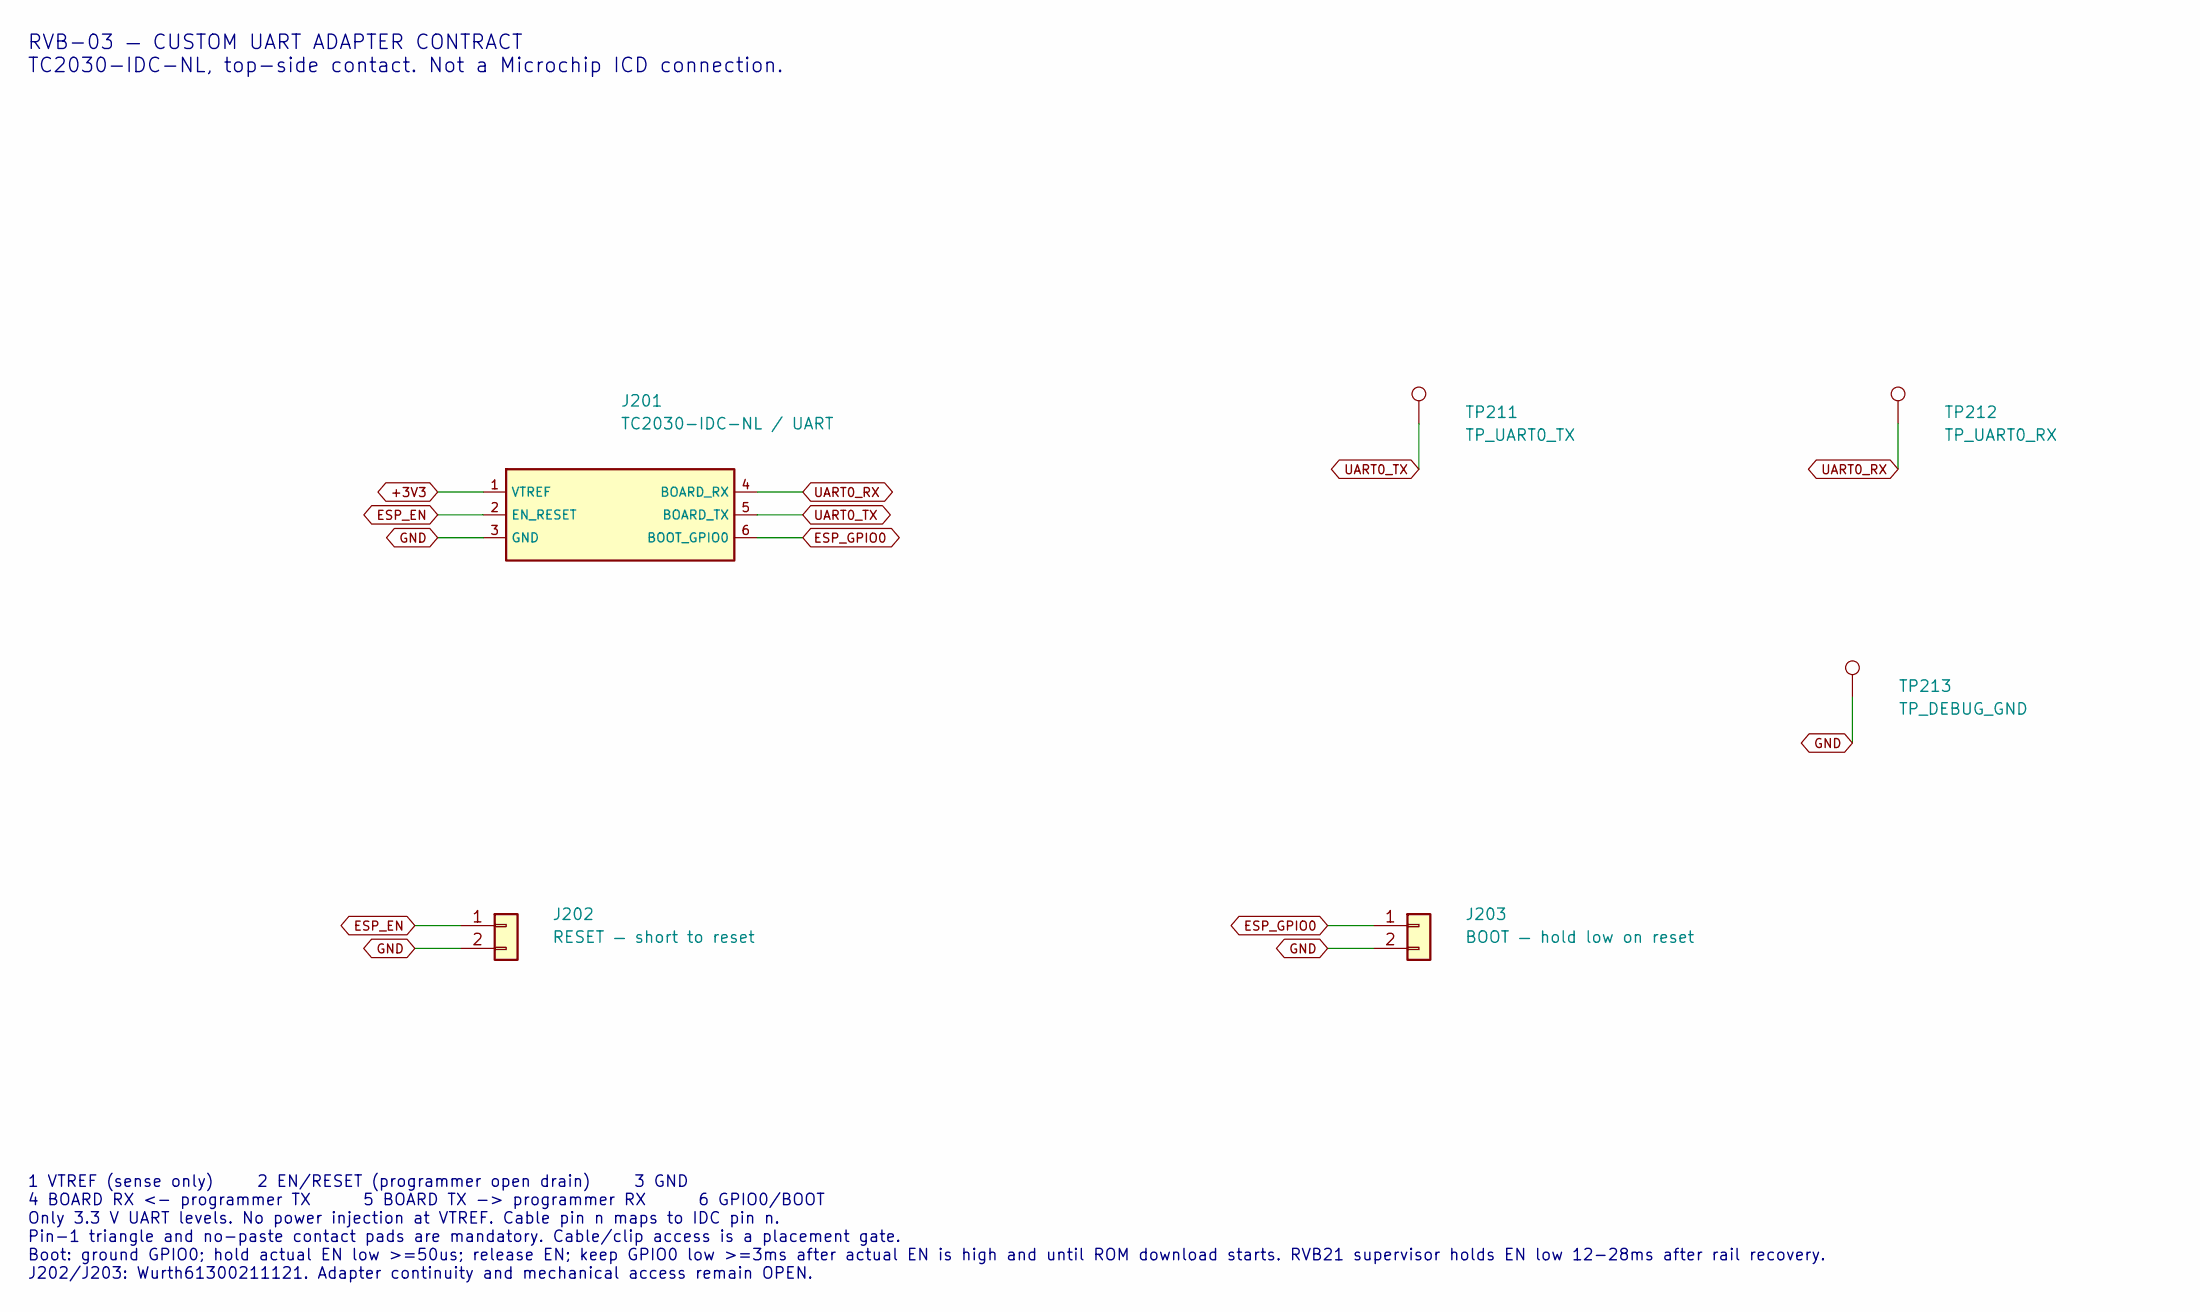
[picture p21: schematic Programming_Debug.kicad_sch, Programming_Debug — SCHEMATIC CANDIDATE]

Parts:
J201: TC2030-IDC-NL / UART; Tag-Connect_TC2030-IDC-NL_2x03_P1.27mm_Vertical; MPN TC2030-IDC-NL (tool, not assembled comp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
J202: RESET — short to reset; Wurth_61300211121_1x02; MPN 61300211121; LCSC C2915055
J203: BOOT — hold low on reset; Wurth_61300211121_1x02; MPN 61300211121; LCSC C2915055
TP211: TP_UART0_TX; TestPoint_Pad_D1.5mm; MPN BARE PCB PAD
TP212: TP_UART0_RX; TestPoint_Pad_D1.5mm; MPN BARE PCB PAD
TP213: TP_DEBUG_GND; TestPoint_Pad_D1.5mm; MPN BARE PCB PAD

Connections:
+3V3: J201.1 (VTREF); also elsewhere on the board
ESP_EN: J201.2 (EN_RESET), J202.1; also elsewhere on the board
ESP_GPIO0: J201.6 (BOOT_GPIO0), J203.1; also elsewhere on the board
GND: J201.3 (GND), J202.2, J203.2, TP213.1; also elsewhere on the board
UART0_RX: J201.4 (BOARD_RX), TP212.1; also elsewhere on the board
UART0_TX: J201.5 (BOARD_TX), TP211.1; also elsewhere on the board

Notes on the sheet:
RVB-03 — CUSTOM UART ADAPTER CONTRACT TC2030-IDC-NL, top-side contact. Not a Microchip ICD connection.
1 VTREF (sense only) 2 EN/RESET (programmer open drain) 3 GND 4 BOARD RX <- programmer TX 5 BOARD TX -> programmer RX 6 GPIO0/BOOT Only 3.3 V UART levels. No power injection at VTREF. Cable pin n maps to IDC pin n. Pin-1 triangle and no-paste contact pads are mandatory. Cable/clip access is a place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


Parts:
C301: 100n /50V X7R; C_0603_1608Metric; MPN GCM188R71H104KA57D; LCSC C85864
C302: 1u /16V X7R; C_0603_1608Metric; MPN GCM188R71C105KA64D; LCSC C161212
D301: ESD2CAN24DBZRQ1; SOT-23; MPN ESD2CAN24DBZRQ1; LCSC C5736151
R301: 0R DNP; R_0603_1608Metric; MPN CRCW06030000Z0EA; not fitted
R302: 1k; R_0603_1608Metric; MPN CRCW06031K00FKEA; LCSC C844920
R303: 10k 1%; R_0603_1608Metric; MPN CRCW060310K0FKEA; LCSC C844918
R306: 120R 1% DNP; R_1206_3216Metric; MPN CRCW1206120RFKEA; not fitted
SJ301: BENCH TERM OPEN; SolderJumper-2_P1.3mm_Open_Pad1.0x1.5mm; MPN BARE PCB OPEN SOLDER LINK
TP301: TP_CANH; TestPoint_Pad_D1.5mm; MPN BARE PCB PAD
TP302: TP_CANL; TestPoint_Pad_D1.5mm; MPN BARE PCB PAD
TP303: TP_CAN_TXD; TestPoint_Pad_D1.5mm; MPN BARE PCB PAD
TP304: TP_CAN_RXD; TestPoint_Pad_D1.5mm; MPN BARE PCB PAD
TP305: TP_CAN_GND; TestPoint_Pad_D1.5mm; MPN BARE PCB PAD
U301: TCAN3403DRBRQ1; TI_DRB0008J_TCAN3403; MPN TCAN3403DRBRQ1; LCSC C32921356

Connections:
+3V3: C301.1, C302.1, R303.1, U301.3 (VCC), U301.5 (VIO); also elsewhere on the board
CANH: D301.1 (IO1), R306.1, TP301.1, U301.7 (CANH); also elsewhere on the board
CANL: D301.2 (IO2), SJ301.2 (B), TP302.1, U301.6 (CANL); also elsewhere on the board
CAN_RXD: R302.1, TP304.1, U301.4 (RXD)
CAN_RX_MCU: R302.2; also elsewhere on the board
CAN_TERM_LINK: R306.2, SJ301.1 (A)
CAN_TXD: R301.2, R303.2, TP303.1, U301.1 (TXD)
CAN_TX_MCU: R301.1; also elsewhere on the board
GND: C301.2, C302.2, D301.3 (GND), TP305.1, U301.2 (GND), U301.8 (STB), U301.9 (EP_GND); also elsewhere on the board

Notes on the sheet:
RVB-04 — VEHICLE RECEIVE DEFAULT / TCAN3403DRBRQ1 R301 DNP inhibits TX. R306 DNP + SJ301 open leave vehicle termination open.
Pin 5 is VIO on TCAN3403; it is NOT VREF or SHDN. Pin 8 STB is hard low for full-bandwidth RX. Standby mode is not used as a silent receive mode. External R303 holds TXD recessive. Vehicle firmware must use listen-only. Isolated bench ACK testing needs R301 fitted and normal mode. CCA receives pass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

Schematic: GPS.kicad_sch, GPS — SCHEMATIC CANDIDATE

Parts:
C401, C402: 22u /25V X7R 10%; C_1210_3225Metric; MPN MCAST32MSB7226KPNA01; LCSC C5372271
C403, C404, C405: 100n /50V X7R; C_0603_1608Metric; MPN GCM188R71H104KA57D; LCSC C85864
D401: SEARCH (blink / no fix); LED_0603_1608Metric; MPN APT1608SGC; LCSC C5875754
D402: TPD1E05U06DPYR; TI_DPY0002A_TPD1E05U06_SMDMask; MPN TPD1E05U06DPYR; LCSC C436349
J401: U.FL-R-SMT-1(80); Hirose_UFL_R_SMT_1_80_RevB; MPN U.FL-R-SMT-1(80); LCSC C88374
L406: 1.6nH 5% RF MATCH; Murata_LQW18AS_1608; MPN LQW18AS1N6J0ZD; LCSC C7295894
R401: 0R GPS ISOLATION; R_0603_1608Metric; MPN CRCW06030000Z0EA; LCSC C844915
R402, R403, R404: 220R; R_0603_1608Metric; MPN AA0603FR-07220RL; LCSC C2100485
R405: 1k; R_0603_1608Metric; MPN CRCW06031K00FKEA; LCSC C844920
R407, R408, R409: 100k; R_0603_1608Metric; MPN CRCW0603100KFKEA; LCSC C844916
R410: 10k /UART idle; R_0603_1608Metric; MPN CRCW060310K0FKEA; LCSC C844918
R411: 100k /off-state; R_0603_1608Metric; MPN CRCW0603100KFKEA; LCSC C844916
TP401: TP_GPS_TX; TestPoint_Pad_D1.5mm; MPN BARE PCB PAD
TP402: TP_GPS_RX; TestPoint_Pad_D1.5mm; MPN BARE PCB PAD
TP403: TP_GPS_PPS; TestPoint_Pad_D1.5mm; MPN BARE PCB PAD
TP404: TP_GPS_3V3; TestPoint_Pad_D1.5mm; MPN BARE PCB PAD
TP405: TP_GPS_GND; TestPoint_Pad_D1.5mm; MPN BARE PCB PAD
U401: PA1616D; CDTop_PA1616D_20Pad_v06; MPN PA1616D
U402, U404: SN74LVC2G125DCUR; VSSOP-8_2.3x2mm_P0.5mm; MPN SN74LVC2G125DCUR; LCSC C21404
U403: MIC5504-3.3YM5-TR; SOT-23-5; MPN MIC5504-3.3YM5-TR; LCSC C88419

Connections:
+3V3: C404.1, R410.1, U402.8 (VCC); also elsewhere on the board
+5V: R401.1; also elsewhere on the board
GND: C401.2, C402.2, C403.2, C404.2, C405.2, D401.1 (K), D402.2 (GND_A), J401.2 (Ext), R407.2, R408.2, R409.2, R411.2, TP405.1, U401.3 (GND), U401.8 (GND), U401.12 (GND), U401.19 (GND), U402.1 (1OE_N), U402.4 (GND), U402.7 (2OE_N), U403.2 (GND), U404.1 (1OE_N), U404.4 (GND), U404.7 (2OE_N); also elsewhere on the board
GPS_3V3: C402.1, C403.1, C405.1, TP404.1, U401.1 (VCC), U403.5 (VOUT), U404.8 (VCC)
GPS_5V_IN: C401.1, R401.2, U403.1 (VIN), U403.3 (EN)
GPS_ANT_RF_BIASED: L406.1, U401.11 (EX_ANT_BIASED)
GPS_EXT_ANT: D402.1 (IO_K), J401.1 (In), L406.2
GPS_FIX_RAW: R409.1, U401.5 (3D_FIX), U404.5 (2A)
GPS_PPS_BUFFER: R403.1, U402.3 (2Y)
GPS_PPS_MCU: R403.2; also elsewhere on the board
GPS_PPS_RAW: R408.1, TP403.1, U401.13 (PPS_2V8), U402.5 (2A)
GPS_RX_BUFFER: R404.1, U404.6 (1Y)
GPS_RX_MODULE: R404.2, TP402.1, U401.10 (RX0)
GPS_SEARCH_BUFFER: R405.1, U404.3 (2Y)
GPS_SEARCH_LED_A: D401.2 (A), R405.2
GPS_TX_BUFFER: R402.1, U402.6 (1Y)
GPS_TX_MCU: R410.2, R411.1, U404.2 (1A); also elsewhere on the board
GPS_TX_MODULE_BUFFERED: R402.2; also elsewhere on the board
GPS_TX_RAW: R407.1, TP401.1, U401.9 (TX0), U402.2 (1A)

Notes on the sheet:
RVB-05 GPS — TX/RX CROSSED; LEVEL BUFFERS; DEDICATED3.3V PA1616D pin1 is upper-left in the manufacturer top view. No electrical pad21.
U402 receives GPS TX/PPS on main3V3; U404 drives GPS RX on GPS3V3. Exact TI input VIH2.0V. R410/R411 set GPIO17 UART idle; GPIO17 may drive LOW briefly at power-up, so firmware renegotiates after boot. GPS-only fixture:1k bleed on main3V3, verify main rail<=0.2V before asserting off-domain behavior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
UART default and external-antenna ESD

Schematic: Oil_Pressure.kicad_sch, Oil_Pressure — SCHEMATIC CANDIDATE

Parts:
C501, C513, C523: 22n /50V X7R; C_0603_1608Metric; MPN CGA3E2X7R1H223K080AE; LCSC C2176922
C502, C531: 100n /50V X7R; C_0603_1608Metric; MPN GCM188R71H104KA57D; LCSC C85864
C503: 100n /100V X7R; C_0805_2012Metric; MPN CGA4J2X7R2A104K125AA; LCSC C342919
C504, C505, C506: 10u /50V X7R; KEMET_C1210_10u50V; MPN C1210C106K5RACTU; LCSC C2167688
C511, C512, C521, C522: 1u /16V X7R; C_0603_1608Metric; MPN GCM188R71C105KA64D; LCSC C161212
C514, C524: 100p /50V C0G5%; C_0603_1608Metric; MPN CGA3E2C0G1H101J080AA; LCSC C76709
C532: 10n /50V C0G 5% OUT HF; C_0603_1608Metric; MPN GRM1885C1H103JA01D; LCSC C85973
D501: ESD2CAN24DBZRQ1; SOT-23; MPN ESD2CAN24DBZRQ1; LCSC C5736151
D502: SS16 /60V Schottky; D_SMA; MPN SS16HE3_B/H; LCSC C266798
D511, D512, D521, D522: PMEG2010BEA,115; Nexperia_SOD323_PMEG2010BEA; MPN PMEG2010BEA,115; LCSC C455041
R501: 27.4k /0.1%; R_0603_1608Metric; MPN TNPW060327K4BEEA; LCSC C2079063
R502, R504: 10k /0.1%; R_0603_1608Metric; MPN TNPW060310K0BEEA; LCSC C844890
R503: 36.5k /0.1%; R_0603_1608Metric; MPN TNPW060336K5BEEA; LCSC C2089518
R505: 118k /0.1%; R_0805_2012Metric; MPN TNPW0805118KBEEA; LCSC C1709453
R506: 100k; R_0603_1608Metric; MPN CRCW0603100KFKEA; LCSC C844916
R507: 4.7R /1% pulse HP; R_2512_6332Metric; MPN CRCW25124R70FKEGHP; LCSC C2075852
R511, R521: 1M /0.1%; R_0805_2012Metric; MPN TNPW08051M00BEEA; LCSC C844679
R512, R522: 4.02k /0.1%; R_0603_1608Metric; MPN TNPW06034K02BEEA; LCSC C844459
R513, R523: 124k /0.1%; R_0805_2012Metric; MPN TNPW0805124KBEEA; LCSC C1709494
R514, R524: 1k /0.1%; R_0603_1608Metric; MPN TNPW06031K00BEEA; LCSC C844891
R515, R525: 220R /1%150ppm; R_0603_1608Metric; MPN AA0603FR-07220RL; LCSC C2100485
TP501: TP_OIL_SIG; TestPoint_Pad_D1.5mm; MPN BARE PCB PAD
TP502: TP_OIL_FILTERED; TestPoint_Pad_D1.5mm; MPN BARE PCB PAD
TP503: TP_ADC_NODE; TestPoint_Pad_D1.5mm; MPN BARE PCB PAD
TP504: TP_OIL_GND; TestPoint_Pad_D1.5mm; MPN BARE PCB PAD
TP505: TP_OIL_5V; TestPoint_Pad_D1.5mm; MPN BARE PCB PAD
TP506: TP_OIL_EXC_ADC; TestPoint_Pad_D1.5mm; MPN BARE PCB PAD
TP507: TP_OIL_SHDN; TestPoint_Pad_D1.5mm; MPN BARE PCB PAD
TP508: TP_OIL_POWER_FAULT; TestPoint_Pad_D1.5mm; MPN BARE PCB PAD
TP509: TP_OIL_EFUSE_RTN; TestPoint_Pad_D1.5mm; MPN BARE PCB PAD
TP510: TP_OIL_EFUSE_OUT; TestPoint_Pad_D1.5mm; MPN BARE PCB PAD
U501: TPS26600PWPR; TI_PWP0016A_TPS2660; MPN TPS26600PWPR; LCSC C544399
U502: OPA2333AIDR; SOIC-8_3.9x4.9mm_P1.27mm; MPN OPA2333AIDR; LCSC C38732

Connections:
+3V3: C531.1, D511.1 (K), D521.1 (K), R506.1, U502.8 (VPOS); also elsewhere on the board
+5V: C502.1, R501.1, R503.1, U501.1 (IN1), U501.2 (IN2); also elsewhere on the board
ADC_NODE: C513.1, D511.2 (A), D512.1 (K), R513.1, R515.2, TP503.1; also elsewhere on the board
GND: C502.2, C503.2, C504.2, C505.2, C506.2, C511.2, C512.2, C513.2, C521.2, C522.2, C523.2, C531.2, C532.2, D501.3 (GND), D502.2 (A), D512.2 (A), D522.2 (A), R512.2, R514.2, R522.2, R524.2, TP504.1, U501.9 (GND), U502.4 (VNEG); also elsewhere on the board
OIL_5V: C503.1, D501.2 (IO2), R507.2, R521.1, TP505.1; also elsewhere on the board
OIL_AMP_OUT: C514.1, R515.1, U502.1 (OUT_A)
OIL_DVDT: C501.1, U501.12 (DVDT)
OIL_EFUSE_OUT: C504.1, C505.1, C506.1, C532.1, D502.1 (K), R507.1, TP510.1, U501.15 (OUT1), U501.16 (OUT2)
OIL_EFUSE_RTN: C501.2, R502.2, R504.2, R505.2, TP509.1, U501.8 (RTN), U501.17 (EP_RTN)
OIL_EXCITATION_ADC: C523.1, D521.2 (A), D522.1 (K), R523.1, R525.2, TP506.1; also elsewhere on the board
OIL_EXC_AMP_OUT: C524.1, R525.1, U502.7 (OUT_B)
OIL_EXC_FB: C524.2, R523.2, R524.1, U502.6 (INB_N)
OIL_EXC_FILTERED: C521.1, C522.1, R521.2, R522.1, U502.5 (INB_P)
OIL_FB: C514.2, R513.2, R514.1, U502.2 (INA_N)
OIL_FILTERED: C511.1, C512.1, R511.2, R512.1, TP502.1, U502.3 (INA_P)
OIL_ILIM: R505.1, U501.11 (ILIM)
OIL_OVP: R503.2, R504.1, U501.5 (OVP)
OIL_POWER_FAULT_N: R506.2, TP508.1, U501.14 (FLT_N)
OIL_SHDN: TP507.1, U501.7 (SHDN)
OIL_SIG: D501.1 (IO1), R511.1, TP501.1; also elsewhere on the board
OIL_UVLO: R501.2, R502.1, U501.3 (UVLO)

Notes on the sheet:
RVB-06 — HONEYWELL150psi /RATIOMETRIC5V /GPIO1 ADC Connector signal → 1:249.76 attenuator → precision gain125 → low-impedance ADC drive. OIL5V excitation is current limited and reverse-current blocked; no direct5V-to-ADC path.
RTN is a private eFuse reference; do not short it to GND. Its thermal pad also goes to RTN. MODE floats for circuit-breaker/auto-retry. SHDN uses its internal2–3.4V pullup; TP permits temporary low-to-RTN reset. UVLO is externally programmed: grounding it would select a14.9V default and disable a5V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
RVB22 C532 OUT-to-GND HF bypass:10nF C0G50V; never privateRTN. Direct U501 OUTpad16 feed also joins C504 OUTland and existing In1 OUTcopper; use actual non-tree nodal model. Preserve C504/C505/C506 bulk and C514 feedback. New-loop25nH/common-star10nH are allocations; native fill and hardware remain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

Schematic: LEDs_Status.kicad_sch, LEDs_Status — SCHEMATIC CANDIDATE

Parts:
D601: PWR; LED_0603_1608Metric; MPN APT1608SGC; LCSC C5875754
D602: BLE; LED_0603_1608Metric; MPN APT1608SGC; LCSC C5875754
D603: CAN; LED_0603_1608Metric; MPN APT1608SGC; LCSC C5875754
D604: GPS; LED_0603_1608Metric; MPN APT1608SGC; LCSC C5875754
D605: SYS; LED_0603_1608Metric; MPN APT1608SGC; LCSC C5875754
D606: OIL; LED_0603_1608Metric; MPN APT1608SGC; LCSC C5875754
R601: 1k / GPIO15; R_0603_1608Metric; MPN CRCW06031K00FKEA; LCSC C844920
R602: 1k / GPIO6; R_0603_1608Metric; MPN CRCW06031K00FKEA; LCSC C844920
R603: 1k / GPIO7; R_0603_1608Metric; MPN CRCW06031K00FKEA; LCSC C844920
R604: 1k / GPIO8; R_0603_1608Metric; MPN CRCW06031K00FKEA; LCSC C844920
R605: 1k / GPIO10; R_0603_1608Metric; MPN CRCW06031K00FKEA; LCSC C844920
R606: 1k / GPIO9; R_0603_1608Metric; MPN CRCW06031K00FKEA; LCSC C844920

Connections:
GND: D601.1 (K), D602.1 (K), D603.1 (K), D604.1 (K), D605.1 (K), D606.1 (K); also elsewhere on the board
LED_BLE: R602.1; also elsewhere on the board
LED_BLE_A: D602.2 (A), R602.2
LED_CAN: R603.1; also elsewhere on the board
LED_CAN_A: D603.2 (A), R603.2
LED_GPS: R604.1; also elsewhere on the board
LED_GPS_A: D604.2 (A), R604.2
LED_OIL: R606.1; also elsewhere on the board
LED_OIL_A: D606.2 (A), R606.2
LED_PWR: R601.1; also elsewhere on the board
LED_PWR_A: D601.2 (A), R601.2
LED_SYS: R605.1; also elsewhere on the board
LED_SYS_A: D605.2 (A), R605.2

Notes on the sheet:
STATUS INDICATORS — ACTIVE HIGH GPIO3/GPIO46 strapping pins are free of external LED loads in Rev B. Firmware Rev B contract moves OIL to GPIO9 and PWR to GPIO15.
1000ohm current limiting. See qualification/LED_STRAP_REVIEW.md. Indicators represent firmware state and do not replace physical rail/bus measurements.

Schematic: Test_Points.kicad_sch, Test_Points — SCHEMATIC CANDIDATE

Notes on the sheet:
TEST AND ISOLATION DIRECTORY Probe points are placed on the functional sheets beside their circuits. Bring-up removes rail0ohm links before testing each source independently. R301 TXD and R306 termination are DNP; SJ301 is open for vehicle tap use. L406 RF matching inductor is factory fitted in RVB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



Board: 4 copper layers, 88.3 x 61.3 mm, 224 parts (113 on the bottom side), 104 nets.

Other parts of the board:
MH901, MH902, MH903, MH904: 4.4mm NPTH; MountingHole_4.4mm_Outboard

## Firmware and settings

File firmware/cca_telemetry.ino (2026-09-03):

// ===== GR86 CCA Telemetry: stability-first RaceChrono bridge =====
//
// This sketch intentionally favors deterministic recovery over aggressive retries:
// - BLE advertising is event-driven and never stop/start-cycled from loop().
// - RaceChrono uses its standard unencrypted 0x1FF8 protocol (no passkey/token shim).
// - CAN is always accept-all at the controller; filtering happens in software.
// - CAN silence is normal. Only an actual TWAI fault triggers recovery.
// - CAN bring-up and recovery are non-blocking, so BLE/GPS/CLI stay alive.
// - CAN frames are coalesced by ID before BLE transmission to prevent backlog storms.
//
// Board: ESP32-S3 Dev Module
// Working regression toolchain: Arduino-ESP32 3.3.6 + NimBLE-Arduino 2.3.6

#include <Arduino.h>
#include <NimBLEDevice.h>
#include <Preferences.h>

#include <driver/twai.h>
#include <esp_err.h>
#include <esp_heap_caps.h>
#include <esp_system.h>
#include <esp_task_wdt.h>

#if defined(__has_include)
#  if __has_include(<esp_idf_version.h>)
#    include <esp_idf_version.h>
#  endif
#endif

#include <ctype.h>
#include <math.h>
#include <stdint.h>
#include <stdio.h>
#include <string.h>

#include "config.h"
#include "src/gps_nmea.h"
#include "src/led_status.h"
#include "src/nvs_cfg.h"

namespace cca {

// -----------------------------------------------------------------------------
// Build identity
// -----------------------------------------------------------------------------

static constexpr const char* BUILD_ID = "2.0.1-racechrono-discovery-20260903";

// -----------------------------------------------------------------------------
// Hardware pins
// -----------------------------------------------------------------------------

static constexpr int CAN_TX_GPIO = 5;
static constexpr int CAN_RX_GPIO = 4;

static constexpr int GPS_RX_GPIO = 18;  // GPS TX -> ESP RX
static constexpr int GPS_TX_GPIO = 17;  // GPS RX <- ESP TX

static constexpr int OIL_ADC_PIN = 1;

// -----------------------------------------------------------------------------
// RaceChrono DIY BLE UUIDs
// -----------------------------------------------------------------------------

static constexpr uint16_t RC_SERVICE_UUID = 0x1FF8;
static constexpr uint16_t RC_CHAR_CAN_UUID = 0x0001;
static constexpr uint16_t RC_CHAR_FILTER_UUID = 0x0002;
static constexpr uint16_t RC_CHAR_GPS_UUID = 0x0003;
static constexpr uint16_t RC_CHAR_GPS_TIME_UUID = 0x0004;

// -----------------------------------------------------------------------------
// General helpers
// -----------------------------------------------------------------------------

static inline bool timeReached(uint32_t now, uint32_t deadline) {
  return static_cast<int32_t>(now - deadline) >= 0;
}

static inline uint32_t elapsedMs(uint32_t now, uint32_t then) {
  return now - then;
}

static inline float clampFloat(float value, float low, float high) {
  if (value < low) return low;
  if (value > high) return high;
  return value;
}

static const char* resetReasonName(esp_reset_reason_t reason) {
  switch (reason) {
    case ESP_RST_UNKNOWN:   return "UNKNOWN";
    case ESP_RST_POWERON:   return "POWERON";
    case ESP_RST_EXT:       return "EXT";
    case ESP_RST_SW:        return "SW";
    case ESP_RST_PANIC:     return "PANIC";
    case ESP_RST_INT_WDT:   return "INT_WDT";
    case ESP_RST_TASK_WDT:  return "TASK_WDT";
    case ESP_RST_WDT:       return "WDT";
    case ESP_RST_DEEPSLEEP: return "DEEPSLEEP";
    case ESP_RST_BROWNOUT:  return "BROWNOUT";
    case ESP_RST_SDIO:      return "SDIO";
#ifdef ESP_RST_USB
    case ESP_RST_USB:       return "USB";
#endif
#ifdef ESP_RST_JTAG
    case ESP_RST_JTAG:      return "JTAG";
#endif
#ifdef ESP_RST_CPU_LOCKUP
    case ESP_RST_CPU_LOCKUP:return "CPU_LOCKUP";
#endif
    default:                return "OTHER";
  }
}

static esp_reset_reason_t g_bootResetReason = ESP_RST_UNKNOWN;

// -----------------------------------------------------------------------------
// Watchdog
// -----------------------------------------------------------------------------

static void initWatchdog() {
  esp_err_t initResult = ESP_OK;

#if defined(ESP_IDF_VERSION_MAJOR) && (ESP_IDF_VERSION_MAJOR >= 5)
  esp_task_wdt_config_t config = {};
  config.timeout_ms = 5000;
  config.idle_core_mask = 0;
  config.trigger_panic = true;
  initResult = esp_task_wdt_init(&config);
#else
  initResult = esp_task_wdt_init(5, true);
#endif

  if (initResult != ESP_OK && initResult != ESP_ERR_INVALID_STATE) {
    Serial.printf("WARN: task watchdog init failed: %d\n",
                  static_cast<int>(initResult));
  }

  const esp_err_t addResult = esp_task_wdt_add(nullptr);
  if (addResult != ESP_OK && addResult != ESP_ERR_INVALID_STATE &&
      addResult != ESP_ERR_INVALID_ARG) {
    Serial.printf("WARN: task watchdog add failed: %d\n",
                  static_cast<int>(addResult));
  }
}

// -----------------------------------------------------------------------------
// Configuration and runtime filtering
// -----------------------------------------------------------------------------

static Preferences g_prefs;
static constexpr const char* CFG_NAMESPACE = "cca_cfg";

static bool g_profileEnabled = true;
static uint16_t g_oilPublishPeriodMs = 40;

struct __attribute__((packed)) StoredPidDivider {
  uint16_t pid;
  uint8_t divider;
};

static constexpr size_t MAX_CUSTOM_DIVIDERS = 64;

struct __attribute__((packed)) StoredDividerBlob {
  uint16_t count;
  StoredPidDivider items[MAX_CUSTOM_DIVIDERS];
};

static StoredPidDivider g_customDividers[MAX_CUSTOM_DIVIDERS] = {};
static uint16_t g_customDividerCount = 0;

static int customDividerIndex(uint32_t pid) {
  if (pid > 0xFFFFu) return -1;
  for (uint16_t i = 0; i < g_customDividerCount; ++i) {
    if (g_customDividers[i].pid == static_cast<uint16_t>(pid)) {
      return static_cast<int>(i);
    }
  }
  return -1;
}

static uint8_t customDividerFor(uint32_t pid) {
  const int index = customDividerIndex(pid);
  if (index < 0) return 0;
  uint8_t divider = g_customDividers[index].divider;
  return divider == 0 ? 1 : divider;
}

static bool setCustomDivider(uint32_t pid, uint8_t divider) {
  if (pid > 0x7FFu) return false;
  if (divider == 0) divider = 1;

  const int existing = customDividerIndex(pid);
  if (existing >= 0) {
    g_customDividers[existing].divider = divider;
    return true;
  }

  if (g_customDividerCount >= MAX_CUSTOM_DIVIDERS) return false;
  g_customDividers[g_customDividerCount].pid = static_cast<uint16_t>(pid);
  g_customDividers[g_customDividerCount].divider = divider;
  ++g_customDividerCount;
  return true;
}

static void clearCustomDividers() {
  memset(g_customDividers, 0, sizeof(g_customDividers));
  g_customDividerCount = 0;
}

static constexpr size_t MAX_DENIED_PIDS = 64;
static uint32_t g_deniedPids[MAX_DENIED_PIDS] = {};
static size_t g_deniedPidCount = 0;

static bool isDenied(uint32_t pid) {
  for (size_t i = 0; i < g_deniedPidCount; ++i) {
    if (g_deniedPids[i] == pid) return true;
  }
  return false;
}

static void denyPid(uint32_t pid) {
  if (isDenied(pid)) return;
  if (g_deniedPidCount < MAX_DENIED_PIDS) {
    g_deniedPids[g_deniedPidCount++] = pid;
  }
}

static void undenyPid(uint32_t pid) {
  for (size_t i = 0; i < g_deniedPidCount; ++i) {
    if (g_deniedPids[i] != pid) continue;
    for (size_t j = i + 1; j < g_deniedPidCount; ++j) {
      g_deniedPids[j - 1] = g_deniedPids[j];
    }
    --g_deniedPidCount;
    return;
  }
}

static void clearDeniedPids() {
  memset(g_deniedPids, 0, sizeof(g_deniedPids));
  g_deniedPidCount = 0;
}

struct RequestedPid {
  uint32_t pid;
  uint16_t intervalMs;
  bool used;
};

static constexpr size_t MAX_REQUESTED_PIDS = 128;
static RequestedPid g_requestedPids[MAX_REQUESTED_PIDS] = {};
static bool g_raceChronoFilterActive = false;
static bool g_raceChronoAllowAll = false;
static uint16_t g_raceChronoAllowAllIntervalMs = 0;
static uint32_t g_filterCommandCount = 0;

static void clearRaceChronoFilter() {
  memset(g_requestedPids, 0, sizeof(g_requestedPids));
  g_raceChronoFilterActive = false;
  g_raceChronoAllowAll = false;
  g_raceChronoAllowAllIntervalMs = 0;
}

static RequestedPid* findRequestedPid(uint32_t pid) {
  for (size_t i = 0; i < MAX_REQUESTED_PIDS; ++i) {
    if (g_requestedPids[i].used && g_requestedPids[i].pid == pid) {
      return &g_requestedPids[i];
    }
  }
  return nullptr;
}

static bool requestPid(uint32_t pid, uint16_t intervalMs) {
  if (RequestedPid* existing = findRequestedPid(pid)) {
    existing->intervalMs = intervalMs;
    return true;
  }

  for (size_t i = 0; i < MAX_REQUESTED_PIDS; ++i) {
    if (g_requestedPids[i].used) continue;
    g_requestedPids[i].pid = pid;
    g_requestedPids[i].intervalMs = intervalMs;
    g_requestedPids[i].used = true;
    return true;
  }

  return false;
}

static size_t requestedPidCount() {
  size_t count = 0;
  for (size_t i = 0; i < MAX_REQUESTED_PIDS; ++i) {
    if (g_requestedPids[i].used) ++count;
  }
  return count;
}

static uint8_t profileDividerFor(uint32_t pid) {
  const auto* map = ACTIVE_PID_MAP;
  if (map != nullptr) {
    for (size_t i = 0; i < map->ruleCount; ++i) {
      if (map->rules[i].pid == pid) {
        const uint8_t divider = map->rules[i].divider;
        return divider == 0 ? 1 : divider;
      }
    }
    if (map->policyDividerForId != nullptr) {
      const uint8_t divider = map->policyDividerForId(pid);
      if (divider != 0) return divider;
    }
  }

  return DEFAULT_UPDATE_RATE_DIVIDER == 0 ? 1
                                          : DEFAULT_UPDATE_RATE_DIVIDER;
}

static bool profileAllows(uint32_t pid) {
  const auto* map = ACTIVE_PID_MAP;
  if (map == nullptr || map->isCanIdWhitelisted == nullptr) return false;
  return map->isCanIdWhitelisted(pid);
}

struct RouteDecision {
  bool allowed;
  uint16_t minimumIntervalMs;
};

static RouteDecision routeDecision(uint32_t pid) {
  RouteDecision result = {false, 40};

  if (isDenied(pid)) return result;

  // A serial ALLOW command is an explicit operator override.
  const uint8_t customDivider = customDividerFor(pid);
  if (customDivider != 0) {
    result.allowed = true;
    uint32_t customInterval = static_cast<uint32_t>(customDivider) * 10u;
    if (customInterval < 10u) customInterval = 10u;
    if (customInterval > 2000u) customInterval = 2000u;
    result.minimumIntervalMs = static_cast<uint16_t>(customInterval);
    return result;
  }

  // PROFILE OFF is the deliberate bench/sniff mode. It ignores RaceChrono's
  // requested PID set but still honors the deny list and the BLE global cap.
  if (!g_profileEnabled) {
    result.allowed = true;
    result.minimumIntervalMs = 10;
    return result;
  }

  // Once RaceChrono sends a filter command, follow the standard protocol.
  if (g_raceChronoFilterActive) {
    if (g_raceChronoAllowAll) {
      result.allowed = true;
      result.minimumIntervalMs =
          g_raceChronoAllowAllIntervalMs == 0
              ? 10
              : g_raceChronoAllowAllIntervalMs;
      return result;
    }

    if (RequestedPid* requested = findRequestedPid(pid)) {
      result.allowed = true;
      result.minimumIntervalMs =
          requested->intervalMs == 0 ? 10 : requested->intervalMs;
      return result;
    }

    return result;
  }

  // Before RaceChrono sends filters, use the compiled GR86 profile so the
  // device still streams useful data in generic BLE clients.
  if (!profileAllows(pid)) return result;

  result.allowed = true;
  if (pid == 0x710u) {
    result.minimumIntervalMs = g_oilPublishPeriodMs;
  } else if (pid == 0x777u) {
    result.minimumIntervalMs = 2000;
  } else {
    const uint8_t divider = profileDividerFor(pid);
    uint32_t interval = static_cast<uint32_t>(divider) * 10u;
    // Cap per-ID output at 25 Hz even for profile entries with divider 1.
    if (interval < 40u) interval = 40u;
    if (interval > 2000u) interval = 2000u;
    result.minimumIntervalMs = static_cast<uint16_t>(interval);
  }

  return result;
}

static void loadRuntimeConfig() {
  g_profileEnabled = true;
  g_oilPublishPeriodMs = 40;
  clearCustomDividers();

  if (!g_prefs.begin(CFG_NAMESPACE, true)) return;

  if (g_prefs.isKey("profile")) {
    g_profileEnabled = g_prefs.getUChar("profile", 1) != 0;
  }

  if (g_prefs.isKey("oil_rate")) {
    const uint16_t storedRate = g_prefs.getUShort("oil_rate", 40);
    if (storedRate >= 10 && storedRate <= 2000) {
      g_oilPublishPeriodMs = storedRate;
    }
  }

  const size_t blobLength = g_prefs.getBytesLength("dividers");
  if (blobLength >= sizeof(uint16_t)) {
    StoredDividerBlob blob = {};
    const size_t readLength =
        g_prefs.getBytes("dividers", &blob, sizeof(blob));
    if (readLength >= sizeof(uint16_t)) {
      uint16_t count = blob.count;
      if (count > MAX_CUSTOM_DIVIDERS) count = MAX_CUSTOM_DIVIDERS;
      for (uint16_t i = 0; i < count; ++i) {
        if (blob.items[i].pid <= 0x7FFu) {
          setCustomDivider(blob.items[i].pid, blob.items[i].divider);
        }
      }
    }
  }

  g_prefs.end();
}

static bool saveRuntimeConfig() {
  if (!g_prefs.begin(CFG_NAMESPACE, false)) return false;
  ScopedNvsWrite writeGuard;

  bool ok = true;
  if (g_prefs.putUChar("profile", g_profileEnabled ? 1 : 0) !=
      sizeof(uint8_t)) {
    ok = false;
  }
  if (g_prefs.putUShort("oil_rate", g_oilPublishPeriodMs) !=
      sizeof(uint16_t)) {
    ok = false;
  }

  StoredDividerBlob blob = {};
  blob.count = g_customDividerCount;
  for (uint16_t i = 0; i < g_customDividerCount; ++i) {
    blob.items[i] = g_customDividers[i];
  }
  if (g_prefs.putBytes("dividers", &blob, sizeof(blob)) != sizeof(blob)) {
    ok = false;
  }

  g_prefs.end();
  return ok;
}

// -----------------------------------------------------------------------------
// BLE transport
// -----------------------------------------------------------------------------

static NimBLEServer* g_bleServer = nullptr;
static NimBLEAdvertising* g_bleAdvertising = nullptr;
static NimBLEService* g_bleService = nullptr;
static NimBLECharacteristic* g_canCharacteristic = nullptr;
static NimBLECharacteristic* g_filterCharacteristic = nullptr;
static NimBLECharacteristic* g_gpsCharacteristic = nullptr;
static NimBLECharacteristic* g_gpsTimeCharacteristic = nullptr;

static volatile bool g_bleConnected = false;
static volatile bool g_canSubscribed = false;
static volatile bool g_gpsSubscribed = false;
static volatile bool g_gpsTimeSubscribed = false;

static uint16_t g_bleMtu = 23;
static uint32_t g_bleConnectCount = 0;
static uint32_t g_bleDisconnectCount = 0;
static int g_lastBleDisconnectReason = 0;
static uint32_t g_lastBleConnectMs = 0;
static uint32_t g_lastBleDisconnectMs = 0;
static uint32_t g_advertisingStartCount = 0;
static uint32_t g_advertisingStartFailures = 0;
static uint32_t g_nextAdvertisingCheckMs = 0;

static uint32_t g_bleNotifySuccesses = 0;
static uint32_t g_bleNotifyFailures = 0;
static uint32_t g_bleNotifyRateDrops = 0;
static uint32_t g_bleNotifyUnsubscribedDrops = 0;
static uint32_t g_bleNotifyBackoffUntilMs = 0;
static uint32_t g_lastBleNotifyFailureMs = 0;

// Shared token bucket. GPS consumes ~11 notifications/s; the remaining budget
// is available for CAN. This prevents a noisy bus from starving NimBLE.
static constexpr uint16_t BLE_TOKEN_CAPACITY = 24;
static constexpr uint16_t BLE_TOKEN_RATE_PER_SECOND = 120;
static uint16_t g_bleTokens = BLE_TOKEN_CAPACITY;
static uint32_t g_bleTokenLastRefillMs = 0;

static bool isBleConnected() {
  return g_bleConnected && g_bleServer != nullptr &&
         g_bleServer->getConnectedCount() > 0;
}

static void refillBleTokens(uint32_t now) {
  if (g_bleTokenLastRefillMs == 0) {
    g_bleTokenLastRefillMs = now;
    g_bleTokens = BLE_TOKEN_CAPACITY;
    return;
  }

  const uint32_t elapsed = now - g_bleTokenLastRefillMs;
  if (elapsed == 0) return;

  const uint32_t add =
      (elapsed * static_cast<uint32_t>(BLE_TOKEN_RATE_PER_SECOND)) / 1000u;
  if (add == 0) return;

  uint32_t next = static_cast<uint32_t>(g_bleTokens) + add;
  if (next > BLE_TOKEN_CAPACITY) next = BLE_TOKEN_CAPACITY;
  g_bleTokens = static_cast<uint16_t>(next);

  const uint32_t consumedMs =
      (add * 1000u) / static_cast<uint32_t>(BLE_TOKEN_RATE_PER_SECOND);
  g_bleTokenLastRefillMs += consumedMs == 0 ? 1 : consumedMs;
}

static bool takeBleToken(uint32_t now) {
  refillBleTokens(now);
  if (g_bleTokens == 0) {
    ++g_bleNotifyRateDrops;
    return false;
  }
  --g_bleTokens;
  return true;
}

static bool notifyCharacteristic(NimBLECharacteristic* characteristic,
                                 bool subscribed,
                                 const uint8_t* data,
                                 size_t length,
                                 uint32_t now) {
  if (!isBleConnected() || characteristic == nullptr) return false;

  if (!subscribed) {
    ++g_bleNotifyUnsubscribedDrops;
    return false;
  }

  if (!timeReached(now, g_bleNotifyBackoffUntilMs)) return false;
  if (!takeBleToken(now)) return false;

  characteristic->setValue(data, length);
  if (characteristic->notify()) {
    ++g_bleNotifySuccesses;
    return true;
  }

  ++g_bleNotifyFailures;
  g_lastBleNotifyFailureMs = now;
  // A short quiet period is enough to let NimBLE drain. Do not restart BLE.
  g_bleNotifyBackoffUntilMs = now + 100;
  return false;
}

static void startAdvertisingIfNeeded(uint32_t now, bool forceCheck = false) {
  if (g_bleAdvertising == nullptr || isBleConnected()) return;
  if (!forceCheck && !timeReached(now, g_nextAdvertisingCheckMs)) return;

  g_nextAdvertisingCheckMs = now + 3000;
  if (g_bleAdvertising->isAdvertising()) return;

  if (g_bleAdvertising->start()) {
    ++g_advertisingStartCount;
    Serial.println("BLE: advertising");
  } else {
    ++g_advertisingStartFailures;
    Serial.println("WARN: BLE advertising start rejected; retry scheduled");
  }
}

class ServerCallbacks final : public NimBLEServerCallbacks {
 public:
  void onConnect(NimBLEServer*, NimBLEConnInfo& connInfo) override {
    g_bleConnected = true;
    g_canSubscribed = false;
    g_gpsSubscribed = false;
    g_gpsTimeSubscribed = false;
    g_bleMtu = connInfo.getMTU();
    g_lastBleConnectMs = millis();
    ++g_bleConnectCount;
    g_bleNotifyBackoffUntilMs = 0;
    g_bleTokens = BLE_TOKEN_CAPACITY;
    g_bleTokenLastRefillMs = millis();

    // RaceChrono sends a fresh filter set after connection.
    clearRaceChronoFilter();

    Serial.printf(
        "BLE: connected handle=%u interval=%.2fms timeout=%.2fs mtu=%u\n",
        static_cast<unsigned>(connInfo.getConnHandle()),
        static_cast<double>(connInfo.getConnInterval()) * 1.25,
        static_cast<double>(connInfo.getConnTimeout()) * 0.010,
        static_cast<unsigned>(g_bleMtu));
  }

  void onDisconnect(NimBLEServer*, NimBLEConnInfo&, int reason) override {
    g_bleConnected = false;
    g_canSubscribed = false;
    g_gpsSubscribed = false;
    g_gpsTimeSubscribed = false;
    g_lastBleDisconnectReason = reason;
    g_lastBleDisconnectMs = millis();
    ++g_bleDisconnectCount;
    g_nextAdvertisingCheckMs = millis() + 1000;

    // Do not touch TWAI, the PID cache, GPS, or the advertiser here.
    // NimBLE's advertiseOnDisconnect handles the normal recovery path.
    Serial.printf("BLE: disconnected reason=%d; state retained\n", reason);
  }

  void onMTUChange(uint16_t mtu, NimBLEConnInfo&) override {
    g_bleMtu = mtu;
    Serial.printf("BLE: MTU=%u\n", static_cast<unsigned>(mtu));
  }
};

static ServerCallbacks g_serverCallbacks;

class SubscriptionCallbacks final : public NimBLECharacteristicCallbacks {
 public:
  explicit SubscriptionCallbacks(volatile bool* flag) : flag_(flag) {}

  void onSubscribe(NimBLECharacteristic*,
                   NimBLEConnInfo&,
                   uint16_t subscriptionValue) override {
    if (flag_ != nullptr) {
      *flag_ = subscriptionValue != 0;
    }
  }

  void onStatus(NimBLECharacteristic*, int code) override {
    // Notifications report zero on completion. Any non-zero status is treated
    // as backpressure; pause briefly instead of tearing down the connection.
    if (code == 0) return;
    ++g_bleNotifyFailures;
    g_lastBleNotifyFailureMs = millis();
    g_bleNotifyBackoffUntilMs = g_lastBleNotifyFailureMs + 100u;
  }

 private:
  volatile bool* flag_;
};

static SubscriptionCallbacks g_canSubscriptionCallbacks(&g_canSubscribed);
static SubscriptionCallbacks g_gpsSubscriptionCallbacks(&g_gpsSubscribed);
static SubscriptionCallbacks g_gpsTimeSubscriptionCallbacks(
    &g_gpsTimeSubscribed);
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
void loop() {
  cca::loopImpl();
}

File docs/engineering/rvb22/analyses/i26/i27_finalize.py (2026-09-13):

#!/usr/bin/env python3
"""I27 final pre-hardware adjudication for GND-02.

Runs only after I26 source-bound verification has regenerated its evidence.
Preserves literal 290-row criterion closure states and moves only GND-02's
parallel desktop/prehardware status from actionable to bounded-inference closed.
No physical or supplier test is claimed.
"""
from __future__ import annotations
import collections, json, math
from pathlib import Path

D=Path(__file__).resolve().parent
W=D.parents[1]
SOURCE='a04f42b358fa65a332128115a7b648e1a2297531ecb47466ac24697de536a936'
EXPECTED_FAILED={7:'CAN_TX_MCU',10:'CAN_TX_MCU',11:'CAN_TX_MCU',12:'CAN_TX_MCU',17:'ESP_EN',19:'ESP_EN',39:'GPS_SEARCH_BUFFER'}

def load(p): return json.loads(p.read_text())
def save(p,v): p.write_text(json.dumps(v,indent=2,ensure_ascii=False)+'\n')
def req(x,msg):
    if not x: raise ValueError(msg)

def microstrip_z(w,h,er):
    u=w/h
    ee=(er+1)/2+(er-1)/2*((1/math.sqrt(1+12/u)+0.04*(1-u)**2) if u<1 else 1/math.sqrt(1+12/u))
    if u<=1: z=60/math.sqrt(ee)*math.log(8/u+0.25*u)
    else: z=120*math.pi/(math.sqrt(ee)*(u+1.393+0.667*math.log(u+1.444)))
    return z,ee

def build_bound():
    exp=load(D/'EXPANDED_RETURN_SCOPE.json')
    paths=load(D/'TRANSFER_SCREEN_PATHS_EXPLORATORY.json')
    hist=load(D/'HISTORICAL_54_RETURN_FINDINGS.json')
    req(hist['source_PCB_sha256']==SOURCE and exp['source_PCB_sha256']==SOURCE,'I27 return evidence is not bound to current PCB source')
    req(hist['count']==54 and hist['counts']=={'REMOVED_BY_PRIOR_COORDINATED_COPPER_REVISION':48,'ISOLATED_TX_STUB_NO_RECEIVE_PATH':6},'historical return set changed')
    req(len(paths)==60 and {r['index'] for r in paths}==set(range(60)),'60-via inventory changed')
    failed={r['index']:r['net'] for r in paths if r['solution'] is None}
    req(failed==EXPECTED_FAILED,'finite-search failure set changed')
    req(sum(r['solution'] is not None for r in paths)==53,'explicit corridor count changed')
    req(len(exp['signal_vias'])==60,'expanded via count changed')
    nearest=[]
    for r in exp['signal_vias']:
        req(r['nearby_ground_vias'],'signal via lacks ground-via inventory')
        g=r['nearby_ground_vias'][0]
        req(g['layers']==['F.Cu','B.Cu'],'nearest ground via is not through-ground')
        nearest.append((g['distance_to_signal_segment_mm'],r['net'],r['signal_via_uuid']))
    max_near=max(nearest)
    tr_ns=.5; velocity_mm_ns=150.; f_knee_GHz=.5/tr_ns
    wavelength_mm=velocity_mm_ns/f_knee_GHz
    lambda20=wavelength_mm/20
    req(max_near[0] <= lambda20,'nearest return-via spacing exceeds lambda/20 screen')

    findings=exp['findings']
    req(findings,'expanded adjacent-plane findings absent')
    w=.2; h_near=.203; h_far=.203+.03+1.03; er=4.4
    z1,e1=microstrip_z(w,h_near,er); z2,e2=microstrip_z(w,h_far,er)
    v1=299.792458/math.sqrt(e1); v2=299.792458/math.sqrt(e2)
    lp1=z1/v1; lp2=z2/v2
    delta_lp=max(0.,lp2-lp1)
    stress_I_A=.050; stress_tr_ns=.5
    rows=[]
    for r in findings:
        length=float(r['adjacent_gap_mm']); dl=delta_lp*length
        vb=dl*stress_I_A/stress_tr_ns
        rows.append({'uuid':r['uuid'],'net':r['net'],'adjacent_gap_mm':length,'trace_width_mm':.2,'delta_series_inductance_nH_upper':dl,'50mA_0p5ns_bounce_V_screen':vb,'nearest_ground_via_mm':r['nearest_actual_ground_vias'][0]['distance_to_signal_segment_mm'],'disposition':'BOUNDED_NO_REROUTE'})
    worst=max(rows,key=lambda r:r['50mA_0p5ns_bounce_V_screen'])
    canrx=max((r for r in rows if r['net']=='CAN_RXD'),key=lambda r:r['50mA_0p5ns_bounce_V_screen'])
    req(worst['50mA_0p5ns_bounce_V_screen']<.20,'adjacent-plane stress screen exceeds 0.20 V allocation')
    req(canrx['50mA_0p5ns_bounce_V_screen']<.05,'active CAN_RXD gap exceeds 50 mV allocation')

    return {
      'milestone':'I27_GND02_DESKTOP_CLOSURE','date':'2026-09-12','source_PCB_sha256':SOURCE,
      'physical_tests_performed':False,'PCB_change_required':False,'firmware_change_required':False,
      'historical_54':{'removed_by_prior_copper_revision':48,'isolated_R301_DNP_CAN_TX_MCU':6,'all_individually_reconciled':True},
      'expanded_adjacent_plane_findings':{'count':len(rows),'rows':rows,'model':{'trace_width_mm':w,'normal_reference_height_mm':h_near,'fallback_reference_height_mm':h_far,'Z_near_ohm':z1,'Z_far_ohm':z2,'delta_L_nH_per_mm':delta_lp,'stress_current_mA':50,'stress_rise_ns':stress_tr_ns},'worst_bounce_V':worst['50mA_0p5ns_bounce_V_screen'],'worst_net':worst['net'],'CAN_RXD_worst_bounce_V':canrx['50mA_0p5ns_bounce_V_screen']},
      'signal_via_transfers':{'count':60,'explicit_dual_plane_corridors':53,'finite_search_no_corridor':7,'failed_searches':failed,'maximum_nearest_through_ground_via_mm':max_near[0],'lambda_over_20_screen_mm_at_0p5ns':lambda20,'all_within_lambda_over_20':True,
        'adjudication':{'CAN_TX_MCU':'four finite-search misses are on the R301-DNP-isolated no-transmit stub; no release transition exists.','ESP_EN':'two finite-search misses are reset/programming control, not a repetitive release timing interface; nearest through-ground spacing remains within the conservative lambda/20 screen.','GPS_SEARCH_BUFFER':'one finite-search miss drives the 1 kohm current-limited search indicator path and has no logic receiver/timing acceptance.'}},
      'active_interface_statement':'All active receive/timing-interface signal-via transfers have an explicit conservative paired-plane corridor in the 53/60 path set. The seven finite-search misses are restricted to the isolated TX stub, reset/programming EN, and an LED indicator driver.',
      'gnd02_desktop_complete':True,
      'qualification_retained':['Fabricated-board continuity/short inspection','CAN waveform/error-count vehicle correlation','GNSS/BLE/ADC coexistence and EMC/ESD qualification'],
      'reopen':['Any PCB stackup/copper/via change','Populate R301 or enable CAN transmission','Repeatable physical SI/EMC fault attributable to return geometry'],
      'conclusion':'No return-path reroute or added stitching is justified before fabrication. GND-02 is bounded-inference complete for pre-hardware design; physical correlation remains qualification, not claimed test evidence.'}
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

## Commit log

2026-09-03 Fix RaceChrono discovery and publish stability-first firmware (#43)
    Advertise RaceChrono service 0x1FF8 and characteristics 0x0001-0x0004 as native 16-bit UUIDs so iOS discovery works. Replace the old reconnect/CAN runtime with the validated stability-first firmware.
    [cca_telemetry.ino]
2026-09-13 I28: apply automotive 5V converter and electrical signoff
2026-09-13 I28: automotive-qualify 5V buck and document power signoff
    [GR86_CCA_RevB.kicad_pcb, Power_5V.kicad_sch]
2026-09-13 I28: repair U121 KiCad library identity after Q1 substitution
2026-09-13 I28: retain qualified LM5164 symbol identity for Q1 fitted variant
    [Power_5V.kicad_sch]
2026-09-13 I28: bind native content to current controlled PCB source
2026-09-13 I28: rebind LED population proof to qualified PCB source
2026-09-13 I28: separate current PCB effectivity from historical return reference
2026-09-13 I28: replace obsolete I26 patch replay with explicit source rebind
    [prepare_publication.py]
2026-09-13 I28: cover automotive U121 handling correction in regression
    [test_review.py]
2026-09-13 I28: replace stale I26 prose assertion with structural closure invariants
    [prepare_publication.py]
2026-09-13 I28: rebind reconciliation to current PCB effectivity
2026-09-13 I28: bind I27 fabrication readiness to current Q1 PCB source
2026-09-13 I28: exclude only KiCad-derived zone fill payloads from native identity
2026-09-13 I28: align native-binding tests with source-authored zone contract
    [test_native_binding.py]
2026-09-13 I28: bind authored PCB intent across KiCad refill serialization
2026-09-13 I28: correct authored zone-outline regression path
    [test_native_binding.py]
2026-09-13 I28: diagnose exact native-refill content mismatch fail-closed
    [native_binding.py]
2026-09-13 I28: canonicalize nonsemantic KiCad top-level record ordering
2026-09-13 I28: regression-test nonsemantic top-level KiCad ordering
2026-09-13 I28: ignore only non-electrical footprint graphics across native mirror serialization
2026-09-13 I28: cover non-electrical mirror normalization without weakening copper binding
    [test_native_binding.py]
2026-09-13 I28: bind footprint electrical semantics independent of KiCad drawing serialization
2026-09-13 I28: normalize KiCad omitted zero-angle placement serialization
2026-09-13 I28: canonicalize set-like KiCad pad layer ordering
2026-09-13 I28: preserve fail-closed binding error contract
    [native_binding.py]
2026-09-13 I28: normalize equivalent KiCad integral numeric serialization
2026-09-13 I29: publish source-bound PCBA product handoff and actual SPICE execution limits
2026-09-13 I30: add independently derived U121 switching SPICE model, without product signoff
2026-09-13 I30: bind derivative simulation passives and nets to the reviewed Q1 board
2026-09-13 I30: preserve all thirteen switching, sensitivity and negative-control cases
2026-09-13 I30: record completed derivative-SPICE results and explicitly unverified whole-power scopes
2026-09-13 I30: publish usable derivative SPICE evidence without promoting it to whole-board qualification
2026-09-13 I31: publish tentative derivative power signoff with explicit startup and backfeed risks
2026-09-13 I32: acquire isolated native KiCad toolchain for local power-layout verification
2026-09-14 Complete I32 recovery and 160 MHz firmware closure
    [CAN.kicad_sch, COMPLETE_FITTED_BOM.csv, CONTROLLED_RESERVOIR_CHANGES.json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]
2026-09-15 Apply frozen I32 procurement redline and complete native manufacturing verification
    Redline all 13 approved references, qualify manufacturer land patterns and retained generic models, regenerate BOM/CPL/fabrication outputs, and retain all 14 desktop verification categories including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
    Preserve the pre-redline handoff history and explicit physical/supplier gates. Full waveform evidence is stored as losslessly reconstructable byte parts. Published tree exactly matches locally verifi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
    [CAN.kicad_sch, COMPLETE_FITTED_BOM.csv, ENVELOPE_CDTop_PA1616D_20Pad_v06.step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]
2026-09-15 Bind hosted review and thermal checks to the verified I32 procurement source
    Retain all native and firmware postconditions, current 177-part identity and negative-path checks, and explicit supplier/physical gates. Verify the current evidence and manufacturing package byte-for-byte. Archive obsolete workflow recipes, retire I27 automatic authoring/publication, and prevent thermal pipeline errors from being masked.
    No native CAD, model, BOM/CPL, manufacturing-package or executed SPICE/thermal data changes.
    [run_review.py, test_review.py]
2026-09-15 Reconcile current I32 findings with the preserved historical review ledger
    Validate the current eleven-row I32 supplement separately from the unchanged historical 290-row register. Refresh affected root gate and finding descriptions with the verified procurement margins, co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
    No CAD, model, BOM/CPL, manufacturing-package or executed analysis change.
2026-09-15 Reverify completed I32 redline and refresh exact JLC sourceability
    Preserve the completed native procurement redline and all handoff commits. Record fresh local evidence/package reproduction and source auditing, current-head hosted result readback, and the nine exac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
    All CAD, models, BOM/CPL, manufacturing files and executed simulation data remain unchanged. Retain supplier/sourcing and physical validation gates; PR #46 stays unmerged.
2026-09-15 Bind every factory part to JLC catalog and regenerate sourced ECAD package
    [CAN.kicad_sch, COMPLETE_FITTED_BOM.csv, ENVELOPE_CDTop_PA1616D_20Pad_v06.step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]
2026-09-29 Integrate GR86 findings-only PCB assurance and local Codex handoff

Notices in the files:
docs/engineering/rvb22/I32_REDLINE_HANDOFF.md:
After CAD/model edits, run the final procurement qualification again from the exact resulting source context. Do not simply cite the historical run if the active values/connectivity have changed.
